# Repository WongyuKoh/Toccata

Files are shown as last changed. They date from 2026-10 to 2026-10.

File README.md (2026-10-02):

# Toccata

portable Piano + Rhythm Game

88키 풀사이즈 분할식 피아노와, 그 피아노를 컨트롤러로 쓰는 리듬 게임을 만드는 프로젝트.

건반은 **3D 프린터로 뽑는 짧은 시소 건반 + 강철 추 레버(v4, W1+)** 구조다 — 건반과 레버가 금속 봉 위에서 돌고, 레버 무게와 작은 토션 스프링으로 복귀한다. 늘 휘어 있는 플라스틱이 없다.

## 진행 순서

1. **하드웨어 설계 및 제작** ← 현재 단계
2. 피아노 소리 테스트 (MIDI 프로그램 연결 + 온디바이스 구동)
3. 리듬게임 연동
4. 리듬게임 제작

## 문서

- **[하드웨어 설계서 v4 (확정본, 2026-10-02)](docs/01-hardware-design.md)** — 지금 설계를 한곳에 모은 문서. 요구사항·건반 액션·회로·뒷바 L2·터치스크린·비용·출력·제작 순서·확인할 것·파일 지도
- [하드웨어 폴더 안내 (v4)](hardware/README.md) — 건반 액션 v4 · 회로 · CAD · 재료 목록. 통합 보고서: https://claude.ai/artifact/4GRdsojXgi8FT78uvbj5Df
- [요구사항 R1~R32 · D1~D24](hardware/mechanical/sound-requirements.md) — 모든 설계의 기준
- [CAD 출력·조립 안내](hardware/mechanical/cad/README.md) — 출력 STL, 도면 D01~D06, 렌더, 조립 순서
- [리듬게임 기획서](docs/02-rhythm-game-design.md) — 2단계
- [보관: 1단계 하드웨어 설계 v2.0 (모노리식)](docs/archive/v2.0-monolithic.md) — v4로 대체됨
- [보관: 설계 검토서 (v2.0 시각화 보고서)](docs/report/toccata-design-review.html)
- [보관: v2.0·v3 CAD·STL·렌더](hardware/mechanical/before/cad/) · [도해 SVG](docs/figures/)
- [보관: v1.5 다부품·금속 스프링 설계](docs/archive/v1.5-multipart.md)
- [보관: v0.3 상용급 설계](docs/archive/v0.3-overengineered.md) — 참고용

## 디렉토리

```
docs/         설계 문서 (01 하드웨어 설계서 v4, 02 리듬게임 기획), archive/ (이전 설계서), report/ (보고서)
hardware/     기구·PCB·BOM
  mechanical/   sound-requirements.md (요구사항), key-action-v4/ (건반 액션), touchscreen/ (터치스크린 3판), before/ (이전 설계)
    cad/          출력 STL (stl/print/), 도면 (drawings/ D01~D06), 렌더 (renders/), 전체 조립 3MF·GLB, 생성기 (src/build_all.py)
  pcb/          회로도, 기판 배치, 넷리스트
  bom/          구매 목록 엑셀 v4, 최종 재료 페이지 생성기, 판매처 조사, 절감 선택기
firmware/     RP2040-Zero 펌웨어 (키 스캔, 벨로시티, USB-MIDI) — 아직 비어 있음
sw/           라즈베리파이 소프트웨어 (FluidSynth, 터치 메뉴) 및 이후 리듬게임 — 아직 비어 있음
```

## 핵심 사양 (v4 확정본 · 2026-10-02)

| | |
|---|---|
| 건반 | 88키 (A0–C8), 흰건반 피치 23.5 mm, **3D 프린팅** (PETG) |
| 구조 | 옥타브(도~시) 모듈 7개 + 왼쪽 끝 부속(A0·A#0·B0) + 오른쪽 끝 부속(C8). 모듈 164.5 × 212 mm, 1.37 kg |
| 건반 기구 | Ø4 봉 위의 짧은 시소 건반 + 강철 블록 무게 레버 + 미스미 비틀림 스프링(C-UA90R5-3-0.5). 누르는 힘 51.9 / 51.0 g, 연타 16.3 / 18.8 Hz |
| 센싱 | 선형 홀센서 **DRV5055A2** + 자석 Ø5×2, 위치를 연속으로 재서 벨로시티 계산 |
| 모듈 MCU | **RP2040-Zero** ×8 (모듈 7 + 페달), 모듈마다 16채널 먹스(CD74HC4067 ×7), 각각 USB-MIDI 장치 → 10포트 유전원 허브 |
| 메인 CPU · 소리 | **Raspberry Pi 5 2GB** + FluidSynth, USB 오디오 동글 → TPA3110 앰프 → 4인치 스피커 2개 (헤드폰을 꽂으면 꺼짐) |
| 본체 | 건반 바로 뒤에 붙는 한 몸 뒷바 L2. 전체 **1254 × 342.5 mm**, 가운데 윗면 z72.85(건반 틀과 같은 높이), 스피커 앞판 40°, 스피커 윗면 z144.65 |
| 화면 | 7인치 가로 터치스크린 Waveshare 7-DSI-TOUCH-C, 25°로 세우고 운반할 때 접음 |
| 전원 | USB-C PD 20 V (65 W 충전기 또는 보조배터리, 약 3.2~4.0시간) |
| 비용 | 실제 구매 **731,485원**(가진 부품·예비 제외, 배송비 포함). 전체 구매 목록(가진 부품·공구·예비 포함) 1,134,177원, 그중 기본 구성 754,492원 (한도 100만 원) |
| 출력량 | 악기 출력 290개(파일 74종). 건반 액션 필라멘트 약 6.55 kg · 436시간 + 뒷바 약 1.1 kg |

> 옥타브 모듈 1개가 곧 완결된 12키 USB-MIDI 키보드입니다. 첫 모듈에서 2단계(음원 테스트)를 시작합니다.
> 이전 상용급 설계(v0.3, 600~1,100만원)는 [docs/archive](docs/archive/)에 보관.

## 라이선스

MIT

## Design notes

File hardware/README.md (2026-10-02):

# hardware

Toccata 하드웨어 설계 자료입니다. 현재 기준은 **v4**(2026-09-29)입니다.
- 건반 액션: W1+ r4.5(미스미 기성품 스프링, 남은 문제 해결)
- 전자부: 회로도 개정 C(W1 r4.5 기준, 10/1 △16 터치스크린 전원)

확정 설계를 한곳에 모은 문서는 [하드웨어 설계서 v4](../docs/01-hardware-design.md)입니다.

통합 아티팩트는 건반 액션 보고서, 도면, 재료 선택, 회로도를 한 페이지에 모은 것입니다: https://claude.ai/artifact/4GRdsojXgi8FT78uvbj5Df (발행 원본: [`docs/report/toccata-v4/`](../docs/report/toccata-v4/))

| 폴더 | 내용 |
|---|---|
| [`mechanical/sound-requirements.md`](mechanical/sound-requirements.md) | 요구사항 R1~R32, D1~D24. 모든 설계의 기준 (R31 터치스크린, R32 L2 한 몸 뒷바 · 스피커 앞판 40°) |
| [`mechanical/key-action-v4/`](mechanical/key-action-v4/) | **건반 액션 v4 (W1+).** 설계 문서, 좌표·물리 모델, 도면 15장, 출력 공구와 단계 0 시편 STL(`printables/`), 구조안 5개 비교, 검증 기록, 보고서 |
| [`mechanical/touchscreen/`](mechanical/touchscreen/) | **R31 터치스크린 수정 3판 (10/1 사용자 승인).** Waveshare 7-DSI-TOUCH-C(7인치 가로 DSI)를 L2 가운데 화면 뚜껑에 25° 기울여 세우고, 접으면 z78~95로 화면 뚜껑 위(뚜껑 윗면 z72.85, 뚜껑 평면 안)에 눕힘. `rev3/`에 CAD 넘김 사양(CAD_SPEC_rev3.md), 치수 도면 t01~t06, 3D 미리보기, 검수 페이지. 조합 비교 13가지는 `compare/`. 2판(공식 TD2, L1) 기록은 `rev2_td2/`. CAD는 통합본 v15 |
| [`mechanical/cad/`](mechanical/cad/) | **CAD (L2 한 몸 뒷바 + 건반 액션 r4.5 + 터치스크린 3판).** 출력 STL 84파일(`stl/print/`: 악기 부품 74파일·290개 + PORON 5T용 패드 바 6파일 + 출력 공구 4파일), 도면 D01~D06(`drawings/`), 렌더(`renders/`), 전체 조립 3MF·GLB, 사양(`spec/body_L2.json`), 생성기 `src/build_all.py`. 출력·조립 안내는 `README.md` |
| [`mechanical/before/`](mechanical/before/) | 이전 설계 보관: v2.0 일체형, v3 CAD·STL·렌더, 88건반 STEP |
| [`pcb/`](pcb/) | 전자부 회로도 9장, 기판 배치, 넷리스트, 부품표. 회로 세션이 관리합니다 |
| [`bom/`](bom/) | 구매 목록 엑셀(v4), 핵심 부품 목록 생성기, 판매처 조사(USB-C 케이블 포함), 절감 선택기 |

## 한눈에 보기 (v4)

- **건반:** 강철 봉 위의 짧은 시소 건반과, 꼬리가 들어 올리는 강철 추 레버가 있습니다. 무게와 작은 비틀림 스프링(미스미 C-UA90R5-3-0.5)으로 돌아오고, 늘 휘어 있는 플라스틱이 없습니다. 강철 블록은 캐리어에 MS 폴리머로 붙입니다.
- **힘:** 누르는 힘 약 51~52 g, 올라오는 힘 약 41~43 g, 연타 16~19 Hz입니다.
- **크기:** 옥타브 모듈은 164.5 × 212 mm, 1.37 kg이고 7개입니다. 끝 부속 2개를 더해 건반부는 1254 × 212 mm(깊이)이고, 바로 뒤에 붙는 한 몸 뒷바(L2: 스피커 2개 · 가운데 유닛 · 터치스크린, R32)까지 1254 × 342.5 mm입니다. 가운데 윗면은 건반과 같은 z72.85, 스피커 윗면은 z144.65(앞판 40°)입니다.
- **센싱:** 건반마다 선형 홀센서(DRV5055A2)와 자석(Ø5×2)이 있습니다. 모듈마다 RP2040-Zero와 16채널 먹스가 있고, USB-MIDI로 Raspberry Pi 5(FluidSynth)에 연결됩니다.
- **화면:** 7인치 가로 터치스크린(Waveshare 7-DSI-TOUCH-C, DSI)에서 메뉴와 리듬게임을 합니다. 외부 TV는 HDMI로 선택 연결합니다.
- **비용:** 실제로 살 금액은 **731,485원**입니다(부품 683,385원 + 배송비 48,100원, 가진 부품과 예비 제외; 최종 재료 페이지 https://claude.ai/artifact/9CJ3HwhbhoodCAui94g28n 10/2 기준). 구매 목록 엑셀 `bom/toccata-purchase-list-v4.xlsx`는 가진 부품·공구·소모품·예비까지 모두 넣은 **전체 목록**이고 1,134,177원입니다(추천 절감 1,091,558원). 그중 기본 구성은 754,492원으로 한도 100만 원 안입니다(터치스크린·L2 뒷바 포함).

다음 단계는 단계 0 시험입니다. 시편 34개와 절차서가 `mechanical/key-action-v4/printables/stage0/`에 있습니다(DESIGN.md 17장).
- **먼저 시험 1 (패드 반발).** 패드 재료값이 가장 큰 위험입니다(DESIGN.md 18장).
- 그다음 시험 3a (윗판 굽힘 띠, 6건반 화음 자리 여유 6.4 %).
- 그리고 r4.4~r4.5에서 바뀐 곳: 접착 강도(시험 20), 첫 모듈 정하중(시험 21), 스프링 토크(시험 8).

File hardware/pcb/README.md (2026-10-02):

# Toccata v4 W1+ 전자부 회로도 (hardware/pcb)

**W1(v4 W1+, 시소 건반 + 무게 레버) 설계의 전자부 회로도**입니다. W1 설계 문서는 센서 바·센서 기판·제어 기판·리본·USB를 이전 설계에서 그대로 가져온다고만 적었고, 회로는 글과 블록 배선도로만 있었습니다. 이것을 W1 좌표 모델(r4.3~r4.5)에 맞춘 **실제 회로도**로 만들었습니다. 부품 번호, 핀 번호, 넷 이름, 값, 연결이 모두 들어 있어 KiCad 같은 CAD에서 그대로 다시 그릴 수 있습니다.
기준은 W1 r4.5(2026-09-29) 좌표 모델 `hardware/mechanical/key-action-v4/model/geometry.json`(circuit_r43·circuit_r44 블록)·`metrics.json`과 설계 문서 `…/DESIGN.md`이고, 글 사양에 아래 **변경 △1~△16**을 더했습니다. 2026-09-28 W1 세션의 r4.2~r4.3 최종 자료(끝 부속 센서 바, USB 선반 홈, 프레임 레일·리브, W1 검증 요청)와 v4 구매 목록을 다시 대조해 △13~△15와 구매 목록 수정 목록을 더했습니다. 2026-10-01에는 R31 터치스크린(사용자 선택 B1 = Waveshare 7-DSI-TOUCH-C)의 전원·DSI 연결과 전원 예산을 △16으로 더했습니다(개정 C).

## W1에서 전자부로 들어오는 값 (r4.3~r4.5)

| 항목 | W1 값 | 반영한 곳 |
|---|---|---|
| 자석 | Ø5×2 N35, 건반 밑 y67(센서 소자 열 바로 위), S극 아래 | SCH-02 표, BRD-02 |
| 자석 x = 센서 x | C 7.431, C# 21.215, D 35.25, D# 49.285, E 63.07, F 77.359, F# 90.573, G 104.037, G# 117.5, A 130.964, A# 144.427, B 157.641. 끝 부속: A0 10.287, A#0 26.927, B0 40.141, C8 11.75(오른쪽 로컬) | SCH-02·04, BRD-02 |
| 끝 부속 센서 바 (r4.2) · 리드 길 (r4.4) | 왼쪽 x0.5~46.5(A#0 낮은 구간 x19.93~33.93), 오른쪽 로컬 x0.5~23.0 → EL 기판 x1.0~46.5, ER x1.0~23.0 (SB처럼 6행 15.24). 리드: 레일 밑 차선 EL x13.53~22.48 · ER x7.59~14.00(z5~10), 뒷벽 홈 z5~12 | SCH-04 주 6, BRD-02 (△13) |
| 자석–소자 간격 (쉼 / 강체 바닥 / 과다) | 백 10.82 / 5.60 / 5.24 mm, 흑 13.35 / 5.32 / 4.76 mm. 1 N 정착 바닥 백 5.52 · 흑 5.47(흑은 강체 바닥보다 0.15 위) | SCH-02 표 |
| 센서 출력 (DRV5055A2, 3.3 V) | 백 약 4 → 22 mT (ADC 약 2207 → 2862), 흑 약 2 → 25 mT (2138 → 2962). 최대 31 mT로 선형 범위 ±44 mT 안이라 A2 형을 유지. 재무장(자석 복귀 50 %) 백 8.21 mm · ADC ≈2373, 흑 9.34 mm · ≈2282; 1 N 바닥 백 ≈2890, 흑 ≈2907 | SCH-02 표 |
| 펌웨어 규칙 | 재무장 = 자석 복귀 50 %. 유령 거름(U6, W1 r4.5 DESIGN 0.1 = run_all.py gfilter): 같은 건반에서 앞끝 0.3 m/s 이상인 음의 note-on부터 250 ms 안에 재무장선을 넘으면 의심 상태, note-on부터 500 ms 안에 닿는 첫 다시 눌림의 내려오는 속도(손가락 점)가 min(0.45 m/s, 앞 음 × 25 %) 미만이면 버림, 500 ms가 지나면 보통 음(1 s 뒤 여린 연타는 산다). W1 계산: 재무장 28건 모두 1.5 s까지 스스로 다시 닿지 않음(흔들림 ≤ 222 ms). 단계 0 시험 11에서 다시 눌림 시각을 기록해 500 ms를 넘는 유령이 있으면 창 = 가장 늦은 것 + 100 ms. MCU는 자석 속도를 재므로 앞끝 = 자석 × 1.91(백) / 1.18(흑), 손가락 점 = 자석 × 1.74 / 1.05 → 자석 단위 비율 27.5 / 28.2 %(시험 11 불합격 시 30 % → 33.0 / 33.8 %) | SCH-03 주 9 |
| 제어 기판 외곽 | x47.25~117.25 × y145.5~195.5. 홈 x81.92~84.72 × y≤172(F\|F# 핀 발 y148.6~170.7과 킬 y144.5~148.6이 지나감, r4.5). 금지 구역 x81.22~85.42 × y≤173.2 — 제로 PCB(z11.9 위)만 y172.0~173.2에 걸치고 그 안에 핀·패드·배선 없음 | BRD-01 |
| 프레임 레일·리브 | 밸런스 레일 뒷면 y144.5, 선반 리브 앞면 y196.8(x49.4~50.6, x115.4~116.6). 기판 부품 ↔ 프레임 1.3 | BRD-01 고정 자리 (△14) |
| 기판 고정 (r4.4~r4.5) | 모듈 바닥 구멍 x46.25~118.25 × y144.5~196.5로 기판을 밑에서 넣음. 위에 매단 Ø6 보스 4개(받침 6 × 7.5 / 6 × 7.3, 밑면 z10.6; 둘레 1.3은 부품 없음 — 모서리 x≤54.3 · x≥110.2), M3×6 ×2 밑에서(L35 ISO 7380 Ø5.7 × 1.65, 보스 Ø2.5 막힌 구멍 z15.4까지 탭), 위치 핀 ×2. J301·J302는 넣기 전에 납땜 | BRD-01 주 8 (△14) |
| 높이 | 부품 ≤ z20(y145.8~194.5), 뒤 띠 ≤ z16.7. 제로 PCB z11.9~12.9, 윗면 부품·헤더 핀 끝 ≤ z16.3. 기판 밑은 바닥 구멍(r4.5), 아랫면 헤더 핀 끝 ≤ 2 mm. 선반 밑면 z18.05, USB 플러그 틈 1.3 | BRD-01 주 3 |
| USB 플러그 · 선반 홈 | 선반 홈 x76.45~91.55, 플러그 폭 12.5 → 양옆 1.30(FDM 뒤 약 1.0). Waveshare 치수도상 USB-C가 오른쪽 모서리에서 4.67(가운데보다 0.14 왼쪽)이라 제로를 x75.14에 둬 리셉터클 x79.53~88.47, 가운데 x84.00 = 홈 가운데. 리셉터클은 제로 가장자리 밖으로 약 1.3(1.0~1.5) | BRD-01 주 1·3 (△15) |
| USB 케이블 | C 쪽 몰드 ≤ 12.5 × 7.6 × 25 mm. **폭은 여유가 없습니다**: 12.5보다 넓으면 선반 홈과 한쪽 1.30이 그만큼 줄어듭니다. 지금 구매 목록 C04(Coms NA993)는 몰드 두께가 공개되지 않아(폭 약 11.3·길이 약 19.5는 사진 추정) W1 단계 0 시험 19(몰드 게이지 12.5 × 7.6 창, 길이 25)로 확인합니다. 안 맞으면 세 치수가 공개된 CVILUX DH-20M50052(11.97 × 6.42 × 20.93, DigiKey 2987-DH-20M50052-ND, 선택기 C04 대안, 8개 40,744원)로 | cables.csv W201~W207 |
| 리본·EXT 경로 | 리본 차선 x59~82(높이 5.0). 리본은 차선 안에서 SB J201과 같은 중심 x70.48(여유 1.32 / 1.36), J301 쪽 끝 6 mm만 가닥을 갈라 0.31 비껴 꽂음. J301도 아랫면 납땜, 리본은 기판 밑(z5~9)으로. EXT 선: 기판 밑 → USB 플러그 밑 → 뒷벽 개구. 회로 쪽 최소 차선: 리본 한 겹 → 높이 ≥ 2.5, 폭 ≥ 20.32 + 2 × 1.3 (W1 단계 0 시험 21 뒤 차선이 바뀌면 다시 정함) | SCH-02·03, BRD-01 주 6·7 |

- 모듈 핀 배치는 판매 페이지, 제조사 데이터시트, 위키에서 확인했습니다.
- 회로는 따로 전기 설계 검토를 거쳤습니다.
- 도면 개정: A = 2026-09-28 첫 판(△1~△12), **B = 2026-09-29** W1 r4.2~r4.5 대조(△13~△15, 기판 고정·바닥 구멍·끝 부속 리드 길), **C = 2026-10-01** R31 터치스크린 B1(△16: 화면 전원·DSI·전원 예산). 바뀐 SCH-01·SCH-06만 C이고 나머지 7장은 B 그대로입니다.
- 모든 도면은 한 소스(`src/`)에서 만들어집니다. 만들 때 **그린 선·라벨로 연결을 다시 계산**해 의도한 넷리스트와 대조합니다(ERC 대용). 현재 9장 모두 연결 오류 0, 글자끼리 겹침 0입니다(자동 검사는 글자와 전원 심볼만 봅니다).

## 파일

| 파일 | 내용 |
|---|---|
| `schematic/SCH-01_system.svg` | 시스템 연결도: 모든 파트와 보드, 선 목록(W 번호). 화면 A605와 W605~W608 포함(△16) |
| `schematic/SCH-02_sensor_board.svg` | 옥타브 센서 기판 SB ×7: DRV5055 ×12, 디커플링, 리본 2×8 |
| `schematic/SCH-03_control_board.svg` | 옥타브 제어 기판 MB ×7: RP2040-Zero, 4067 먹스, ID 점퍼, EXT와 보호 회로 |
| `schematic/SCH-04_end_parts.svg` | 끝 부속 EL(A0·A#0·B0)·ER(C8) 센서 기판과 JST-XH 연결 |
| `schematic/SCH-05_pedal.svg` | 페달 보드 PB와 페달 안 센서 PS |
| `schematic/SCH-06_power.svg` | 전원: PD 20 V → 퓨즈 → 스위치 → 5.1 V 강압 → Pi·허브. 화면 A605 전원(Pi 헤더 2·6번 → 점퍼 → 동봉선)·DSI 리본, 전원 예산(△16) |
| `schematic/SCH-07_audio.svg` | 오디오: 동글 → 헤드폰 잭 노멀 → HPF → TPA3110 → XT30 → 스피커 |
| `board/BRD-01_control_board_placement.svg` | 제어 기판 부품 자리와 구멍 좌표. W1 r4.3~r4.5 홈·금지 구역·높이 구역·바닥 구멍·매단 보스 반영 |
| `board/BRD-02_sensor_board_placement.svg` | 센서 기판 SB 리드 구멍, 버스 행, 리본 블록 + 끝 부속 EL·ER 기판 배치 |
| `netlist/netlist.csv` | 도면·보드·넷·부품·핀·핀 이름 (그린 도면에서 다시 계산한 값) |
| `netlist/bom.csv` | 부품·값·보드당/전체 수량·실장 조건·**KiCad 심볼/풋프린트**·구매 목록 코드 |
| `netlist/cables.csv` | 선 목록 W101~W706과 X701 (화면 W605~W608 포함) |
| `netlist/wiring_MB.csv` | 제어 기판의 점 대 점 배선 목록(구멍 좌표, 금지 구역 가로지름 경고 포함) |
| `netlist/rp2040_zero_pads.csv` | RP2040-Zero 패드 번호(dj505 / Waveshare P1), 구멍 좌표, 용도 |
| `netlist/mux_module_pins.csv` | 4067 모듈 심볼 핀 ↔ 모듈 헤더 핀 |
| `src/` | `sheets.py`(설계 데이터·도면), `parts.py`(모듈 핀·구매 코드), `sch.py`(도면 엔진·연결 검사), `export.py`(CSV), `build.py` |

다시 만들기: `python3 hardware/pcb/src/build.py` (PNG 미리보기가 필요하면 `--png <폴더>`, `resvg_py` 필요).

## 규칙

- **부품 번호.** 시트 번호 × 100입니다(KiCad의 "First free after sheet number × 100"). SB는 U201~, MB는 A301~, EL/ER은 40x/41x, PB는 50x, PS는 551, 전원은 60x, 오디오는 70x입니다.
- **보드 쪽 부품은 보드마다 번호가 같습니다.** 7개 모듈은 같은 기판을 7장 만들고 ID 점퍼만 다르게 닫습니다.
- **U, A, J, P, X의 뜻.**
  - U = 칩
  - A = 구매 모듈(RP2040-Zero, 먹스, PD 트리거, 강압, 앰프, 동글)
  - J = 기판 쪽 커넥터나 패드
  - P = 선 끝 플러그
  - X = 선 대 선 커넥터(JST-XH, XT30)
  - 두 커넥터가 맞물리는 곳에는 `>>` 표시를 그렸습니다. **KiCad에서는 연결이 아닙니다**. 그래서 맞물리는 양쪽 핀에 같은 넷 이름(라벨)을 붙여 두었습니다.
- **전원 넷.** `+3V3`, `GND`, `+20V`, `+5V1`은 전원 심볼로 그렸습니다. KiCad에서 로컬 라벨 "GND"는 전원 넷에 붙지 않으므로 반드시 전원 심볼을 씁니다.
  - `+20V`와 `+5V1`은 표준 라이브러리에 없습니다. 프로젝트 전원 라이브러리에 추가하세요(`+24V`를 복사해 이름을 바꾸면 됩니다).
  - EL·ER 쪽 3V3는 O1·O7 제어 기판의 3V3 레일이라 `+3V3_EL`, `+3V3_ER`로 나눴습니다(프로젝트 전원 심볼로 추가). 끝 부속 신호는 `EL_A0`, `EL_AS0`, `EL_B0`, `ER_C8`입니다.
- **오디오 신호 GND(`AGND`).** 잭 슬리브와 HPF 1 kΩ의 GND를 앰프 IN G 단자로만 모읍니다(△10). 전원 GND와는 앰프 보드 안과 USB를 통해 이어집니다.
- **모듈 패드 번호.**
  - RP2040-Zero는 `dj505/RP2040-Zero-KiCAD` 라이브러리 번호를 따릅니다: 1~9 왼쪽 위→아래, 10~18 오른쪽 위→아래, 19~23 아래 왼→오. Waveshare 회로도 P1 번호는 표에 같이 적었습니다.
  - 4067 모듈은 1~16 = C0~C15(J1)이고, 17~24 = J2 1~8(GND, VCC, EN, S0, S1, S2, S3, SIG)입니다.
- **3.5 mm 잭**은 KiCad `AudioJack3_SwitchTR`처럼 핀 번호가 글자(T, TN, R, RN, S)입니다. PJ-313은 판매자마다 1~5 번호가 달라서, 통전 검사로 글자를 찾아 씁니다.
- **XT30**은 KiCad 풋프린트대로 패드 1 = −, 2 = +입니다. 커넥터의 납작한 면이 +입니다.

## 이전 글 사양 대비 변경 (도면의 △ 표시)

| △ | 도면 | 변경 | 이유 | 부품 |
|---|---|---|---|---|
| 1 | SCH-02 | 버스 양 끝에 C213·C214 10 µF | 글 사양에는 있지만 구매 목록에 없었음 | **구매 목록 L67**: 1206 10 µF 16 V 50개 단위(아이씨뱅큐 P001248090, 7,150원) |
| 2 | SCH-03 | 먹스 VCC–GND에 C301 100 nF | 모듈 C1이 사진에만 있고 확인되지 않음 | 100 nF 여분 |
| 3 | SCH-04 | EL·ER 기판에 10 µF | 3V3가 150 + 350 mm 선 끝에서 들어옴 | △1과 같은 묶음 |
| 4 | SCH-05 | 링 급전 R503 = 20 Ω(100 Ω ×5 병렬) | TS 플러그나 꽂는 순간 3V3–GND가 이어져 PED 보드가 리셋됨(검토 R1) | 100 Ω 여분 |
| 5 | SCH-06 | 별 접지점 = 강압 IN− 단자 | 동글–Pi–강압–앰프 GND 루프 험(R7) | — |
| 6 | SCH-03·04 | EXT·XH 순서: 1 GND, 2~5 EXT1~4, 6 3V3 | 5S 밸런스선이 빨강 1 + 검정 5라 빨강 = 3V3가 되게 | — |
| 7 | SCH-05 | 페달 안 센서 OUT에 R551 1 kΩ 직렬 | 3 m 케이블 용량이 OUT에 바로 걸림(TI: OUT에 C 직결 금지) | 1 kΩ 여분 |
| 8 | SCH-03·04 | EXT: 센서 옆 1 kΩ 직렬(EL R401~R403, ER R411) + MB 100 kΩ 풀다운(R301~R304; O1은 1~3, O7은 1만) | 끝 부속을 빼면 입력이 떠서 유령 음이 남(R4, 필수). 1 kΩ은 약 0.6 m 선의 용량을 센서 OUT에서 떼어 냄(TI: OUT에 C 직결 금지) | 1 kΩ·100 kΩ 여분 |
| 9 | SCH-05 | 페달 잭 TN → GND | 플러그가 없을 때 팁이 GND라 0 V | — |
| 10 | SCH-07 | AGND 분리 표기 | 입력 쪽 GND를 앰프 IN G로만 | — |
| 11 | SCH-05 | R502 100 kΩ를 팁→GND로 고정, GP27 안 씀 | 이전 글 사양의 "GP27로 뗀 쪽 전압 구동"은 GPIO가 0/3.3 V만 낼 수 있어 불가(R3) | — |
| 12 | SCH-02·03 | 리본 16심 모두 사용(15 = GND, 16 = 3V3), 2×8 블록 | 선이 끊겼을 때 유령 음, 전원 여유(R27). 2×8은 나중에 IDC 헤더로 바꿔도 번호가 같음 | — |
| 13 | SCH-04·BRD-02 | EL·ER 1 kΩ(R401~R403, R411)을 1206 칩으로 아랫면에(OUT 구멍 ↔ 바로 뒤 행 y72.08). 기판을 W1 끝 부속 센서 바 안으로(EL 45.5 × 15.24, ER 22.0 × 15.24) | 센서 바가 기판 윗면을 모두 덮어 리드형 저항(Ø2.5)을 둘 곳이 없고, 기판 밑 틈은 2.0 mm. 이전 크기 47 / 23은 바(46.0 / 22.5)보다 김 | **구매 목록 L68**: 1206 1 kΩ 10개(아이씨뱅큐 P011433924, 440원) |
| 14 | BRD-01 | 기판 고정 자리를 (50.0,149.0)(114.5,149.0)(50.0,192.5)(114.5,192.5)로 — W1 r4.5에서 매단 보스, M3×6 밑에서 2 · 위치 핀 2 | 이전(v3 P114) 자리는 M3 머리 Ø5.5가 밸런스 레일 뒷면과 0.75, 선반 리브와 1.05(W1 1.3 규칙 위반). 새 자리(L35 ISO 7380 Ø5.7 × 1.65, 밑에서): 레일 1.65, 리브 1.54(축 1.45), 머리가 기판 모서리 x47.25 / 117.25 밖 0.10(바닥 구멍 안; DIN 912 Ø5.5면 기판 안) | — |
| 15 | BRD-01 | 제로를 x75.14로(+0.14), 제어 기판 격자 x = 76.52 + 2.54i. J301도 아랫면 납땜 | Waveshare 치수도: USB-C 리셉터클이 오른쪽 모서리에서 4.67 → 플러그 가운데를 W1 선반 홈 가운데 x84.00에(양옆 1.30 그대로). W1 검증이 요청한 J301 아랫면 납땜(리본이 레일 앞 1.0 안에서 접히지 않게) | — |
| 16 | SCH-01·06 | 화면 A605 = Waveshare 7-DSI-TOUCH-C(B1). 전원: Pi 40핀 헤더 핀 2(5 V)·6(GND) → P603 → W606 실리콘 점퍼 F/F 20 cm → X601⇄X602 → W607 점퍼 M/M 20 cm → X603⇄X604(화면 동봉선의 2.54 3핀 하우징: 1 빨강 5 V · 2 빈 칸 · 3 검정 GND) → W608 동봉선 → P604 MX1.25 2핀 ⇄ A605. 넷 `+5V_PI`(Pi 5 안 5 V 레일 = USB-C 입력, P601 MT666을 거쳐 `+5V1`에서 옴 — `+3V3_EL`처럼 프로젝트 전원 심볼)·`GND`, 꽂는 곳(`>>`)마다 양쪽에 같은 전원 심볼. DSI = W605 FFC 22핀 0.5 mm 300 mm B형(Pi 5 CAM/DISP 1 → A605, 22심 1 ↔ 1, A형은 보험). SCH-06 전원 예산: 화면 2.15 W(0.43 A), 강압 손실 1.4 W, 평균 약 16~20 W, 순간 최대 약 54.4 W(D19 52 W + 2.15 W ÷ 0.9), 60 W 여유 약 5.6 W, 45 W 전원이면 볼륨 상한 −2 dB(약 39.4 W; −1 dB면 약 46.0 W로 넘침, −1 dB만 낮출 때는 화면을 꺼 약 43.6 W) | R31(2026-10-01 사용자 B1 선택). D16: 화면은 Pi에서 나가는 방향으로만 전원을 받고, 화면·연장선에 다른 5 V를 넣지 않음. D19 전원 여유. D14: 화면·경첩·받침다리에 자석 없음 | 구매 목록 v4touch: No.135 화면, No.49·50 FFC B·A형, No.51~54 실리콘 점퍼 F/F·M/M 빨강·검정 (모두 반영됨) |

**번호 없는 변경**
- 테스트 포인트를 추가했습니다: MB 3개, PB 2개, CU 3개.
- **RP2040-Zero 장착 방식**을 캐스털레이션 직접 납땜에서 **안쪽 구멍에 핀 헤더(플라스틱 몰드는 뺌)**로 바꿨습니다. 밑면에 칩·수정·LDO가 있어 평평하게 붙지 않기 때문입니다.
  - 모듈은 밑면 부품 위(캡톤)에 얹혀 약 1.3 mm 높아집니다.
  - 제약은 부품 한계 z20이 아니라 **USB 위 뒤 선반 밑면**이었습니다. W1 r4.3이 선반에 플러그 위 홈(x76.45~91.55)을 내서 플러그(z10.7~18.3)와 1.3 mm를 되찾았습니다.
  - **구매 추가**: 핀헤더 1×40 4줄. 18핀 ×8장 = 144핀이고, 기존 SE7 5줄은 먹스(168핀)에 배정되어 있습니다. 합계 9줄.
  - KiCad 풋프린트는 1.0 mm 드릴 버전(bobu01 1mm, 또는 dj505를 복사해 드릴만 바꿈)을 씁니다.
- **BRD-01의 모든 부품 구멍을 제로 핀 격자에 맞췄습니다**(x = 76.52 + 2.54i, y = 173.59 + 2.54j; △15로 +0.14). 만능기판 한 장의 구멍에 모두 맞습니다. 4067 모듈은 x54.93~72.71에 세로로 둡니다.
- 센서 기판 고정 구멍(3.0, 61.9)·(3.0, 74.6)은 기판 앞·뒤 가장자리를 넘으므로 U자 홈으로 팝니다.

## KiCad로 옮기는 순서 (권장)

1. **프로젝트를 보드별로 나눕니다.** `octave-sensor`(SB), `octave-control`(MB, PB도 같은 기판으로 쓸 수 있음), `end-parts`, `pedal-sensor`로 나누고, CU 전원·오디오는 문서용 `cu-wiring`으로 둡니다. 한 PCB 파일에 7장을 넣지 않습니다.
2. **라이브러리.**
   - `bom.csv`의 "KiCad 심볼/풋프린트" 열을 따릅니다.
   - 직접 만들 것:
     - `Toccata:CD74HC4067_Breakout`
     - PJ-313 풋프린트(패드 이름 T/TN/R/RN/S)
     - 모듈 심볼: HUSB238, XL4016, XH-A232, 동글, `RaspberryPi5`(유닛 B = 40핀 헤더 2·6), `Waveshare_7-DSI-TOUCH-C`(1 = 5V, 2 = GND) (△16)
     - 전원 심볼 `+20V`, `+5V1`, `+3V3_EL`, `+3V3_ER`, `+5V_PI`(△16)
   - RP2040-Zero는 dj505 라이브러리를 쓰고, 3V3 핀을 `power_out`으로 바꿉니다.
   - DRV5055는 `Sensor_Magnetic:DRV5055A2xLPGxQ1`를 쓰고 Value를 `DRV5055A2QLPG`로 바꿉니다.
3. **주석 번호.** Annotate → "First free after sheet number × 100", X 위치순.
4. **ERC.** 선으로 들어오는 전원(SB의 `+3V3`, `+3V3_EL`·`+3V3_ER`, `+20V`, `+5V1`, `+5V_PI`, PS의 `PED_VCC`, 각 프로젝트의 `GND`)에 `PWR_FLAG`를 둡니다.
   - P601은 `USB_C_Plug_USB2.0`에서 A4·A1만 쓰므로 나머지 핀에 NC 표시를 합니다.
   - J401은 `Conn_01x05`, J411은 `Conn_01x03`입니다. P501은 PS 프로젝트에 둡니다.
   - △16 화면 선: P603·X601~X603·P604 = `Conn_01x02`, X604 = `Conn_01x03`(2 = 빈 칸, NC 표시). 모두 보드 밖(Exclude from board).
5. **보드 외곽과 부품 자리.** BRD-01·02 좌표를 씁니다. 제어 기판은 **x81.22~85.42 × y145.5~173.2(W1 r4.3)에 부품·패드·배선을 두지 않고**(제로 PCB만 y172.0~173.2에 걸침) 홈 x81.92~84.72 × y145.5~172.0을 따냅니다. EL·ER 기판은 BRD-02 아래 그림을 씁니다(R401~R403·R411 = `Resistor_SMD:R_1206_3216Metric`, 아랫면).

## 도착 후 확인할 것 (검토의 bring-up 목록 요약)

1. **PD 트리거.** 무부하로 전원마다 20 V가 나오는지 잽니다. HUSB238은 ISET이 열려 있으면 3.25 A를 요구해서, 20 V 3 A 보조배터리는 15·12 V나 5 V로 떨어질 수 있습니다.
2. **XL4016.** 무부하로 5.10~5.15 V에 맞추고 가변저항을 고정한 뒤 연결합니다. MT666 선과 허브 선의 극성도 확인합니다.
3. **PJ-313 ×3.** 플러그가 없을 때 T–TN, R–RN이 닫혀야 합니다. 노멀 접점이 없는 제품이면 헤드폰 차단(R15)을 할 수 없습니다.
4. **RP2040-Zero 복제품.** LDO 표시를 확인합니다(5핀 RT9013/ME6217이면 괜찮음). O1의 3V3 전류는 60~130 mA가 정상입니다.
5. **센서.** 자석 없이 OUT이 1.59~1.71 V(DRV5055 영점)이고, S극을 표시면에 가까이 하면 올라가야 합니다. 건반을 얹은 쉼에서는 백 약 1.78 V, 흑 약 1.72 V, 끝까지 누르면 백 약 2.31 V, 흑 약 2.39 V입니다(±10 %). EXT를 뺐을 때는 0.15 V 아래여야 합니다.
6. **페달.** 꽂은 상태에서 링–슬리브가 3.05 V 이상이고, 뺐을 때 팁이 약 0 V여야 합니다.
7. **앰프.** 36 dB 이득인지 확인하고 소프트웨어 음량 상한을 정합니다. 스피커 Re가 6~7 Ω인지(4 Ω 판매분 주의) 잽니다.
8. **허브 역급전.** Pi 선을 뺐을 때 Pi 5V 핀이 0 V여야 합니다.
9. **USB-C 위치·케이블.** 산 RP2040-Zero(복제품)의 리셉터클이 오른쪽 모서리에서 4.67 mm인지, 제로 가장자리 밖으로 몇 mm 나오는지 잽니다. 핀 헤더로 세운 제로에 실제 케이블을 10번 꽂고 빼 봅니다(몰드 ≤ 12.5 × 7.6 × 25, W1 시험 19).
10. **화면 전원(△16).** 동봉 전원선의 2.54 3핀 하우징이 1 빨강 5 V · 2 빈 칸 · 3 검정 GND인지 통전 검사로 확인한 뒤 점퍼를 꽂습니다. 화면 MX1.25 쪽 5 V를 부하 때 잽니다(점퍼 두 단 왕복 강하 계산 약 0.05 V). 최대 부하(FluidSynth + 화면 밝기 100 % + USB 장치)에서 `vcgencmd get_throttled` = 0x0(Pi USB-C 입력 약 2.0 A, D16). 화면 켬·끔, 밝기 0·100 %에서 센서 유휴 흔들림을 다시 잽니다(D14). config.txt에는 `dtoverlay=vc4-kms-dsi-waveshare-panel-v2,7_0_inch_c` 한 줄을 넣습니다(CAM/DISP 0이면 `,dsi0`).

## W1 기구 쪽에 요청한 것과 결과 (요청 2026-09-28, W1 r4.4~r4.5 반영 2026-09-29)

| # | 회로가 요청한 것 | W1 결과 |
|---|---|---|
| 1 | 제어 기판 부품 자리를 새 격자 좌표로: 제로 x75.14~93.14, 4067 x54.93~72.71 × y152.0~192.64, J301 x61.28~79.06 y148.19/150.73(아랫면 납땜, 리본은 기판 밑 z5~9), J302 x94.30~107.00 y193.91 | 반영. 리셉터클 x79.53~88.47 그대로 |
| 2 | USB 플러그 면 y약 196.8(리셉터클이 제로 밖으로 1.0~1.5), 몰드 y196.8~221.8 | 반영. 선반 홈 x76.45~91.55(틈 1.30), 선반 밑면 z18.05, 뒷벽 개구 z5~21(틈 2.70) |
| 3 | 제어 기판 고정 4곳 (50.0,149.0)(114.5,149.0)(114.5,192.5)(50.0,192.5) | **바뀜.** 한 덩어리 프레임에는 기판을 넣을 길이 없어(F\|F# 핀이 홈을 지나고 그 뒤로 매달림) 기판 밑 바닥을 뚫었습니다(x46.25~118.25 × y144.5~196.5, 리셉터클 뒤 x78.53~89.47은 y197.8까지). 모듈을 뒤집어 기판을 밑에서 곧게 넣습니다(넣는 길 최소 틈 0.60). 받침은 같은 네 자리에 **위에 매단 Ø6 보스**(밑면 z10.6 = 기판 윗면; 앞 2개는 밸런스 레일 뒷면, 뒤 2개는 리브·선반에 붙음). **M3×6 2개는 밑에서** 조이고(머리가 기판 밑), **위치 핀 2개**는 보스에서 기판 구멍으로 내려옵니다(반경 놀음 0.10). 나사는 구매 목록 L35 ISO 7380 버튼헤드(머리 Ø5.7 × 1.65): 레일 1.65, 리브 1.45로 1.3 규칙 통과, 머리가 기판 모서리 x47.25 / 117.25 밖으로 0.10 나오지만 바닥 구멍 안이라 문제없습니다(DIN 912 M3×6이면 Ø5.5로 기판 안) |
| 4 | 끝 부속 센서 기판 받침, 뒤 리브 틈(EL x15~38, ER x6~16), 리드 길 | 반영: 레일 밑 차선 EL x13.53~22.48 · ER x7.59~14.00(z5~10), 뒷벽 홈 z5~12. 리드는 패드 줄 뒤 y77.39 안에서 EL x14.83~21.18 · ER x8.89~12.70으로 모읍니다 |
| 5 | SB 뒤 받침 리브 틈 x60~82 → x59~82 | 반영(리본 양옆 1.32 / 1.36) |
| 6 | 금지 구역과 제로 PCB 겹침 정리 | 금지 구역 y173.2 그대로, P23에 제로 PCB가 y172.0~173.2에 걸친다고 기록 |
| 7 | C301 = 1206 칩, 레버가 떨어지는 곳 | 반영: D#·G# 매단 보스 위(16.75°), E·F 4067 위(13.25°), F#·G 기판 윗면(24.0° / 23.5°), O1·O7의 G는 R301 위(0.40 N) → R301을 기판에 붙여 눕히고 리드를 짧게 납땜 |
| + | (W1 쪽 변경) F\|F# 핀 발 | 바닥 대신 킬(y144.5~148.6, z3~19.3)로 밸런스 레일 뒷면에 붙음, 핀 앞끝 y152 → y148.6. 둘 다 기판 홈(앞이 열림) 안이라 회로 변화 없음 |

### 2차 요청 (2026-09-29, r4.5 재대조) — W1 r4.5 회로 2차로 반영됨 (통합 아티팩트 v9)

결과: 8 센서 바 오른쪽 턱을 되살림(ㄱ자 두 조각, 립 x161.5~163.0 z13.6~15.1, 기둥 x163.0~164.3; EL·ER은 턱 없이 왼쪽 M3 ×2 + 리브) → 회로는 SB를 x162.6까지 자름(기둥과 0.4). 9 유령 거름 = note-on부터 250 ms 안 재무장 → 의심, note-on부터 500 ms 안의 첫 다시 눌림만 판정(재무장 28건 모두 1.5 s까지 다시 닿지 않음). 10 레버 착지 글 맞춤. 11 EL 바닥 한 조각. 12 구매 목록 글 반영(합계 1,060,470원 그대로). 13 리본 차선 그대로(시험 21 뒤 알림).

| # | W1이 바꿀 것 | 이유 |
|---|---|---|
| 8 | 센서 바 오른쪽 턱(v3 P112, x161.5~164.5 × y59.0~63.4 · y70.6~77.5, 밑면 z13.6)을 모델에 넣거나, 턱 없이 바 오른쪽 끝을 무엇이 잡는지 P36에 적기 | r4.5 geometry에 턱이 없음. BRD-02는 턱을 점선으로 두고 확인 대기 |
| 9 | 유령 거름(U6) 글을 run_all.py gfilter와 같게(창 기준 = note-on부터 재무장까지 250 ms), 무장된 28건을 1 s 이상 돌려 유령이 다시 닿는 시각(ghost_reland)을 구해 '다시 눌림 시각 상한' 정하기 | DESIGN.md:36 글은 '250 ms 안에 다시 눌림'이라 모델과 기준이 다름. 펌웨어는 SCH-03 주 9 형태로 둠 |
| 10 | DESIGN §11 6단계 글: D#·G# 레버는 기판 윗면이 아니라 매단 보스 위(16.75°) | geometry·도면 12와 맞춤 |
| 11 | 끝 부속 EL 바닥에 모듈 기판 구멍 자르기가 새어 생긴 틈 x46.25~46.8 × y144.5~196.5 없애기 | end_fixed_prisms가 모듈 x로 잘라 끝 부속에도 적용 |
| 12 | 구매 목록 글: L35 용도를 매단 보스·밑에서 조임(r4.5)으로, SE4 용도에 MB C301 ×7(97개 사용), L20·L21 용도를 건반 88 + 페달 1 = 89(예비 11)로, 엑셀 제목 r4.4 → r4.5 | 수량·가격은 그대로 |
| 13 | 단계 0 시험 21 뒤 리본 차선(x59~82, z5~10)을 바꾸면 회로에 알리기 | 회로 쪽 최소: 리본 한 겹 → 높이 ≥ 2.5, 폭 ≥ 20.32 + 2 × 1.3 |

## 구매 목록(v4)에 넣거나 고칠 줄

`hardware/bom/toccata-purchase-list-v4.xlsx`와 절감 선택기는 W1 세션의 생성기(`hardware/bom/cost-selector/build_data.py`)로 만들어집니다. 아래 11줄은 **2026-09-29 판에 모두 반영됐습니다**(새 줄 L67·L68). 기록으로 남깁니다.

| 줄 | 바꿀 내용 |
|---|---|
| L67 (새 줄, 반영) | 1206 10 µF 16 V 50개(아이씨뱅큐 P001248090, 7,150원) ×1 — SB C213·C214 ×7 + EL C404 + ER C412 = 16개 (△1·△3) |
| L68 (새 줄, 반영) | Yageo RC1206JR-071KL 1206 1 kΩ 10개(아이씨뱅큐 P011433924, 44원 × 10 = 440원, VAT 포함) — R401~R403 + R411 (△13) |
| SE7 핀헤더 1×40 | 5 → 9줄 (먹스 168 + 제로 144 = 312핀) |
| SE7 핀헤더 소켓 1×40 | 빼기: EXT는 L66 JST-XH를 패드에 직접 납땜 |
| SEV2 RP2040-Zero 용도 | "캐스털레이션 직접 납땜" → "안쪽 구멍 핀 헤더 1×9 ×2(몰드 뺌), 캡톤 위 약 +1.3 mm" |
| L29 저항 용도 | 1 kΩ: R701·R702·R501·R551 / 100 kΩ: R301(O1·O7)·R302·R303·R502 / 100 Ω: R503(100 Ω ×5 = 20 Ω, 필수) |
| C05 리본 용도 | 16심 전부(OUT 12 + 3V3 ×2 + GND ×2) ×7 + EL·ER 리드 가닥 |
| L66 용도 | 200 mm 연장선을 모듈 쪽 150 · 끝 부속 쪽 50으로 자름 |
| C04 USB 케이블 | 몰드 ≤ 12.5 × 7.6 × 25, 폭 초과 금지 (반영; NA993 두께 미공개 → 대안 CVILUX DH-20M50052) |
| L56 1 µF 용도 | "약 80 Hz" → "약 93 Hz" |
| (선택) L29 10 kΩ | 회로에서 쓰지 않음(예비) |

**2026-10-01 (△16, R31 화면 B1)**: 화면 줄(v4touch No.49~54·75·76·135)은 구매 목록에 이미 들어가 있습니다. 회로에서 고칠 글 1줄:

| 줄 | 바꿀 내용 |
|---|---|
| L01 Raspberry Pi 5 용도 | "(R25: HAT 없음, GPIO 배선 없음)" → "HAT 없음. GPIO는 헤더 2·6번에서 화면 5 V만 나감(R31, △16)" |

## 근거

- 조사 노트 원문(모듈 핀·데이터시트·KiCad 라이브러리·전기 검토)은 작성 세션의 작업 폴더에 있었습니다. 핵심 결론은 이 문서와 도면 주에 옮겼습니다.
- TI DRV5055 SBAS640C, TI CD74HC4067 SCHS209D, RP2040 데이터시트(E11 정오표), Waveshare RP2040-Zero 위키와 회로도, SparkFun BOB-09056, Hynetek HUSB238, TI TPA3110D2, AMASS XT30 카탈로그, KiCad 9/10 라이브러리.

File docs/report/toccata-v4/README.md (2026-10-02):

# Toccata v4 통합 아티팩트 — 고치는 법

> **2026-10-02부터 최종본만 보여 줍니다**(사용자: "예전 구조 다 빼고 최종적으로 다루는 내용만"). `merge.py`의 `FINAL_ONLY = True`가 탭을 요약 · 01 건반 액션 구조 · 02 건반 도면(도면 11 뺌) · 03 검증·남은 위험(남은 문제·단계 0·남은 위험만) · 04 출력·조립(보관함 뺌) · 05 구매 목록(`src/build_buylist.py`) · 06 회로도 · 07 CAD · 08 뒷부분 도면으로 짭니다. 진행 기록(00), 부품·비용(04 옛), 5안 비교, 재료·절감 선택, S1·H1·K1·F1 대안 탭은 빠집니다(원본 `src/`는 그대로라 `FINAL_ONLY = False`로 되돌릴 수 있음).

두 아티팩트와 회로도를 **하나의 아티팩트**로 합쳤습니다.
- 건반 액션 진행 현황: https://claude.ai/artifact/1fA3D1HQRvNEanGCjDPhTZ
- 재료 절감 선택: https://claude.ai/artifact/Vv8pahUbEkKhwsZwGnmsGG
- 회로도: 새로 만든 탭

2026-09-28부터 Toccata v4에서 바뀌는 내용은 **모두 이 통합 아티팩트에 다시 발행**합니다. 원본 두 개는 더 고치지 않습니다.

- 통합 아티팩트 URL: **https://claude.ai/artifact/4GRdsojXgi8FT78uvbj5Df** (2026-09-28 v1 발행)
- 이 폴더가 발행 원본입니다: `index.html`과 옆의 `dwg/ alt/ img/ sch/`.

## 탭과 원본

| 탭 | page id | 원본 | 누가 고치나 |
|---|---|---|---|
| 요약 한눈에 보기 (맨 앞, 첫 화면) | `p-summary` | `src/summary.html` ← `python3 src/build_summary.py <최종 재료 db state/main JSON>` (최종 재료 페이지 데이터 hardware/bom/final-bom/site/index.html + 사용자 선택으로 실제 구매 금액 계산, 설계 숫자는 스크립트 안) | W1 세션 |
| 00~06 진행 현황 · W1+ 구조 · 도면 12 · 검증 · 부품·비용 · 출력·조립 · 5안 비교, S1·H1·K1·F1 | `p-overview` … `p-f1` | `src/progress.html` + `dwg/` `alt/` `img/` | v4 건반 액션 세션 (report 빌더) |
| 07 재료·절감 선택 | `p-cost` | `src/costsel.html` | 재료·절감 세션 (`gen_sel.py`) |
| 08 회로도 | `p-circuit` | `hardware/pcb/page/circuit.{html,css,js}` + `sch/` | 회로 세션 (`hardware/pcb/src/build.py` → `page.py`) |
| 10 뒷부분 도면 | `p-rear` | `hardware/mechanical/cad/drawings/D01~D06` (SVG·PNG) + `renders/R01~R03` → `merge.py`가 `rear/`로 복사. 도면마다 확대 단추(맞춤·2배 = PNG, 3배 = SVG; 회로도 탭의 `.zbar`) | CAD 세션 (`hardware/mechanical/cad/src/drawings.py`, `build_all.py`가 끝에 실행) |

## 고치고 발행하는 순서

1. **자기 탭의 원본만 바꿉니다.**
   - **진행 현황.** 빌더가 만든 **전체 페이지**(`<title>…</title>`로 시작하는 `index.html`)를 `src/progress.html`로 덮어씁니다. 그 페이지가 쓰는 도면과 사진은 같은 경로로 `dwg/`, `alt/`, `img/`에 복사합니다.
     - `merge.py`는 `<nav class="tabs" aria-label="페이지">`, `<main class="wrap">`, `<footer><div class="wrap">`, 첫 `<script>`를 찾아 씁니다.
     - 탭 순서는 원본의 nav를 따릅니다. `<span class="sep"></span>` 뒤는 대안 탭입니다.
   - **재료·절감.** `gen_sel.py`가 만든 전체 페이지를 `src/costsel.html`로 덮어씁니다.
     - 합계 막대(`.sumbar`), `<main>` 안의 내용, 스크립트를 그대로 가져옵니다.
     - 공통 CSS를 뺀 나머지 CSS에는 자동으로 `#p-cost` 범위를 붙입니다.
   - **회로도.** `python3 hardware/pcb/src/build.py` 다음 `python3 hardware/pcb/src/page.py`를 실행합니다. SVG는 `merge.py`가 `sch/`로 복사합니다.
2. `python3 docs/report/toccata-v4/merge.py --check`를 실행합니다. 섹션 15개(`p-overview`…`p-f1`, `p-cost`, `p-circuit`, `p-cad`, `p-rear`)가 나와야 합니다.
3. **발행합니다.** 다른 세션은 먼저 Artifact `action: "read"`, `url: https://claude.ai/artifact/4GRdsojXgi8FT78uvbj5Df`로 읽어야 발행할 수 있습니다. 읽은 뒤 이렇게 호출합니다:
   ```
   Artifact publish
     url:       https://claude.ai/artifact/4GRdsojXgi8FT78uvbj5Df
     file_path: docs/report/toccata-v4/index.html
     root:      docs/report/toccata-v4
     files:     [바뀐 파일만, 예: "dwg/d01_white_D_side.svg", "sch/SCH-03_control_board.svg"]
   ```
   - `files`에 없는 파일은 그대로 남습니다. 지운 파일은 `{"경로": null}`로 뺍니다.
   - 새 아티팩트를 만들지 않습니다(`url` 없이 발행하면 새 URL이 생깁니다).
   - `icon`은 넘기지 않습니다(처음 발행 때 정했음).
4. 발행 결과에 "newer version"(충돌)이 나오면, 그 버전을 `read`로 받아 `src/`에 반영하고 `merge.py`를 다시 돌린 뒤 발행합니다.

## 주의

- 페이지 머리말(`header.tb`)과 합친 원본 안내는 `merge.py`의 `header`에 있습니다. 날짜와 상태 칸을 바꾸려면 거기를 고칩니다.
- 새 탭이 필요하면 `merge.py`의 `nav`와 `main` 조립부에 `<a href="#id" data-to="id">`와 `<section class="page" id="p-id" hidden>`를 추가합니다. 라우터는 `.page` 섹션과 `nav.tabs a`만 봅니다.
- 이 폴더의 `dwg/ alt/ img/`는 2026-09-28에 발행본과 크기를 대조해 옮겼습니다(29개 모두 같음).

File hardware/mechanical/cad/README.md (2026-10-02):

# Toccata CAD — 출력용 STL과 전체 조립 (v4 W1+ r4.5 건반 액션 + L2 한 몸 뒷바)

이 폴더의 모든 파일은 `src/build_all.py`가 설계 모델에서 바로 만든 것입니다. 손으로 옮겨 적은 치수는 없습니다.
- **건반 액션:** `hardware/mechanical/key-action-v4/model/geometry.json`(도면 1~15가 그려지는 같은 모델)
- **본체·뒷바:** L2 한 몸 뒷바 `spec/body_L2.json`(사용자 요청 2026-10-01, W1 음향 확인 통과). 스피커 각도 등 모든 스피커 수치는 `src/body.py`의 `ANGLE = 40` 한 줄에서 사양 규칙으로 계산합니다. 그릴 격자·가스켓·보드 구멍은 v3.2 사양(`spec/body_speakers.json`, `body_centre_unit.json`)에서 옮김. 이전 뒷바: L1 `src/body_L1.py`·`electronics_L1.py`, v3.2 `body_v3_tall.py`(둘 다 쓰지 않음)
- **전자 부품 위치:** 회로 rev B(BRD-01·02), 가운데 칸은 사양 `centre_contents` 상자 그대로
- **추출한 사양:** `spec/*.json`. 항목마다 출처가 달려 있고, 추정값에는 `assumed`가 표시돼 있습니다.
- **터치스크린:** R31 3판(Waveshare 7-DSI-TOUCH-C, W1 `touchscreen/rev3/design/CAD_SPEC_rev3.md` 3a + `numbers.json`, 사용자 승인 2026-10-01). 화면 뚜껑에 경첩·다리 주머니·리본 구멍을 더하고 받침·받침다리·점검창 덮개·리본 클립을 `07_터치스크린`으로 뽑습니다. 화면은 25°로 서 있고 접은 상태는 따로 보는 그룹입니다(부록 A10, 아래 '터치스크린 3판').

좌표는 설계 문서와 같습니다. 원점은 A0 왼쪽 경계(x=0), 흰건반 앞끝(y=0), 책상(z=0)이고 단위는 mm입니다. 모듈 Ok는 x = 47 + 164.5·(k−1)에서 시작합니다.

## L2 한 몸 뒷바 한눈에

| 항목 | L1 (2026-09-30) | L2 (이 모델) |
|---|---|---|
| 전체 깊이 (y) | 447 (래치 포함 471) | **342.5** |
| 건반 뒤 면적 (1254 폭) | 294,690 mm² | **163,647 mm² (−44.5 %)** |
| 가운데 윗면 | z88 | **z72.85** (건반 윗면과 같은 높이) |
| 스피커 파트 | 213 × 195 × 129 (z5~134), 30° (수직에서), 2.95 L | 273 × 128.5 × 139.65 (z5~144.65) |
| 앞판 각도 | 수직에서 30° | **수평에서 40°** (수직에서 50°), 경사 길이 123.26 |
| 스피커 안 부피 | 2.95 L | 2.159 L (유닛 빼면 2.059 L = W1 규칙 −0.1 L; check_body.py는 유닛 모형을 속이 찬 덩어리로 빼서 1.89 L, 최저 1.8) |
| Qtc / Fc (Vas 3 L 가정) | 약 1.02 | 1.13, Fc 141~201 Hz (유닛 뺀 부피; 전체 부피면 1.11), 흡음솜 넣으면 약 1.08, Fc 135~192 Hz (W1 방식, 유닛 뺀 2.059 L × 1.175) |
| 스피커 겨냥 (가운데 귀 y-300 z460) | — | 축 수평 위 50°, 귀는 32.7° → y-z 면에서 17.3° 어긋남 (W1 한계 20°) |
| 모듈 USB 선 | 모듈 뒤 열린 통로 y212~252 (위에서 보임) | 뒷바 밑 닫힌 통로 y212~241 × z0~27 (거의 보이지 않음 — 배기 홈·건반 뒤 2 mm 틈으로만 조금) |
| 27° 소리 길 여유 (수직) | — | 사양 선(Ø94 가장자리 D(−47, 0)에서): 모듈 뒤 윗모서리 3.5, 플랜지 모서리 2.61, 가스켓 모서리 4.37, 앞판 아래 끝 7.75, 그릴 옆벽 발 3.1 (W1 ≥3.0); 실제 소리 가장자리 D(−45, 7)에서: 모듈 뒤 윗모서리 8.64 |
| D14 (자석 ↔ 홀 소자 y67 z12.9) | 226 (z8까지) | 자석 중심 228.4, 가장 가까운 쇠(플랜지 아래 모서리) 159.7 (≥100; 사양 방식 z8까지 229.6 / 161.5) |
| 합판 | 0.633 m² (600 × 1200 포함) | 0.343 m², 조각 16 (400 × 1200 한 장) |

- **평면:** x−16~1238 × y0~342.5 직사각형(R27). 뒷바(y214~342.5)는 모듈 뒷벽 y212 뒤 2.0 mm 공기 틈을 두고 섭니다(D15: 딱딱하게 닿지 않음). 위치는 끝 부속 볼의 방진 브래킷 BRK2 핀이 정합니다.
- **가운데 유닛** x260~962: 앞벽이 없어 뚜껑을 열면 모듈 USB-C 플러그를 위에서 바로 잡습니다(앞 공간 y214~241). 뚜껑 L(x260~501)·R(x721~962)은 오꾸메 + 자석 3쌍, 가운데 화면 뚜껑(x501.5~720.5, 이음마다 0.5 틈)은 출력 + M3×10 4개입니다. 모두 가운데 유닛 벽·레일·기둥에만 얹혀 모듈에 힘이 가지 않습니다.
- **스피커 파트:** 유닛 중심 (x160.5 / 1061.5, y260, z100.45), 축 (0, −0.6428, 0.766) = 수평 위 50°. 스피커 윗면은 z144.65, L1보다 10.65 높습니다 — 27° 소리 길 3.5(모듈 뒤 윗모서리 위), 그릴 판 아래 모서리 y213 뒤(R18), 앞판 각도 40°가 정한 값입니다(부록 A9). **43° 안(처음 L2 선택, 사용자가 2026-10-01 40°로 바꿈):** 윗면 z148.06, 뒤 y341.5, 플랜지 여유 3.11. `src/body.py`의 `ANGLE`만 바꾸면 모든 파일이 다시 만들어집니다.
- **소리 길:** Ø94 구멍 아래 가장자리에서 연주자 쪽 27° 선이 모듈 뒤 윗모서리 위 3.5로 지납니다(W1 ≥3.0). 사양의 선은 앞판 면의 Ø94 가장자리 D(−47, 0)에서 시작해 앞에 붙는 가스켓(3)·플랜지(4) 뒤에서 출발하므로 그 둘은 선을 걸치고, 아래 모서리가 선보다 2.61(플랜지) / 4.37(가스켓) 아래입니다. 플랜지 모서리 여유(2.61)는 W1 엄격 기준 3.0보다 작지만 40°를 고를 때 W1이 받아들였습니다(모듈 뒤 윗모서리 여유 3 이상 조건, 사양 angle_decision 2.61). 실제로 소리가 나오는 가장자리(유닛 프레임 입구 D(−45, 7))에서 그은 27° 선은 모듈 뒤 윗모서리 위 8.64로 지나고 그릴 아래 띠 말고는 단단한 것에 닿지 않습니다(check_body.py가 광선·3 mm 띠로 확인). 그릴 판 아래 모서리만 선이 판 밑으로 1.54(수직 방향 1.72) 지나가는데, 판이 구멍 뚫린 격자이고 아래 링 벽이 없어 W1이 승인한 예외입니다.
- **D14:** 자석 중심에서 홀 소자(y67, z12.9 = 센서 바 포켓 바닥 12.19 + 0.75)까지 228.4, 가장 가까운 쇠(플랜지 아래 모서리)까지 159.7 (≥100; 사양 표는 z8까지 재서 229.6 / 161.5). EL·ER 끝 부속을 포함한 홀 소자 88개 모두 같은 y67 줄이라 3D 거리도 같습니다(check_body.py).
- **선 가리기:** 밖에서 선이 보이는 곳은 계획된 구멍뿐입니다 — 뚜껑 L·화면 뚜껑·뚜껑 R의 배기 홈 아래(위와 앉은 눈높이에서 뒤 줄의 20 V선·스피커선 L, 뚜껑 R 홈 아래 스피커선 R)와 건반 뒤 2 mm 틈(y212~214, 모듈 플러그 윗면 z18.3). 가리려면 배기 홈 밑에 검은 망사나 스피커 천을 붙이고(홈을 줄여도 앉은 눈높이 선은 가려지지 않음), 2 mm 틈에 사양의 회색 펠트 띠 2 mm를 끼웁니다. 터치스크린 3판(25°, 위 끝 z189.23)이 앉은 눈높이에서 화면 뚜껑 배기 홈(y300~325)을 가립니다 (접으면 받침 아래).

## W1 음향 조건 (2026-10-01 통과, 조건부) — 모델에 넣은 방법

| 조건 | 모델 / 조립 |
|---|---|
| 폴 벤트: 자석 뒤 가운데 구멍 축 방향 10 mm 이상 비움 (뒤판·윗판·솜 모두) | 축 방향으로 가장 가까운 아랫판까지 55.6 mm 비어 있음(check_body.py가 광선과 Ø20 × 10 원기둥으로 확인). 솜은 이 자리에 넣지 않음(스피커 뒤판 메모) |
| 흡음솜: 폴리에스터를 상자 전체에 느슨하게 (가운데 포함), 유닛 뒤 10 mm와 폴 벤트 앞은 비움 | 조립 순서 2번(Ø94 구멍으로 넣음). 모델에는 솜이 없음 |
| 그릴 개구율 40 % 이상, 구멍 Ø3 이상 | 구멍 95개, 모두 Ø3 원이 들어가는 칸만 뚫음. 개구율 70.4 % (격자), Ø94 앞 72 % |
| 그릴 판 두께 2 mm 이하 (두꺼우면 구멍 앞 모따기) | 판 2 (w11~13) |
| 27° 선이 그릴 판 아래 모서리 밑으로 지나감 (판이 격자라는 전제의 예외; W1 승인 때 43°에서 0.94) | 40°에서 선이 판 아래 모서리 밑 1.54 (수직 1.72). 판 아래 2 mm는 막힌 띠(s−50~−48)라 27°에서 유닛 콘 맨 아래 약 1 mm가 가려짐 — 음향 영향은 작음. 격자 칸은 s−48부터 |
| 그릴은 나사 4개로 떨리지 않게 | 고정 구멍 4-Ø4.5, 직결피스 8호 19 mm × 4 → 앞판 파일럿 Ø3.4 × 9 |
| 각도: W1은 43°로 진행, 40°도 음향상 가능(모듈 모서리 여유 3 이상) → 사용자 40° 선택 (2026-10-01, W1 전달), 플랜지 모서리 여유 2.61도 W1이 받아들임 | ANGLE = 40: 윗면 z144.65, 뒤 y342.5, 모듈 뒤 윗모서리 여유 3.5, 플랜지 모서리 2.61, 가운데 귀와 17.3°. 43°(처음 선택) 값은 위 '43° 안' |
| Qtc: 유닛 뺀 부피 기준 (Vas 3 L 가정; 43°에서 W1 1.12 / 솜 1.07), Vas 4 L이면 약 1.24라 솜은 필수 | 40°: 유닛 뺀 2.059 L → Qtc 1.13, Fc 141~201 Hz; 솜 넣으면 약 1.08, Fc 135~192 Hz (W1 전달 값 약 1.13 / 1.09). Vas는 단계 0에서 측정 |
| 밀폐 유지 (나사 길이·막힌 구멍) | 고무발 8호 13 mm 이하 + 구멍에 MS 폴리머, 그릴 8호 19 mm 이하, 유닛 M4×12 이하 (L69 인서트는 면까지), 손잡이볼트 M4×20 (L72, 최대 M4×22) — 이보다 길면 밀폐면(1.5~3.5 mm)을 뚫음. 안쪽 옆판의 L73 인서트 구멍 Ø5.8 × 8: 판 11.5 중 밑에 **1.5 이상** 남아야 함 (지름 부분 밑 3.5, 드릴 끝 2 밑 1.5) — L73 나사산 인서트는 길이 6 (Norelem 07653-04, 최소 구멍 깊이 8 = 구멍 깊이) |

## 폴더

| 경로 | 내용 |
|---|---|
| `stl/print/` | **출력용.** 베드 위 방향으로 놓인 부품. 모양이 같은 부품은 파일 하나이고, 파일 이름 끝에 개수를 붙였습니다(`__7개`) |
| `stl/annotated/` | **보기용(출력 금지).** 부품 옆에 치수선과 숫자를 입체로 붙였습니다. 조립 방향으로 놓여 있습니다. `08_합판재단/`은 합판 조각(재단·구멍 자리) |
| `stl/assembly/` | 모든 부품을 조립 위치 그대로 둔 파일입니다. 그룹별 STL을 한꺼번에 열면 전체가 맞춰집니다 (단 `터치스크린_(접은_상태,_별도_보기).stl`은 접은 자세라 같이 열면 사용 상태 화면과 겹침; `댐퍼_페달_(바닥)`은 바닥 위치). `Toccata_전체조립.stl`은 한 파일에 전부 들어 있습니다 (접은 화면·페달 빼고) |
| `Toccata_전체조립.3mf` | 그룹·색 이름이 붙은 전체 조립(슬라이서·3D 뷰어용) |
| `Toccata_전체조립.glb` | 웹 뷰어용 |
| `manifest.json` | 부품마다 id, 이름, 종류, 그룹, 외곽 상자, 출력 파일 |
| `spec/` | 문서에서 뽑은 세부 사양(출처 포함). 뒷바는 `body_L2.json` |
| `viewer/` | 통합 아티팩트 09 CAD 탭 원본(cad.html·css·js, parts.json) |
| `src/` | 생성기. `python3 src/build_all.py` 한 번으로 STL·3MF·GLB·manifest·README·뷰어 데이터를 모두 다시 만듭니다(약 10~20초). 검사: `check_interf.py`(건반 액션), `check_body.py`, `check_electronics.py` |

## 출력 목록

### 01_건반

| 파일 | 개수 | 크기 (베드 위, mm) | 속 꽉 채움 질량 g | 재료 | 방법 |
|---|---|---|---|---|---|
| `백건_C__7개.stl` | 7 | 22.0 × 199.0 × 22.8 | 22.6 | PETG 흰색 | a |
| `흑건_C#·D#__14개.stl` | 14 | 10.4 × 144.8 × 34.8 | 17.9 | PETG 검정 | b |
| `백건_D__7개.stl` | 7 | 22.0 × 199.0 × 22.8 | 22.9 | PETG 흰색 | a |
| `백건_E__7개.stl` | 7 | 22.0 × 199.0 × 22.8 | 22.6 | PETG 흰색 | a |
| `백건_F__7개.stl` | 7 | 22.0 × 199.0 × 22.8 | 22.1 | PETG 흰색 | a |
| `흑건_F#__7개.stl` | 7 | 10.6 × 144.8 × 34.8 | 17.9 | PETG 검정 | b |
| `백건_G__7개.stl` | 7 | 22.0 × 199.0 × 22.8 | 22.5 | PETG 흰색 | a |
| `흑건_G#__7개.stl` | 7 | 11.4 × 144.8 × 34.8 | 17.9 | PETG 검정 | b |
| `백건_A__7개.stl` | 7 | 22.0 × 199.0 × 22.8 | 22.5 | PETG 흰색 | a |
| `흑건_A#·A#0__8개.stl` | 8 | 10.8 × 144.8 × 34.8 | 17.9 | PETG 검정 | b |
| `백건_B__7개.stl` | 7 | 22.0 × 199.0 × 22.8 | 22.1 | PETG 흰색 | a |
| `백건_A0__1개.stl` | 1 | 22.0 × 199.0 × 22.8 | 24.9 | PETG 흰색 | a |
| `백건_B0__1개.stl` | 1 | 22.0 × 199.0 × 22.8 | 22.1 | PETG 흰색 | a |
| `백건_C8__1개.stl` | 1 | 22.0 × 199.0 × 22.8 | 25.5 | PETG 흰색 | a |

- **a** 윗면(z43.5)을 매끈한 PEI에 대고 뒤집어 출력. 트리 서포트는 숨은 빔·꼬리(y146~199) 밑만. 노치 R2.55·핀 홈에 부싱 천 0.5T(i068)를 붙임. 자석 Ø5×2 N35(i098) 압입 + 순간접착제, 캡스턴 M3×6 버튼헤드(i014) + M3 너트(i011)를 +x 옆 홈으로 (DESIGN 15, D02)
- **b** 윗면(z55.5)을 매끈한 PEI에 대고 뒤집어 출력. 트리 서포트는 윗면 뒤끝 턱·숨은 빔·꼬리(y144.5~199) 밑만. 노치 R2.55·핀 홈에 부싱 천 0.5T(i068)를 붙임. 자석 Ø5×2 N35(i098) 압입 + 순간접착제, 캡스턴 M3×6 버튼헤드(i014) + M3 너트(i011)를 +x 옆 홈으로 (DESIGN 15, D02)

### 02_레버캐리어

| 파일 | 개수 | 크기 (베드 위, mm) | 속 꽉 채움 질량 g | 재료 | 방법 |
|---|---|---|---|---|---|
| `레버캐리어_C__7개.stl` | 7 | 23.8 × 59.4 × 12.5 | 3.6 | PETG | a |
| `레버캐리어_C#__7개.stl` | 7 | 23.8 × 59.4 × 12.7 | 3.6 | PETG | a |
| `레버캐리어_D__7개.stl` | 7 | 23.8 × 59.4 × 10.6 | 3.6 | PETG | a |
| `레버캐리어_D#__7개.stl` | 7 | 23.8 × 59.4 × 13.6 | 3.6 | PETG | a |
| `레버캐리어_E__7개.stl` | 7 | 23.8 × 59.4 × 12.4 | 3.6 | PETG | a |
| `레버캐리어_F__7개.stl` | 7 | 23.8 × 59.4 × 10.6 | 3.6 | PETG | a |
| `레버캐리어_F#__7개.stl` | 7 | 23.8 × 59.4 × 12.9 | 3.6 | PETG | a |
| `레버캐리어_G__7개.stl` | 7 | 23.8 × 59.4 × 12.1 | 3.6 | PETG | a |
| `레버캐리어_G#__7개.stl` | 7 | 23.8 × 59.4 × 10.6 | 3.6 | PETG | a |
| `레버캐리어_A__7개.stl` | 7 | 23.8 × 59.4 × 12.1 | 3.6 | PETG | a |
| `레버캐리어_A#__7개.stl` | 7 | 23.8 × 59.4 × 12.1 | 3.6 | PETG | a |
| `레버캐리어_B__7개.stl` | 7 | 23.8 × 59.4 × 10.6 | 3.6 | PETG | a |
| `레버캐리어_A0__1개.stl` | 1 | 23.8 × 59.4 × 15.8 | 3.7 | PETG | a |
| `레버캐리어_A#0__1개.stl` | 1 | 23.8 × 59.4 × 12.1 | 3.6 | PETG | a |
| `레버캐리어_B0__1개.stl` | 1 | 23.8 × 59.4 × 10.6 | 3.6 | PETG | a |
| `레버캐리어_C8__1개.stl` | 1 | 23.8 × 59.4 × 10.6 | 3.6 | PETG | a |

- **a** −x 옆면을 베드에 눕혀 출력(칼라는 모두 +x 쪽, A5), 음 이름 새김(Arial Black, 0.4)이 위. 강철 칸 가운데(y169.4~170.6)의 떼는 지지대는 파일에 들어 있음(먼 옆벽과 0.2 틈, 뿌리 0.4): 떼어 내고 사포질한 뒤 접착. 허브 구멍 Ø3.9로 출력 → Ø4.0 드릴(i126). 강철 블록은 강철 띠 9T×19(i119)를 40 −0.1/−0.3으로 잘라(칸 길이 40.0, 두께 8.9~9.1만) MS 폴리머로 접착 (DESIGN 15, D07)

### 03_프레임

| 파일 | 개수 | 크기 (베드 위, mm) | 속 꽉 채움 질량 g | 재료 | 방법 |
|---|---|---|---|---|---|
| `프레임_모듈__7개.stl` | 7 | 168.5 × 212.0 × 69.8 | 360.7 | PETG 회색 | a |
| `끝부속프레임_왼쪽__1개.stl` | 1 | 67.0 × 212.0 × 69.8 | 378.7 | PETG 회색 | b |
| `끝부속프레임_오른쪽__1개.stl` | 1 | 39.5 × 212.0 × 69.8 | 342.2 | PETG 회색 | b |

- **a** 바로 세워 출력. 윗판 밑(y146.5~209)은 바닥·선반에서 올라오는 트리 서포트. 키퍼 훅 밑(y11~15 · y77~81, z28.6)과 매단 위치 핀도 서포트. 핀 보스 구멍 Ø3.9 눈물방울 → Ø4.0 드릴. 밸런스 핀 구멍 Ø1.95(막힌 z11.3)는 Ø1.9~2.0 드릴로 다듬고 핀 압입. 서포트 약 88 g (DESIGN 15)
- **b** 바로 세워 출력. 윗판 밑(y146.5~209)은 바닥·선반에서 올라오는 트리 서포트. 키퍼 훅 밑(y11~15 · y77~81, z28.6)과 매단 위치 핀도 서포트. 핀 보스 구멍 Ø3.9 눈물방울 → Ø4.0 드릴. 밸런스 핀 구멍 Ø1.95(막힌 z11.3)는 Ø1.9~2.0 드릴로 다듬고 핀 압입. 서포트 약 88 g (DESIGN 15). 볼(cheek)은 속이 꽉 찬 덩어리: 벽 3줄 + 채움 15 % gyroid로 약 200 g 절약

### 04_센서바·패드바·가림판·마개

| 파일 | 개수 | 크기 (베드 위, mm) | 속 꽉 채움 질량 g | 재료 | 방법 |
|---|---|---|---|---|---|
| `센서바__7개.stl` | 7 | 162.4 × 18.5 × 5.0 | 14.6 | PETG 회색 | a |
| `가림판띠__7개.stl` | 7 | 164.1 × 27.4 × 3.7 | 6.1 | PETG 검정 | b |
| `레버봉끝마개__9개.stl` | 9 | 4.0 × 4.0 × 1.2 | 0.0 | PETG | c |
| `패드바_칸1__7개.stl` | 7 | 36.4 × 38.5 × 6.5 | 3.3 | PETG | d |
| `패드바_칸2__7개.stl` | 7 | 37.3 × 38.5 × 6.5 | 3.4 | PETG | d |
| `패드바_칸3__7개.stl` | 7 | 36.2 × 38.5 × 6.5 | 3.4 | PETG | d |
| `패드바_칸4__7개.stl` | 7 | 35.3 × 38.5 × 6.5 | 3.2 | PETG | d |
| `센서바_왼쪽__1개.stl` | 1 | 46.0 × 18.5 × 5.0 | 4.4 | PETG 회색 | a |
| `가림판띠_왼쪽__1개.stl` | 1 | 46.6 × 27.4 × 3.7 | 1.8 | PETG 검정 | b |
| `패드바_끝부속_왼쪽__1개.stl` | 1 | 42.8 × 38.5 × 6.5 | 3.8 | PETG | d |
| `센서바_오른쪽__1개.stl` | 1 | 22.5 × 18.5 × 5.0 | 2.5 | PETG 회색 | a |
| `가림판띠_오른쪽__1개.stl` | 1 | 23.1 × 27.4 × 3.7 | 1.0 | PETG 검정 | b |
| `패드바_끝부속_오른쪽__1개.stl` | 1 | 19.1 × 38.5 × 5.7 | 1.6 | PETG | d |

- **a** v3 방향(포켓이 위). 홀센서 DRV5055 LPG를 포켓에 눕혀 넣고 왼쪽 끝을 M3×10(i058) 2개로 받침 기둥에 자가 탭
- **b** 넓은 면을 베드에, 걸이 립은 위로 (DESIGN 15)
- **c** 끝면을 베드에 (원판 Ø4.0 × 1.2). 이음 쪽 핀 보스 구멍에 핀 면과 같게 눌러 끼움 (D18)
- **d** 윗면을 베드에(쐐기가 위). 뒤 계단(y167~185)은 베드에서 1.5 떠 있으니 그 밑과 잎 혀 밑에 서포트(윗 틈 0.2, 인터페이스 1층; 이 면은 윗판 자리 z67.35라 매끈하게). 잎 혀는 자유 상태(설치 때 0.3 눌림)로 출력, 둘레 틈 0.6. 칸 이름은 윗면에 0.4 새김 (P13, DESIGN 15). 쐐기는 설계 패드 PORON 6T + 펠트 1T 기준

### 05_본체출력물

| 파일 | 개수 | 크기 (베드 위, mm) | 속 꽉 채움 질량 g | 재료 | 방법 |
|---|---|---|---|---|---|
| `스피커앞판_경사배플_L__1개.stl` | 1 | 250.0 × 126.5 × 11.5 | 323.1 | PETG (검정 또는 회색) | a |
| `스피커앞판_경사배플_R__1개.stl` | 1 | 250.0 × 126.5 × 11.5 | 323.1 | PETG (검정 또는 회색) | a |
| `스피커그릴_경사__2개.stl` | 2 | 150.0 × 107.0 × 13.0 | 91.5 | PETG 회색 또는 검정 | b |
| `스피커통로틀__2개.stl` | 2 | 48.9 × 33.0 × 250.0 | 157.3 | PETG 회색 | c |
| `통로옆마개__2개.stl` | 2 | 26.0 × 27.0 × 3.0 | 2.0 | PETG 회색 | d |
| `핀소켓_둥근__1개.stl` | 1 | 11.0 × 12.0 × 10.0 | 1.3 | PETG 회색 | e |
| `핀소켓_긴구멍__1개.stl` | 1 | 15.0 × 12.0 × 10.0 | 1.6 | PETG 회색 | e |
| `방진브래킷2_L__1개.stl` | 1 | 22.0 × 24.0 × 16.0 | 2.5 | PETG 회색 | f |
| `방진브래킷2_R__1개.stl` | 1 | 22.0 × 24.0 × 16.0 | 2.5 | PETG 회색 | f |
| `CU화면뚜껑_터치3판__1개.stl` | 1 | 219.0 × 128.5 × 25.5 | 176.9 | PETG | g |
| `뚜껑이음레일기둥_1__1개.stl` | 1 | 20.0 × 117.0 × 44.9 | 22.6 | PETG 회색 | h |
| `뚜껑이음레일기둥_2__1개.stl` | 1 | 20.0 × 117.0 × 44.9 | 22.6 | PETG 회색 | h |
| `뒤판출력물_IO__1개.stl` | 1 | 140.5 × 44.9 × 38.5 | 36.2 | PETG 회색 | i |
| `허브선반__1개.stl` | 1 | 224.0 × 49.0 × 8.5 | 28.6 | PETG 회색 | j |
| `보조배터리받침__1개.stl` | 1 | 109.0 × 75.0 × 14.0 | 27.9 | PETG 회색 | k |
| `XT30집게_L__1개.stl` | 1 | 26.0 × 19.0 × 15.5 | 2.3 | PETG 회색 | l |
| `XT30집게_R__1개.stl` | 1 | 20.0 × 19.0 × 15.5 | 1.7 | PETG 회색 | l |
| `보드받침기둥_Pi_Ø6_6mm__4개.stl` | 4 | 6.0 × 6.0 × 6.0 | 0.2 | PETG 회색 | m |
| `보드받침기둥_나사_Ø7_5mm__6개.stl` | 6 | 7.0 × 7.0 × 5.0 | 0.2 | PETG 회색 | m |
| `보드받침기둥_PED_Ø6_5mm__2개.stl` | 2 | 6.0 × 6.0 × 5.0 | 0.2 | PETG 회색 | m |
| `보드받침기둥_PED_Ø6_5mm_핀__2개.stl` | 2 | 6.0 × 6.0 × 7.5 | 0.2 | PETG 회색 | m |
| `퓨즈홀더받침__1개.stl` | 1 | 50.0 × 14.0 × 9.0 | 3.5 | PETG 회색 | n |
| `케이블집게__8개.stl` | 8 | 20.0 × 10.0 × 8.0 | 1.4 | PETG 회색 | o |

- **a** 바깥면(유닛·그릴 면)을 베드에 눕혀 출력 (250 × 약 125 × 11.5, 브림 필수 - 256 판에 3 mm씩 여유). 윗마개의 윗면은 수평에서 40° 기운 짧은 내민 면(베드 쪽 3 mm), 서포트 없음. 인서트·파일럿은 베드 면에서 막힌 구멍. 벽 4줄 + 채움 30~40 %. 휘면 사양 risks대로 2조각(혀-홈 + MS 폴리머, 누설 시험). 옆판 사이에 끼워 둘레를 목공본드/MS 폴리머로 밀봉. 베드에 닿는 앞 아래 모서리 F(250 길이)는 40° 칼날 모서리라 첫 층이 거칠게 나옴 - 출력 뒤 줄로 다듬음; Ø94 구멍 아래쪽은 상자 안쪽 밑면(y229~236)으로 조금 뚫려 나오는데 밀폐와 상관없음(붙이는 면 y218.6~225은 그대로)
- **b** 그릴 판을 베드에 두고 옆벽·위 링 벽(11)을 위로 세워 출력. 잘린 윗면은 수평에서 40° 기운 내민 면(높이 13, 짧음) - 서포트 없이 됨, 아래쪽 면이 조금 거칠 수 있음. 직결피스 8호 19 mm ×4로 앞판 파일럿에 (W1: 떨리지 않게 4개 모두)
- **c** 끝면(x 방향 면, 단면 33 × 48.92)을 베드에 세워 출력, 높이 250 - 브림 5 mm, 느린 속도(얇은 벽 6이 250 높이). 서포트 없음(단면 그대로 올라감). 옆판 사이에 끼워 앞벽 윗면·턱 위에 앞판을 MS 폴리머로, 세움벽 밑은 아랫판 앞 모서리에 본드
- **d** 넓은 면을 베드에 눕혀 출력(두께 3). 서포트 없음
- **e** 붙이는 윗면(z27)을 베드에, 구멍이 위로 열림. 서포트 없음
- **f** 밑면(z8)을 베드에, 핀이 위로 서도록 출력(서포트 없음). 그로밋 자리·웹 구멍(y 방향)은 눈물방울(꼭짓점 위) - 자리 밑 바닥은 0.75 (베드 위 첫 3~4층, 그대로 둠), 자리 윗부분은 3 mm 내민 지붕. 벽 4줄 + 채움 40 % (핀은 꽉). 그로밋을 웹에 끼우고 M3×16 볼트 ×2를 볼의 너트에 조인 뒤(스피커를 올리기 전) 스피커 소켓을 핀에 내려 끼움
- **g** 갈비 면(z61.35)을 베드에, 윗면·경첩 볼·발이 위 (사양 A-9). 경첩 받침·구멍 벽·클립 덩어리·주머니 덩어리·나사 보스가 모두 베드까지 채워져 서포트 없음; 판은 갈비 위 브리지(갈비 간격 40 이하). 경첩 축 구멍(가까운 볼 Ø3.3, 먼 볼 Ø2.5)은 물방울(꼭짓점 위)로 뽑고 드릴 Ø3.3 / Ø2.5로 다듬음(먼 볼은 M3×20이 직접 탭). 클립 핀 구멍 Ø3.1 × 5는 베드 쪽에서 열림. 약 177 g
- **h** 레일 윗면(z61.35)을 베드에, 기둥이 위로 서도록 출력(서포트 없음). 인서트는 베드 쪽 면(= 윗면)에서 인두로 넣음
- **i** 바깥면(y342.5)을 베드에. 구멍·루버는 수직, 스위치 테두리 자리 2 mm는 베드 쪽 오목(작은 브리지). 잭 받침·탭·오른쪽 탭의 혀(탭보다 좁음)는 위로 섬 - 서포트 없음. 벽 3줄 + 채움 25 %
- **j** 선반 밑면(z41.5)을 베드에, 받침·앰프 받침이 위. 서포트 없음 (뒤판 나사 구멍은 눈물방울, 머리 길 홈은 윗면)
- **k** 바닥을 베드에. 끈 구멍은 브리지 22. 서포트 없음
- **l** 끝벽에 붙는 판을 베드에, 홈이 위로 서도록 출력(서포트 없음)
- **m** 밑면을 베드에 세워 출력, 채움 100 %. 서포트 없음
- **n** 밑면을 베드에. 서포트 없음
- **o** 붙이는 면(20 × 10)을 베드에, 홈이 위로. 걸림 턱 밑은 45° - 서포트 없음. 8개를 한 판에

05 폴더는 L2 뒷바 출력물 23종 43개입니다. 가장 큰 것은 `스피커앞판_경사배플_L__1개.stl`(250.0 × 126.5 × 11.5 mm)로 256 판 안에 들어갑니다. `CU화면뚜껑_터치3판`은 터치스크린 3판의 경첩 볼·다리 주머니·리본 구멍·받침 발이 붙은 뚜껑이라 갈비 면을 베드에 둡니다(07 폴더 부품과 짝).

### 07_터치스크린

| 파일 | 개수 | 크기 (베드 위, mm) | 속 꽉 채움 질량 g | 재료 | 방법 |
|---|---|---|---|---|---|
| `화면받침_크래들__1개.stl` | 1 | 170.7 × 21.7 × 119.8 | 86.0 | PETG | a |
| `받침다리__1개.stl` | 1 | 10.0 × 73.0 × 6.0 | 5.3 | PETG | b |
| `점검창덮개__1개.stl` | 1 | 32.5 × 39.0 × 5.9 | 5.8 | PETG | c |
| `리본클립__1개.stl` | 1 | 30.0 × 12.0 × 7.5 | 1.4 | PETG | d |
| `화면덮개_선택__1개.stl` | 1 | 173.0 × 108.0 × 3.0 | 71.2 | PETG | e |

- **a** 윗변(u103.5 면)을 베드에 세워 출력, 귀가 위 (높이 119.76, 사양 119.76). 귀 축·다리 걸이 구멍(x 방향)과 보스 구멍(w 방향)은 물방울(꼭짓점 위)로 뽑고 드릴로 다듬음(귀·가까운 볼 Ø3.3, 먼 볼 Ø2.5, 보스 Ø2.8; 보스 자리파기 Ø5.5는 물방울 위를 평평하게 자른 모양, 1.58 브리지). 다리 걸이 볼(밑면 45°, 뒷판에서 u38.87)·다리 클립·뒤 패드는 45° 면이라 서포트 없음; 가로 갈비·창 둘레 갈비·보스는 3 mm 이하 짧은 내민 면. 아래 벽(u−2.5~0)의 앞 턱 w−1~10.5(유리가 얹히는 면)는 출력 때 지붕이 되므로 그 밑(유리 주머니 안, 앞이 트여 떼기 쉬움)에만 트리 서포트. 약 86 g, 약 3.7시간(W1 추정)
- **b** 넓은 면(73 × 10)을 베드에 눕혀 출력(높이 6). 축 구멍 Ø3.3은 물방울(꼭짓점 위)로 뽑고 드릴 Ø3.3로 다듬음. 벽 4줄 이상(속 거의 꽉). 약 5 g, 약 20분
- **c** 끼움부 면(w10.5, 볼록 자리 속이 열린 면)을 베드에, 턱·볼록 자리가 위. 턱은 끼움부보다 1.7 내밀어 짧은 내민 면, 볼록 자리 천장은 13.7 브리지, 걸쇠 보 위 턱은 2 × 7 브리지 - 서포트 없음. 걸쇠 보는 벽 2줄(0.42) 이상으로 꽉 채움. 약 6 g
- **d** 넓은 면(30 × 12)을 베드에, 핀·전원선 홈이 위. 서포트 없음. 약 1 g
- **e** 선택 부품(접은 화면을 덮을 때만). 평판을 베드에. 약 70 g. 사용 상태 조립에는 없음(접은 상태 보기에만 있음)

07 폴더는 R31 터치스크린 3판 출력물입니다. 받침은 윗변을 베드에 세워(높이 119.76) 귀가 위로 오고, 아래 벽 앞 턱(유리가 얹히는 면) 밑에만 트리 서포트가 필요합니다. `화면덮개_선택`은 접은 화면을 덮을 때만 뽑습니다. 출력 전에 부록 A10의 '받은 부품으로 확인할 것'을 먼저 봅니다.

### 04b_패드바_PORON5T용 (04 대신 쓰는 변형)

| 파일 | 개수 | 크기 (베드 위, mm) | 속 꽉 채움 질량 g | 재료 | 방법 |
|---|---|---|---|---|---|
| `패드바_칸1_PORON5T용__7개.stl` | 7 | 36.4 × 38.5 × 7.5 | 3.6 | PETG | a |
| `패드바_칸2_PORON5T용__7개.stl` | 7 | 37.3 × 38.5 × 7.5 | 3.6 | PETG | a |
| `패드바_칸3_PORON5T용__7개.stl` | 7 | 36.2 × 38.5 × 7.5 | 3.6 | PETG | a |
| `패드바_칸4_PORON5T용__7개.stl` | 7 | 35.3 × 38.5 × 7.5 | 3.5 | PETG | a |
| `패드바_끝부속_왼쪽_PORON5T용__1개.stl` | 1 | 42.8 × 38.5 × 7.5 | 4.1 | PETG | a |
| `패드바_끝부속_오른쪽_PORON5T용__1개.stl` | 1 | 19.1 × 38.5 × 6.7 | 1.7 | PETG | a |

- **a** 구매 목록의 PORON 5T(i124)를 쓸 때의 패드 바: 쐐기를 패드 면 법선으로 1.0 두껍게(설계 6T와 같은 패드 면). 6T를 사면 04 폴더 파일을 씀. 출력 방법은 04 패드 바와 같음

### 06_출력공구 (악기당 1벌)

| 파일 | 개수 | 크기 (베드 위, mm) | 속 꽉 채움 질량 g | 재료 | 방법 |
|---|---|---|---|---|---|
| `공구_벤치지그받침_T1a__1개.stl` | 1 | 72.0 × 222.0 × 62.5 | 38.4 | PETG | a |
| `공구_높이블록_T1b__1개.stl` | 1 | 10.0 × 34.0 × 50.6 | 10.3 | PETG | a |
| `공구_캡스턴벤치게이지_T2__1개.stl` | 1 | 88.8 × 36.6 × 18.1 | 13.3 | PETG | a |
| `공구_밸런스핀높이게이지_T3__1개.stl` | 1 | 52.0 × 7.5 × 18.0 | 6.3 | PETG | a |

- **a** 건반 액션 설계의 출력 공구(DESIGN 10.1, key-action-v4/printables/tools/tools.md): 악기당 1벌, 서포트 없음; T2·T3는 채움 100 %·층 0.1

04b 변형과 06 공구를 뺀 악기 출력 부품은 모두 290개, 파일은 모두 84종입니다. 질량은 속을 100% 채운 PETG(1.27 g/cm³) 기준이라 실제(슬라이서 채움 %)보다 큽니다. 모두 합하면 7.30 kg입니다.

예비는 부품표(parts_list.json)를 따릅니다: 백건 파일마다 +1(10개), 흑건은 C#·D# +2, F# +1, G# +1, A#·A#0 +2(6개). 레버 캐리어와 패드 바는 예비 없이 필요할 때 위치별 파일로 뽑습니다.

**채움:** 표의 질량은 100 % 채움 기준입니다. 건반·레버·패드 바·가림판은 벽 3줄 + 채움 25~40 %면 충분합니다. 끝 부속 볼(cheek), 스피커 앞판, 스피커 통로 틀은 속이 꽉 찬 덩어리이므로 벽 3~4줄 + 채움 15~40 %로 뽑습니다(볼 하나에 약 200 g 절약). 보드 받침 기둥, 캡스턴 게이지(T2)·핀 게이지(T3)만 채움 100 %입니다.

**PORON 5T:** 업스톱 패드 설계값은 미세셀 우레탄 6T + 펠트 1T입니다(04 폴더의 패드 바 쐐기가 이 기준). 구매 목록(i124)은 PORON 5T이므로, 5T를 쓰면 `04b_패드바_PORON5T용` 파일(쐐기를 패드 면 법선으로 1.0 두껍게)을 뽑습니다. 6T를 사면 04 폴더 파일을 씁니다.

## 합판 재단 (오꾸메 11.5T, 출력하지 않음)

L2 합판 조각은 16개, 사각 재단 넓이 0.369 m²입니다 (L1 0.633 m²). 판매처 무료 재단은 사각 재단만 해 주므로 아래 크기로 받고, '직접 가공'만 톱·드릴로 합니다(톱날 3 mm는 판매처 재단에서 빠짐). 치수는 이 모델에서 잰 값이고, 사양 표와 다르면 괄호에 사양 값을 적었습니다.

**폭 4 mm 홈(뚜껑 L·R 배기 홈, 뒤판 환기 홈, 가운데 아랫판 흡기 홈, 모두 38개)은 직소 날(약 7 mm)이 들어가지 않습니다.** Ø4 구멍을 한 줄로 뚫어 잇고 줄로 다듬거나, 트리머에 4 mm 일자 비트를 씁니다. 홈 사이 나무는 4 mm입니다. **자석 자리 Ø8 × 3.2**(끝벽·뒤판 윗모서리 11.5 두께 가운데 → 벽 1.75)는 판을 붙이기 전에 자투리 판 두 장 사이에 물려 포스트너 비트로 뚫습니다.

| 조각 | 개수 | 사각 재단 (mm) | 직접 가공 |
|---|---|---|---|
| 스피커 옆판 (L 바깥/안, R 안/바깥) `PLY-POD-SIDE` | 4 | 128.5 × 139.65 | 사각으로 받은 뒤 직접 자름 (앞 모서리에서 뒤로 u, 아래 모서리에서 위로 v): ① 앞 아래 통로 홈 27 × 22 따냄 ② 앞 모서리는 v60.42까지 두고, 거기서 수평으로 4.25 들어간 점 (u4.25, v60.42)부터 윗변 u98.68까지 40° 사선 (사선 길이 123.26, 윗변에 남는 길이 29.82). 안쪽 옆판만: M4 나사산 인서트(L73) 구멍 Ø5.8 × 8 (가운데 쪽 면에서, 막힘 — 깊이 멈춤으로 8까지만: 판 11.5 중 지름 부분 밑 3.5, 드릴 끝 밑 1.5 이상 남아야 밀폐) L (u13, v40)·(u101, v38) / R (u13, v40)·(u101, v45), 스피커선 구멍 Ø6 관통 L (u29, v35) / R (u76, v35) |
| 스피커 뒤판 `PLY-POD-BACK` | 2 | 250 × 139.65 | 없음 (옆판 사이). 안쪽에 흡음솜을 두되 자석 뒤 폴 벤트 축 방향 10 mm는 비움 (W1) |
| 스피커 윗판 `PLY-POD-TOP` | 2 | 250 × 14.14 | 없음. 앞 모서리(y316.86)는 출력 앞판 윗마개에 맞댐 |
| 스피커 아랫판 `PLY-POD-BOTTOM` | 2 | 250 × 90 | 없음. 고무발 나사 자리 4 (8호 13 mm 이하): 바깥 끝에서 10.5·235.5, 앞 모서리에서 21·79 (발 Ø28이 옆판 밑까지 나옴; 사양 2.5는 나사가 끝면에 너무 가까워 옮김). 밀폐 상자 바닥이라 구멍에 MS 폴리머 한 방울 |
| 가운데 유닛 끝벽 L/R (ㄴ자) `PLY-CU-END` | 2 | 117 × 56.35 | ㄴ자: 앞 아래 통로 홈 27 × 22 따냄. 구멍 관통: XT30 선 Ø14 L (u29, v39) / R (u76, v44.5) (L은 XT30 집게 홈과 같은 축, R은 홈 축보다 1.5 아래 — 스피커 옆판 선 구멍보다 L 4 · R 9.5 위), 고무 슬리브 Ø8 ×2 L (u13, v40)·(u101, v38) / R (u13, v40)·(u101, v45); 윗모서리 자석 자리 Ø8 × 3.2 (u61, 두께 가운데 — 두 판을 붙이기 전에 포스트너 비트로) |
| 가운데 유닛 뒤판 `PLY-CU-BACK` | 1 | 702 × 56.35 | 뒤판 출력물 창: 왼쪽 끝에서 137.5~278 (폭 140.5), 아래 모서리에서 11.5 위부터 윗변까지 (위가 열림) — 톱으로 두 번 세로 자르고 가로로 따냄; 앰프 뒤 환기 홈 8개 4 × 15 (왼쪽 끝에서 485~545, 아래에서 37~52); 윗모서리 자석 자리 Ø8 × 3.2 4곳 (왼쪽 끝에서 30·120·473·675) |
| 가운데 유닛 아랫판 `PLY-CU-BOTTOM` | 1 | 679 × 90 | 앞 윗모서리 R3 (이음 기둥 자리 왼쪽 끝에서 228.5~240.5 · 438.5~450.5는 빼고); 흡기 홈 4 × 34: 강압 아래 6개 (왼쪽 끝에서 214.5~258.5, 앞 모서리에서 51~85), Pi 아래 8개 (274.5~350.5, 32~66); 고무발 나사 자리 6 (8호 13 mm): 왼쪽 끝에서 20.5·339.5·658.5, 앞 모서리에서 21·79 |
| 뚜껑 L `PLY-CU-LID-L` | 1 | 241 × 128.5 | 앞 윗모서리 1×45° 모따기 (건반과 사이의 틈이 그림자 선으로 보이게); 배기 홈 6개 30 × 4 (왼쪽 끝에서 199~229, 앞 모서리에서 70~114); 밑면 자석 자리 Ø8 × 3.2 3곳 (왼쪽 끝·앞 모서리에서 30/122.75 · 120/122.75 · 5.75/61) |
| 뚜껑 R `PLY-CU-LID-R` | 1 | 241 × 128.5 | 앞 윗모서리 1×45° 모따기 (건반과 사이의 틈이 그림자 선으로 보이게); 배기 홈 10개 4 × 40 (왼쪽 끝에서 23~99, 앞 모서리에서 74~114); 밑면 자석 자리 Ø8 × 3.2 3곳 (왼쪽 끝·앞 모서리에서 12/122.75 · 214/122.75 · 235.25/61) |

**400 × 1200 한 장 배치** (사양 plywood_cut_list, 톱날 3): 모델 크기로 다시 놓아도 들어감, 사용 1181.8 × 385 mm. 가게에 이 배치(왼쪽 위 기준 x, y)대로 잘라 달라고 합니다. 못 하면 600 × 1200을 그대로 삽니다(+22,520원).

| 조각 | x | y | 폭 × 높이 |
|---|---|---|---|
| `PLY-CU-BACK` | 0 | 0 | 702 × 56.4 |
| `PLY-CU-BOTTOM` | 0 | 59.4 | 679 × 90 |
| `PLY-POD-SIDE` | 705 | 0 | 128.5 × 139.7 |
| `PLY-POD-SIDE` | 836.5 | 0 | 128.5 × 139.7 |
| `PLY-POD-SIDE` | 968 | 0 | 128.5 × 139.7 |
| `PLY-CU-END` | 1099.5 | 0 | 56.4 × 117 |
| `PLY-POD-SIDE` | 0 | 152.4 | 128.5 × 139.7 |
| `PLY-POD-BACK` | 131.5 | 152.4 | 250 × 139.7 |
| `PLY-POD-BACK` | 384.5 | 152.4 | 250 × 139.7 |
| `PLY-CU-LID-L` | 637.5 | 152.4 | 241 × 128.5 |
| `PLY-CU-LID-R` | 881.5 | 152.4 | 241 × 128.5 |
| `PLY-CU-END` | 1125.5 | 152.4 | 56.4 × 117 |
| `PLY-POD-BOTTOM` | 0 | 295 | 250 × 90 |
| `PLY-POD-BOTTOM` | 253 | 295 | 250 × 90 |
| `PLY-POD-TOP` | 506 | 295 | 250 × 14.1 |
| `PLY-POD-TOP` | 506 | 312.1 | 250 × 14.1 |

| 부품 | 치수 (mm) | 위치 x / y / z |
|---|---|---|
| 스피커 파트 L 옆판(바깥쪽) | 139.65 × 128.5 × 11.5 | x-16.0~-4.5 / y214.0~342.5 / z5.0~144.7 |
| 스피커 파트 L 옆판(가운데 유닛 쪽) | 139.65 × 128.5 × 11.5 | x245.5~257.0 / y214.0~342.5 / z5.0~144.7 |
| 스피커 파트 L 뒤판 | 250 × 139.65 × 11.5 | x-4.5~245.5 / y331.0~342.5 / z5.0~144.7 |
| 스피커 파트 L 윗판 | 250 × 14.14 × 11.5 | x-4.5~245.5 / y316.9~331.0 / z133.2~144.7 |
| 스피커 파트 L 아랫판 | 250 × 90 × 11.5 | x-4.5~245.5 / y241.0~331.0 / z5.0~16.5 |
| 스피커 파트 R 옆판(바깥쪽) | 139.65 × 128.5 × 11.5 | x1226.5~1238.0 / y214.0~342.5 / z5.0~144.7 |
| 스피커 파트 R 옆판(가운데 유닛 쪽) | 139.65 × 128.5 × 11.5 | x965.0~976.5 / y214.0~342.5 / z5.0~144.7 |
| 스피커 파트 R 뒤판 | 250 × 139.65 × 11.5 | x976.5~1226.5 / y331.0~342.5 / z5.0~144.7 |
| 스피커 파트 R 윗판 | 250 × 14.14 × 11.5 | x976.5~1226.5 / y316.9~331.0 / z133.2~144.7 |
| 스피커 파트 R 아랫판 | 250 × 90 × 11.5 | x976.5~1226.5 / y241.0~331.0 / z5.0~16.5 |
| 가운데 유닛 아랫판 | 679 × 90 × 11.5 | x271.5~950.5 / y241.0~331.0 / z5.0~16.5 |
| 가운데 유닛 끝벽 L (ㄴ자) | 117 × 56.35 × 11.5 | x260.0~271.5 / y214.0~331.0 / z5.0~61.4 |
| 가운데 유닛 끝벽 R (ㄴ자) | 117 × 56.35 × 11.5 | x950.5~962.0 / y214.0~331.0 / z5.0~61.4 |
| 가운데 유닛 뒤판 | 702 × 56.35 × 11.5 | x260.0~962.0 / y331.0~342.5 / z5.0~61.4 |
| 가운데 유닛 뚜껑 L (오꾸메, 자석 3쌍) | 241 × 128.5 × 11.5 | x260.0~501.0 / y214.0~342.5 / z61.4~72.8 |
| 가운데 유닛 뚜껑 R (오꾸메, 자석 3쌍) | 241 × 128.5 × 11.5 | x721.0~962.0 / y214.0~342.5 / z61.4~72.8 |

고무발(화성고무 피스고무발 28×5, i039) 고정 나사는 직결피스 8호 **13 mm 이하**(L49의 13 mm 옵션)입니다. 발 5 + 합판 11.5 = 16.5라 25 mm는 상자 안으로 약 8 mm 뚫고 나옵니다. 13 mm면 발의 머리 자리가 2 mm일 때 끝이 합판 안면보다 1.5 안에 머뭅니다(받은 발의 머리 자리 깊이를 재 보고 확인). 스피커 아랫판은 밀폐 상자 바닥이라 나사 구멍마다 MS 폴리머를 한 방울 넣습니다. 스피커 바깥 발은 사양 x−2 / 1224 대신 x6 / 1216 (나사가 판 끝에서 10.5).

## 사양(body_L2.json)과 다르게 만든 곳 (작은 고침)

사양 수치가 실제 모양에서 맞지 않는 곳만 가장 작게 고쳤습니다. 부품 메모(manifest `note`)에도 같은 내용이 있습니다.

- **스피커 파트 L 옆판(가운데 유닛 쪽)** — 10/1 구매 목록 L73(Norelem 07653-04 나사산 인서트 M4, 겉 Ø6.5 × 길이 6)에 맞춤 - 인서트 구멍 y227 z45 · y315 z43 - Ø6.5 × 8 → Ø5.8 × 8 (이음면에서 막힘; 오꾸메 자투리에 Ø5.8로 먼저 시험 - 헐거우면 Ø5.5); 제조사 최소 구멍 깊이 8 충족; 밀폐 규칙: 옆판 11.5에서 지름 부분 바닥 밑 3.5, 드릴 끝(118° 원뿔 1.8 / 목공 뿔 비트 촉 약 2, 2.0로 잡음) 밑 1.5 ≥ 1.5 남음 - 깊이 멈춤(테이프 표시 8 mm)으로 뚫음; 스피커선 구멍 Ø6 y243 z40 (선을 넣고 본드로 밀봉, EVA 띠 사이)
- **스피커 파트 R 옆판(가운데 유닛 쪽)** — 10/1 구매 목록 L73(Norelem 07653-04 나사산 인서트 M4, 겉 Ø6.5 × 길이 6)에 맞춤 - 인서트 구멍 y227 z45 · y315 z50 - Ø6.5 × 8 → Ø5.8 × 8 (이음면에서 막힘; 오꾸메 자투리에 Ø5.8로 먼저 시험 - 헐거우면 Ø5.5); 제조사 최소 구멍 깊이 8 충족; 밀폐 규칙: 옆판 11.5에서 지름 부분 바닥 밑 3.5, 드릴 끝(118° 원뿔 1.8 / 목공 뿔 비트 촉 약 2, 2.0로 잡음) 밑 1.5 ≥ 1.5 남음 - 깊이 멈춤(테이프 표시 8 mm)으로 뚫음; 스피커선 구멍 Ø6 y290 z40 (선을 넣고 본드로 밀봉, EVA 띠 사이)
- **스피커 육각 그릴** — 위 링 벽 s53~57 (w0~11)은 L1 그릴에서 그대로 둠 → 출력 150 × 107 × 13 (사양 print_size 103.27는 판 s-50~+53.27만) - 링 윗변이 앞판 면에 닿아 그릴이 떨리지 않음, 105 프레임과 0.5, 윗면 z144.65 아래
- **스피커 통로 틀** — 사양 yz_polygon의 꼭짓점 순서가 241/247을 바꿔 적어 스스로 꼬이고(자기 교차) 지붕 끝 y241~247 z27~33 (6×6)이 비어 상자가 새게 됨 → 설명대로 '지붕 y214~247 + 세움벽 y241~247'로 만듦: (214.00,27.00) (241.00,27.00) (241.00,16.50) (247.00,16.50) (247.00,33.00) (220.00,33.00) (220.00,57.42) (225.00,57.42) (225.00,65.42) (214.00,65.42) (바깥 치수·안 부피 단면 8636 mm²는 그대로)
- **통로 옆 마개 L** — 따낸 자리 y214~237 × z7~15 → y214.0~223.3 × z1~19 (아래가 열림) - 사양대로면 마개의 z7 아래 띠가 브래킷 판 밑에 걸려 스피커를 핀에서 곧게 들어 올릴 수 없음; 브래킷 팔은 핀 쪽 x≥-1.2에만 있어 마개(x-16~-13)와 겹치는 것은 세움 다리(y212.5~218, z8~18)·그로밋 뒤 플랜지·볼트 머리(y≤222.25)뿐, 1 mm 여유; 옆에서 보이는 틈은 다리 앞뒤 작은 자리뿐
- **통로 옆 마개 R** — 따낸 자리 y214~237 × z7~15 → y214.0~223.3 × z1~19 (아래가 열림) - 사양대로면 마개의 z7 아래 띠가 브래킷 판 밑에 걸려 스피커를 핀에서 곧게 들어 올릴 수 없음; 브래킷 팔은 핀 쪽 x≥-1.2에만 있어 마개(x1235~1238)와 겹치는 것은 세움 다리(y212.5~218, z8~18)·그로밋 뒤 플랜지·볼트 머리(y≤222.25)뿐, 1 mm 여유; 옆에서 보이는 틈은 다리 앞뒤 작은 자리뿐
- **스피커 핀 소켓 블록 L** — 핀·소켓 x를 사양 x0.5 → x2.5로 2 mm 안쪽 (브래킷 참고)
- **스피커 핀 소켓 블록 R** — 핀·소켓 x를 사양 x1221.5 → x1219.5로 2 mm 안쪽 (브래킷 참고); R 블록 길이 11 → 15 - 사양 11 블록에 긴 구멍 11이면 양끝 벽이 0이 됨 (구멍 양옆 벽 2.50 / 1.50)
- **방진 브래킷 L** — 핀 x0.5 → x2.5 - 사양 자리면 핀 판(팔)이 안쪽 그로밋 M3 볼트의 머리(Ø5.7, x-7.73~-2.03)와 렌치 길을 막아 볼트를 넣고 조일 수 없음; 팔을 볼트 머리 길에서 0.8 띄우고 핀을 2 mm 안쪽으로(핀 사이 1217, R 긴 소켓 공차 그대로), 소켓도 같이 옮김
- **방진 브래킷 R** — 핀 x1221.5 → x1219.5 - 사양 자리면 핀 판(팔)이 안쪽 그로밋 M3 볼트의 머리(Ø5.7, x1224.03~1229.73)와 렌치 길을 막아 볼트를 넣고 조일 수 없음; 팔을 볼트 머리 길에서 0.8 띄우고 핀을 2 mm 안쪽으로(핀 사이 1217, R 긴 소켓 공차 그대로), 소켓도 같이 옮김
- **EVA 3T 띠** — 위 띠의 앞 위 모서리를 옆판 모양(40° 경사)으로 잘라 옆판 밖 공중에 뜨지 않게 함 (y216~224 z65~70)
- **피스고무발 28×5** — 바깥 발 x-2 → x6 - 사양 자리면 8호 나사 축이 스피커 아랫판 끝(x-4.5)에서 2.5라 나사(Ø4.2)와 끝면 사이 나무가 0.4만 남아 쪼개지거나 옆판 접착면으로 샘; 옮기면 10.5 (뒤 모서리 y331에서 69과 비슷), Ø28 발은 아직 바깥 옆판 밑까지 닿음
- **피스고무발 28×5** — 바깥 발 x-2 → x6 - 사양 자리면 8호 나사 축이 스피커 아랫판 끝(x-4.5)에서 2.5라 나사(Ø4.2)와 끝면 사이 나무가 0.4만 남아 쪼개지거나 옆판 접착면으로 샘; 옮기면 10.5 (뒤 모서리 y331에서 11과 비슷), Ø28 발은 아직 바깥 옆판 밑까지 닿음
- **피스고무발 28×5** — 바깥 발 x1224 → x1216 - 사양 자리면 8호 나사 축이 스피커 아랫판 끝(x1226.5)에서 2.5라 나사(Ø4.2)와 끝면 사이 나무가 0.4만 남아 쪼개지거나 옆판 접착면으로 샘; 옮기면 10.5 (뒤 모서리 y331에서 69과 비슷), Ø28 발은 아직 바깥 옆판 밑까지 닿음
- **피스고무발 28×5** — 바깥 발 x1224 → x1216 - 사양 자리면 8호 나사 축이 스피커 아랫판 끝(x1226.5)에서 2.5라 나사(Ø4.2)와 끝면 사이 나무가 0.4만 남아 쪼개지거나 옆판 접착면으로 샘; 옮기면 10.5 (뒤 모서리 y331에서 11과 비슷), Ø28 발은 아직 바깥 옆판 밑까지 닿음
- **가운데 유닛 끝벽 L** — XT30 구멍 Ø14 중심 y243 z40 → y243 z44.0 - 스피커 옆판 선 구멍(z40)과 곧게 건너는 사양 자리에서는 끝벽 집게 홈의 XT30U-F가 구멍으로 빠지지 않아(L: 모서리 반지름 8.3 > 7) 스피커를 뗄 수 없음 → 구멍을 집게 홈과 같은 축으로 올림 (F 모서리 반지름 5.72 < 7, 곧게 밀려 나감); 꼬리선은 틈에서 4.0 올라감
- **가운데 유닛 끝벽 R** — XT30 구멍 Ø14 중심 y290 z40 → y290 z49.5 - 스피커 옆판 선 구멍(z40)과 곧게 건너는 사양 자리에서는 끝벽 집게 홈의 XT30U-F가 구멍으로 빠지지 않아(R: 홈 축 z51가 구멍 z40 위로 11 - 홈이 구멍 밖) 스피커를 뗄 수 없음 → 구멍을 집게 홈 축보다 1.5 아래까지 올림 (옆판 구멍에서 오는 꼬리가 구멍 안에 남게) (F 모서리 반지름 5.72 < 7, 곧게 밀려 나감); 꼬리선은 틈에서 9.5 올라감
- **CU 화면 뚜껑** — ① x501~721 → x501.5~720.5 (이음마다 0.5 틈) - 사양대로면 오꾸메 뚜껑 L·R(재단 ±0.5)과 출력 뚜껑이 틈 0으로 맞닿아 조금만 커도 세 장이 나란히 들어가지 않음; ② 뒤끝 y342.5 (사양 자리 블록 y341.5는 43° 뒤판 - 40°에서 뒤판이 1.0 뒤로 감; 화면 쪽 값은 모두 사양 그대로, 접은 받침 뒤끝 y339.05와 뒤끝 사이 3.45); ③ 나사 자리는 CAD L2 보스 10 × 12 (사양 A-7의 Ø8 기둥을 덮음), 구멍 Ø3.4 + 위에서 Ø6.5 × 5.5 자리파기 (머리 자리 z67.35, 머리 밑 살 6.0); ④ 배기 홈 밑의 갈비 x571·x651은 그대로 둠 (홈 34 중 2 mm만 가림, 출력 때 갈비가 판을 받침); ⑤ 출력 방향이 자리만 잡은 판(윗면을 베드에)과 반대 - 경첩 볼·발이 윗면에 있어 사양 A-9대로 갈비 면(z61.35)을 베드에. 갈비 규칙(사양 A 머리말): 갈비 x531/571/611/651/691 · y254/290 (두께 2, z61.35~69.85)는 아래 덩어리와 만나는 곳에서 그 덩어리에 합침 - 경첩 받침 밑 채움 x538.6~559.0 · 663.0~683.4 y217.55~235.55, 구멍 벽 x633.35~659.35 y226.55~236.55, 클립 덩어리 x631.35~661.35 y236.55~248.55, 주머니 덩어리 x601~621 y287.43~303.70 (모두 z61.35까지 채움); x651 갈비는 구멍을 지나므로 구멍 둘레 벽 앞(y226.55)과 뒤(y236.55)에서 끊김. 클립 핀 자리(x634.35 y242.55 · x658.35 y242.55)와 접이 발 자리(윗면)는 갈비와 겹치지 않음. 경첩 받침 2개(뚜껑과 한 몸): 왼쪽 가까운 볼 x538.6~542.6 (Ø3.3 관통) · 귀 홈 x542.6~551.0 · 먼 볼 x551.0~559.0 (Ø2.5 관통 = M3×20 직접 탭 7.6), 오른쪽 먼 볼 x663.0~671.0 · 귀 홈 x671.0~679.4 · 가까운 볼 x679.4~683.4, 볼 옆모양 축 (y226.55, z81.35) R5.5 + 사다리꼴 z72.85에서 y217.55~235.55; 뒤꿈치 멈춤 블록 귀 홈 x · y217.55~224.55 · z72.85~76.35; 리본·전원선 구멍 x635.35~657.35 y228.55~234.55 관통, 위아래 모서리 R1, 둘레 벽 2; 다리 주머니 x604~618: 30° 경사 (y290.43, z72.85) → (y296.49, z69.35), 바닥 z69.35, 뒷벽 y300.7 (위 모서리 C0.5); 접이 받침 발 16 × 16 × 5.5 (z72.85~78.35) x535~551 · 671~687, y255.55~271.55 · 305.55~321.55, 뒤 발 뒤 턱 y322.05~324.05 z72.85~80.35 (발과 틈 0.5); 리본 클립 핀 구멍 Ø3.1 × 5 밑에서 ((634.35, 242.55) · (658.35, 242.55)); 배기 홈 x564~598 y300~304 · x624~658 y300~304 … y321~325; 자석 없음 (D14)
- **뚜껑 이음 레일 + 기둥 1** — 기둥 x496~506 → x501~511 - 화면 뚜껑 나사(x506 = 뚜껑이 레일에 얹힌 10 mm의 가운데)가 사양 기둥(이음선 x501 가운데)의 모서리에 걸려 '기둥 위 인서트'가 안 됨
- **뚜껑 이음 레일 + 기둥 2** — 기둥 x716~726 → x711~721 - 화면 뚜껑 나사(x716 = 뚜껑이 레일에 얹힌 10 mm의 가운데)가 사양 기둥(이음선 x721 가운데)의 모서리에 걸려 '기둥 위 인서트'가 안 됨
- **뒤판 출력물** — 판에 얹히는 HUSB238·J501 기판·J501·KCD1 자리와 판 주머니·잭 받침을 사양 상자보다 y+1.0 (뒤판이 40° 규칙으로 y341.5 → 342.5로 옮겨 감; 사양 그대로면 USB-C 입구 앞을 판 1.0 mm가 막음)
- **XT30 짝 집게 L** — 끝벽에 붙는 판의 구멍 Ø14와 끝벽 구멍을 y243 z44.0로 (사양은 스피커 옆판 선 구멍 z40과 곧게) - 홈의 XT30U-F(모서리 반지름 5.72 < 7)가 홈에서 끝벽 쪽으로 곧게 밀려 판 3 + 끝벽 11.5 터널로 들어가고 스피커 쪽으로 빠짐 (L은 사양 자리에서 모서리가 판·끝벽에 걸려 빠지지 않았음); 판 위끝을 z54까지 올려 구멍 위 3을 남김
- **XT30 짝 집게 R** — 끝벽에 붙는 판의 구멍 Ø14와 끝벽 구멍을 y290 z49.5로 (사양은 스피커 옆판 선 구멍 z40과 곧게) - 홈의 XT30U-F(모서리 반지름 6.54 < 7)가 홈에서 끝벽 쪽으로 곧게 밀려 판 3 + 끝벽 11.5 터널로 들어가고 스피커 쪽으로 빠짐 (L은 사양 자리에서 모서리가 판·끝벽에 걸려 빠지지 않았음); R 선 홈은 없앰(꼬리가 구멍으로 곧게 감)
- **퓨즈 홀더 받침** — 안지름 10.5 → 10.3, 타이 홈 2 없앰 - 사양대로면 받침 밑 바닥이 0.75이고 타이 홈(2.1)이 그 바닥을 칼날처럼 뚫음; Ø10.3이면 바닥 0.85, 홀더는 눌러 끼움 + MS 폴리머 한 점으로 충분
- **USB-C 케이블 W201 · USB-C 케이블 W202 · USB-C 케이블 W203 외 2** — 사양 선 '플러그 → R15 → y236.8·z13 줄 → 포트 x에서 올라감'은 나란히 달리는 선이 모두 한 자리에 겹침 → 묶음 y237.5 4층(z2.25·6.25·10.25·14.25, 0.5 틈), 굽힘은 통로 깊이 때문에 플러그 뒤 R8, 허브 쪽 R9.5 이하
- **USB-C 케이블 W205 · USB-C 케이블 W206** — 사양 선 'y236.8·z13 줄'이 아니라 묶음 위 앞쪽 줄 - 묶음에 넣으면 포트에서 위로 빠질 때 O5가 O2·O4 밑이어야 해서 5층이 필요한데 5층째(z18.25)는 J702·동글 3.5 mm 플러그 자리(z17~) 밑에 들어가지 않음; 짧은 선 O5·O6만 따로
- **페달 잭 기판 · 페달 잭 PJ-313 · KCD1-101A 로커 스위치 외 1** — 사양 centre_contents 상자보다 y+1.0 - 뒤판 출력물이 40° 규칙으로 바깥면 y341.5 → 342.5로 옮겨 가 판에 얹힌 부품도 같이 감 (body.py DY_BACK; 그대로 두면 USB-C 입구 앞을 판이 막음)
- **USB-C 케이블 W208** — 사양 Z-PED-PLUG z22~30은 리셉터클 축 z26 가정 - 사양 PEDZERO 상자 z23.1~28.8의 Zero는 축 z27.0이라 플러그 z23.2~30.8, 위로 0.8 나옴 (위는 비어 있음, PED 줄은 z33부터)
- **USB-C 케이블 W208** — 플러그 + 부트 25 mm 뒤의 굽힘이 y215.75까지 나옴 - 사양 Z-PED-PLUG·Z-PED-LANE 앞끝 y222보다 6.25 앞 (x443~472 z23~36, 그 자리 앞 공간은 비어 있고 뒷바 앞면 y214 안; USB 선을 그보다 좁게 굽힐 수 없음)
- **USB 허브 업스트림 선 C25** — 10/1 구매 목록 C25에 맞춤 - 사양 Z-UP-PLUG(위 포트, 곧은 A) · Z-UP-BEND(S자) · Z-HUB-UP(허브 -x 끝면 위로 꺾인 플러그) 대신 A 쪽이 위로 꺾이고 B가 곧은 C25로 - (1) A 머리는 Pi GPIO 쪽 USB-A 2단의 아래 포트(축 y309 z28.1)에: 위로 꺾인 머리가 포트 축에서 20.5 올라가 위 포트(z36.5)에 꽂으면 끝이 z57.0, 뚜껑 밑(z61.35)까지 4.35라 선을 꺾을 수 없음 → 아래 포트면 끝 z48.6, 위 포트는 머리에 가려 비움; (2) 선은 위로 나와 R7로 +x, z56.5(위 화면 전원선 TS-C-PWR z59.6 밑)에서 허브 선반 위로 가 x706.8에서 R8 U자로 돌아와 x656.5에서 R6로 내려가 (3) 허브 -x 끝면의 업스트림 B 포트(y319 z28.5)에 곧은 B 플러그(몸 20 + 부트 10, x656.5~686.5)로 들어감
- **NEXTU 710U3 10포트 유전원 USB 허브** — W1 10/1 제품 사진대로 업스트림 USB 3.0 B 포트와 5 V DC 잭이 같은 끝면 → 둘 다 -x 끝면(x686.5, Pi·강압 쪽)에 둠 (사양 cable_duct.hub: 업스트림 -x 끝면 ㄱ자 플러그 · DC +x 끝면 추정) - Pi 업스트림(C25)과 5.1 V 선이 가장 짧고, 허브는 그대로 바닥에 뒤판에 붙여 모듈 선은 -y 면으로
- **5.1 V 선 강압 → Pi 5** — W1 10/1 - 허브 DC를 +x 끝면(Z-HUB-DC)에서 업스트림 B 포트와 같은 -x 끝면으로 옮겨 선반 앞 줄(Z-PWR-LANE)을 쓰지 않음

그 밖에 사양 수치를 조금 바꾸거나 채운 곳 (부품 메모에는 '추정'으로 적힘):

- **방진 브래킷 BRK2** — 그로밋이 끼는 세움 다리는 z8~18 (사양은 판 z8~14만 적음): 6 mm 판에는 Ø6 그로밋(중심 z12, 자리 Ø6.5)이 들어가지 않음. 핀을 받치는 판(팔)은 z8~14 그대로
- **고무 슬리브** — 끝벽만 지나감 (길이 13, 가운데 쪽으로 1.5 나옴) — 사양처럼 3 mm 틈까지 건너면 스피커를 들 때 아래 EVA 띠가 걸림. EVA 띠 구멍 Ø10은 나사가 실제로 띠를 지나는 곳에만
- **가운데 아랫판** — 강압 아래 흡기 홈 x486~530 (사양 x482~534): 강압 받침 기둥 Ø7 자리를 피함. 이음 기둥 자리(x500~512, 710~722)는 앞 모서리 R3 없음
- **뒤판 출력물** — 루버 x480~534 (사양 ~536): 옆 테 2 mm를 남김
- **보드 받침** — 사양 STANDOFFS(90 × 60 받침 판) 대신 낱개 기둥 14개 (보드에 먼저 나사, 기둥 밑을 아랫판에 MS 폴리머) — 흡기 홈을 막지 않음. 앰프 2 mm 받침 4개는 허브 선반과 한 몸
- **XT30 집게** — 사양 24 × 14 × 10보다 큼 (L 26 × 19 × 15.5 / R 20 × 19 × 15.5, 베드 위) — 끝벽 Ø14 구멍 둘레에 붙일 면이 필요
- **CU 화면 뚜껑** — 터치스크린 3판(A장)을 더함: 리본·전원선 구멍 22 × 6 (x635.35~657.35 y228.55~234.55, 사양 dsi 권장 자리 x580~602 대신 - 화면 커넥터가 +x 쪽), 배기 홈 8 × (34 × 4) y300~325 (centre.vents.exhaust의 4 × 34 y292~326 대신 W1 3판 값), 갈비는 덩어리에 합침 (부록 A10)
- **스피커 앞판·그릴** — 유닛 나사 인서트는 구매 목록 L69 (ShenzenAV M4x4x6: 바깥 Ø6 × 길이 4)를 구멍 Ø5.6 × 6.5에 인두로 면까지 (지름 0.4 물림, 모델에 있음). M4×12(L70)는 플랜지 4 + 가스켓 3을 지나 5 들어가 인서트를 지나 1 더, 끝은 구멍 바닥 1.5 위. 그릴 판 아래 끝과 잘린 윗끝에 막힌 띠 2 mm, 가장자리 칸은 Ø3 원이 들어가는 것만 뚫음 (W1 조건)
- **케이블 집게 (사양 CABLE-CLIPS 8)** — 사양에 자리가 없어 정함: 스피커 통로 지붕 밑 3개씩 (z19~27 y226~236, 묶음 위라 모델에서는 비어 있음) + 끝벽 L 안면 2개 (스피커선 C-SPK-L을 잡음, 선을 x275.1로 옮김). 출력 파일 하나 `케이블집게__8개`
- **허브 선반 받침 나사** — 8호 13 mm 대신 Ø3 × 12~13 둥근머리 목재 나사 (머리 Ø6 이하) — 사양 받침 10 × 8에는 8호(Ø4.2, 머리 Ø8)가 들어가지 않음. 머리 자리 눈물방울 꼭지를 받침 윗면 0.8 아래에서 자름. 나사 축 z46의 머리(아래 끝 z43)가 선반 윗면 z43.5보다 낮아, 받침 앞 선반 윗면에 머리·드라이버 길 홈 7 × 0.8 (선반 앞끝 y282 → 받침 y322, 바닥 1.2 남음)
- **보드 받침 기둥 (5 mm)** — 나사 구멍 깊이 4.5 → 4.0 (바닥 1.0), 나사 길이 M3×5 (Pi M2.5×6) — 6 mm 이상은 바닥을 뚫고 붙인 기둥을 밀어 올림
- **뒤판 출력물 바닥 탭** — 왼쪽 나사 (407, 325) → (407, 322) (가운데 아랫판 뒤 모서리 y331에서 9), 탭을 y316까지 앞으로. 오른쪽 나사 (463, 325) → (466, 311.5): J501 받침(같은 출력물, z30~36.4)이 오른쪽 탭 전체를 덮어 머리 위로 9.5만 비어 드라이버가 닿지 않았음 → 탭에서 앞으로 낸 혀 x459.5~472.5 y304~316에 나사를 둠 (드라이버 Ø6 길이 받침·J501 기판 앞 1.0, 퓨즈 받침과 6.5; 받침에 구멍을 뚫으면 받침 앞끝이 2 mm만 남고 붙인 J501 기판 밑이 되어 뺄 수 없음). J501 받침 밑 삼각 받침 2개 → 바깥 판에서 곧게 오른 받침벽 2개 (x452~454/472~474, 탭에 이음; 출력 때 공중에 뜨지 않음)
- **합판 환기 홈** — 뚜껑 L 홈 6개 y284~328, 뒤판 앰프 뒤 홈 8개 x745~805 — 간격 6.5 → 8 (홈 사이 나무 2.5 → 4)
- **전자부 단자 자리 (가정)** — 강압 입력 −x 끝(y306)·출력 앞면(x529.5); 앰프 전원 y313·스피커 L y318(−x 끝), 스피커 R y293(+x 끝); 허브는 W1 10/1 제품 사진대로 업스트림 USB 3.0 B 포트(y319)와 DC 잭(y293, ㄱ자 플러그)이 같은 −x 끝면 (사양: 업스트림 −x · DC +x). 끝면 안 자리는 받은 허브로 확인
- **스피커 꼬리선** — 스피커 밖 54 mm (꼬리 150 중): 여유 약 35 mm를 끝벽 Ø14 터널 안에 1.5바퀴 느슨하게 감아 둠 — 스피커를 10 mm 들고 15 mm 바깥으로 밀어도 XT30U-F가 집게에 남고, 그다음 F를 터널로 빼냄 (check_body.py가 확인). 두 가닥을 Ø2 한 줄로 표시
- **홀 센서 높이 (D14)** — D14 거리를 사양의 z8이 아니라 홀 소자 높이 z12.9 (포켓 바닥 12.19 + 0.75)까지 잼 → 사양 229.6 / 161.5보다 1~2 mm 짧음 (≥100은 그대로)
- **XT30U-M 수 꼬리** — 사양 C-XT30 상자보다 0.1 나옴 (집게 홈 + 밖에 보이는 8.1)

## 문서에 치수가 없어 정한 값 (추정)

- **스피커 앞판(배플, 40° 경사) L** — M4 열압입 인서트 구멍 Ø5.6 × 6.5 (그대로) - 구매 목록 L69 (ShenzenAV M4x4x6: 바깥 Ø6 × 길이 4)를 인두로 면까지 (지름 0.4 물림, 보통 범위), 유닛은 M4×12(L70)로 플랜지 4 + 가스켓 3을 지나 앞판에 5 들어감 → 인서트 4를 다 물고 1 더 나감, 끝은 구멍 바닥 1.5 위 (구멍 안); 8.1 긴 인서트는 아래 구멍이 밑면 z65.42에 너무 가까움; 아래 인서트 구멍 바닥과 상자 안 사이 2.78 - 인서트를 더 밀어 넣거나 M4×12보다 긴 나사를 쓰면 밀폐가 뚫림), 그릴 파일럿 Ø3.4 × 9 (x ±64, 경사 ±40 = 그릴 옆벽 가운데, 8호 19 mm 이하 - 아래 파일럿 끝과 상자 안 사이 2.15); 선 구멍은 L2에서 앞판이 아닌 안쪽 옆판에 있음
- **M4 열압입 인서트 L69** — 바깥 Ø6 × 길이 4를 앞판의 구멍 Ø5.6 × 6.5에 인두로 면까지 넣음 (지름 0.4 물림 - 모델은 겹침으로 보여 줌, 더 밀어 넣지 않음), 나사산 안지름 Ø3.3로 모델; M4×12(L70, 모델에 없음)는 유닛 플랜지 4 + EVA 가스켓 3을 지나 5 들어가 인서트 4를 지나 1 더 나감 - 끝은 구멍 바닥 1.5 위라 구멍 안 (가스켓 3이 약 2로 눌리면 약 6 들어가 바닥까지 약 0.5 - M4×12 이하만 씀; M4×14면 7 들어가 구멍 깊이 6.5를 넘어 밀폐면 2.78을 뚫음)
- **스피커 육각 그릴** — 판 아래 끝과 잘린 윗끝에 막힌 띠 2 mm (격자 s-48.00~51.27) - 아래 띠는 27° 선이 판을 지나는 가장 낮은 곳이라 유닛 콘 맨 아래 약 1 mm가 27°에서 가려짐 (W1이 승인한 판 예외 - 43°에서 0.94, 40°에서 선이 판 아래 모서리 밑 1.54 - 는 판이 격자라는 전제, 음향 영향은 작음), 가장자리 칸은 Ø3 원이 들어가는 것만 뚫음 → 구멍 95개, 개구율 70.4 % (격자 106 × 99.3) · Ø94 앞 72.0 % (W1 ≥40 %); 그릴 고정 4-Ø4.5 (x ±64, 경사 ±40), 8호 19 mm → 앞판 파일럿 물림 6 (25 mm는 파일럿 끝 2.15 아래 밀폐면을 뚫음 - 19 mm 이하); 링 안쪽 106 = 유닛 프레임 105 + 0.5씩
- **유닛 EVA 가스켓 3T L** — 안쪽 Ø94·바깥 105×105, 나사 자리 4-Ø4.8 PCD115 - EVA 3T 자투리를 칼로 재단, 앞판 바깥면 위(법선 0~3)
- **통로 옆 마개 L** — 마개 z1~27 (책상 위 1), 옆판 홈의 뒷면(y241)·윗면(z27)에 MS 폴리머로 붙임
- **스피커 핀 소켓 블록 L** — 블록 x-3.0~8.0 × 12 × 10을 통로 지붕 밑면 z27에 MS 폴리머로 붙임 (옆판 안면 안), 구멍 윗끝 z26 = 핀 끝 z24 + 2 (같은 부품 2개, 자리만 다름 — 첫 번째 값)
- **방진 브래킷 L** — 세움 다리 x-15.5~6.5 y212.5~218 z8~18 (L1 그로밋 자리: 웹 1.6에 허리 구멍 Ø4.2, 플랜지 자리 Ø6.5 - x-11.80 -x, x-11.80↔x-4.88 이어짐), 팔 x-1.2~6.5 y218~236.5 z8~14 + 45° 받침, 핀 Ø6 z14~24; 다리 밑 z8은 헤드폰 선(z3~7.5) 위 0.5, EL 리드 노치 x13.5와 7.0 떨어짐
- **실리콘 방진 그로밋 M3** — 플랜지 Ø6 × 3.5 + 허리 Ø4 × 1.6 + 플랜지 Ø6 × 3.5 = 길이 8.6, 구멍 Ø3.2; 앞 플랜지가 볼 뒷면 y212에 닿음 (L1 그대로)
- **M3×16 둥근머리 볼트 ISO 7380** — 머리 Ø5.7 × 1.65 (ISO 7380), 육각 렌치 2 mm는 뒤(+y)에서 - 스피커를 올리기 전에 조임
- **M3 육각 너트** — 볼 너트 홈 천장 z15.2 (볼트 축 z12 + 꼭짓점 3.175) - L1 그대로
- **방진 브래킷 R** — 세움 다리 x1215.5~1237.5 y212.5~218 z8~18 (L1 그로밋 자리: 웹 1.6에 허리 구멍 Ø4.2, 플랜지 자리 Ø6.5 - x1233.80 +x, x1233.80↔x1226.88 이어짐), 팔 x1215.5~1223.2 y218~236.5 z8~14 + 45° 받침, 핀 Ø6 z14~24; 다리 밑 z8은 헤드폰 선(z3~7.5) 위 0.5, ER 리드 노치 x1212.5와 3.0 떨어짐
- **EVA 3T 띠** — 스피커 안쪽 옆판 바깥면에 붙임
- **M4×20 손잡이볼트 L72** — 머리 자리 Ø10 × 6.5 (L72 머리 Ø8 × 6이 그 안, 사양 자리 Z-TS 10 × 10 × 10 안), 몸통 M4 × 20 (슬리브 끝 → 이음면 16, L73 인서트(길이 6)에 4.0 물림; M4×22면 6.0 물림, 끝이 구멍 바닥 2.0 위; 길이 24면 끝이 구멍 바닥(지름 부분 8 깊이)에 닿고 그보다 길면 밑 3.5 mm 밀폐 판을 누름 → 최대 M4×22), 머리는 고무 슬리브 끝에만 닿음 (D15: 나무·출력물에 쇠가 닿지 않음)
- **고무 슬리브 OD8 ID4.2** — 고무 호스 OD8 ID4.2를 13.0 길이로 잘라 끝벽 Ø8 구멍에 끼움 (바깥면과 같은 높이) - 가운데 쪽으로 1.5 나와 나사 머리를 받음; 틈 3은 건너지 않음 (나사를 빼면 EVA 띠가 슬리브에 걸리지 않고 스피커가 곧게 들림), 나사 몸통 Ø4는 EVA 띠 Ø10 구멍을 지남
- **피스고무발 28×5** — 머리 자리 Ø9 깊이 2로 표시, 8호 13 mm 이하로 아랫판(11.5)에 고정 - 끝이 z15.0, 판 윗면보다 1.5 아래. 스피커 아랫판은 밀폐 상자 바닥이므로 나사 구멍에 MS 폴리머를 한 방울 넣고 조임 (16 mm 이상이면 상자 안으로 뚫림)
- **피스고무발 28×5** — 머리 자리 Ø9 깊이 2로 표시, 8호 13 mm 이하로 아랫판(11.5)에 고정 - 끝이 z15.0, 판 윗면보다 1.5 아래.
- **가운데 유닛 아랫판** — 흡기 홈 4×34 강압 아래 x486~530 (사양 x482~534에서 보드 기둥 Ø7 자리를 피해 양끝 4 mm씩 안쪽) y292~326 6개, Pi 아래 x546~622 y273~307 8개 (합 1904 mm²); 앞 윗모서리 R3은 뚜껑 이음 기둥 자리(x500~512, 710~722)만 빼고 (케이블이 넘어가는 곳)
- **가운데 유닛 끝벽 L** — 자석 자리 Ø8 × 3.2 윗모서리 (x265.75 y275) (같은 부품 2개, 자리만 다름 — 첫 번째 값)
- **가운데 유닛 뒤판** — 환기 홈 8개 4×15 x745~805.0 z42~57 (간격 8, 홈 사이 나무 4; 앰프 x742~796 뒤, 윗모서리까지 4.35 남김), 자석 자리 Ø8 × 3.2 윗모서리 x290/380/733/935 (L은 창 왼쪽)
- **가운데 유닛 뚜껑 L** — 배기 홈 6 × (4×30) x459~489 y284~328, 간격 8 (홈 사이 나무 4 - 2.5면 오꾸메가 부러짐; 강압 쪽; 레일 x491~511 위는 피함), 자석 자리 Ø8 × 3.2 밑면 (x290.00 y336.75 · x380.00 y336.75 · x265.75 y275.00)
- **네오디뮴 자석 Ø8×3 N35** — 합판 윗모서리 Ø8 × 3.2 자리 바닥에 순간접착제, 윗면이 합판 윗면보다 0.2 아래
- **네오디뮴 자석 Ø8×3 N35** — 뚜껑 밑면 Ø8 × 3.2 자리에 순간접착제 (0.2 들어감) → 짝 자석과 틈 0.4, 극은 서로 당기게
- **가운데 유닛 뚜껑 R** — 배기 홈 10 × (4×40) x744~820 y288~328 (앰프·허브 위), 자석 자리 Ø8 × 3.2 밑면 (x733.00 y336.75 · x935.00 y336.75 · x956.25 y275.00)
- **뚜껑 이음 레일 + 기둥 1** — M3 열압입 인서트 L71 (바깥 Ø4.5 × 4, 구멍 Ø4 × 4.5) 레일 윗면 y246·y322; 레일 뒤 끝면은 PR-BACKPLATE 안면(y331)에 MS 폴리머, 기둥 밑은 아랫판에 MS 폴리머 (기둥 자리는 아랫판 R3 모서리 없음); 레일은 뒤판까지 y214~331 (사양 상자 y214~330는 43° 뒤판 기준, 뒤판이 1.0 뒤로 감)
- **뚜껑 이음 레일 + 기둥 2** — M3 열압입 인서트 L71 (바깥 Ø4.5 × 4, 구멍 Ø4 × 4.5) 레일 윗면 y246·y322; 레일 뒤 끝면은 뒤판 안면(y331)에 MS 폴리머, 기둥 밑은 아랫판에 MS 폴리머 (기둥 자리는 아랫판 R3 모서리 없음); 레일은 뒤판까지 y214~331 (사양 상자 y214~330는 43° 뒤판 기준, 뒤판이 1.0 뒤로 감)
- **M3 열압입 인서트 L71** — 바깥 Ø4.5 × 높이 4를 레일 구멍 Ø4.0 × 4.5에 인두로 면까지 (지름 0.5 물림 - 모델은 겹침으로 보여 줌; 레일을 붙이기 전에 넣음), 나사산 안지름 Ø2.6로 모델 (나사 Ø3과 겹침 = 나사산 물림); 6개 사서 4개 쓰고 2개 예비
- **M3×10 둥근머리 렌치볼트** — 머리 Ø5.7 × 1.65 (ISO 7380), 자리파기 바닥 z67.35, 몸통 z57.35~67.35 → 인서트에 4.0 물림
- **M2.5×6 둥근머리 나사** — 머리 Ø4.5 × 1.8; 몸통 w5~11 → 화면 구멍(w8부터)에 3 물림; 구멍 깊이는 받은 화면에서 잼 (사양 G-2: 물림 = min(깊이 − 0.5, 4), 얕으면 와셔); xr-77 u6.5 (같은 부품 4개, 자리만 다름 — 첫 번째 값)
- **뒤판 출력물** — 바깥 판 2 (y340.5~342.5) + 테 (위 4 · 아래 1.5 · 옆 2) - 뚜껑 L·화면 뚜껑이 윗면에 얹혀 누름; KCD1은 2 mm 판에 끼우고 테두리(15.4×21.4)는 바깥면과 같은 높이; USB-C 입구 13 × 7.5 (바깥 판), HUSB238 주머니 x415.8~426.2 z35.6~40.4 (입구가 바깥면에서 2 안); J501 기판 받침 x449~476.5 y316.5~340.5 윗면 z36.4 (기판 밑) + 세운 받침벽 2 (x452~454/472~474, 2 두께, y320~340.5 z20.5~30: 바깥 판에서 곧게 올라 받침과 뒤 탭을 이음 - 출력 때 내민 면 없음); 루버 x480~534 (사양 536 → 옆 테 2를 남김) z18~46 3×6; 바닥 탭 2개 (x400~414, 452~474, y316~340.5, z16.5~20.5)에 접시 8호 13 mm를 아랫판으로: 왼쪽 (407, 322) (아랫판 뒤 모서리 y331에서 9), 오른쪽은 J501 받침이 탭 전체를 덮어 드라이버가 닿지 않으므로 탭에서 앞으로 낸 혀 x459.5~472.5 y304~316의 (466, 311.5) - 드라이버 Ø6 길이 받침·J501 기판 앞 1.0 (check_body.py가 나사마다 Ø6 × 80 드라이버 길을 확인) - 창 옆은 틈 없이 끼움
- **허브 위 선반 + 뒤판 받침 2 + 앰프 받침 4** — 선반 뒤 2 mm(y329~331)를 뒤판까지 이어 한 몸, 앰프 받침 Ø7 × 2 (구멍 Ø2.7 관통, 앰프 구멍 3.5 안쪽 가정 = v3 amp_bosses, 받은 앰프로 재서 옮김) - 사양 STANDOFFS의 '앰프 2 mm 받침'을 선반에 붙임; 받침마다 뒤판으로 Ø3 × 12~13 둥근머리 목재 나사 (머리 Ø6 이하; x693/907 z46, 구멍 Ø3.4, 머리 자리 Ø6.5 × 4 눈물방울 - 꼭지를 윗면 0.8 아래 z49.2에서 자름 → 합판 물림 약 9); 머리(아래 끝 z43.0)가 선반 윗면 z43.5보다 낮아 받침 앞 선반 윗면에 머리·드라이버 길 홈 7 × 0.8 (y282~322, 바닥 1.2 남음) - 나사를 조일 때 머리가 선반을 긁지 않음. 8호(Ø4.2, 머리 Ø8)는 10 × 8 받침에 들어가지 않음; 허브 윗면 z40.5와 1 mm (처지면 허브가 받침)
- **보조배터리 받침** — 배터리 둘레 0.5 틈 (배터리 x286~391 y254~325), +x 벽과 뒤 벽 끝(x390.5~)은 ㄱ자 USB-C 플러그·선 자리(Z-BANK-PLUG z26~43)에서 0.5 띄워 y276부터 z25.5로 낮춤, 끈 구멍 22 × 3 (앞·뒤 벽 바닥, 20 mm 벨크로가 배터리 밑·위를 감음 - BOM에 없음), 바닥 접시 8호 13 mm 4곳 (289, 272) · (388, 272) · (289, 307) · (388, 307) (모서리 y257/322가 아님: 가운데 아랫판의 고무발 나사 (292, 262)·(292, 320)와 축 사이 10 이상)
- **XT30 짝 집게 L** — XT30U-F 홈 10.6 × 5.6 × 12.4 (x274.6~287.0, 10.2 × 5.2 × 12.4 + 0.2씩), 입구 +x(가운데 쪽)으로 앰프 선 XT30U-M이 꽂힘, 홈 위 걸림 턱 1 × 1.2 (위에서 눌러 끼움); 홈에는 축 방향 멈춤이 없음 - 홈 뒤가 터널로 열려 있어야 스피커를 뗄 때 F가 터널로 빠짐, 그래서 홈 안의 F에 M을 대고 밀면 F가 터널로 밀려 들어감 → 짝 꽂기: F를 홈 입구로 가운데 쪽에 당겨 꺼내 (꼬리 여유 약 35 mm) 손으로 M을 끝까지 꽂고, 짝을 다시 가져와 F 앞면을 홈 입구에 맞춰 위에서 걸림 턱 밑으로 눌러 끼움; 뽑기는 거꾸로 (짝을 입구로 꺼낸 뒤 손으로 뽑음); 옆벽 밑에 45° 받침 2개를 판의 구멍 아래 부분까지 (출력 때 옆벽·바닥이 구멍 위에 뜨지 않게); 끝벽에 붙는 판 x271.5~274.5 y233.5~252.5 z28.0~54.0 (구멍 둘레 2.5~3), MS 폴리머로 붙임; 스피커 꼬리의 여유 약 35 mm는 터널 안에 느슨하게 1.5바퀴 감김 (C-SPKPIG, 스피커 밖 꼬리 약 54 mm)
- **XT30 짝 집게 R** — XT30U-F 홈 10.6 × 5.6 × 12.4 (x935.0~947.4, 10.2 × 5.2 × 12.4 + 0.2씩), 입구 −x(가운데 쪽)으로 앰프 선 XT30U-M이 꽂힘, 홈 위 걸림 턱 1 × 1.2 (위에서 눌러 끼움); 홈에는 축 방향 멈춤이 없음 - 홈 뒤가 터널로 열려 있어야 스피커를 뗄 때 F가 터널로 빠짐, 그래서 홈 안의 F에 M을 대고 밀면 F가 터널로 밀려 들어감 → 짝 꽂기: F를 홈 입구로 가운데 쪽에 당겨 꺼내 (꼬리 여유 약 35 mm) 손으로 M을 끝까지 꽂고, 짝을 다시 가져와 F 앞면을 홈 입구에 맞춰 위에서 걸림 턱 밑으로 눌러 끼움; 뽑기는 거꾸로 (짝을 입구로 꺼낸 뒤 손으로 뽑음); 옆벽 밑에 45° 받침 2개를 판의 구멍 아래 부분까지 (출력 때 옆벽·바닥이 구멍 위에 뜨지 않게); 끝벽에 붙는 판 x947.5~950.5 y280.5~299.5 z39.5~59.5 (구멍 둘레 2.5~3), MS 폴리머로 붙임; 스피커 꼬리의 여유 약 35 mm는 터널 안에 느슨하게 1.5바퀴 감김 (C-SPKPIG, 스피커 밖 꼬리 약 54 mm)
- **보드 받침 기둥** — 기둥 Ø6 × 6 (x545.5 y265.5), M2.5×6 자가 탭 (구멍 Ø2.2 × 5, 기판 1.6 → 물림 4.4, 바닥 1.0) - 보드에 먼저 나사로 달고 기둥 밑을 아랫판에 MS 폴리머로 붙임(스스로 자리 잡음); 사양의 '받침 판'(90×60) 대신 낱개 기둥 - 아랫판 흡기 홈을 막지 않음 (같은 부품 4개, 자리만 다름 — 첫 번째 값)
- **보드 받침 기둥** — 기둥 Ø7 × 5 (x480.7 y291.9), M3×5 자가 탭 (구멍 Ø2.7 × 4, 기판 1.6 → 물림 3.4, 바닥 1.0 - 6 mm 이상은 바닥을 뚫고 기둥을 밀어 올림) - 보드에 먼저 나사로 달고 기둥 밑을 아랫판에 MS 폴리머로 붙임(스스로 자리 잡음); 사양의 '받침 판'(90×60) 대신 낱개 기둥 - 아랫판 흡기 홈을 막지 않음 (같은 부품 4개, 자리만 다름 — 첫 번째 값)
- **보드 받침 기둥** — 기둥 Ø6 × 5 (x405.0 y251.0), M3×5 자가 탭 (구멍 Ø2.5 × 4, 바닥 1.0) / 위치 핀 Ø2.8 × 2.5 - 보드에 먼저 나사로 달고 기둥 밑을 아랫판에 MS 폴리머로 붙임(스스로 자리 잡음); 사양의 '받침 판'(90×60) 대신 낱개 기둥 - 아랫판 흡기 홈을 막지 않음 (같은 부품 4개, 자리만 다름 — 첫 번째 값)
- **보드 받침 기둥** — 기둥 Ø7 × 5 (x508.0 y258.0), M3×5 자가 탭 (구멍 Ø2.7 × 4, 바닥 1.0) - 보드에 먼저 나사로 달고 기둥 밑을 아랫판에 MS 폴리머로 붙임(스스로 자리 잡음); 사양의 '받침 판'(90×60) 대신 낱개 기둥 - 아랫판 흡기 홈을 막지 않음 (같은 부품 2개, 자리만 다름 — 첫 번째 값)
- **퓨즈 홀더 받침** — 받침 x403~453 y299.00~313.00 z16.5~25.5, 축 (y306, z22.5) - 위가 8.4만 열려 Ø10 홀더를 눌러 끼움, 아랫판에 MS 폴리머
- **케이블 집게** — 사양에 자리가 없어 통로 지붕 밑면 z27에 붙여 z19~27, y226~236 (x30~50)에 둠 - 묶음 윗면 z16.25보다 2.75 위라 모델에서는 비어 있음; 처지는 EL·ER 리드나 헤드폰 선을 끼우는 자리 - 집게는 스피커에 붙어 있으므로 스피커를 약 10 mm 든 뒤 (더 들거나 옆으로 밀기 전에) 지붕 집게에 끼운 선을 모두 빼냄, 남기면 선이 스피커와 같이 들림; 홈 4.5 (Ø3.5 선 1가닥 - 2가닥은 홈 7이 필요), 입구 3.0 걸림 턱, MS 폴리머로 붙임 (같은 부품 6개, 자리만 다름 — 첫 번째 값)
- **케이블 집게** — 끝벽 L 안면 x271.5에 붙여 y262~282 z48~58 - 끝벽을 따라 앞으로 오는 스피커선 C-SPK-L (x275.1 z53)을 홈 바닥에 잡음 (나비나사 머리 y310~320·XT30 집게 판 y≤252.5을 피함); 홈 4.5, 입구 3.0 걸림 턱, MS 폴리머로 붙임 (같은 부품 2개, 자리만 다름 — 첫 번째 값)
- **센서 기판 SB** — U홈이 왼쪽 끝으로 열림 (spec assumed: U-slot opening direction (to the left edge) inferred from "U홈" with the centre 2.0 from the edge)
- **RP2040-Zero** — 윗면 부품 덩어리 x75.64~92.64 y172.5~189.5 z≤16.3과 밑면 칩 덩어리 z10.6~11.9 (spec assumed 분할); 핀 헤더 1×9 ×2는 작은 부품이라 뺌
- **CD74HC4067 16채널 먹스 모듈** — 헤더 몰드 2.5 높이 (spec assumed: header mold 2.5 (standard 11.5 mm 1-mold header: tail 3.0 / mold 2.5 / top 6.0), PCB 1.6, chip placement centred; the 2 x D3.3 mounting holes are unused and their positions are not documented)
- **EXT 연장선 W403** — 묶음 단면 약 8×2와 띠 안의 x 위치 (spec assumed; spec 상자 y195.4~가 MB 끝 y195.5와 0.1 겹쳐 MB 자리를 뺌); 뒷벽 구멍(y212)부터 XH 짝까지는 지름 3 선으로 L2 통로(y212~241, 스피커 밑) 바닥(z0~3)에 눕힘 - 경로는 보기용
- **USB-C 케이블 W201** — 케이블 OD 3.5; 플러그 뒤 y221.8에서 R8로 꺾여 묶음 앞(y229.5)을 x로 달리며 z14.5 → z10.25로 옮긴 뒤 묶음 y237.5의 3층 z10.25로 들어가 허브 포트 x784.5에서 위로 서고 R9.5로 +y (묶음 맨 위라 다른 선을 넘지 않음); 길이 = 플러그 25 + 경로 680.1 + 허브 플러그 35 = 740.1 mm (사양 769, 표준 1.0 m, 여유 260 ≥ 40) - 선은 통로·앞 공간 안에서만 (배기 홈·건반 뒤 2 mm 틈으로 조금 보임), 경로는 보기용 (묶을 때는 끈·벨크로 - 지붕 밑 케이블 집게에는 끼우지 않음)
- **USB-C 케이블 W202** — 케이블 OD 3.5; 플러그 뒤 y221.8에서 R8로 꺾여 묶음 앞(y229.5)을 x로 달리며 z14.5 → z6.25로 옮긴 뒤 묶음 y237.5의 2층 z6.25로 들어가 허브 포트 x806.5에서 위로 서고 R9.5로 +y (묶음 맨 위라 다른 선을 넘지 않음); 길이 = 플러그 25 + 경로 542.1 + 허브 플러그 35 = 602.1 mm (사양 627, 표준 1.0 m, 여유 398 ≥ 40) - 선은 통로·앞 공간 안에서만 (배기 홈·건반 뒤 2 mm 틈으로 조금 보임), 경로는 보기용 (묶을 때는 끈·벨크로 - 지붕 밑 케이블 집게에는 끼우지 않음)
- **USB-C 케이블 W203** — 케이블 OD 3.5; 플러그 뒤 y221.8에서 R8로 꺾여 묶음 앞(y229.5)을 x로 달리며 z14.5 → z14.25로 옮긴 뒤 묶음 y237.5의 4층 z14.25로 들어가 허브 포트 x762.5에서 위로 서고 R9.5로 +y (묶음 맨 위라 다른 선을 넘지 않음); 길이 = 플러그 25 + 경로 326.4 + 허브 플러그 35 = 386.4 mm (사양 418, 표준 0.5 m, 여유 114 ≥ 40) - 선은 통로·앞 공간 안에서만 (배기 홈·건반 뒤 2 mm 틈으로 조금 보임), 경로는 보기용 (묶을 때는 끈·벨크로 - 지붕 밑 케이블 집게에는 끼우지 않음)
- **USB-C 케이블 W204** — 케이블 OD 3.5; 플러그 뒤 y221.8에서 R8로 꺾여 묶음 앞(y229.5)을 x로 달리며 z14.5 → z2.25로 옮긴 뒤 묶음 y237.5의 1층 z2.25로 들어가 허브 포트 x828.5에서 위로 서고 R9.5로 +y (묶음 맨 위라 다른 선을 넘지 않음); 길이 = 플러그 25 + 경로 240.7 + 허브 플러그 35 = 300.7 mm (사양 320, 표준 0.5 m, 여유 199 ≥ 40) - 선은 통로·앞 공간 안에서만 (배기 홈·건반 뒤 2 mm 틈으로 조금 보임), 경로는 보기용 (묶을 때는 끈·벨크로 - 지붕 밑 케이블 집게에는 끼우지 않음)
- **USB-C 케이블 W205** — 케이블 OD 3.5; 짧은 선이라 묶음 위 앞쪽 줄 y226 z24를 달려(묶음 윗면 z16 위 8) 포트 x850.5에서 묶음을 넘어 +y; 길이 = 플러그 25 + 경로 86.8 + 허브 플러그 35 = 146.8 mm (사양 177, 표준 0.3 m, 여유 153 ≥ 40) - 선은 통로·앞 공간 안에서만 (배기 홈·건반 뒤 2 mm 틈으로 조금 보임), 경로는 보기용 (묶을 때는 끈·벨크로 - 지붕 밑 케이블 집게에는 끼우지 않음)
- **USB-C 케이블 W206** — 케이블 OD 3.5; 짧은 선이라 묶음 위 앞쪽 줄 y226 z24를 달려(묶음 윗면 z16 위 8) 포트 x872.5에서 묶음을 넘어 +y; 길이 = 플러그 25 + 경로 106.3 + 허브 플러그 35 = 166.3 mm (사양 197, 표준 0.3 m, 여유 134 ≥ 40) - 선은 통로·앞 공간 안에서만 (배기 홈·건반 뒤 2 mm 틈으로 조금 보임), 경로는 보기용 (묶을 때는 끈·벨크로 - 지붕 밑 케이블 집게에는 끼우지 않음)
- **EXT 연장선 W413** — 묶음 단면 약 8×2와 띠 안의 x 위치 (spec assumed; spec 상자 y195.4~가 MB 끝 y195.5와 0.1 겹쳐 MB 자리를 뺌); 뒷벽 구멍(y212)부터 XH 짝까지는 지름 3 선으로 L2 통로(y212~241, 스피커 밑) 바닥(z0~3)에 눕힘 - 경로는 보기용
- **USB-C 케이블 W207** — 케이블 OD 3.5; 플러그 뒤 y221.8에서 R8로 꺾여 묶음 앞(y229.5)을 x로 달리며 z14.5 → z6.25로 옮긴 뒤 묶음 y237.5의 2층 z6.25로 들어가 허브 포트 x894.5에서 위로 서고 R9.5로 +y (묶음 맨 위라 다른 선을 넘지 않음); 길이 = 플러그 25 + 경로 254.6 + 허브 플러그 35 = 314.6 mm (사양 339, 표준 0.5 m, 여유 185 ≥ 40) - 선은 통로·앞 공간 안에서만 (배기 홈·건반 뒤 2 mm 틈으로 조금 보임), 경로는 보기용 (묶을 때는 끈·벨크로 - 지붕 밑 케이블 집게에는 끼우지 않음)
- **끝 부속 센서 기판 EL** — U홈 Ø3.4가 왼쪽 끝으로 열림 (spec assumed)
- **끝 부속 센서 기판 ER** — U홈 Ø3.4가 왼쪽 끝으로 열림 (spec assumed)
- **EL 리드 W401** — 뒷벽 노치(y212)에서 통로 바닥으로 내려 XH 짝 끝면까지 지름 2 선으로 표시 (실제는 폭 6.35 리본 띠) - 경로는 보기용
- **ER 리드 W411** — 뒷벽 노치(y212)에서 통로 바닥으로 내려 XH 짝 끝면까지 지름 2 선으로 표시 (실제는 폭 3.81 리본 띠) - 경로는 보기용
- **JST-XH 6P 짝 X401/X402** — 느슨한 커넥터 - 위치·높이·길이 (spec assumed: loose connector: position not fixed by any document - placed on the passage floor between the EL notch (x~18) and the O1)
- **JST-XH 6P 짝 X411/X412** — 느슨한 커넥터 - 위치·높이·길이 (spec assumed: loose connector, placed between the ER notch (world x1206..1212) and the O7 rear opening (world x = 1034 + 74..94 = 1108)
- **라즈베리파이 5 2GB** — GPIO 헤더 2×20 (가장자리 3.5, 비포트 쪽 끝에서 32.5 중심, 윗면 z32.6)과 SoC 방열판 15×15×8 위치; 구멍 Ø2.7 4개 58×49 (보드 모서리에서 3.5 - body.py 받침 기둥 CU-POST-PI 자리); micro-HDMI 2개 (-y 가장자리, 중심 x568.0 · 581.5, 폭 7.0, y262.0~269.5, 윗면 z27.3 - Pi 5 도면 26 · 39.5 mm, W1 3판 추정 상자 x562~585 안; 화면 리본이 안 쓰는 HDMI 위에 얹힘); USB-C 전원은 작아서 뺌
- **라즈베리파이 5 RJ45 이더넷 잭** — Pi 5 포트 가장자리 순서(전원·HDMI 가장자리 쪽부터 RJ45, USB-A 2단, USB-A 2단)와 중심(전원 가장자리에서 RJ45 10.25 · USB-A 29 · 47, Pi 3B+ 도면 값 - Pi 5 도면으로 확인), 크기 RJ45 16×21.25×13.5, USB-A 2단 14.5×17.5×16.4, 보드 끝에서 2.5 튀어나옴(x629.5); 이 포트 중심 y272.25
- **라즈베리파이 5 USB-A 2단** — Pi 5 포트 가장자리 순서(전원·HDMI 가장자리 쪽부터 RJ45, USB-A 2단, USB-A 2단)와 중심(전원 가장자리에서 RJ45 10.25 · USB-A 29 · 47, Pi 3B+ 도면 값 - Pi 5 도면으로 확인), 크기 RJ45 16×21.25×13.5, USB-A 2단 14.5×17.5×16.4, 보드 끝에서 2.5 튀어나옴(x629.5); 이 포트 중심 y291.00 (같은 부품 2개, 자리만 다름 — 첫 번째 값)
- **라즈베리파이 5 CAM/DISP 1 커넥터** — 둘 중 -x 쪽 커넥터를 CAM/DISP 1로 표시(보드 글씨로 확인), 높이 4.0; 화면 DSI 리본(TS-C-DSI)이 입구 x589(−x 쪽)로 2.7 꽂힘, 리본은 Z-DSI x582~600 y262~280 z28.1~61.35 안의 기둥 x583으로 내려옴
- **IH190 USB-C(F)→USB-A(M) ㄱ자 젠더** — RJ45 옆 USB-A 2단(중심 y291)의 아래 포트에 꽂음 (A 플러그 면 x629.5 = 포트 면); C 소켓이 -y를 향함
- **Apple USB-C → 3.5 mm 어댑터** — 머리 8.5 × 6 × 24 (6.5는 젠더 C 소켓 안)가 젠더에서 -y로, 약 7 cm 선이 바닥(z16.5)으로 내려가 젠더·머리 밑을 +y로 지나 x650에서 -y로 돌아 3.5 mm 소켓 머리(Ø10.5 × 25, 축 x650 z21.75, 앞 끝 y262.1 - 바닥에 닿음)의 +y 끝에 들어감; W701은 소켓 -y 끝에 꽂힘 (모델에 없음, Z-DONGLE-PLUG 비움)
- **XH-A232** — 부품은 모서리 7×7(나사 자리)을 뺀 한 덩어리 z47.1~59.5; 구멍 Ø3.2는 body.py 선반의 앰프 받침 자리 (745.5,286.5 · 792.5,286.5 · 745.5,325.5 · 792.5,325.5) - 받은 보드로 확인; 전원 단자·스피커 L 단자는 -x 끝(y313 / y318), 스피커 R 단자는 +x 끝(y293)으로 가정
- **XL4016 강압 모듈 XH-M401** — 방열판 2·코일·캐패시터를 모서리 6.5×6.5를 뺀 한 덩어리(z23.1~50.5)로 표시, 구멍 Ø3.2 모서리에서 3.2 (body.py CU-POST-BUCK 자리); 입력 단자 -x 끝(x477.5 y306), 출력 단자 앞면(-y, x529.5) 가정
- **PED 페달 보드** — 나사 구멍 Ø3.2 (x405 y251 · x467 y293), 위치 핀 구멍 Ø3.0 (x467 y251 · x405 y293) - body.py CU-POST-PED 자리
- **RP2040-Zero** — MB의 Zero 배치(핀 헤더 1.3 틈)를 180° 돌려 PED 보드 위에 (USB-C 리셉터클 -y, 중심 x449.14 z27.0)
- **앰프 입력 잭 기판** — 구멍 Ø3.2 두 곳 (body.py CU-POST-J702 자리); RC 부품은 작아서 뺌
- **앰프 입력 잭 PJ-313** — 몸체 y257.5~269, 코 Ø5가 기판 앞끝 y255까지, 축 z25.6 - W702 플러그는 모델에 없음 (Z-J702-PLUG 비움)
- **BU914 인라인 퓨즈 홀더 + 5 A T 퓨즈** — 지름 10 (body.py 받침 Ø10.3에 눌러 끼움) - 받은 홀더로 확인; 양끝 선은 C-PWR-IN / C-PWR-FUSE
- **페달 잭 기판** — PR-BACKPLATE 잭 선반(윗면 z36.4)에 MS 폴리머 (구멍 없이)
- **페달 잭 PJ-313** — 기판 위(z38), 축 z40.5 = 판 구멍 중심, 코 끝이 바깥면 y342.5과 같은 면 - 받은 부품으로 확인
- **KCD1-101A 로커 스위치** — 테두리 15×21×2 (y340.5~342.5, 오목 자리 안), 몸통 13.2×19.2×13 (y327.5~340.5, 판 구멍에 스냅), 4.8×0.8 단자 2개 8 길이 (y319.5~327.5, z34.5 / 42.5) - 받은 스위치로 확인
- **HUSB238 PD 트리거 + USB-C 전원 입력** — 기판 1.2 + USB-C 리셉터클 8.94×7.3×3.2 (+y 끝, 입구 y340.5); 출력 선은 -y 끝(y324.1)에서 C-PWR-IN
- **USB-C 케이블 W208** — PED Zero USB-C(축 x449.14)의 곧은 플러그 y222.0~247.0가 -y로, y217.5에서 +x로 꺾여 올라 앞 공간 줄 y227 z37를 달려 x731에서 묶음 위로 내려와 허브 포트 2(x740.5)로; 길이 374.3 mm (사양 399, 표준 0.5 m, 여유 126) - 경로는 보기용
- **USB 허브 업스트림 선 C25** — A 머리 13 × 15 × 9 (포트 면 x629.5부터) + 뿌리 Ø8 × 8 + 주름 Ø6.5 × 8 (사진 비례, A 쉘 12 × 4.5 기준), B 몸 20 × 16 × 13, 선 OD 4; 길이: A 41.0 (쉘 12 포함) + 선 169.0 + B 40.0 (쉘 10 포함) = 250 (제품 250) - 남는 선은 선반 위 납작한 U자(z56.5, x709까지, 화면 뚜껑 이음 레일 x711 앞)로, 케이블 타이 없이 눕힘. '상향'은 혀가 위인 보통 가로 포트에서 위 - Pi 5 USB-A 2단은 두 포트가 같은 방향이라 위로 감 (받으면 먼저 Pi에 꽂아 위로 가는지 확인 - 아래로 꺾이는 선은 어느 포트에서도 머리가 바닥 z16.5에 닿아 못 씀)
- **NEXTU 710U3 10포트 유전원 USB 허브** — 아래 포트 10개를 앞면(y282, -y 쪽) x696.5+22i, z28.5에, B 포트 y319 z28.5 (뒤쪽), DC 잭 y293 z28.5 (앞쪽) - 끝면 안 자리는 받은 허브로 확인; 포트 0·1(화면 뚜껑 아래)은 비움
- **모루이 MT-65 보조배터리** — 받침 바닥(z18.5) 위, 둘레 0.5 틈; 선택품(O07) - ㄱ자 USB-C 선(Z-BANK-PLUG → 케이블 통과 → 뒤판 USB-C 입력)은 모델에 없음
- **전원선 HUSB238 → 퓨즈 홀더** — 두 가닥을 Ø3 한 줄로; PD 기판 -y 끝에서 앞으로 나와 y318을 따라 내려가 x401에서 퓨즈 홀더 왼쪽 끝으로 (받침 구멍 끝이 열림, Z-BANK-PLUG z26 아래); 약 41 mm - 경로는 보기용
- **전원선 퓨즈 홀더 → KCD1 입력 단자** — 퓨즈 홀더 오른쪽 끝에서 x456.5로 나와 받침 위로 올라 KCD1 아래 단자(z34.5) 끝에 납땜 (J501 선반 y315.5 앞); 약 35 mm
- **20 V 선 KCD1 → 강압 입력 + 앰프 전원** — KCD1 위 단자(z42.5)에서 두 갈래 - (1) 강압 -x 끝면 입력 단자(x477.5 y306 z36.5), (2) 위로 올라 뒤 줄 y324 z53 (뒤판을 따라, 강압 윗면 z50.5 위 1, 뚜껑 이음 레일 밑 0.85)을 x733까지 가서 앰프 -x 끝면 전원 단자(y313 z52); 약 370 mm
- **5.1 V 선 강압 → Pi 5** — 강압 앞면 출력 단자(x529.5 z36)에서 두 갈래 - (1) J702 기판 위(z36)를 지나 Pi -y 가장자리의 C24 측면 꺾임 USB-C 머리 14×12×7 (x546~560 y250~262 z22.2~29.2, 사양 지킴 자리 Z-PI-PWR 14×13×9 안) + 꼬리 Ø4.5 (x542.5~546) - 선이 -x(강압 쪽)로 나오게 꽂음 (USB-C는 뒤집으면 +x), 강압 단자까지 경로 약 45 mm - 20 cm 선의 A 쪽을 자를 때 30~40 mm 여유만 남김; (2) y285 z48.5 (Pi USB-A 위 6.5, Z-DSI y280 뒤 3.5)를 x680.5까지 가서 허브 -x 끝면의 ㄱ자 DC 플러그 머리 12×12×10 (x674.5~686.5 y287~299 z23.5~33.5, 잭 y293 z28.5, 선이 위로 나옴)로 내려옴; 곧은 DC 플러그는 잭 면에서 몰드 끝까지 32 mm 이하이고 선을 바로 위로 R5로 꺾을 때만 들어감 (그보다 길면 Pi 쪽 젠더 IH190 x647.5에 닿음, check_electronics.py); 전체 약 225 mm
- **XT30U-F 암** — 몸체를 10.2×5.2×12.4 상자로; 집게 홈(x274.6~287.0 y237.7~248.3 z41.2~46.8) 가운데, 입구를 홈 입구 x287.0(가운데 쪽)에 맞춤; 꼬리 선은 C-SPKPIG-L
- **XT30U-M 수** — 암 속으로 들어간 5.6은 빼고 밖에 보이는 8.1만 표시; 앰프 선은 C-SPK-L
- **XT30U-F 암** — 몸체를 10.2×5.2×12.4 상자로; 집게 홈(x935.0~947.4 y284.7~295.3 z48.2~53.8) 가운데, 입구를 홈 입구 x935.0(가운데 쪽)에 맞춤; 꼬리 선은 C-SPKPIG-R
- **XT30U-M 수** — 암 속으로 들어간 5.6은 빼고 밖에 보이는 8.1만 표시; 앰프 선은 C-SPK-R
- **스피커선 L** — Ø3 한 줄로; 앰프 -x 끝면 L 단자(y318 z52)에서 뒤 줄 y328 z53 (20 V 선 y324 뒤)을 x275까지, 끝벽 L 안면을 따라 (케이블 집게 2개 y262~282·286~306의 홈 바닥, x275.1) y256까지 앞으로 와 (XT30 집게 판 y≤252.5 뒤) 보조배터리 앞(배터리 y254~)을 비스듬히 x301까지 z53으로 건넌 뒤 내려와 XT30U-M L 뒤끝(+x)으로 들어감 - 배터리를 곧게 들어 빼도 닿지 않음; 약 580 mm
- **스피커선 R** — Ø3 한 줄로; 앰프 +x 끝면 R 단자(y293 z49.5)에서 선반 위 y293 z49.5를 x915까지, XT30U-M R 뒤끝(-x)으로; 약 129 mm
- **스피커 꼬리선 L** — 2가닥을 Ø2 한 줄로 (보기용); 암 뒤끝에서 집게 판 구멍 → 끝벽 구멍 Ø14 (y243 z44.0, 집게 홈과 같은 축) 안에 느슨하게 1.5바퀴 (지름 약 9) 감긴 여유 → 틈 → 스피커 옆판 구멍 Ø6 (y243 z40, 본드로 밀봉) → 상자 안에서 유닛 바스켓 +x쪽 단자(유닛 축에서 x 48, 바깥면 뒤 16)까지 약 132 mm (꼬리 150; 스피커 밖 54 mm - 스피커를 약 10 mm 들고 15 mm 바깥으로 밀어도 F가 집게에 남음; 남는 선은 상자 안 흡음솜 속에)
- **스피커 꼬리선 R** — 2가닥을 Ø2 한 줄로 (보기용); 암 뒤끝에서 집게 판 구멍 → 끝벽 구멍 Ø14 (y290 z49.5, 집게 홈 축 z51.0보다 1.5 아래) 안에 느슨하게 1.5바퀴 (지름 약 9) 감긴 여유 → 틈 → 스피커 옆판 구멍 Ø6 (y290 z40, 본드로 밀봉) → 상자 안에서 유닛 바스켓 -x쪽 단자(유닛 축에서 x 48, 바깥면 뒤 16)까지 약 129 mm (꼬리 150; 스피커 밖 54 mm - 스피커를 약 10 mm 들고 15 mm 바깥으로 밀어도 F가 집게에 남음; 남는 선은 상자 안 흡음솜 속에)
- **삼미 CW-100B25 4인치 풀레인지 8 Ω L** — 플랜지를 경사 바깥면에서 가스켓 3 앞(법선 방향 3~7)에, 바스켓 테두리를 가스켓 구멍 안으로 이어 한 덩어리로; 자석이 바깥면 뒤 37~54 (자석 중심 y289.25 z65.59), 가장 낮은 곳 z31.77 (아랫판 윗면 z16.5 위 15.27); 자석 뒤 폴 벤트는 모델에 없음 (축 방향 10 mm 이상 비움 - W1); 콘 오목면(Ø90→Ø34, 깊이 24)과 더스트캡은 보기용
- **헤드폰 잭 PJ-313** — 포켓 위치·축 높이 z20 (frame spec assumed); 다리(밑 3.2)와 케이블 ①·②(W701/W702)는 뺌
- **Waveshare 7-DSI-TOUCH-C 7인치 DSI 정전식 터치 화면** — 커넥터 방향 - 화면 앞에서 볼 때 커넥터 창이 오른쪽, 입구 +x (사양 G-1: 사진 3장으로 판단, 받으면 확인; 반대면 창·홈·구멍·클립을 x611 기준으로 뒤집음); 창 깊이 2.0, ZIF 높이 2.0, MX1.25 높이 2.0, 모서리 구멍 깊이 4.0 (안지름 Ø2.2로 모델 - 나사산 물림), 아래 끝 돌기 w2~6; 유리 아래 끝 u0이 받침 아래 벽에 얹힘, 뒷면 w8이 보스 4개에 닿음
- **DSI FFC 22핀 0.5 mm 300 mm B형** — 폭 11.7 × 두께 0.3; 받침 안 ZIF 입구 w7, 접힌 겹 사이 0.27(한 몸), 화면 창에서 w8.15로 올라 화면 뒷면에 붙음; 고리는 길이 23.04 3차 베지어; 뚜껑 밑 접기는 날카로운 접기로 그림(말아 접기 여유 9.42는 길이에 더함); 펼친 길이 모델 244.8 (+ 뚜껑 밑 말아 접기 9.4 = 254.2) / W1 계산 256.32 / 케이블 300; 화면 ZIF에 3.5, Pi 쪽 CAM/DISP 1에 2.7 꽂음
- **화면 전원선 빨강 5 V** — 선 Ø1.1, 두 가닥 간격 1.3 (화면 안·클립 홈 안에서 나란히), 화면 쪽 끝은 MX1.25 안 2 mm, Pi 쪽 F 점퍼 하우징 2.5 × 2.5 × 14가 핀 2에 (헤더 받침 위 z26.6~40.6 - 헤더 상자는 핀 끝까지 한 덩어리라 겹침); 길이 모델 321.7 (하우징 윗면 아래 1까지) + 하우징·핀 9 + 꽂는 여유 15 ≈ 346 / W1 계산 344.95 / 있는 길이 500~550 (점퍼 20 cm × 2 + Waveshare 3핀 선 약 100~150)
- **화면 전원선 검정 GND** — 선 Ø1.1, 두 가닥 간격 1.3 (화면 안·클립 홈 안에서 나란히), 화면 쪽 끝은 MX1.25 안 2 mm, Pi 쪽 F 점퍼 하우징 2.5 × 2.5 × 14가 핀 6에 (헤더 받침 위 z26.6~40.6 - 헤더 상자는 핀 끝까지 한 덩어리라 겹침); 길이 모델 321.8 (하우징 윗면 아래 1까지) + 하우징·핀 9 + 꽂는 여유 15 ≈ 346 / W1 계산 344.95 / 있는 길이 500~550 (점퍼 20 cm × 2 + Waveshare 3핀 선 약 100~150)

## 모델에 넣지 않은 것

사용자 요청대로 만능기판은 사각형만 두고, 그 위에는 부피 있는 부품만 넣었습니다. 아래 항목은 크기가 작거나 위치가 조립 때 정해지는 것이라 모델에 없습니다. 구매는 BOM(`hardware/bom/final-bom`)을 따릅니다.

| 무엇 | 개수 | 비고 |
|---|---|---|
| 홀센서 DRV5055A2QLPG, 저항·커패시터, 핀 헤더, 납땜 패드 | 88 + α | 회로 부품 (요청대로 생략). 센서 자리는 센서 바 포켓으로 표시 |
| 스텐 직결피스 8호 13 mm 둥근머리 (L49) | 14 | 고무발 14 (L2). 고무발은 25 mm가 아니라 13 mm 이하 — 16 mm 이상은 스피커 밀폐 바닥을 뚫음 |
| Ø3 × 12~13 둥근머리 목재 나사 (머리 Ø6 이하) | 2 | 허브 선반 받침 2개를 뒤판에 (받침 10 × 8에 8호가 들어가지 않음). 구멍 Ø3.4·머리 자리는 모델에 있음. 구매 목록에 없음 |
| 스텐 직결피스 8호 13 mm 접시머리 | 6 | 뒤판 출력물 바닥 탭 2 + 보조배터리 받침 4. 구멍(접시 자리)은 모델에 있음. 구매 목록에 없음 |
| 스텐 직결피스 8호 19 mm (L49) | 8 | 그릴 4 × 2 (W1: 떨리지 않게 4개 모두). 25 mm는 앞판 아래 파일럿 끝 2.15 밑 밀폐면을 뚫음 — 19 mm 이하 |
| M4×12 유두 렌치볼트 (L70) | 8 | 스피커 유닛을 출력 앞판의 L69 인서트(모델에 있음)에. 플랜지 4 + 가스켓 3을 지나 5 들어가 인서트 4를 지나 1 더, 끝은 구멍 Ø5.6 × 6.5 바닥 1.5 위. 인서트는 면까지만 넣고 나사는 M4×12 이하 — 아래 구멍 밑 밀폐면이 2.78 |
| 보드 나사: M2.5×6 자가 탭 (Pi 5), M3×5 자가 탭 (강압 4·J702 2·PED 2), M3×6 자가 탭 (앰프 4) | 4 / 8 / 4 | 받침 기둥 구멍은 Pi Ø2.2 × 5, 나머지 × 4 (바닥 1.0) — 더 긴 나사는 바닥을 뚫고 붙인 기둥을 밀어 올림. 앰프는 받침 + 선반 관통 |
| AUX 3.5 mm 선 2가닥 W701/W702 (볼 헤드폰 잭 ↔ 동글·J702), 보조배터리 ㄱ자 C-C 선(선택), 페달 선 | — | 경로는 조립 때 정해짐. 플러그 자리(Z-J702-PLUG·Z-DONGLE-PLUG·Z-BANK-PLUG)가 비어 있는 것은 check_electronics.py가 확인. 모듈 USB 선, 전원선(PD 입력·퓨즈·20 V·5.1 V), 스피커선, 스피커 꼬리선, XT30, 리본, EXT 선, JST-XH는 모델에 있음 |
| 흡음솜(폴리에스터), 부싱 천 0.5T (노치·핀 홈·탭 옆), 종이 펀칭, PET 심, MS 폴리머·목공본드 | — | 두께가 출력 치수에 이미 들어 있음(노치 R2.55 → 천 뒤 R2.05). 흡음솜 조건은 아래 'W1 음향 조건' |

## 구매 목록에 없는 것 (따로 사거나 확인)

10/1 구매 목록 v4(`hardware/bom/toccata-purchase-list-v4.xlsx`)에 L69~L79·C22·C24·C25가 들어갔습니다. '구매 목록 v4 …' 줄은 CAD를 그 상품에 맞춘 것이고 (L73은 Norelem 07653-04 나사산 인서트로 바뀜), 나머지 줄은 v4에서 다시 확인할 것입니다.

- M3×16 버튼헤드 ISO 7380 볼트 4개 + M4 와셔 (방진 브래킷 BRK2): M3×10은 볼 속 너트에 닿지 않음 (L1 그대로)
- 직결피스 8호 13 mm 접시머리 6개 (뒤판 출력물 바닥 탭 2, 보조배터리 받침 4): L49는 둥근머리
- 구매 목록 v4 L72·L73·L74 (스피커 ↔ 가운데 결합): 손잡이볼트 M4×20 (L72, 머리 Ø8 × 6) 4 — 슬리브 끝에서 이음면까지 16라 인서트에 4 물림 (M4×22면 6 = 인서트 길이, 끝이 구멍 바닥 2 위; M4×24 이상은 끝이 구멍 바닥에 닿고 더 길면 밑 밀폐 판을 누름 → **최대 M4×22**) + 실리콘 튜브 슬리브 (L74, 13 mm로 4개) + 나사산 인서트 **L73 = Norelem 07653-04** (셀프 태핑, 스틸, 컷팅 보어형, M4, 겉 Ø6.5, 피치 0.8, 길이 6, 최소 구멍 깊이 8) 4. 구멍은 **Ø5.8 × 8** (막힘, 깊이 멈춤: 드릴에 테이프 8 mm) — 오꾸메 자투리에 Ø5.8로 먼저 시험, 헐거우면 Ø5.5 (나무는 눌림). 안쪽 옆판(오꾸메 11.5) 밑에 지름 부분 3.5, 드릴 끝 밑 1.5 이상 남아 상자가 밀폐됨. 인서트는 면까지만 (밑 2 mm는 나사 끝 자리)
- Ø3 × 12~13 둥근머리 목재 나사 2개 (머리 Ø6 이하): 허브 선반 받침 → 뒤판
- 구매 목록 v4에 있음 — L69 M4 열압입 인서트 (ShenzenAV M4x4x6, 바깥 Ø6 × 4) 8 + 예비 2와 L70 M4×12 8 + 예비 2: 스피커 유닛을 출력 앞판에 (L1의 직결피스 8호 16 mm 대신). 모델 인서트도 Ø6 × 4 (구멍 Ø5.6 × 6.5 그대로, 지름 0.4 물림)
- 구매 목록 v4에 있음 — L71 M3 열압입 인서트 (ShenzenAV M3x4x4.5, 바깥 Ø4.5 × 높이 4) 6개 = 화면 뚜껑 이음 레일 4 + 예비 2. 모델 인서트 Ø4.5 × 4 (구멍 Ø4 × 4.5 그대로, 지름 0.5 물림; 길이 4 = 자리파기 계산 값 그대로). M3×10 4개는 기존 줄
- 터치스크린 3판 부품은 구매 목록 v4에 있음 (135 화면 Waveshare 7-DSI-TOUCH-C, 49 GUOCONN 22P 0.5 mm 300 mm B형 + 50 A형 보험, 51~54 실리콘 점퍼 F/F·M/M 빨강·검정 20 cm, 75 M3×20 × 4, 76 M2.5×6 × 4) — 모델과 개수가 같음. 글만 고칠 것: 49줄 '경로 약 271 mm(여유 29)' → 모델 254 / W1 계산 256 (여유 약 44); 62줄 M3×10 설명의 'R31 CU 뚜껑 앞 모서리 2곳'은 L2에서 화면 뚜껑 4개(레일 인서트)
- 캡톤테이프(26줄)를 화면 받침 안 리본 누름 패드 자리(xr26.75~39.45 u8~16)에도 씀 (사양 C-7)
- PETG: 07_터치스크린 출력물 약 98 g (속 꽉 채움 기준, 선택 화면 덮개 71 g 별도) + 화면 뚜껑(05) — 94줄 추가 1 kg 스풀 안에 들어감
- 열수축튜브: Waveshare MX1.25→2.54 3핀 선이 120.54 mm보다 짧으면 3핀 이음이 경첩 고리 안에 오므로 감쌈 (사양 G-4, 22 × 6 구멍 통과)
- USB-A→C 케이블 (NA993 계열) 길이별: 1 m × 2 (O1, O2), 0.5 m × 4 (O3, O4, O7, PED), 0.3 m × 2 (O5, O6) — L1의 1 m × 8 대신. 모델 길이는 ±30 mm 추정이라 사기 전에 끈으로 재 봄 (길이 = 플러그 25 + 경로 + 허브 플러그 35 ≤ 표준 − 40, 케이블마다 메모에 있음)
- ㄱ자 USB-C to C 케이블 0.3 m (보조배터리 → 뒤판 케이블 통과 Ø12 → PD 입력): 사양 bom_changes +2,060원
- 구매 목록 v4 C25 (Coms NA977, USB-A **위로 꺾임** → USB-B 곧음, 커넥터 포함 250 mm): 모델이 제품 방향대로 — A 머리는 Pi 5 GPIO 쪽 USB-A 2단의 **아래 포트**(위로 꺾인 머리가 포트 축에서 20.5 올라감: 위 포트면 끝이 z57라 뚜껑 밑 z61.35까지 4.35뿐, 선을 꺾을 수 없음; 아래 포트면 끝 z48.6, 위 포트는 머리에 가려 못 씀 — 남는 USB-A는 RJ45 옆 2단의 위 포트). 선은 위로 나와 z56.5(화면 전원선 밑 1.1)로 허브 선반 위에 납작한 U자(x709까지)를 그리고 내려와 허브 −x 끝면의 업스트림 B 포트(y319 z28.5)에 곧은 B 플러그(30 mm)로. 길이 A 41 + 선 169 + B 40 = 250. '위로'는 Pi 포트에서 확인 (아래로 꺾이는 선은 머리가 바닥에 닿아 못 씀)
- 구매 목록 v4 C24 (Coms BT663, USB-C **옆으로 꺾임** 20 cm, A 쪽을 잘라 빨강·검정을 강압 출력에): 꺾인 머리(사진 비례 추정 14 × 12 × 7)가 사양 지킴 자리 Z-PI-PWR 14 × 13 × 9 (x546~560 y249~262 z22~31) 안에 들어감 — 선이 −x(강압 쪽)로 나오게 꽂음 (USB-C는 뒤집으면 +x). 받으면 머리가 x 방향 14보다 길지 않은지 잼 (선이 −x로 나가므로 머리가 길면 −x 쪽으로 늘어남 - x540~546도 비어 있어 18 mm 머리까지 들어감). 허브 DC는 업스트림 B와 같은 −x 끝면(잭 y293 z28.5)에 **ㄱ자 DC 플러그** (머리 12 × 12 × 10, 선이 위로)로 모델. 딸린 어댑터 선의 **곧은 플러그**도 잭 면에서 몰드·부트 끝까지 **32 mm 이하**이고 선을 바로 위로(R5) 꺾을 수 있으면 들어감 (더 길면 IH190 젠더에 닿음 — check_electronics.py). 길면 같은 규격 ㄱ자 DC 플러그 선을 사는데, 그때 허브 잭의 **배럴 바깥/안 지름(5.5 × 2.1 / 5.5 × 2.5 / 3.5 × 1.35)과 배럴 길이**를 재서 맞춤
- 흡음솜 (폴리에스터): 스피커 상자마다 약 35 g을 상자 전체에 느슨하게 (W1). 기존 줄 양으로 되는지 확인
- 보조배터리 고정 끈 (벨크로 20 mm): 받침에 끈 구멍만 있음
- 센서 바 나사는 버튼헤드(머리 1.65)로: 캡볼트면 눌린 C·A0·C8 건반 밑과 0.48

## L2에서 더 이상 사지 않는 것

- 토글 래치 매미고리 L64 × 2 (−4,800원): 도브테일 블록과 함께 없어짐
- 오꾸메 합판 600 × 1200 (가운데 유닛용, −22,520원): 모든 판이 400 × 1200 한 장에 들어감. 가게가 아래 배치대로 자르지 못하면 600 × 1200을 그대로 삼
- 직결피스 8호 16 mm (스피커 유닛 4 × 2): M4 인서트 + M4×12로 바뀜. 8호 13 mm 둥근머리는 L1 46개 → L2 14개
- L1 출력물: CU 트레이, CU 뚜껑 v2, 모서리 받침 12, 예비 건반 칸막이, 작은 부품 상자(+뚜껑), 도브테일 블록 4, XT30 받침 2, L1 브래킷 2, I/O 판 → PETG 양은 대략 같음 (사양: L2 뒷바 출력물 약 1.1 kg, 모자라면 1 kg 스풀 +16,150원)
- R31 공식 Touch Display 2와 그 받침(2판): 사용자가 Waveshare 7-DSI-TOUCH-C로 바꿈 (2026-10-01). 3판 부품은 아래 '터치스크린 3판' 구매 줄
- R31 2판의 FIT0997 22→15핀 리본: 3판은 22핀 ↔ 22핀 GUOCONN FFC (구매 목록 v4 49·50줄)
- 사양 bom_net_krw: −21,060원 (위 추가분 포함)

## 조립 순서 (L2, CAD로 확인한 것)

건반 액션:

- 건반 모듈은 서로 도브테일(뿌리 6 → 끝 9, 깊이 4, 암은 밑이 열림)로 위에서 내려 끼웁니다. 뒤 꼬리는 높이 14라 빼려면 약 14 mm 들어야 합니다. 모듈은 도브테일 때문에 위로만 빠지므로 앞으로 밀지 않습니다.
- 제어 기판은 모듈을 뒤집어 바닥 구멍으로 밑에서 넣고 M3×6 2개로 매단 보스에 조입니다(바닥 EVA는 이 구멍 자리를 오려 냄).
- 강철 블록은 칸 길이 40.0에 딱 맞으므로 40 −0.1/−0.3으로 자르고 두께 8.9~9.1만 씁니다. 캐리어 칸 속 떼는 지지대는 먼저 떼어 냅니다.
- 스프링은 레버 봉을 넣기 전에 짧은 다리 끝부터 허브 가둠 홈으로 밀어 넣습니다(DESIGN 1f). 긴 다리는 뒷벽 보스의 홈(2.4 × 3.2)으로 밑에서 들어갑니다.

뒷바 L2:

1. **고무발** — 스피커 아랫판마다 4개, 가운데 아랫판 6개 (화성고무 28×5, 8호 **13 mm 이하**; 모두 통로 뒤 y≥248, 스피커 바깥 발은 사양 x−2/1224에서 x6/1216으로 옮김). 스피커 아랫판은 밀폐 상자 바닥이므로 나사 구멍마다 MS 폴리머 한 방울 (16 mm 이상은 상자 안으로 뚫림).
2. **스피커 상자 (책상 밖에서)** — 옆판 2 + 아랫판 + 뒤판 + 윗판을 목공본드로 잇고, 출력 통로 틀을 옆판 사이 앞에 넣어 세움벽 밑을 아랫판 앞 모서리(y241)에 붙임. 출력 앞판(40°)을 앞벽·턱 위에 MS 폴리머로 붙이고 둘레를 밀봉한 뒤 새는 곳이 없는지 확인. 안쪽 옆판에 L73 나사산 인서트 2개 (Norelem 07653-04 M4, 겉 6.5 × 길이 6, 구멍 Ø5.8 × 8 막힘 — 밑 오꾸메 1.5 이상, 옆판 면까지만; 상자를 붙이기 전에 판에서 뚫음), 앞판 유닛 자리에 L69 인서트 4개 (인두, 면까지), 통로 지붕 밑(z27)에 핀 소켓 블록 (L x2.5 · R x1219.5, y230)과 케이블 집게 3개, 바깥 옆판 홈에 통로 옆 마개. 스피커 꼬리선(XT30U-F 150)을 안쪽 옆판 Ø6 구멍으로 약 54 mm 빼고 본드로 밀봉. Ø94 구멍으로 흡음솜을 상자 전체에 느슨하게 넣고(유닛 뒤 10 mm·폴 벤트 축 10 mm는 비움), 유닛(가스켓 3T + M4×12 × 4 → 앞판 인서트; 더 긴 나사 금지), 그릴(8호 19 mm × 4; 25 mm 금지).
3. **가운데 유닛** — 아랫판 + 끝벽 2 + 뒤판을 목공본드로 (끝벽 Ø8 구멍에 고무 슬리브). 뒤판 창에 뒤판 출력물을 끼우고 바닥 탭 2개를 접시 8호 13 mm로: 왼쪽 (407, 322), 오른쪽은 J501 받침 앞으로 나온 혀의 (466, 311.5) — J501 받침 바로 밑(탭 뒤쪽)에는 드라이버가 닿지 않으므로 혀의 구멍을 씀. J501 기판은 그 뒤 받침 위에 MS 폴리머. 이음 레일·기둥 2개(M3 인서트를 먼저 인두로)를 뒤판 안면·아랫판에 MS 폴리머로. 보드는 받침 기둥에 먼저 나사(M3×5, Pi M2.5×6)로 단 뒤 기둥 밑을 아랫판에 MS 폴리머 (스스로 자리 잡음). 퓨즈 받침, 보조배터리 받침(접시 8호 13 × 4), 허브를 뒤판에 붙여 바닥에 놓고 허브 선반(받침 2를 뒤판에 Ø3 × 12 둥근머리 목재 나사 — 드라이버는 선반 윗면의 머리 길 홈을 따라 앞에서), 앰프를 선반 받침에(M3×6). 이 나사들은 모두 곧은 드라이버(Ø6 × 80)로 닿음 (check_body.py). XT30 집게 2개를 끝벽 안쪽 Ø14 구멍에 맞춰 MS 폴리머 (판 구멍과 끝벽 구멍이 같은 축), 끝벽 L 안면에 케이블 집게 2개(y262~282·286~306, z48~58). 뚜껑 자석 12개(극이 서로 당기게). 전원선·5.1 V선·스피커선 배선 (스피커선 L은 끝벽 집게에 끼우고 y256에서 끝벽을 떠나 보조배터리 앞을 건넘).
4. **책상에서: 건반 쪽** — 모듈과 끝 부속을 도브테일로 잇고, 볼 뒤 M3 자리에 방진 브래킷 BRK2 (그로밋 2 + M3×16 × 2, 스피커를 올리기 전에 조임). 모듈 USB-C 선을 꽂아 통로 자리(y212~241) 책상 위에 눕힘. 스피커 밑에 올 O1·O7 선과 EL·ER 리드·JST-XH는 이때 통로 안쪽으로 가지런히.
5. **가운데 유닛 놓기** — 모듈 뒤 2 mm 틈(y212~214)을 두고 놓음. 앞벽이 없어 앞 공간(y214~241)이 선 위로 옴.
6. **스피커 놓기** — EVA 3T 띠 2줄을 스피커 안쪽 옆판에 미리 붙임. 스피커를 브래킷 핀보다 약 10 mm 위, 제자리보다 약 15 mm 바깥에 들고, 꼬리의 XT30U-F를 입구(가운데 쪽)부터 끝벽 Ø14 구멍(L z44 · R z49.5)에 넣고 뒤끝을 드라이버 손잡이로 밀어 끝벽(11.5)과 집게 판(3)을 지나게 한 뒤, 가운데 안에서 잡아 집게 홈에 곧게 당겨 넣고 눌러 끼움(L은 홈과 구멍이 같은 축, R은 구멍이 1.5 낮음 - 둘 다 곧게 지나감). 스피커를 안쪽으로 밀어 EVA가 끝벽에 닿게 하면서 남는 꼬리(여유 약 35 mm)를 끝벽 구멍 안에 느슨하게 감아 넣고, 핀에 곧게 내려 끼움 (L 둥근 / R x 방향 긴 소켓, 핀 끝과 소켓 바닥 사이 2 mm). 가운데 안에서 M4 나비나사 2개씩 (머리는 고무 슬리브에만 닿음). 앰프 선 XT30U-M 꽂기 — 집게 홈에는 축 방향 멈춤이 없어(홈 뒤가 터널로 열려 있어야 스피커를 뗄 수 있음) 홈 안의 F에 M을 대고 밀면 F가 터널로 밀려 들어감: F를 홈 입구로 가운데 쪽에 당겨 꺼내고(꼬리 여유 약 35 mm), 손으로 M을 끝까지 꽂은 뒤, 짝을 다시 가져와 F 앞면을 홈 입구에 맞춰 위에서 걸림 턱 밑으로 눌러 끼움 (M은 입구 밖으로 나옴).
7. **선 정리** — 뚜껑을 모두 뗀 채 앞 공간에서 모듈 USB 선을 묶음(y237.5, 4층)으로 모아 허브 포트에 꽂음 (포트 2 PED, 3 O3, 4 O1, 5 O2, 6 O4, 7 O5, 8 O6, 9 O7; 짧은 O5·O6은 묶음 위 앞쪽 줄). 헤드폰 선 W701/W702는 왼쪽 볼 홈에서 통로 바닥을 따라 동글·J702로.
8. **터치스크린: 화면 → 받침 (책상 밖에서)** — 화면 ZIF(22핀, 입구 +x)에 FFC B형을 3.5 꽂고 잠금 → 입구에서 +x로 4 mm 뒤 45°로 말아 접음(R3, 날카롭게 꺾지 않음) → 리본 길 xr27.25~38.95(x638.25~649.95)를 따라 아래로, 누름 패드 자리(u8~16)에 캡톤 → MX1.25 전원선은 그 옆 xr40.45~43.45로 → 둘을 아래 트인 홈으로 빼고 화면을 받침에 넣음(굵은 테두리 9.65가 아래, 커넥터 창이 오른쪽, 유리 아래 끝이 아래 벽에 얹힘) → 뒤에서 M2.5×6 4개(구멍 깊이를 먼저 잼, 사양 G-2) → 점검창 덮개를 걸쇠가 걸리게 눌러 끼움 → 받침다리를 다리 걸이 볼 사이에 넣고 M3×20을 −x에서(육각 L렌치 2.0) 먼 볼에 탭 → 머리가 볼에 닿을 때까지 돌린 뒤 약 1/4바퀴 풀어 다리가 제 무게로 돌게 함 (PETG 탭 나사산 마찰로 풀리지 않음; 조이면 볼이 다리를 물어 아래 '받침다리 펴기'가 안 됨).
9. **터치스크린: 받침 → 화면 뚜껑** — 리본과 전원선을 뚜껑의 22 × 6 구멍(x635.35~657.35)으로 위에서 아래로 넣고(3핀 이음도 통과), 뚜껑 밑에서 리본을 밑면에 붙여 +y로 → 클립 덩어리 밑에 리본을 대고 전원선 2가닥을 클립 윗면 홈(x652.6~656.1)에 넣은 채 클립 핀 2개를 Ø3.1 구멍에 눌러 끼움 → 리본을 y270.5에서 45° 접어 −x로 x583까지 → 받침 귀 2개를 귀 홈에 넣고 M3×20을 바깥 가까운 볼에서(왼쪽 −x, 오른쪽 +x) 넣어 먼 볼 Ø2.5에 탭(물림 7.6) → 머리가 볼에 닿을 때까지 돌린 뒤 약 1/4바퀴 풀어 귀가 제 무게로 돌게 함 (PETG 탭 나사산 마찰로 풀리지 않음; 귀와 볼 사이 틈은 0.2씩뿐이라 조이면 화면이 25°로 돌아가지 않음).
10. **뚜껑** — 뚜껑 L·R (자석 3쌍씩). 화면 뚜껑은 얹기 전에 리본을 기둥 x583으로 내려 안 쓰는 micro-HDMI 위로 Pi 5 CAM/DISP 1(x589, 입구 −x)에 2.7 꽂고 잠그며, 점퍼를 GPIO 2번(빨강 5 V)·6번(검정 GND)에 꽂음 → 이음 레일 위에 얹고 M3×10 × 4 (자리파기 5.5, 머리 자리 z67.35; 양쪽 이음에 0.5씩 틈). 고무발(5)과 모듈 EVA(3)의 눌림 차이로 뚜껑이 건반 윗면과 ±0.5 어긋나면 얇은 받침으로 맞춤.
11. **받침다리 펴기·접기** — 화면을 22°(뒤꿈치가 멈춤 블록에 닿음)까지 앞으로 기울여 댄 채 다리를 내림: 다리가 수평 아래 약 40°에서 발이 경사에 먼저 닿고, 손을 놓으면 화면이 25°로 돌아가며 발이 경사를 타고 뒷벽까지 미끄러짐. 25°에서 그대로 내리면 발이 뒷벽 위 모서리를 약 0.66 긁음 (check_body.py가 22°·25° 두 경우를 돌려 봄). 접을 때도 22°에서 다리를 올려 받침 뒤 클립에 끼운 뒤 화면을 뒤로 눕힘.

## 분해·점검 (어느 것을 들어야 하나)

| 하려는 일 | 여는 것 | 방법 |
|---|---|---|
| 패드 바 | 없음 | 뒷바가 y214부터라 패드 바(y146.5~185) 위가 비어 있음 |
| O2·O3 모듈 | 뚜껑 L (자석) | 앞 공간에서 USB-C 부트를 위로 뽑고 모듈을 곧게 들어 올림 |
| O5 모듈 | 뚜껑 R (자석) | 같음 |
| O4 모듈 | 화면 뚜껑 (M3×10 4개, 화면째) | 사양 B (O4 정비): 화면을 뒤로 접고(다리는 클립에) → M3×10 4개(앞 y246, 뒤 y322)를 풂 → 뚜껑을 화면째 천천히 듦(리본을 꽂은 채 약 96 mm) → Pi 5 CAM/DISP 1 잠금 막대를 올려 리본을 뺌(화면 쪽 ZIF는 받침 안이라 건드리지 않음) → GPIO 2·6 점퍼를 뺌 → 뚜껑을 옆에 두고 앞 공간에서 플러그를 뽑음. 되돌릴 때 리본 B형 방향 확인 후 잠금, 점퍼 2번 빨강·6번 검정, 나사 4개 |
| O1·O7 모듈, EL·ER 끝 부속 | 그쪽 스피커 | 허브에서 선을 뽑고 스피커를 들어낸 뒤 (아래 줄), 모듈을 곧게 들어 올림 |
| O6 모듈 | 스피커 R (또는 뒷바 전체) | 플러그가 가운데 끝벽 R / 스피커 이음 밑 |
| 스피커 하나 | 뚜껑 L 또는 R | XT30 짝을 홈 입구로 가운데 쪽에 당겨 꺼내 손으로 XT30U-M을 뽑고 F는 다시 홈에 눌러 끼움 (홈에는 축 방향 멈춤이 없음 - 짝은 홈 밖에서 꽂고 뽑음) → 나비나사 2개 풀기 → 스피커를 약 10 mm 들어 핀에서 빼고, 통로 지붕 밑 케이블 집게에 끼운 선(EL·ER 리드·헤드폰 선)이 있으면 이때 모두 빼냄 (집게는 스피커에 붙어 있어 선이 같이 들림) → 약 15 mm 바깥으로 밂 (끝벽 구멍 안에 감긴 꼬리가 풀려 나오고 XT30U-F는 집게에 남음) → 가운데 안에서 XT30U-F를 집게 홈에서 끝벽 쪽으로 곧게 밀어 터널에 넣고(드라이버 손잡이로), 벌어진 틈에서 꼬리를 당겨 끝벽 구멍 밖으로 빼냄 → 스피커를 들어냄 (가로 다월 없음; check_body.py가 이 순서를 확인) |
| 뒷바 전체 | 뚜껑 L · 화면 뚜껑 (M3×10 4개, 화면째 - 위 O4 줄처럼 리본·점퍼를 Pi에서 뺌) · 뚜껑 R | 허브의 USB-A 7개(O1~O7; PED는 가운데 안이라 그대로)와 3.5 mm 플러그 2개(J702 x514~526, 동글 x644~656 — 둘 다 화면 뚜껑 아래)를 뽑고, 뽑은 플러그는 앞 공간(y<241)으로 옮겨 놓음 → 선은 모두 건반 쪽에 남아 통로에 놓임 → 뒷바를 곧게 들어 올림 (앞 공간은 아래가 열려 있어 선 위로 빠짐; W701/W702를 볼 쪽 끝에서 뽑아도 됨) |

## 예비 건반 칸 (R29) — 본체에서 뺌 (사용자 승인 2026-10-02)

뚜껑이 건반과 같은 높이라 안 높이가 44.85 (z16.5~61.35)뿐인데 예비 빗살 2층은 58.8 필요. 안폭 679도 전자부로 꽉 참. 칸을 두면 높이나 깊이가 커져 '큰 빈 공간 없게'에 어긋남. 대안:

- (a) 따로 출력하는 예비 부품 상자 약 210 × 180 × 65 (256 판에 반씩 2번), 모듈 가방과 같이 들고 다님
- (b) 가운데 뒤에 붙였다 떼는 보관 칸 (y342.5~약 510, 같은 나비나사 결합) — 붙였을 때만 깊이 +170

사용자가 보관 칸을 빼기로 했습니다(10/2). 대안 (a)·(b)는 이 모델에 없고, 필요해지면 만듭니다.

## 터치스크린 3판 (R31, Waveshare 7-DSI-TOUCH-C) — 부록 A10

사양: `hardware/mechanical/touchscreen/rev3/design/CAD_SPEC_rev3.md` (W1, 3a, 사용자 승인 2026-10-01) + `numbers.json` (자리 블록 = L2 값), 도면 `rev3/drawings/t01~t06`, 화면 치수 `touchscreen/screen_dims/ws_7-DSI-TOUCH-C-details-size.jpg`. 좌표 변환은 `src/touchscreen_rev3.py` 하나(받침 좌표 xr = x − 611, u = 유리 아래 끝에서 위로, w = 유리 앞면에서 뒤로; 경첩 축 (y226.55, z81.35) = 받침 (u-9, w13); 사용 25°, 뒤꿈치 22°, 접음 90°). 조립 파일에는 사용 상태(25°, 다리 폄)만 들어가고, 접은 상태(90°, 다리는 받침 뒤 클립)는 그룹 `터치스크린 (접은 상태, 별도 보기)`로 `stl/assembly/`에만 있습니다(한 파일 조립·3MF·GLB·뷰어에서 뺌).

| 부품 | id | 종류·파일 | 자리 (사용 상태, world) |
|---|---|---|---|
| CU 화면 뚜껑 (터치스크린 3판 경첩·다리 주머니·리본 구멍, 출력) | `CU-SCREENLID` | `CU화면뚜껑_터치3판__1개.stl` | x501.5~720.5 y214~342.5 z61.35~86.85 |
| 화면 받침(크래들) — Waveshare 7-DSI-TOUCH-C용 | `TS-CRADLE` | `화면받침_크래들__1개.stl` | x525.65~696.35 y216.61~276.81 z76.72~189.23 |
| 받침다리 | `TS-LEG` | `받침다리__1개.stl` | x606~616 y243.2~300.7 z69.36~118.21 |
| 점검창 덮개 (리본 접힘 자리 볼록) | `TS-WINCOVER` | `점검창덮개__1개.stl` | x625~657.5 y242.12~261.96 z117.21~153.4 |
| 리본 클립 (뚜껑 밑, 전원선 홈) | `TS-RCLIP` | `리본클립__1개.stl` | x631.35~661.35 y236.55~248.55 z58.05~65.55 |
| 화면 덮개 (선택, 접은 화면 위) | `TS-SCREENCOVER` | `화면덮개_선택__1개.stl` | x524.5~697.5 y232.05~340.05 z95.35~98.35 |
| M3×20 둥근머리 렌치볼트 (화면 경첩 축 왼쪽) | `TS-M3X20-HINGE-L` | 구매 | x536.95~558.6 y223.7~229.4 z78.5~84.2 |
| M3×20 둥근머리 렌치볼트 (화면 경첩 축 오른쪽) | `TS-M3X20-HINGE-R` | 구매 | x663.4~685.05 y223.7~229.4 z78.5~84.2 |
| M3×20 둥근머리 렌치볼트 (받침다리 축) | `TS-M3X20-LEG` | 구매 | x600.05~621.7 y243.36~249.05 z112.37~118.06 |
| M2.5×6 둥근머리 나사 (화면 모서리 구멍 1) | `TS-M25-1` (외 3) | 구매 | x531.76~536.25 y225.32~233.87 z93.44~99.91 |
| Waveshare 7-DSI-TOUCH-C 7인치 DSI 정전식 터치 화면 | `TS-E-SCREEN` | 전자 | x527.95~694.05 y218.57~268.51 z91.62~186.54 |
| DSI FFC 22핀 0.5 mm 300 mm B형 (GUOCONN, 화면 → Pi 5 CAM/DISP 1) | `TS-C-DSI` | 전자 | x582.85~652.2 y221.63~276.35 z25.85~137.1 |
| 화면 전원선 빨강 5 V (MX1.25 → 3핀 선 → 점퍼 → Pi GPIO 2번) | `TS-C-PWR-RED` | 전자 | x549.12~654.23 y222.4~317.02 z26.6~147.2 |
| 화면 전원선 검정 GND (MX1.25 → 3핀 선 → 점퍼 → Pi GPIO 6번) | `TS-C-PWR-BLK` | 전자 | x554.2~655.53 y222.4~317.02 z26.6~148.38 |

**주요 값 (numbers.json ↔ 모델)** — 측정은 `check_body.py` (4) · `check_electronics.py` (4)가 입체에서 다시 잽니다.

| 항목 | 사양 (numbers.json) | 모델 |
|---|---|---|
| 25° 받침 가장 앞 / 가장 높은 곳 / 가장 뒤 | y216.61 / z189.23 / y276.81 | y216.61 / z189.23 / y276.81 |
| 22° (뒤꿈치 멈춤) 가장 앞 — 금지선 y≤215·z≥72.85 | y216 | y216 (22~90° 휩쓸기 최소도 같음) |
| 25° 유리 아래 끝 / 위 끝 | (218.57, 95) / (261.26, 186.54) | y218.57 / z186.54 (화면 외곽) |
| 접은 받침 y / z | y233.05~339.05 · z78.35~95.35 | 같음 (뚜껑 뒤 y342.5까지 3.45, 스피커 윗면 z144.65까지 49.3) |
| 접은 뒤끝 여유 / 스피커 여유 | 2.45 / 52.71 (43° L2 값) | 3.45 / 49.3 (40°) |
| 귀 ↔ 멈춤 블록·홈 바닥 | 22°: 0 (닿음), 25~90°: ≥ 0.37 | check_body.py C-12 (0.5° 간격) |
| 받침다리 축 / 발끝 / 각도 | (246.2, 115.22) / (297.7, 72.35) / 39.78° | (246.2, 115.22) / 같음 / 39.78° (축~발끝 67) |
| 뚜껑 나사 M3×10 | 자리파기 Ø6.5 × 5.5, 머리 자리 z67.35, 끝 z57.35, 인서트 물림 4 | 같음 (끝과 인서트 구멍 바닥 z56.85 사이 0.5) |
| DSI FFC 길이 (300 mm B형) | 256.32 (여유 43.68) | 254.2 (여유 45.8; 접기 말림 여유 포함) |
| 전원선 (MX1.25 → GPIO 2·6) | 344.95 (있는 길이 500~550) | 약 346 (하우징·핀·꽂는 여유 포함) |
| 뚜껑 위 금지선 (모듈 위) | y≤215·z≥72.85에 아무것도 없음 | check_body.py C-16 · G, check_electronics.py (선 가장 앞 y≈221.6) |

**W1에 넘길 사양과 다른 점 (가장 작은 고침)**

| 사양 항목 | CAD가 만든 것 | 이유 |
|---|---|---|
| 자리 블록 뚜껑 x501~721 | x501.5~720.5 (CAD L2 뚜껑, 이음마다 0.5 틈) | 오꾸메 뚜껑 L·R과 틈 0이면 세 장이 나란히 들어가지 않음 (L2 설계). 화면 쪽 좌표는 모두 그대로; 받침과 뚜껑 끝 사이 24.15 (사양 24.65) |
| 자리 블록 뚜껑 뒤 y341.5, 스피커 윗면 z148.06, 스피커 y258.5, 소리 규칙 앞판 43° | 뚜껑 뒤 y342.5, 스피커 윗면 z144.65, 유닛 중심 y260 z100.45 (앞판 40°, 사용자 결정 2026-10-01) | W1 3판은 43° 값으로 계산. 화면 부품은 바뀌지 않고 여유만 바뀜: 접은 뒤끝 여유 2.45 → 3.45, 접은 윗면과 스피커 윗면 52.71 → 49.3, 화면을 지나는 소리 길(평면) 최소 248.58 → 247.93 (≥ 200), 다리 주머니 뒷벽 뒤 살 40.8 → 41.8, 27° 규칙 Ø94 아래 가장자리 (224.13, 70.2) → (224, 70.24), 모듈 뒤 윗모서리 위 3.53 → 3.5 (W1 ≥ 3.0) |
| A-7 앞 기둥 x496~506 · x716~726 (나사 x506·716이 기둥 안쪽 모서리 위; 'CAD가 기둥을 안쪽으로 2 옮기면 가운데') | x501~511 · x711~721 (CAD L2: 나사 밑이 기둥 가운데) | 기둥 폭 10이라 나사를 가운데에 두려면 5 옮겨야 함 (사양의 '안쪽으로 2'는 계산 실수). 인서트 L71 Ø4.5가 기둥 안에 다 들어감 |
| A-7 나사 자리 Ø8 기둥 | CAD L2 보스 10 × 12 (Ø8을 덮음), Ø3.4 + 위에서 Ø6.5 × 5.5 | L2 뚜껑 설계 그대로. 자리파기·머리 자리 z67.35·나사 끝 z57.35는 사양대로 |
| A 갈비 규칙 (배기 홈은 말 없음) | 갈비 x571·x651이 배기 홈 밑을 그대로 지남 | 판을 받치는 갈비를 끊지 않음 (홈 34 중 2 mm 가림, 출력은 갈비 면이 베드라 문제 없음) |
| A-9 출력 방향 (갈비 면을 베드에) | 그대로 - 자리만 잡은 판은 윗면을 베드에 두었으나 3판은 경첩 볼·발이 윗면에 있어 뒤집음 | (사양대로, 바뀐 점만 기록) |
| C-3 보스 자리파기 Ø5.5 (w11부터) | 물방울(꼭짓점 −u = 출력 때 위) 꼭짓점을 축에서 3.1로 평평하게 자름 (평평한 천장 폭 1.58) | 보스가 R4라 물방울 꼭짓점(3.89)까지 파면 살이 0.11만 남아 슬라이서가 지움 → 자르면 0.9 |
| C-10 아래 뒤 모서리 C2 ('경첩 볼과 0.59 이상') | C2.2 (모델 최소 틈은 check_body.py C-10, 90°에서) | C2면 3D로 90°에서 0.541 (W1 3D 모델도 0.541; 0.59는 2D 값) → C2.2로 키워 사양의 0.59 이상을 지킴. 귀 붙는 면(w8~13)은 그대로 |
| C-11 · C-17 뒤 패드 16 × 16, '45° 모따기로 서포트 없이' | 패드 +u 면(출력 때 아래를 향함)을 45° × 3 모따기 → 접혔을 때 받침 발에 얹히는 면 16 × 13 | 모따기를 밖으로 붙이면 접은 받침이 뒤 발의 턱(y322.05)에 걸림; 안으로 깎으면 턱과 1.5 이상 |
| C-15 다리 클립 몸 u87~93 (45° 모따기) | 몸 +u 쪽에 45° 받침을 붙임 (w20.72 → u100.72에서 뒷판) | 같은 이유 (출력 때 7.7 mm 내민 면). 접은 다리·뚜껑과 닿지 않음 (턱 끝 z73.63 그대로) |
| E-1 점검창 덮개 걸쇠 2개 (모양은 CAD 재량) | 끼움부 아래·위 끝의 xr 방향 탄성 보 (뿌리 xr18, 자유 끝 xr24, 두께 1 × 높이 2, 턱 밑 틈 0.5) + 끝 쪽 돌기 0.4 (w10.55~11.4, 45° 들어가는·빼는 경사), 뒷판 창 벽에 짝 홈 0.5 × 앞쪽 1 | 덮개만으로는 걸 곳이 없어 받침에 홈을 냄 (리본·ZIF·전원선 길과 떨어진 자리). 처음 만든 뒷판 쪽(w 방향) 혀는 길이 2.1에 끼움 0.2라 변형률 약 6.8% (PETG 항복 3~4%, 층을 가로질러 휨) → 출력 층 안에서 휘는 xr 방향 보로 바꿔 약 1.6% |
| E-1 끼움부 두께 = 뒷판 2.5 | w10.5~13 (사양대로) | W1 3D 모델은 w10.7부터 (2.3) - CAD는 사양 글을 따름 |
| C-12 귀 윤곽 profile_uw | 그대로, 붙는 면만 아래 벽 안으로 0.05 | 면이 겹치지 않게 한 몸으로 (모양 같음) |
| C-17 출력 (서포트 말 없음) | 아래 벽 앞 턱(w−1~10.5, 유리가 얹히는 면) 밑에 트리 서포트 | 윗변을 베드에 세우면 그 턱이 11.5 mm 내민 지붕이 됨 (유리 주머니 안, 앞이 트여 떼기 쉬움) |
| F 리본 (뚜껑 밑 45° 접기) | 날카로운 접기로 그림, 말아 접기 여유 9.42는 길이에만 더함; 접힌 겹은 0.27씩 겹쳐 한 몸 | 모델 표현 (실제 리본 모양과 같음) |
| F 전원선 (MX1.25 → 점퍼 → GPIO 2·6) | 두 부품 TS-C-PWR-RED / -BLK (Ø1.1, 간격 1.3), 끝마다 F 점퍼 하우징 | 가닥끼리 겹치는 불리언을 피함; 하우징은 CAD Pi의 헤더 상자(핀 끝까지 한 덩어리)와 겹침 = 의도 |
| F Pi 5 (micro-HDMI·방열판 추정 자리) | CAD Pi에 micro-HDMI 2개(x564.5~571.5 · 578~585, y262~269.5, 윗면 z27.3)를 더함; 방열판은 CAD Pi 모델 그대로(x563.5~578.5 y279.5~294.5) | 리본이 HDMI 1 위에 얹힘(틈 0). W1 추정 방열판 상자(x572~583 y276~293)면 리본이 닿지만(사양 G-8) CAD Pi 자세에서는 5.37 떨어짐 - 실제 Pi로 확인 |
| C-3 화면 모서리 구멍 (깊이 모름) | 화면 모델에 Ø2.2 × 4 (나사산 안지름) | M2.5×6 물림 3을 나사산 겹침으로 보이게 (추정) |

참고 (CAD와 다름이 아니라 W1 3D 모델 쪽): 다리 걸이 볼(C-13) 밑면은 사양·t03 B-B대로 45°, 뒷판 w13에서 u38.87까지 만듦. W1 `model3d/b1model.py`의 clevis_profile은 끝이 u35.37이라 밑면이 수평에서 20.6° (출력 때 서포트 필요) — 그쪽 모델만 고치면 됨.

**07_터치스크린 출력:**

- `화면받침_크래들__1개.stl` — 170.7 × 21.7 × 119.8 mm, 속 꽉 채움 86 g. 윗변(u103.5 면)을 베드에 세워 출력, 귀가 위 (높이 119.76, 사양 119.76). 귀 축·다리 걸이 구멍(x 방향)과 보스 구멍(w 방향)은 물방울(꼭짓점 위)로 뽑고 드릴로 다듬음(귀·가까운 볼 Ø3.3, 먼 볼 Ø2.5, 보스 Ø2.8; 보스 자리파기 Ø5.5는 물방울 위를 평평하게 자른 모양, 1.58 브리지). 다리 걸이 볼(밑면 45°, 뒷판에서 u38.87)·다리 클립·뒤 패드는 45° 면이라 서포트 없음; 가로 갈비·창 둘레 갈비·보스는 3 mm 이하 짧은 내민 면. 아래 벽(u−2.5~0)의 앞 턱 w−1~10.5(유리가 얹히는 면)는 출력 때 지붕이 되므로 그 밑(유리 주머니 안, 앞이 트여 떼기 쉬움)에만 트리 서포트. 약 86 g, 약 3.7시간(W1 추정)
- `받침다리__1개.stl` — 10 × 73 × 6 mm, 속 꽉 채움 5 g. 넓은 면(73 × 10)을 베드에 눕혀 출력(높이 6). 축 구멍 Ø3.3은 물방울(꼭짓점 위)로 뽑고 드릴 Ø3.3로 다듬음. 벽 4줄 이상(속 거의 꽉). 약 5 g, 약 20분
- `점검창덮개__1개.stl` — 32.5 × 39 × 5.9 mm, 속 꽉 채움 6 g. 끼움부 면(w10.5, 볼록 자리 속이 열린 면)을 베드에, 턱·볼록 자리가 위. 턱은 끼움부보다 1.7 내밀어 짧은 내민 면, 볼록 자리 천장은 13.7 브리지, 걸쇠 보 위 턱은 2 × 7 브리지 - 서포트 없음. 걸쇠 보는 벽 2줄(0.42) 이상으로 꽉 채움. 약 6 g
- `리본클립__1개.stl` — 30 × 12 × 7.5 mm, 속 꽉 채움 1 g. 넓은 면(30 × 12)을 베드에, 핀·전원선 홈이 위. 서포트 없음. 약 1 g
- `화면덮개_선택__1개.stl` — 173 × 108 × 3 mm, 속 꽉 채움 71 g. 선택 부품(접은 화면을 덮을 때만). 평판을 베드에. 약 70 g. 사용 상태 조립에는 없음(접은 상태 보기에만 있음)
- (05) `CU화면뚜껑_터치3판__1개.stl` — 219 × 128.5 × 25.5 mm. 갈비 면(z61.35)을 베드에, 윗면·경첩 볼·발이 위 (사양 A-9). 경첩 받침·구멍 벽·클립 덩어리·주머니 덩어리·나사 보스가 모두 베드까지 채워져 서포트 없음; 판은 갈비 위 브리지(갈비 간격 40 이하). 경첩 축 구멍(가까운 볼 Ø3.3, 먼 볼 Ø2.5)은 물방울(꼭짓점 위)로 뽑고 드릴 Ø3.3 / Ø2.5로 다듬음(먼 볼은 M3×20이 직접 탭). 클립 핀 구멍 Ø3.1 × 5는 베드 쪽에서 열림. 약 177 g

**조립 순서:** 아래 '조립 순서 (L2)'의 터치스크린 단계(화면 → 받침 → 화면 뚜껑 → 뚜껑 놓기 → 받침다리). O4 정비는 '분해·점검' 표.

**받은 부품으로 확인할 것 (사양 G, 출력 전에):**

- **커넥터 방향 (G-1):** 화면 앞에서 커넥터 창이 오른쪽, 입구 +x로 모델함. 반대면 창·홈·구멍·클립을 x611 기준으로 뒤집고 리본은 A형(약 200 mm).
- **M2.5 구멍 깊이 (G-2):** 물림 = min(깊이 − 0.5, 4), 최소 2. 3.5보다 얕으면 와셔. 모서리가 박힌 스터드면 보스를 Ø6.2로 w13.7까지 팜(사양 G-2).
- **뒤 볼록판 높이 (G-3):** 2.1로 모델(뒷판과 0.4). 더 높으면 뒷판 안쪽 면 = 8.0 + 높이 + 0.4로 다시 계산.
- **Waveshare 3핀 선 길이 (G-4):** 120.54 mm 이상이면 이음이 뚜껑 밑, 짧으면 경첩 고리 안 → 열수축튜브.
- **리본 길이 (G-5):** 받침·뚜껑 출력 전에 폭 12 mm 종이띠로 길을 잼. 모델 254 / W1 256 / 케이블 300.
- **뒤꿈치 틈 0.37 (G-6):** 출력 공차와 비슷 - 다리 발이 주머니에 잘 안 들어가면 뒤꿈치를 0.3 깎음.
- **화면 아래 끝 돌기 (G-7):** 위치(xr54.99~59.24 추정)와 높이(약 0.85)를 잼. 홈 xr48~66 밖이면 홈을 옮김.
- **실제 Pi 5 (G-8):** micro-HDMI 윗면 높이(z27.3 추정)와 리본이 그 위로 입구에 들어가는지, CAM/DISP 1 깊이(꽂는 길이 2.7), 방열판이 리본 기둥 x582.85~583.15를 비키는지(CAD Pi 모델 방열판은 5.37 떨어짐, W1 추정 상자는 닿음).
- **레일 인서트 길이 (G-9):** 4로 모델 = 구매 목록 L71 (M3x4x4.5, 높이 4) — 자리파기 그대로. 다른 인서트로 바꾸면 자리파기 = 11.5 − (10 − 인서트 물림)으로 다시.
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

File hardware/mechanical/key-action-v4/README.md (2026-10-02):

# 건반 액션 v4 — W1+ (짧은 시소 건반 + 무게 레버)

v3의 리프 건반을 대신하는 새 건반 구조입니다. 이 폴더는 2026-09-27~29의 설계 기록입니다.
- **4차(r4.3):** 1차 완성본
- **r4.4:** 남은 문제 해결, 회로 세션 요청 반영
- **r4.5:** 비틀림 스프링을 미스미 기성품으로 교체

관련 자료
- 통합 아티팩트(보고서·도면·재료 선택·회로도): https://claude.ai/artifact/4GRdsojXgi8FT78uvbj5Df
- 발행 원본: [`docs/report/toccata-v4/`](../../../docs/report/toccata-v4/)
- 전자부: [`hardware/pcb/`](../../pcb/)
- 재료·비용: [`hardware/bom/`](../../bom/)

## 왜 바꿨나

v3는 PETG 리프 하나가 회전축과 복귀 스프링을 함께 맡았습니다. 쉬는 동안에도 약 6 MPa로 휘어 있어서, 오래 두면 처지고 건반 무게가 줄어드는 것이 1순위 위험이었습니다.

v4는 그랜드 피아노나 디지털 피아노처럼 **무게로 돌아오는** 구조입니다. 건반과 레버가 모두 금속 봉 위에서 돌고, 쉬는 자세는 펠트 위에 무게가 얹혀 정해집니다. 늘 휘어 있는 플라스틱이 없습니다.
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

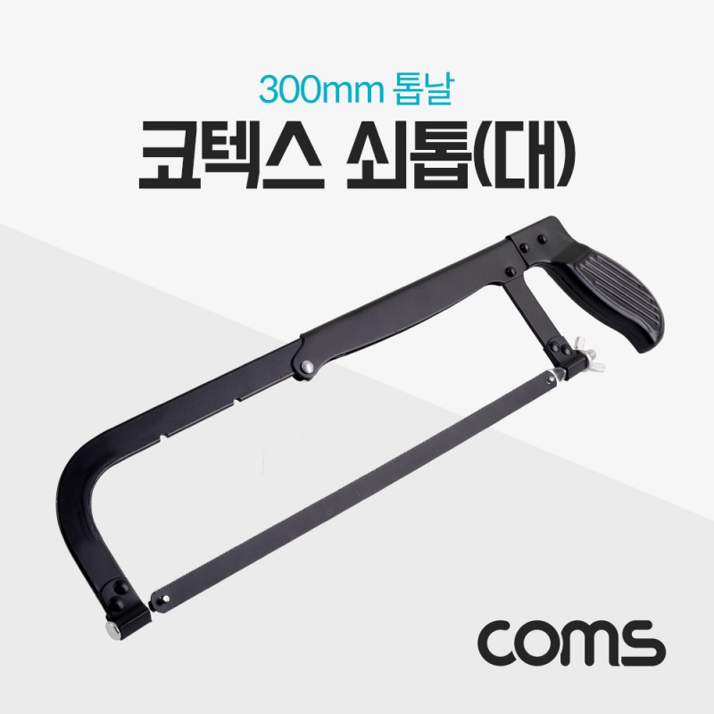
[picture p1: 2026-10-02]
hardware/mechanical/key-action-v4/report/r3-progress/img/hacksaw_frame.jpg

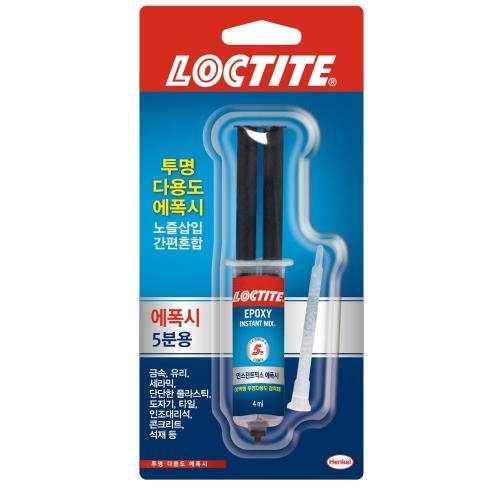
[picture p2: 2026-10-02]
hardware/mechanical/key-action-v4/report/r3-progress/img/epoxy_loctite.jpg

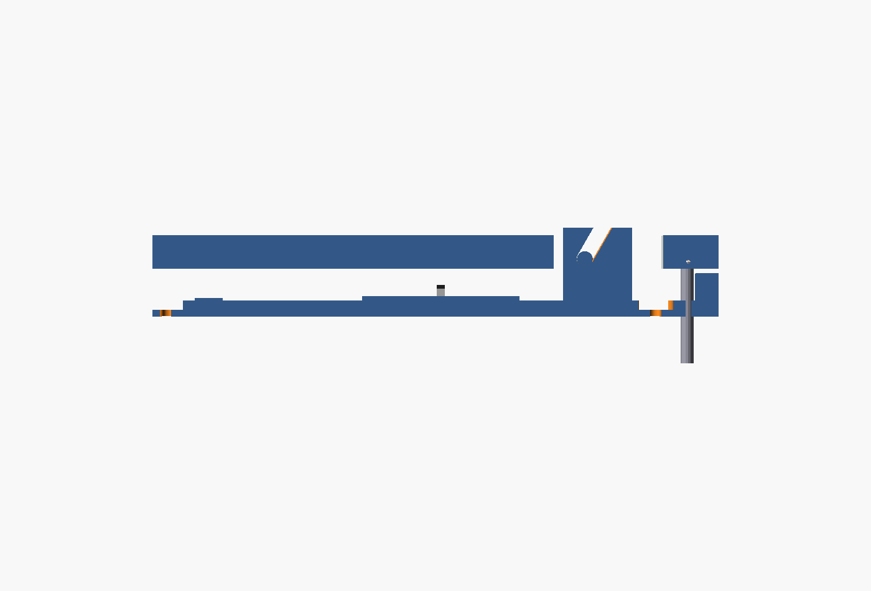
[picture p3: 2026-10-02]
hardware/mechanical/before/cad/renders/v1.5-multipart/section.png

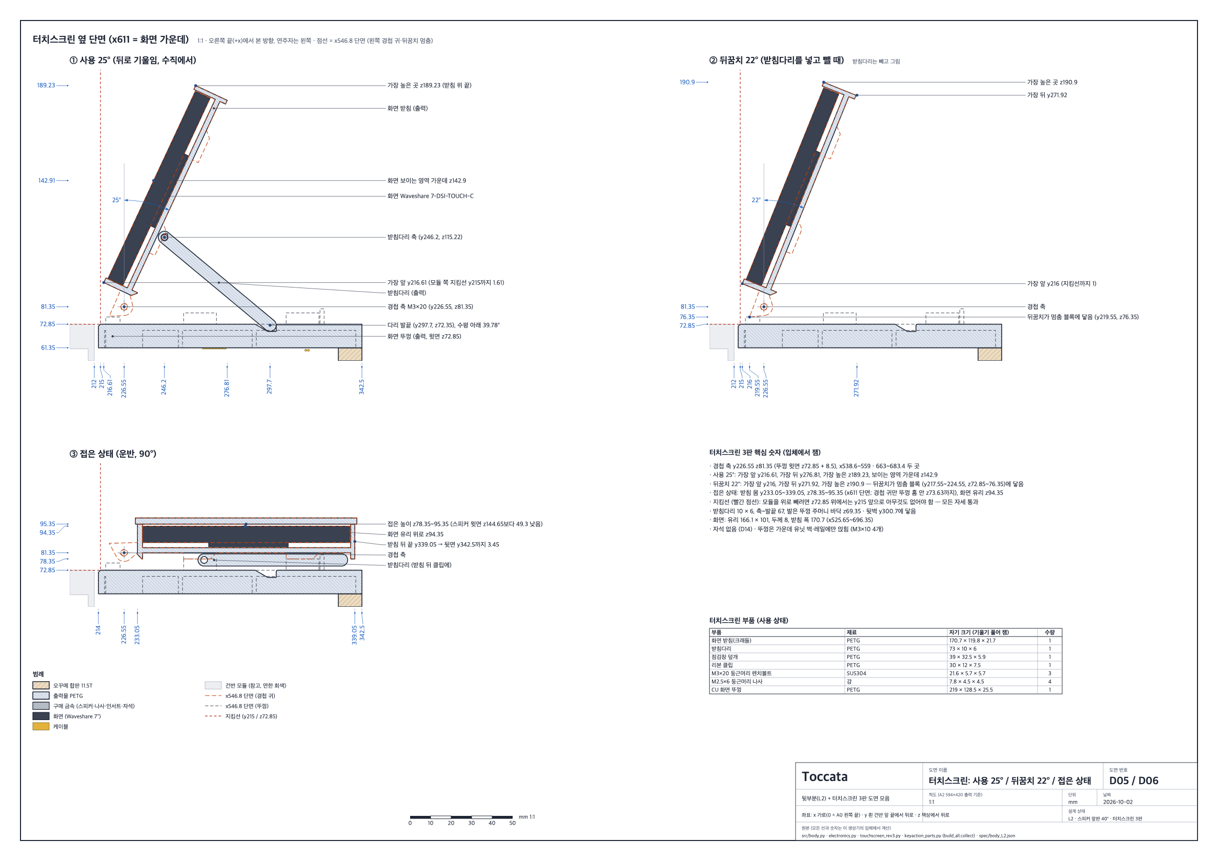
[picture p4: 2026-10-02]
docs/report/toccata-v4/rear/D05_touchscreen.png

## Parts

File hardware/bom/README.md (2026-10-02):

# 재료 목록과 비용 (v4)

구매 목록은 v3.2 목록과 사용자가 고른 절감 22개를 기준으로 합니다. 여기에 다음을 반영했습니다(2026-09-29).
- v4 건반 액션 r4.5 설계의 부품
- 회로 세션의 줄 변경(칩 콘덴서·저항 새 줄, 핀헤더 9줄 등)
- 미스미 스프링, 강철 블록 접착제, 경선용 니퍼

## 합계 (2026-10-02, VAT·배송비 포함)

> 이 표는 **전체 구매 목록**(가진 부품·공구·예비 포함)입니다. 실제로 살 금액은 사용자가 가진 부품과 예비를 뺀 [최종 재료 페이지](https://claude.ai/artifact/9CJ3HwhbhoodCAui94g28n) 기준이고, 9/30 653,781원 → 터치스크린·L2 반영 약 73만 원입니다.

| 구분 | 현재 목록 | v4 부품 추천 절감 적용 |
|---|---|---|
| 기본 구성 (한도 100만 원) | 754,492원 | 742,512원 |
| 소모품 | 229,536원 | 224,786원 |
| 공구 | 150,149원 | 124,260원 |
| **합계** | **1,134,177원** | **1,091,558원** |

- 선택기 화면에서는 기본과 공구 금액이 엑셀과 몇천 원 다르게 보일 수 있습니다. 기본 부품과 공구를 함께 파는 판매처의 배송비를 어느 쪽에 넣느냐의 차이이고, 합계는 같습니다.
- r4.3 목록(1,004,815원)에서 늘어난 몫은 다음과 같습니다.
  - 회로 줄 변경 +7,722원
  - 스프링 +8,000원
  - 강철 블록 접착제(세메다인 슈퍼X 20 mL × 2) +19,000원
  - 경선 니퍼 +21,989원
  - 중복 캡스턴 너트 제거 −1,056원
  - R30·CAD L1(뒷바 낮춤): 고무발 나사 25 mm ×14 → 13 mm −280원(받침 4 mm가 없어져 25 mm는 스피커 상자 안으로 뚫고 나옴)
  - 9/30 판매처 변경(사용자): 그로밋 → 알씨뱅크 4,500원(+1,460), 205본드 → 나비엠알오 3,949원(−1,391, 11번가 배송비 빠짐), OHP 필름 → 나비엠알오 2,739원(−3,241; 두께 표기 없음, 받으면 0.1 mm 확인)
  - **R31 터치스크린 +86,674원 (9/30 추가, 10/1 사용자 선택 B1):** Waveshare 7-DSI-TOUCH-C 7인치 가로 DSI 79,900(G마켓 해외직구) · 22핀 0.5 mm 300 mm FFC B형 5개 1,955 + A형(보험) 5개 1,975(엘레파츠) · 실리콘 점퍼 20 cm 4가닥 1,804(엘레파츠) · M3×20 ×4 400 · M2.5×6 ×4 400(추정) · L34 M3×10 +4 240. 9/30의 공식 TD2 7인치 묶음(103,600원)을 대체. 비교 13조합: `hardware/mechanical/touchscreen/compare/`
  - **L2 한 몸 뒷바 + 터치 3판 (10/1) −10,730원:** 600×1200 합판(L63)·토글 래치(L64)와 철물박사 배송비 빠짐, 직결피스 16 mm(스피커 유닛 몫) 빠짐 → 스피커 앞판 M4 열압입 인서트 + M4×12 각 8(+예비), 화면 뚜껑 레일 M3 열압입 인서트 4(+예비), 스피커↔가운데 M4 손잡이볼트·목재 퀵서트·실리콘 튜브 슬리브, ㄱ자 C-C 0.5 m(보조배터리, 개별배송 3,000), Pi 전원 측면꺾임 선(BT663), 허브 업스트림 꺾임 선(NA977), 받침 기둥 M3×5·브래킷 M3×16 등 CAD README "구매 목록에 없는 것" 반영. 나비엠알오는 공급가 5만 원 이상이라 배송비 무료가 됨. M3×10 54 → 28, 직결피스 13 mm 54 → 20. CAD v16 답(10/1)으로 ①~⑤ 정리: 목재 퀵서트 전장 10 → Norelem 07653-04(M4 · 길이 6, 1,749원 ×5, +5,885원, 10/26 출하), 허브 업스트림 선은 Pi GPIO 쪽 아래 USB-A, 허브 DC 플러그는 32 mm 이내면 곧은 것 그대로, 스피커 유닛 볼트는 M4×12 이하. 근거: `hardware/mechanical/cad/spec/body_L2.json`, `cad/README.md` 10/2: 보조배터리 선 C22를 주파집 ㄱ자(4,270 + 개별 배송비 3,000, 엘레파츠 무료배송 합계 밖) → Coms NC888 꺾임 C–C 1 m(2,600, 일반 배송)로 바꿈 −4,670원(CAD: 배터리 USB-C 중심이 바닥에서 약 15.5 mm 이상이면 들어감).
- 강철 블록 접착제는 **MS 폴리머 탄성 접착제**(세메다인 슈퍼X 흰색 20 mL × 2, 11번가)입니다. 데이터시트 전단 강도는 PET 2.8 MPa, 연강 4.8 MPa로, 설계값 1.5 MPa보다 큽니다.
  - 투명 제품은 PET에서 0.9 MPa라 쓰지 않습니다.
  - 5분 에폭시는 온도 변화에 떨어져서, 선택기에 '설계와 맞지 않음'으로 남겨 두었습니다.
- 3차 설계 그대로였다면 기본 구성이 942,134원으로 한도에 거의 닿았습니다. 4차에서 레일, 손나사, 접시 스프링, 탭 띠, 경화 샤프트 등이 빠져 줄었습니다.

## 파일

| 경로 | 내용 |
|---|---|
| `toccata-purchase-list-v4.xlsx` | 판매처별 구매 목록. 파란 글씨(가격·수량·O/X)만 고치면 소계·합계가 다시 계산됩니다. "v4 상태", "가격 확인" 열이 있습니다. 같은 파일이 `docs/report/`에도 있습니다 |
| `v4-parts-list.json` | 4차 모델의 부품 목록(출력·구매, 모듈당·88건반 수량, 규격, 질량) |
| `price-research/v4-r3-parts-prices.json` | 3차 설계 v4 부품 21종의 판매처 조사. 현재안과 대안마다 링크, 가격, 배송비, 사진 파일 이름, 검증 여부, 장단점이 있습니다. 링크 98개 중 87개를 다시 열어 확인했습니다 |
| `price-research/v4-r4-parts-prices.json` | 4차에서 새로 생기거나 바뀐 8종 조사, 그대로 쓰는 5종과 빠진 11종 목록 |
| `cost-selector/costsel.html` | 부품마다 현재 목록 / 더 싼 대안 / 사용 안함을 고르는 선택기 페이지. 통합 아티팩트의 07 탭과 같습니다 |
| `cost-selector/*.py` | 생성기. `build_data.py`(기존 부품 카드), `build_v4r4.py`(v4 부품 카드와 묶음 선택), `gen_sel.py`(페이지), `build_xlsx_v4.py`(엑셀) |
| `final-bom/` | 최종 재료 아티팩트(https://claude.ai/artifact/9CJ3HwhbhoodCAui94g28n) 생성기와 데이터. `base.json`은 구매 목록 v4(2026-09-29) 줄이고, `results.json`은 품목별 위치·규격·사진·배송 조사 결과(에이전트 조사 + 검증)입니다. 수정 규칙(구간 단가·최소 주문·추가 품목)은 `overrides.json`에 있습니다. `python3 build.py results.json`을 실행하면 `site/`가 만들어집니다. 도면 이미지는 `raster/`에 있고, 다시 만들려면 `raster.py`와 원본 SVG(`views/`, 이 폴더에는 없음)가 필요합니다. 사용자가 고친 수량과 끄기 상태는 아티팩트 db의 `state/main` 문서에 저장됩니다 |
| `parts-list/` | `docs/report/toccata-parts-list.xlsx`(핵심 부품 목록 v6) 생성기. 이 폴더에서 `python3 build_xlsx.py toccata-parts-list.xlsx` 뒤 xlsx 스킬의 `recalc.py`. `rows.json`은 `collect.py`가 구매 목록(`docs/report/` 쪽)과 선택기 데이터에서 뽑은 값입니다. 2026-09-29에 r4.5 구매 목록으로 다시 뽑았습니다(스프링 22.3 / 8.0, MS 폴리머 접착제 추가, 핀헤더 소켓 삭제, 1206 1 kΩ 추가). 합계 832,909원(9/30: 그로밋 → 알씨뱅크 M3 댐퍼, 오공 205·OHP 필름 → 나비엠알오, R30 L1 고무발 피스 25 mm → 13 mm) |

## 선택 코드로 목록 고치기

통합 아티팩트(https://claude.ai/artifact/4GRdsojXgi8FT78uvbj5Df)의 **07 재료·절감 선택** 탭에서 고른 뒤 "선택 코드 복사"를 누릅니다. 나온 코드(`카드=옵션; …`)를 Claude에게 주면 이 엑셀을 다시 만듭니다.

## 주의

- 생성 스크립트는 작업 세션의 임시 폴더에 있던 데이터를 읽습니다: 이전 절감안 데이터, 부품 사진, v3 보고서 카드. 그래서 그대로 다시 실행하려면 경로를 맞춰야 합니다.
- 가격이 "미확인"인 줄은 주문 전에 다시 확인합니다. 레이저 재단 견적, 점검 중이던 한국미스미, 로봇 확인에 막힌 알리익스프레스, 동네 철공소가 여기에 해당합니다.
- 토션 보조 스프링은 2026-09-28부터 한국미스미 경제형 기성품 C-UA90R5-3-0.5를 씁니다(100개 이상 개당 282원 + VAT, 100개 31,000원). 두 다리를 **22.3 / 8.0 mm**로 잘라 씁니다(r4.5 고침: 짧은 다리를 가둠 홈에 넣음). 구매 목록, 선택기, 부품 목록(`docs/report/toccata-parts-list.xlsx`)에 모두 반영했습니다. 직접 감기는 대안으로 남겼습니다.
- USB-C 케이블(C04)은 지금 NA993을 씁니다. 몰드 두께가 공개되지 않아 단계 0에서 꽂아 확인합니다. 세 치수가 공개돼 확인된 선은 CVILUX DH-20M50052(디지키)이고, 선택기에 대안으로 있습니다. 조사 결과는 `price-research/usb-c-cable.json`에 있습니다.

## 판매처 묶기 조사 (2026-09-30)

사용자 확정 목록(아티팩트 db `state/main`, 68개 품목, 654,061원)으로 판매처별 배송비를 줄일 수 있는지 조사했다. `final-bom/consol/`에 조사 결과(`A/B/C_out.json`)와 최적화 계산(`opt.py`, scipy MILP: 품목마다 판매처 하나를 고르고 무료배송 기준을 넣어 물건값 + 배송비 최소)이 있다.
- 옮긴 것: 오공 205 → 나비엠알오(−1,391원), OHP 필름 → 나비엠알오(−3,241원). 합계 658,693 → 654,061원.
- 배송비를 몰랐던 골드그로브·핑블샵·동진나무공장·한국미스미는 모두 무료배송으로 확인했다.
- 나머지는 옮기면 더 비싸거나 같은 사양이 없다(미스미 샤프트·핀·볼트, 나비엠알오 대포장, 철물박사 100,000원 기준, 엘레파츠 Pi 5 2GB 없음 등).

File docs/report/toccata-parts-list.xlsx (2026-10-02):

Toccata 부품 목록 — 프로젝트 제작에 필요한 부품 (배송비 · 공구 · 2단계 게임 · 소프트웨어 · 페달 제외)
기준: 2026-09-29 현재 설계 — 건반 액션 v4 W1(r4.5: 시소 건반 + 무게 레버) + v3.2 센서·전자·오디오·본체. 가격은 판매처 페이지 확인값(2026-09-24~28, VAT 포함, 원). 3D 프린터는 포함하지 않는다.
사용법: 파란 글씨(수량·단가)만 고치면 예상 가격·소계·합계가 다시 계산된다. 예상 가격 = 수량 × 단가. 구매 링크는 한 번 누르면 열린다. 굵은 글씨 = 핵심 부품(1번 묶음 맨 위 Raspberry Pi 5, 2번 묶음 맨 위 RP2040-Zero · 홀센서 · MUX).
No | 부품명 | 수량 | 용도 | 단가(원) | 예상 가격(원) | 구매 링크 | 판매처 · 상품명 (참고)
1. 제어 · 전원 (핵심)
1 | Raspberry Pi 5 (2GB) | 1 | 피아노 음원(FluidSynth)과 리듬게임을 돌리는 중앙 컴퓨터 | 119900 | 119900 | https://www.icbanq.com/P016286897 | 아이씨뱅큐 · Raspberry Pi 5 2GB (라즈베리파이 5 2GB Raspberry pi 5)
2 | USB 허브 10포트 (전원형) | 1 | 모듈 7 + 페달을 Pi 5 한 포트로 모음 | 30700 | 30700 | https://prod.danawa.com/info/?pcode=29865749 | 다나와 최저가 (쿠팡 로켓배송) · 이지넷유비쿼터스 NEXTU 유우젠 710U3 (10포트/USB 3.0, 유전원)
3 | PD 트리거 모듈 (HUSB238) | 1 | USB-C 전원 입력 → 20 V | 4950 | 4950 | https://www.icbanq.com/P017179277 | 아이씨뱅큐 (제노) · 100W QC PD 트리거 디코이 고정출력 모듈 5V-20V (HAM6113, HUSB238)
4 | 강압 모듈 XL4016 | 1 | 20 V → 5.1 V (Pi 5 · 허브 전원) | 5170 | 5170 | https://www.icbanq.com/P017179502 | 아이씨뱅큐 (제노) · 200W XL4016 DC-DC 강압 컨버터 모듈 IN 4-40V OUT 1.25-36V 5A (HAM6415, XH-M401)
5 | microSD 32GB (SanDisk Ultra) | 1 | 운영체제 · 음원 · 게임 저장 | 15490 | 15490 | https://prod.danawa.com/info/?pcode=20358155 | 다나와 최저가 판매처 · SanDisk micro SD Ultra 2022 32GB (SDSQUA4-032G-GN6MA)
6 | Pi 5 방열판 (4개 세트) | 1 | Pi 5 칩 방열 | 1400 | 1400 | https://www.mechasolution.com/goods/goods_view.php?goodsNo=605179 | 메카솔루션 · 라즈베리파이5 방열판 / 5B 전용 / 알루미늄 (4개 세트)
7 | 로커 스위치 | 1 | 피아노 전원 스위치 | 385 | 385 | https://www.eleparts.co.kr/goods/view?no=32569 | 엘레파츠 · [ZX Electronics] KCD1-101A BLACK I/O 로커 스위치 (2P ON-OFF, 6A 250VAC / 10A 125VAC)
8 | 퓨즈 홀더 (5×20 mm) | 1 | 20 V 선 보호 | 1110 | 1110 | https://www.eleparts.co.kr/goods/view?no=3237821 | 엘레파츠 · [Coms] BU914 원형 휴즈 홀더 (5×20 mm, 인라인)
9 | 퓨즈 5 A 지연형 (5개) | 5 | 퓨즈 1 + 예비 4 | 110 | 550 | https://www.eleparts.co.kr/goods/view?no=12766820 | 엘레파츠 · [LITTELFUSE] 0218005.MXP 5 A 지연형 퓨즈 5×20 mm
10 | 65 W PD 충전기 | 1 | 벽 전원 (보조배터리 대신 쓸 때) | 19800 | 19800 | https://prod.danawa.com/info/?pcode=59074565 | 다나와 최저가 판매처 · 파워마스터 PD PPS 65W 3포트 GaN 접지형 충전기 PG65PDG2C1A (케이블미포함)
 |  |  | 제어 · 전원 (핵심) 소계 |  | 199455
2. 센서 · MCU · 기판
11 | RP2040-Zero 마이크로컨트롤러 | 8 | 모듈 7 + 페달 1: 센서 읽기 · 세기 계산 · USB-MIDI | 3300 | 26400 | https://parts-parts.co.kr/product/detail.html?product_no=2383 | 파츠파츠 (동신전자) · (PP-A799-2) 라즈베리 파이 피코 PICO RP2040-ZERO
12 | 홀센서 TI DRV5055A2 | 100 | 건반마다 1개, 건반 위치 측정 (88 + 페달 1 + 예비) | 891 | 89100 | https://www.icbanq.com/P018076669 | 아이씨뱅큐 (LCSC 해외 재고) · TI DRV5055A2QLPG (TO-92-3 Linear Hall Effect Sensor, LCSC 경유)
13 | 네오디뮴 자석 Ø5×2 N35 | 100 | 건반 밑면에 1개씩, 센서가 읽는 자석 | 80 | 8000 | https://dgmagnet.com/product/%EC%B4%88%EA%B0%95%EB%A0%A5-%EB%84%A4%EC%98%A4%EB%94%94%EC%9B%80-%EC%9B%90%ED%98%95%EC%9E%90%EC%84%9D-5mm/13/ (https://dgmagnet.com/product/초강력-네오디움-원형자석-5mm/13/) | 대건상사 · 초강력 네오디움 원형자석 5mm (Ø5×2.0T, N35)
14 | 16채널 MUX 모듈 (CD74HC4067) | 7 | 센서 12 + 끝 부속 4를 ADC 1개로 차례로 읽음 | 500 | 3500 | https://parts-parts.co.kr/product/detail.html?product_no=303 | 파츠파츠 (동신전자) · (PP-A324) 16채널 아날로그/디지털 멀티플렉서 모듈
15 | 만능기판 5×7 cm | 8 | 모듈 제어 기판 7 + 페달 보드 1 (W1: 앞쪽 핀 홈 자리 비움) | 520 | 4160 | https://www.mechasolution.com/goods/goods_view.php?goodsNo=329798 | 메카솔루션 · PCB기판/양면기판/에폭시/프로토보드 (5x7cm)
16 | 만능기판 12×18 cm | 2 | 센서 기판 띠로 잘라 씀 (모듈 7 + 끝 부속 2) | 2200 | 4400 | https://www.mechasolution.com/goods/goods_view.php?goodsNo=540645 | 메카솔루션 · PCB기판/양면기판/에폭시/프로토보드 (12x18cm)
17 | 칩 콘덴서 100 nF (1206) | 100 | 센서마다 전원 잡음 제거 + MUX (97개 사용) | 44 | 4400 | https://www.icbanq.com/P014968846 | 아이씨뱅큐 (LCSC 해외 재고) · Samsung CL31B104KCFNNNE (1206 100nF 100V X7R)
18 | 칩 콘덴서 10 µF (1206, 50개) | 1 | 센서 기판 양 끝 · 끝 부속 전원 안정 (16개 사용, 회로도 △1·△3) | 7150 | 7150 | https://www.icbanq.com/P001248090 | 아이씨뱅큐 (오렌지반도체) · C3216-10UF(K 16V) — 1206 10 µF 16 V 칩 세라믹 콘덴서 (50개 단위)
19 | 핀헤더 1×40 | 9 | MUX 모듈 7개 · RP2040-Zero 8개 핀 헤더 (312핀 → 9줄) | 165 | 1485 | https://www.icbanq.com/P005666127 | 아이씨뱅큐 · 핀헤더 1×40 - 2.54MM(S/T) _ 11.5MM(1단몰드)
20 | 저항 1 kΩ (10개) | 10 | 앰프 입력 저음 차단 R701·R702 · 페달 R501·R551 (4개 사용) | 25 | 250 | https://www.eleparts.co.kr/goods/view?no=10911 | 엘레파츠 · [ABCO] CFR 1/4W 5% 탄소피막 저항 1kΩ (10개 단위)
21 | 저항 100 kΩ (10개) | 10 | 제어 기판 EXT 풀다운 R301~R303 · 페달 R502 (5개 사용) | 25 | 250 | https://www.eleparts.co.kr/goods/view?no=10993 | 엘레파츠 · [ABCO] CFR 1/4W 5% 탄소피막 저항 100kΩ (10개 단위)
22 | 저항 10 kΩ (10개) | 10 | 예비 | 25 | 250 | https://www.eleparts.co.kr/goods/view?no=10951 | 엘레파츠 · [ABCO] CFR 1/4W 5% 탄소피막 저항 10kΩ (10개 단위)
23 | 저항 100 Ω (10개) | 10 | 페달 링 급전 20 Ω (5개 병렬) | 25 | 250 | https://www.eleparts.co.kr/goods/view?no=10873 | 엘레파츠 · [ABCO] CFR 1/4W 5% 탄소피막 저항 100Ω (10개 단위)
24 | 칩 저항 1 kΩ (1206, 10개) | 10 | 끝 부속 EL · ER 입력 직렬 저항 R401~R403 · R411 (기판 밑면, 4개 사용, 회로도 △13) | 44 | 440 | https://www.icbanq.com/P011433924 | 아이씨뱅큐 (element14 해외 재고) · Yageo RC1206JR-071KL — 1206 1 kΩ 5 % 1/4 W 칩 저항
 |  |  | 센서 · MCU · 기판 소계 |  | 150035
3. 건반 액션 (W1: 시소 건반 + 무게 레버)
25 | 강철 평철 9T×19 (1 m 맞춤 재단) | 4 | 무게 레버 강철 블록 90개 (40 mm씩 잘라 씀, 개당 53.7 g) | 8610 | 34440 | https://www.allsteelshop.com/product/squareplate/9t | 올스틸샵 · 사각철판 9T (SS275) 19×1000 맞춤 재단
26 | 스테인리스 봉 Ø4 (1 m) — 건반 봉 | 2 | 건반 시소의 축 (모듈 7 + 끝 부속 2 + 예비 1 토막) | 1500 | 3000 | https://www.11st.co.kr/products/1304631510 | onezaze · [onezaze] 스텐환봉 절단판매 1M (4mm)
27 | 스테인리스 봉 Ø4 (1 m) — 레버 봉 | 2 | 무게 레버가 매달리는 축 (건반 봉과 같은 봉) | 1500 | 3000 | https://www.11st.co.kr/products/1304631510 | onezaze · [onezaze] 스텐환봉 절단판매 1M (4mm)
28 | 캡스턴 나사 M3×6 버튼헤드 (SUS) | 100 | 건반 꼬리에서 레버를 들어 올리는 나사, 높이 조정 (88 + 예비) | 11 | 1100 | https://www.icbanq.com/P015973844 | 아이씨뱅큐 · AOFENG ISO7380 M3-0.5X6 304 (Hex socket pan head cap screw)
29 | M3 육각 너트 (강철) | 100 | 캡스턴 나사 너트 96 + 스피커 브래킷 4 | 11 | 1100 | https://www.icbanq.com/P015976209 | 아이씨뱅큐 (LCSC 해외 재고) · XHHD 육각너트 M3 강철 (LCSC C133377)
30 | 밸런스 핀 Ø2×12 (SUS, 100개) | 1 | 건반 뒤쪽 좌우 위치를 잡는 핀 (88 + 예비) | 16600 | 16600 | https://www.nasakorea.com/goods/goods_view.php?goodsNo=6009 | 나사코리아 nasakorea.com · 다올핀 M2*6~20 STS304 GB119.1(ISO2338) — 옵션 2*12/100개/스텐STS304
31 | 비틀림 스프링 미스미 C-UA90R5-3-0.5 (기성품) | 100 | 레버마다 1개 (88 + 예비 12) — 두 다리를 22.3 / 8.0 mm로 잘라 끼움 (r4.5) | 310 | 31000 | https://kr.misumi-ec.com/vona2/detail/110310556289/?HissuCode=C-UA90R5-3-0.5 | 한국미스미 · 한국미스미 경제형 토션스프링 C-UA90R5-3-0.5 (SUS304-WPB, 내경 5 · 선경 0.5 · 3권 · 암 각 90° 오른쪽 감기, 암 50/50)
32 | 양모 펠트 2 mm (20×30 cm) | 1 | 캡스턴 띠 · 앞 멈춤 · 키퍼 펠트 | 13800 | 13800 | https://studiobunt.com/product/detail.html?product_no=4117 | 스튜디오분트 · 100% 메리노양모 70수 펠트지 2mm 20×30cm (35 블랙)
33 | 양모 펠트 1 mm (20×30 cm) | 1 | 업스톱 패드 윗면 · 쉼 펠트 (0.5T와 겹쳐 1.5T) | 6900 | 6900 | https://studiobunt.com/product/detail.html?product_no=1157 | 스튜디오분트 · 100% 메리노양모 70수 펠트지 1mm 20×30cm (80 블랙)
34 | 포론(PORON) 폼 5T 점착 (100×100) | 1 | 업스톱 패드 — 설계 6T 대신 5T: 패드 바 쐐기를 1.0 mm 두껍게 출력, 단계 0 시험 먼저 | 3399 | 3399 | https://www.navimro.com/g/1028764/ | 나비엠알오 · [와키(WAKI)] PORON 스폰지 접착 부착 PON-02 (100×100×5, 검정, 아크릴 점착)
35 | 충격흡수재 하네나이트 1T (170×245) | 1 | 앞 펠트 밑 완충층 (NBR 고무, 단계 0 시험으로 확인) | 16489 | 16489 | https://www.navimro.com/g/1029233/ | 나비엠알오 · [와키(WAKI)] 충격흡수재 하네나이트 HNT002 (170×245×1, 검정)
36 | 접착 펠트 0.5T (30×45 cm) | 1 | 건반 노치 · 핀 홈 · 가이드 탭 부싱 천, 쉼 펠트 한 겹 | 1500 | 1500 | https://www.11st.co.kr/products/8517880969 | 상우아트 · [대원] 얇은 칼라펠트지 H 두께0.5mm 접착 30x45cm (H-20 검정)
 |  |  | 건반 액션 (W1: 시소 건반 + 무게 레버) 소계 |  | 132328
4. 오디오 (스피커 · 앰프)
37 | 앰프 보드 XH-A232 (TPA3110) | 1 | 스피커 구동, 채널당 약 21 W | 2750 | 2750 | https://www.icbanq.com/P017179248 | 아이씨뱅큐 (제노) · XH-A232 (HW-404) TPA3110 2채널 앰프 보드 (제노 HAM6104)
38 | 스피커 유닛 삼미 CW-100B25 (4인치 8 Ω) | 2 | 좌우 내장 스피커 | 9600 | 19200 | https://www.11st.co.kr/products/1565354988 | 세운상가새한음향 · 삼미스피커(SAAT) CW-100B25 4인치 풀레인지 8Ω 25W (KS 인증)
39 | Apple USB-C 헤드폰 어댑터 | 1 | USB DAC (디지털 → 아날로그 소리) | 14900 | 14900 | https://www.apple.com/kr/shop/product/mw2q3kh/a | Apple · Apple USB-C–3.5mm 헤드폰 잭 어댑터 (MW2Q3KH/A)
40 | USB-C → USB-A 젠더 | 1 | 어댑터를 Pi 5 USB 포트에 연결 | 1700 | 1700 | https://www.eleparts.co.kr/goods/view?no=11043038 | 엘레파츠 · [Coms] IH190 USB-C(F) → USB-A(M) 변환 젠더 좌향 꺾임
41 | 3.5 mm 스테레오 잭 PJ-313 | 3 | 헤드폰 잭(꽂으면 스피커 차단) · 앰프 입력 · 페달 잭 | 198 | 594 | https://www.eleparts.co.kr/goods/view?no=67811 | 엘레파츠 · [BSUN] PJ-313 3.5Ф 스테레오잭 (이어폰잭)
42 | 적층 세라믹 콘덴서 1 µF | 5 | 앰프 입력 저음 차단 필터 | 133 | 665 | https://www.icbanq.com/P014159115 | 아이씨뱅큐 (동신전자) · Monolithic Capacitor 1uF X7R 50V (리드형 적층 세라믹)
43 | XT30 커넥터 수 (선 포함) | 2 | 스피커 연결 — 앰프 쪽 | 1760 | 3520 | https://www.eleparts.co.kr/goods/view?no=12779720 | 엘레파츠 · [AMASS] XT30U-M 수 커넥터 18AWG 10cm 실리콘 와이어
44 | XT30 커넥터 암 (선 포함) | 2 | 스피커 연결 — 스피커 쪽 | 1760 | 3520 | https://www.eleparts.co.kr/goods/view?no=12779721 | 엘레파츠 · [AMASS] XT30U-F 암 커넥터 18AWG 10cm 실리콘 와이어
45 | 오꾸메 합판 400×1200 (무료 재단) | 1 | 스피커 상자 2개 | 17680 | 17680 | https://namugongjang.com/product/detail.html?product_no=1378 | 동진나무공장 · 무료배송 오꾸메 합판 400×1200×11.5mm 무료재단
46 | 흡음솜 300 g | 1 | 스피커 상자 흡음재 | 2700 | 2700 | https://www.11st.co.kr/products/2325598213 | 두유레디 · 두유레디 구름솜 300g (100% 국내산 할로우화이버)
 |  |  | 오디오 (스피커 · 앰프) 소계 |  | 67229
5. 본체 구조 · 결합
47 | 오꾸메 합판 600×1200 (무료 재단) | 1 | 가운데 유닛 상자 (건반 보관함 · 제어부 · 배터리 칸) | 22520 | 22520 | https://namugongjang.com/product/detail.html?product_no=1378 | 동진나무공장 · 무료배송 오꾸메 합판 600×1200×11.5mm 무료재단
48 | 토글 래치 (SUS) | 2 | 가운데 유닛 ↔ 스피커 파트 잠금 | 2400 | 4800 | https://www.metaldiy.com/item/itemView.do?itemId=8806379117286 | 철물박사 · 매미고리 1-20 (SUS304 스테인리스 토글 래치, 25×54mm)
49 | 네오디뮴 자석 Ø8×3 | 14 | 가운데 유닛 뚜껑 고정 | 160 | 2240 | https://dgmagnet.com/product/detail.html?product_no=17 | 대건상사 · 초강력 네오디움 원형자석 8mm — 3.0T (Ø8×3mm, N35)
50 | JST-XH 6핀 연장선 | 2 | 끝 부속 ↔ 모듈 센서 선 커넥터 | 3000 | 6000 | https://www.rcbank.co.kr/shop/goods/goods_view.php?goodsno=29812 | 알씨뱅크 · 리튬폴리머 배터리 밸런스잭 연장선 5셀용 (JST-XH 6핀 수↔암, BU-LP 5S, 200mm)
51 | 고무발 28×5 | 20 | 뒷바 받침 (5 mm 띄움, 진동 분리) | 583 | 11660 | https://www.eleparts.co.kr/goods/view?no=16628292 | 엘레파츠 · [화성고무] 피스고무발 / 28x5 (RUB-E2)
52 | M3 방진 댐퍼·그로밋 (20개) | 1 | 끝 부속 ↔ 스피커 브래킷 방진 | 4500 | 4500 | https://www.rcbank.co.kr/shop/goods/goods_view.php?goodsno=67110 | 알씨뱅크 · 알씨뱅크 M3 진동 방지 댐퍼 (20개)
53 | EVA 폼 3T (330×490) | 3 | 모듈 · 끝 부속 바닥 시트, 스피커 가스켓 | 2100 | 6300 | https://www.11st.co.kr/products/7591566666 | 상우아트 · 에바폼 EVA 컬러 고밀도 칼라스펀지 3T (E-210 검정, 330×490)
54 | 렌치볼트 M3×10 (SUS) | 50 | 센서 바 · 제어부 부품 · 토글 래치 고정 | 60 | 3000 | https://www.11st.co.kr/products/4236198413 | 굿나잇몰 · 스텐 유두 렌치볼트 M3 × 10mm
55 | 렌치볼트 M3×6 (SUS) | 20 | 제어 기판 고정 | 40 | 800 | https://www.11st.co.kr/products/4236198413 | 굿나잇몰 · 스텐 유두 렌치볼트 M3 × 6mm
56 | 렌치볼트 M2.5×6 (SUS) | 6 | Pi 5 고정 | 200 | 1200 | https://www.11st.co.kr/products/4236198413 | 굿나잇몰 · 스텐 유두 렌치볼트 M2.5 × 6mm
57 | 와셔 M4 (SUS) | 20 | 고무발 피스 받침 | 10 | 200 | https://www.11st.co.kr/products/4236198413 | 굿나잇몰 · 스텐 와셔 M4x9x0.5T
58 | 직결피스 13 mm | 54 | 뒷바 출력 부품 · 고무발 고정 | 40 | 2160 | https://www.11st.co.kr/products/4353471537 | 굿나잇몰 · 스텐 둥근머리 직결피스 8호(Ø4.2) 13mm
59 | 직결피스 16 mm | 8 | 스피커 유닛 고정 | 50 | 400 | https://www.11st.co.kr/products/4353471537 | 굿나잇몰 · 스텐 둥근머리 직결피스 8호(Ø4.2) 16mm
60 | 직결피스 19 mm | 8 | 스피커 그릴 고정 | 50 | 400 | https://www.11st.co.kr/products/4353471537 | 굿나잇몰 · 스텐 둥근머리 직결피스 8호(Ø4.2) 19mm
 |  |  | 본체 구조 · 결합 소계 |  | 66180
6. 소모품
61 | PETG 필라멘트 흰색 1 kg (스풀) | 1 | 백건 출력 | 16150 | 16150 | https://kr.store.bambulab.com/products/petg-basic | Bambu Lab · Bambu Lab PETG Basic 화이트(30106) 스풀 포함 1kg
62 | PETG 필라멘트 흰색 1 kg (리필) | 1 | 백건 출력 | 12750 | 12750 | https://kr.store.bambulab.com/products/petg-basic | Bambu Lab · Bambu Lab PETG Basic 화이트(30106) 리필 1kg
63 | PETG 필라멘트 검정 1 kg (스풀) | 5 | 프레임 · 레버 캐리어 · 흑건 등 | 16150 | 80750 | https://kr.store.bambulab.com/products/petg-basic | Bambu Lab · Bambu Lab PETG Basic 블랙(30105) 스풀 포함 1kg
64 | PETG 필라멘트 1 kg 추가 (흰색 또는 검정) | 1 | 뒷바 출력 부품 · 여분 | 16150 | 16150 | https://kr.store.bambulab.com/products/petg-basic | Bambu Lab · Bambu Lab PETG Basic 스풀 포함 1kg 추가 (흰색 또는 검정)
65 | USB-A → USB-C 케이블 1 m | 8 | 모듈 7 + 페달 → USB 허브 | 1620 | 12960 | https://www.eleparts.co.kr/goods/view?no=4313490 | 엘레파츠 · [NA993] Coms USB 3.1 Type C 케이블 1M USB 2.0 A to C타입 White
66 | 리본 케이블 16P (1 m) | 2 | 센서 기판 → 제어 기판 | 1529 | 3058 | https://www.eleparts.co.kr/goods/view?no=425 | 엘레파츠 · [EUNSUNG] Flat Data Cable 2651-16P (1m단위)
67 | 리본 케이블 16P (1 m) 추가 | 1 | 기판 배선용 가닥 | 1529 | 1529 | https://www.eleparts.co.kr/goods/view?no=425 | 엘레파츠 · [EUNSUNG] Flat Data Cable 2651-16P (1m단위)
68 | 스피커 케이블 16AWG 7 m | 1 | 앰프 → 스피커, 20 V 전원선 | 14300 | 14300 | https://www.eleparts.co.kr/goods/view?no=18388615 | 엘레파츠 · [케이블스토어] 프리즘 국산 스피커케이블 50C 16AWG, 7M [블랙/PRS-50B07]
69 | 3.5 mm 스테레오 케이블 1.5 m | 2 | 어댑터 → 헤드폰 잭 → 앰프 | 1710 | 3420 | https://www.eleparts.co.kr/goods/view?no=2925673 | 엘레파츠 · [AV0176] Coms 스테레오 케이블 1.5M AUX 3극 Stereo 3.5 M/M
70 | USB-C PD 케이블 0.6 m | 1 | 보조배터리 → 피아노 | 1440 | 1440 | https://www.eleparts.co.kr/goods/view?no=17806172 | 엘레파츠 · [MachLink] USB-C to C PD 60W 초고속충전 케이블, ML-CPD606 [블랙/0.6m]
71 | USB-C PD 케이블 2 m | 1 | 충전기 → 피아노 | 2670 | 2670 | https://www.eleparts.co.kr/goods/view?no=17806170 | 엘레파츠 · [MachLink] USB-C to C PD 60W 초고속충전 케이블, ML-CPD62 [블랙/2m]
72 | USB-C 전원 케이블 (제작용) | 1 | 강압 모듈 → Pi 5 전원 | 1190 | 1190 | https://www.eleparts.co.kr/goods/view?no=17358965 | 엘레파츠 · [MAXTEK] 맥스텍 USB C타입 제작용 케이블 2선 Type-C Male(숫) DIY PD 전원 [MT666]
73 | 열수축 튜브 세트 | 1 | 선 이음 절연 | 6600 | 6600 | https://www.eleparts.co.kr/goods/view?no=8170311 | 엘레파츠 · [엘레파츠] 열수축튜브 530세트 - 프라스틱케이스
74 | 캡톤 테이프 | 1 | 기판 절연 | 4059 | 4059 | https://www.eleparts.co.kr/goods/view?no=557 | 엘레파츠 · [KzPton] 캡톤테이프 10mm폭x33m
75 | 케이블 타이 (100개) | 1 | 케이블 정리 | 438 | 438 | https://www.eleparts.co.kr/goods/view?no=9100003 | 엘레파츠 · 티테크놀로지 케이블타이, 100개 [소/100mm] [블랙] [T-C2510B]
76 | 실납 0.8 mm 50 g | 1 | 손 납땜 (약 1,500곳) | 3850 | 3850 | https://www.eleparts.co.kr/goods/view?no=12755646 | 엘레파츠 · [YUN FANG] 유연납 0.8mm 50g
77 | 순간접착제 5 g | 1 | 자석 고정 | 1100 | 1100 | https://www.icbanq.com/P015309984 | 아이씨뱅큐 (크레텍) · 순간접착제 (814-2010) — V-tech 강력 순간접착제 5g (VT-041)
78 | MS 폴리머 탄성 접착제 세메다인 슈퍼X 흰색 20 mL | 2 | 강철 블록을 레버 캐리어에 붙임 (필요 약 14 mL, 흰색·검정만 — 투명은 PET 접착이 약함) | 8000 | 16000 | https://www.11st.co.kr/products/7459325704 | 주영종합상사 · 세메다인 슈퍼X 8008 탄성접착제 백색 20 mL (AX-022)
79 | 종이 양면테이프 | 1 | EVA 시트 · 펠트 부착 | 1080 | 1080 | https://www.eleparts.co.kr/goods/view?no=17897439 | 엘레파츠 · [NAVI] 종이 양면테이프, 백색/48mm/6m
80 | 목공 본드 800 g | 1 | 합판 상자 접착 | 3949 | 3949 | https://www.navimro.com/g/395062/ | 나비엠알오 · 오공 201 205 본드 800g 목공용본드 (옵션: 오공 205본드 800g)
81 | 텅스텐 퍼티 (22 g) | 1 | 건반별 무게 미세 조정 (필요할 때만) | 8750 | 8750 | https://www.11st.co.kr/products/9579455646 | 골드그로브 · 텅스텐 퍼티 소프트 싱커 무게추 (낚시용, 22 g)
82 | OHP 필름 (A4 20매) | 1 | 0.1 mm 심 — 업스톱 시점 조정 | 2739 | 2739 | https://www.navimro.com/g/37021/ | 나비엠알오 · OHP 필름 (A4) 흑백 레이저용 1PK(20매) (copierland)
83 | 흑연 가루 30 ml | 1 | 캡스턴 펠트 마찰 줄이기 | 2750 | 2750 | https://www.11st.co.kr/products/1333385437 | 비젼몰 · 크레타칼라 흑연파우더(소/30ml)
 |  |  | 소모품 소계 |  | 217682
 | 합계
 |  |  | 피아노 부품 (1~5) |  | 615227
 |  |  | 소모품 (6) |  | 217682
 |  |  | 전체 합계 (부품 + 소모품) |  | 832909
 | · 이 목록에 넣지 않은 것(사용자 요청): 페달 11,360원, 소프트웨어 (무료) 0원, 2단계 리듬게임 17,050원, 공구 139,438원, 배송비 약 54,100원(판매처별 1회). 페달 보드 전자 부품(RP2040-Zero 1개 · 5×7 기판 1장 · 홀센서 1개 · 페달 잭 · 저항)은 공용 부품이라 위 목록 수량에 그대로 들어 있다.
 | · 목록에서 뺀 중복 · 불필요 항목: [DHG] 3mm 대폭 양모펠트지 150×10cm — W1 r4.1 설계에 3T 펠트를 쓰는 곳이 없음 (앞 멈춤·키퍼는 2T).
 | · 비틀림 스프링은 직접 감지 않고 한국미스미 경제형 기성품 C-UA90R5-3-0.5(SUS304-WPB, 내경 5 · 선경 0.5 · 3권 · 암 각 90°)를 산다(2026-09-28 확인: 100개 이상 개당 282원 + VAT). 두 다리를 경선용 니퍼로 긴 다리 22.3 / 짧은 다리 8.0 mm로 자른다(r4.5: 짧은 다리를 허브의 가둠 홈에 넣어 코일이 봉에 닿지 않게 함). 단계 0 시험 8(쉼 4.19 / 바닥 6.03 N·mm ±15%)과 시험 13(가둠 홈 넣기)으로 확인한다. 한국미스미는 회원 가입 후 신용카드로 주문한다(개인 가능).
 | · 강철 블록 접착제는 에폭시가 아니라 MS 폴리머 탄성 접착제(세메다인 슈퍼X 흰색)다. 에폭시는 온도 변화에 떨어져 설계(r4.4)와 맞지 않는다. 공기 중 습기로 굳어 닫힌 0.1 mm 틈 가운데는 며칠 걸릴 수 있어 단계 0 시험 20으로 확인한다.
 | · PORON 폼은 판매처에 5T만 있어 설계 6T 대신 쓴다. 패드 바 6종의 쐐기를 1.0 mm 두껍게 출력해야 하고, 등급(25% 압축 0.36 MPa) 표기가 없어 단계 0 시험 1·2(반발 e ≤ 0.07, 강성)를 먼저 한다.
 | · 단계 0 측정 도구(다이얼 게이지, 용수철 저울, 0.1 g 저울)와 커터칼 · 사포는 목록에 없다 — 빌리거나 가진 것을 쓴다. 봉 지름(3.97~4.00 mm)은 받은 뒤 확인한다.
 | · 원본: docs/report/toccata-purchase-list-v4.xlsx (2026-09-29: v3.2 절감 선택 + v4 r4.5 + 회로 줄 변경 + 미스미 스프링 · MS 폴리머 접착제 · 경선 니퍼). 핀헤더 소켓은 회로 검토에서 빠졌다(끝 부속 EXT는 JST-XH를 패드에 직접 납땜). 건반 액션은 단계 0 시험 결과에 따라 바뀔 수 있다.

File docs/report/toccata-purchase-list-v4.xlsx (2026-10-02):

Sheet: 구매목록
Toccata v4 재료 목록 — 구매 목록(v3.2 절감 선택) + v4 건반 액션(r4.5) + 뒷바 L2·터치스크린 3판(10/1)
기준: docs/report/toccata-purchase-list.xlsx(v3.2, 고르신 절감 22개) + v4 W1+ 4차 설계 부품(2026-09-27~28 판매처 조사·링크 재검증) + 회로 검토(2026-09-28, hardware/pcb) + r4.4 스프링·니퍼(2026-09-28) + 블록 접착제 MS 폴리머(2026-09-29) + 한 몸 뒷바 L2·터치스크린 3판(2026-10-01, cad/spec/body_L2.json·cad/README.md·touchscreen/rev3). 가격은 VAT·할인 반영(원). 구분: 기본 = 피아노에 들어가는 부품, 소모품 = 제작 중 쓰는 재료, 공구 = 제작용 공구
사용법: 파란 글씨(단위당 가격·수량·구매 O/X)만 고친다. X로 바꾸면 소계·최종 금액에서 빠진다(줄이 회색). 가격 확인이 "미확인"인 줄은 견적·추정가다.
No | 부품명 | 단위당 가격(원) | 수량 | 용도 | 예상 가격(원) | 구매 링크 | 구분 | 구매(O/X) | 판매자 | 부품 코드 | 비고 | v4 상태 | 가격 확인
■ 아이씨뱅큐
1 | Raspberry Pi 5 2GB (라즈베리파이 5 2GB Raspberry pi 5) | 119900원 | 1 | FluidSynth 소프트웨어 신스를 돌리고 USB-MIDI 8개(O1~O7, PED) 입력을 한 곳에서 병합하는 중앙 컴퓨터. 소리는 USB 동글(L51)로 내보낸다(R25: HAT 없음, GPIO는 2번(5 V)·6번(GND)만 터치스크린 전원으로 씀 — R31, 회로 개정 C △16) | 119900원 | https://www.icbanq.com/P016286897 | 기본 | O | 아이씨뱅큐 | L01 |  | 유지 | 확인
2 | 100W QC PD 트리거 디코이 고정출력 모듈 5V-20V (HAM6113, HUSB238) | 4950원 | 1 | 피아노의 전원 입력(USB-C). 벽 충전기(L62)나 보조배터리와 PD로 협상해 20 V를 받아 퓨즈(L60) → 스위치(L59) → 20 V 버스로 보낸다. 10/1 L2: 뒤판 출력물(PR-BACKPLATE)의 HUSB238 주머니(x415.8~426.2 z35.6~40.4)에 끼워 USB-C 입구(13 × 7.5, 바깥면에서 2 안)가 밖을 향한다(R28) | 4950원 | https://www.icbanq.com/P017179277 | 기본 | O | 아이씨뱅큐 (제노) | L57 |  | 10/1 L2: 용도 수정 (I/O 판·CU 트레이 → 뒤판 출력물·J702) | 확인
3 | 200W XL4016 DC-DC 강압 컨버터 모듈 IN 4-40V OUT 1.25-36V 5A (HAM6415, XH-M401) | 5170원 | 1 | 20 V 버스 → 5.1 V. Pi 5(USB-C 전원선 C24)와 USB 허브(L17, DC 잭)에 전원을 준다. Pi에는 이 5 V만 들어간다(D16). 5 mm 출력 받침 기둥에 M3×5(L76) 4개로 고정(10/1 L2, 6 mm 이상은 기둥 바닥을 뚫음) | 5170원 | https://www.icbanq.com/P017179502 | 기본 | O | 아이씨뱅큐 (제노) | L58 |  | 10/1 L2: 용도 수정 | 확인
4 | TI DRV5055A2QLPG (TO-92-3 Linear Hall Effect Sensor, LCSC 경유) | 891원 | 100 | 건반 88 + 페달 1 = 89개 사용, 예비 11. 표시면을 위로 눕혀 센서 바 포켓에 넣고 건반 밑 자석(Ø5×2)의 거리를 연속으로 잰다 | 89100원 | https://www.icbanq.com/P018076669 | 기본 | O | 아이씨뱅큐 (LCSC 해외 재고) | L20 |  | 유지 | 확인
5 | 핀헤더 1×40 - 2.54MM(S/T) _ 11.5MM(1단몰드) | 165원 | 9 | 4067 먹스 7개 × (16+8)핀 = 168핀 + RP2040-Zero 8개 × 1×9 ×2 = 144핀 → 312핀, 1×40 9줄(360핀) | 1485원 | https://www.icbanq.com/P005666127 | 기본 | O | 아이씨뱅큐 | SE7 | 모듈에 수 헤더가 들어 있으면 줄여도 된다 | v4 수량 변경 (5 → 9, 회로 검토) | 확인
6 | Samsung CL31B104KCFNNNE (1206 100nF 100V X7R) | 44원 | 100 | 센서마다 1개(3V3–GND 디커플링, 센서 기판 아랫면) + PED 보드 + 제어 기판 C301 ×7 = 97개 사용, 예비 3 | 4400원 | https://www.icbanq.com/P014968846 | 기본 | O | 아이씨뱅큐 (LCSC 해외 재고) | SE4 | 삼성 CL31B104KCFNNNE(100 V). 판매처 사진이 안 열려 품번으로 확인 | 유지 | 확인
7 | C3216-10UF(K 16V) — 1206 10 µF 16 V 칩 세라믹 콘덴서 (50개 단위) | 7150원 | 1 | 센서 기판 C213·C214 ×7 + 끝 부속 EL C404 + ER C412 = 16개(회로 △1·△3). 34개 남음 | 7150원 | https://www.icbanq.com/P001248090 | 기본 | O | 아이씨뱅큐 (오렌지반도체) | L67 | 9/28 확인: 6,500원 + VAT = 7,150원, 국내 재고, 1~2일. 제조사·유전체 표기 없음. 주문 제작 상품이라 취소·반품 불가 | v4 신규 (회로 검토) | 확인
8 | Yageo RC1206JR-071KL — 1206 1 kΩ 5 % 1/4 W 칩 저항 | 44원 | 10 | 끝 부속 EL R401~R403 + ER R411 = 4개(회로 △13, 기판 아랫면). 10개 단위 판매 | 440원 | https://www.icbanq.com/P011433924 | 기본 | O | 아이씨뱅큐 (element14 해외 재고) | L68 | 9/28 확인: 40원 + VAT = 44원, 10개 단위, 해외 재고 4,690개, 4~6일. 해외 재고는 취소·반품 불가 | v4 신규 (회로 검토) | 확인
9 | XH-A232 (HW-404) TPA3110 2채널 앰프 보드 (제노 HAM6104) | 2750원 | 1 | 좌우 스피커(L07)를 울리는 D급 앰프. 20 V 버스(PD 트리거 L57 → 퓨즈 → 스위치)에서 8 Ω 채널당 약 21 W. 입력은 J702 기판의 앰프 입력 잭(L15 ③)에서 받는다. 10/1 L2: 허브 위 선반 받침에 M3×6(L35) 4개(받침 + 선반 관통) | 2750원 | https://www.icbanq.com/P017179248 | 기본 | O | 아이씨뱅큐 (제노) | L53 |  | 10/1 L2: 용도 수정 (I/O 판·CU 트레이 → 뒤판 출력물·J702) | 확인
10 | Monolithic Capacitor 1uF X7R 50V (리드형 적층 세라믹) | 133원 | 5 | 앰프 입력의 저음 차단(고역 통과) 필터. 채널마다 1 µF 2개를 병렬(2 µF)로 직렬에 넣고 1 kΩ 풀다운(L29)과 묶어 약 93 Hz 아래를 6 dB/옥타브로 줄인다(D18) | 665원 | https://www.icbanq.com/P014159115 | 기본 | O | 아이씨뱅큐 (동신전자) | L56 |  | 회로 검토: 용도 수정 | 확인
11 | XHHD 육각너트 M3 강철 (LCSC C133377) | 11원 | 100 | v4: 건반 캡스턴 나사(M3 버튼헤드) 너트 88 + 예비 8, 스피커 브래킷 4 | 1100원 | https://www.icbanq.com/P015976209 | 기본 | O | 아이씨뱅큐 (LCSC 해외 재고) | L31 |  | v4 수량 변경 (75 → 100) | 확인
12 | 순간접착제 (814-2010) — V-tech 강력 순간접착제 5g (VT-041) | 1100원 | 1 | 센서 자석 Ø5×2·뚜껑 자석을 포켓에 압입한 뒤 한 방울, 건반 봉 끝을 봉 받침에 고정(v4) | 1100원 | https://www.icbanq.com/P015309984 | 소모품 | O | 아이씨뱅큐 (크레텍) | ME8 | 록타이트 401 20 g 대신(ME8). 성분·점도 표기는 페이지에 없다 | 유지 | 확인
13 | [BC256] Coms 스테레오 케이블 3M AUX 3극 Stereo 3.5 M/M 고급포장 | 2860원 | 1 | 댐퍼 페달 신호선. 한쪽 플러그를 잘라 페달 안 홀센서에 납땜(팁 = 출력, 링 = 3V3, 슬리브 = GND)하고, 다른 쪽은 CU의 PJ-313 잭(L15의 두 번째)에 꽂는다 | 2860원 | https://www.icbanq.com/P004711396 | 기본 | O | 아이씨뱅큐 | L50 |  | 유지 | 확인
14 | AOFENG ISO7380 M3-0.5X6 304 (Hex socket pan head cap screw) | 11원 | 100 | 캡스턴 나사 M3×6 버튼헤드 (너트는 L31 M3 육각너트 카드) — ISO 7380 M3×6 SUS304 버튼헤드, 최소 주문 100개 | 1100원 | https://www.icbanq.com/P015973844 | 기본 | O | 아이씨뱅큐 | v4capstan | 9/27 상품 페이지: 10원(VAT 별도) / 11원(VAT 포함), 최소 100개, 100~3,000개 구간 10원, 해외 재고 배송 1주 이내. 상품 사진이 준비 중 이미지라 같은 규격(나사코리아 둥근렌치 M3 SUS304) 사진을 붙였다. 배송비는 v3 아이씨뱅큐 주문과 합배송이라 0원. | v4 신규 · 너트는 L31에서 한 번만 셈 (9/28 고침) | 확인
15 | 배송비 — 아이씨뱅큐 | 0원 | 1 | 배송비 | 0원 |  | 기본 | O
 | 아이씨뱅큐 소계 |  |  |  | 242170원
■ 엘레파츠
16 | [ZX Electronics] KCD1-101A BLACK I/O 로커 스위치 (2P ON-OFF, 6A 250VAC / 10A 125VAC) | 385원 | 1 | 피아노 전원 스위치. PD 트리거·퓨즈 뒤 20 V 쪽에 넣어 앰프와 강압 모듈을 함께 켜고 끈다. 10/1 L2: 뒤판 출력물의 2 mm 판 구멍(13.2 × 19.2)에 스냅인으로 끼우고 테두리는 2 mm 오목 자리에 들어가 바깥면과 같은 높이(R28) | 385원 | https://www.eleparts.co.kr/goods/view?no=32569 | 기본 | O | 엘레파츠 | L59 |  | 10/1 L2: 용도 수정 (I/O 판·CU 트레이 → 뒤판 출력물·J702) | 확인
17 | [Coms] BU914 원형 휴즈 홀더 (5×20 mm, 인라인) | 1110원 | 1 | 20 V 버스 보호 퓨즈 홀더. PD 트리거 출력 + 선에 끼워 배선 단락 때 선이 타지 않게 한다 | 1110원 | https://www.eleparts.co.kr/goods/view?no=3237821 | 기본 | O | 엘레파츠 | L60 |  | 유지 | 확인
18 | [LITTELFUSE] 0218005.MXP 5 A 지연형 퓨즈 5×20 mm | 110원 | 5 | 홀더에 넣는 5 A 지연형 퓨즈 1개 + 예비 4개(R28) | 550원 | https://www.eleparts.co.kr/goods/view?no=12766820 | 기본 | O | 엘레파츠 | L60 | 최소 5개 | 유지 | 확인
19 | [Coms] [NC888] Coms C타입 MM 꺾임 케이블 1m C to C | 2600원 | 1 | 보조배터리 → 피아노 USB-C 입력(L57). 10/1 L2: 보조배터리 +x 끝 USB-C에 꺾인 머리를 위(+z)로 꽂고(USB-C는 뒤집어 꽂을 수 있음), 선은 z55~60으로 +y를 따라 뒤판 케이블 통과(x405 z38)로 내려가 밖에서 PD 입력에 꽂는다. 남는 약 0.65 m는 배터리 위(z51~60.8)에 납작하게 감는다(CAD 10/2 확인). 조건: 보조배터리 USB-C 포트 중심이 바닥에서 약 15.5 mm 이상(아니면 CAD가 배터리 받침 +x 끝벽을 그 자리만 따냄) | 2600원 | https://www.eleparts.co.kr/goods/view?no=18842596 | 소모품 | O | 엘레파츠 | C22 | 10/2 교체: 주파집 ㄱ자 0.5 m(4,270원)는 업체 직배송이라 개별 배송비 3,000원이 따로 붙고 엘레파츠 무료배송 합계에도 들어가지 않아 Coms NC888(2,363.64원 VAT 별도 → 2,600원, 일반 배송, 평균 발송 3.5일, 1인 1개, C–C 양끝 90° 꺾임)로 바꿈 −4,670원. C–C 선은 규격상 3 A라 20 V × 3 A = 60 W. 페이지에 W 정격·꺾임 면 표기가 없어 받으면 꺾임 방향과 20 V가 나오는지 확인 | 10/1 L2 교체: 곧은 0.6 m → ㄱ자 0.5 m · 개별 배송비 3,000원(따로 줄) | 확인
20 | [MachLink] USB-C to C PD 60W 초고속충전 케이블, ML-CPD62 [블랙/2m] | 2670원 | 1 | 벽 충전기(L62) → 피아노 USB-C 입력(L57). 제작 중에는 인두(T01) 전원선으로도 쓴다(R28) | 2670원 | https://www.eleparts.co.kr/goods/view?no=17806170 | 소모품 | O | 엘레파츠 | C23 |  | 유지 | 확인
21 | [Coms] [BT663] Coms USB 3.1 Type C 케이블 20cm USB 2.0 A to C타입 측면꺾임 (A 쪽을 잘라 씀) | 2550원 | 1 | 5.1 V 강압 모듈(L58) 출력 → Pi 5 USB-C 전원 입력. 10/1 L2: CAD는 Pi −y 가장자리에 측면 꺾임 USB-C 머리 14×13×9 (Z-PI-PWR, x546~560 y249~262 z22~31)를 그리고 선을 −x로 뺐다 — 곧은 플러그는 뚜껑 아래(z61.35)에 들어가지 않는다(CAD README). C 쪽이 옆으로 꺾인 20 cm 선의 A 쪽을 잘라 빨강(+)·검정(−)을 강압 출력 단자에 물리고 흰·초록 데이터선은 잘라 절연한다. USB-C는 앞뒤가 같아 뒤집어 꽂으면 선이 +x로 나온다 | 2550원 | https://www.eleparts.co.kr/goods/view?no=8105815 | 소모품 | O | 엘레파츠 | C24 | 10/1 L2 교체(이전 MAXTEK MT666 DIY 2선, 1,190원 — 상품 사진상 곧은 플러그). 10/1 페이지: 2,318.18원(VAT 별도) → 2,550원, 평균 발송 3.5일(10/08), 1인 1개, 해외재고(개별 배송비 없음). 전원선 굵기는 공개되지 않음 — 20 cm라 3 A에서 약 0.1~0.25 V 떨어진다(추정). Pi 저전압 경고가 뜨면 강압 출력(L58)을 조금 올린다. CAD v16: 머리는 사진 추정 14×12×7로 자리 14×13×9 안, 선은 −x(강압 쪽)로 꽂음 — −x 쪽이 비어 머리가 18까지 길어도 들어간다 | 10/1 L2 교체: 곧은 MT666 → 측면 꺾임 C 20 cm (A 쪽을 잘라 씀) · CAD 확인 필요 | 확인
22 | [코티니] 컴잇 벨크로 링벨트 케이블 선정리 [2X30cm] 블랙 | 863원 | 1 | 10/1 L2: 보조배터리(선택, 105×71×32)를 출력 받침에 묶는 20 mm 벨크로 — 받침 앞·뒤 벽 바닥의 끈 구멍 22 × 3을 지나 배터리 밑·위를 감는다. 보조배터리를 쓰지 않으면 빼도 된다 | 863원 | https://www.eleparts.co.kr/goods/view?no=12816289 | 기본 | O | 엘레파츠 | L79 | 10/1 페이지: 784.55원(VAT 별도) → 863원, 평균 발송 2.5일 | 10/1 L2 신규 | 확인
23 | [Coms] [NA977] Coms USB Type A to Type B 변환 케이블 25cm USB 2.0 A 상향꺾임 | 1530원 | 1 | 10/1 L2: 허브 업스트림 짧은 선(W209 대신) — Pi 5 위 USB-A ↔ 허브 업스트림. 딸린 0.6 m 곧은 선은 두 플러그 사이 21 mm · 뚜껑 아래 z50 안에 들어가지 않는다. 허브 업스트림은 USB 3.0 B 포트(제품 사진) — USB 2.0 B 플러그도 꽂히고 USB-MIDI 8개에는 USB 2.0으로 충분. CAD v16 확정: Pi 5 GPIO 쪽 USB-A 2단의 아래 포트에 꽂는다(위 포트면 머리 윗면 z57로 뚜껑과 4.35뿐). A가 위로 올라가 R7로 꺾여 허브 선반 위 z56.5에서 U자로 돌고 x650.5에서 내려가 곧은 B로(길이 41 + 169 + 40 = 250). 남는 Pi USB-A는 RJ45 쪽 위 포트 하나. 받으면 꽂아서 A가 위로 꺾이는지 확인(아래로 꺾이는 선은 바닥에 닿아 못 씀) | 1530원 | https://www.eleparts.co.kr/goods/view?no=4314354 | 소모품 | O | 엘레파츠 | C25 | 10/1 페이지: 1,390.91원(VAT 별도) → 1,530원, 평균 발송 3.5일. 엘레파츠에 "곧은 A + 꺾인 B" 짧은 선이 없어 고름(USB 3.0 A/B 양쪽 측면 꺾임 30 cm IH235는 6,120원) | 10/1 L2 신규 · CAD 확인 필요 | 확인
24 | [NA993] Coms USB 3.1 Type C 케이블 1M USB 2.0 A to C타입 White | 1620원 | 8 | 모듈 7개 + PED 보드 → 허브 USB 8가닥. 허브에 꽂힌 채 뒷바 아래 케이블 통로에 두고, 설치 때 모듈 쪽만 꽂는다(R27). 모듈 쪽 C 플러그 몰드 ≤ 12.5 × 7.6 × 25(폭 초과 금지) | 12960원 | https://www.eleparts.co.kr/goods/view?no=4313490 | 소모품 | O | 엘레파츠 | C04 | NA993은 몰드 두께가 공개되지 않았다. 폭 약 11.3·길이 약 19.5는 사진으로 잰 추정값이다. 단계 0 시험 19(프레임 뒤 조각에 10번 꽂고 빼기)로 확인한다. 10/1 L2: 1 m ×8을 그대로 쓴다(남는 선 약 2.3 m를 앞 공간·통로에 감음). CAD가 권한 짧은 세트(1 m ×2 O1·O2, 0.5 m ×4 O3·O4·O7·PED, 0.3 m ×2 O5·O6, 같은 계열 개당 약 1,300~1,900원 — 사양 추정, 미확인)는 선택이며 사기 전에 끈으로 길이를 잰다 | 회로 검토: 용도 수정 · 10/1 L2 메모 | 확인
25 | [EUNSUNG] Flat Data Cable 2651-16P (1m단위) | 1529원 | 2 | 센서 기판 → 제어 기판 리본 16심 전부(OUT 12 + 3V3 ×2 + GND ×2, 약 180 mm) ×7 + EL·ER 리드 가닥 | 3058원 | https://www.eleparts.co.kr/goods/view?no=425 | 소모품 | O | 엘레파츠 | C05 |  | 회로 검토: 용도 수정 | 확인
26 | [EUNSUNG] Flat Data Cable 2651-16P (1m단위) | 1529원 | 1 | 점퍼 단선 대신 리본 가닥으로: 센서 기판 3V3·GND 버스, 제어 기판 링크(SIG·S0~S3·EN), ID 브리지, 기판 배선(듀폰 점퍼 X1 대체) | 1529원 | https://www.eleparts.co.kr/goods/view?no=425 | 소모품 | O | 엘레파츠 | SE12 | C05와 같은 품목을 1 m 더 산다. 주문 때 C05와 합쳐 3 m로 담아도 된다 | 유지 | 확인
27 | [엘레파츠] 열수축튜브 530세트 - 프라스틱케이스 | 6600원 | 1 | EXT 리드(L66 JST-XH)를 패드에 납땜한 곳, 선 이음, 페달 잭 뒤쪽 절연 + 터치스크린 3판: Waveshare MX1.25→3핀 전원선 이음이 경첩 고리 안에 오면 감쌈(사양 G-4) | 6600원 | https://www.eleparts.co.kr/goods/view?no=8170311 | 소모품 | O | 엘레파츠 | C10 |  | 회로 검토: 용도 수정 · 10/1 L2 메모 | 확인
28 | [KzPton] 캡톤테이프 10mm폭x33m | 4059원 | 1 | RP2040-Zero 아래 절연(캡톤 1장), 기판 아랫면 절연 + 10/1 L2·터치스크린 3판: 화면 받침 안 리본 누름 패드 자리(xr26.75~39.45, 사양 C-7) | 4059원 | https://www.eleparts.co.kr/goods/view?no=557 | 소모품 | O | 엘레파츠 | C11 |  | 10/1 L2: 용도 수정 | 확인
29 | 티테크놀로지 케이블타이, 100개 [소/100mm] [블랙] [T-C2510B] | 438원 | 1 | USB 케이블을 뒷벽 고리에 묶어 당김 방지, EXT 리드(L66) 당김 방지 · 케이블 통로 안 USB 8가닥 묶음(R27) | 438원 | https://www.eleparts.co.kr/goods/view?no=9100003 | 소모품 | O | 엘레파츠 | C12 |  | 회로 검토: 용도 수정 | 확인
30 | [YUN FANG] 유연납 0.8mm 50g | 3850원 | 1 | 모듈당 약 200점, 전체 약 1,500점 손 납땜. 코어 플럭스만 쓴다(플럭스 펜 생략, CT22) | 3850원 | https://www.eleparts.co.kr/goods/view?no=12755646 | 소모품 | O | 엘레파츠 | CT5 | 모자라면 같은 상품을 더 산다(이 주문에 함께 넣으면 배송비 없음) | 유지 | 확인
31 | [ShenzenAV] 황동 인서트너트 M4x4x6 (내경 M4 · 높이 4 · 외경 6, 열압입) | 88원 | 10 | 10/1 L2: 스피커 출력 앞판(40°)의 유닛 나사 자리 PCD115에 4개씩 × 2 = 8 + 예비 2. CAD 구멍 Ø5.6 × 6.5(M4×6, 바깥 Ø5.6으로 그림)에 바깥 6을 열압입(물림 0.4, 보통 범위). CAD v16은 Ø6 × 4로 그림. M4×12(L70)가 플랜지 4 + 가스켓 3을 지나 5 들어가 인서트보다 1 더, 바닥까지 1.5(가스켓이 약 2로 눌리면 약 0.5). M4×12 이하만 — M4×14면 밀폐면을 뚫는다. 인서트는 면까지만 | 880원 | https://www.eleparts.co.kr/goods/view?no=11045753 | 기본 | O | 엘레파츠 | L69 | 10/1 페이지: 개당 80원(VAT 별도) → 88원, M.O.Q 1, 24시간 이내 발송. CAD 크기(M4×6, 바깥 Ø5.6)와 길이·바깥지름이 조금 다르다 — 구멍은 그대로 둔다 | 10/1 L2 신규 | 확인
32 | [ABCO] CFR 1/4W 5% 탄소피막 저항 1kΩ (10개 단위) | 25원 | 10 | 1 kΩ ×4: R701·R702(앰프 입력), R501·R551(페달). 6개 남음 | 250원 | https://www.eleparts.co.kr/goods/view?no=10911 | 기본 | O | 엘레파츠 | L29 | 10개 단위 판매(M.O.Q 10) | 회로 검토: 용도 수정 | 확인
33 | [ABCO] CFR 1/4W 5% 탄소피막 저항 10kΩ (10개 단위) | 25원 | 10 | 회로에서 쓰지 않음(예비). 빼도 된다 | 250원 | https://www.eleparts.co.kr/goods/view?no=10951 | 기본 | O | 엘레파츠 | L29 | 10개 단위 판매(M.O.Q 10) | 회로 검토: 용도 수정 | 확인
34 | [ABCO] CFR 1/4W 5% 탄소피막 저항 100kΩ (10개 단위) | 25원 | 10 | 100 kΩ ×5: R301(O1·O7)·R302·R303(제어 기판), R502(페달). 5개 남음 | 250원 | https://www.eleparts.co.kr/goods/view?no=10993 | 기본 | O | 엘레파츠 | L29 | 10개 단위 판매(M.O.Q 10) | 회로 검토: 용도 수정 | 확인
35 | [ABCO] CFR 1/4W 5% 탄소피막 저항 100Ω (10개 단위) | 25원 | 10 | 100 Ω ×5 병렬 = 20 Ω: R503(페달, 필수). 5개 남음 | 250원 | https://www.eleparts.co.kr/goods/view?no=10873 | 기본 | O | 엘레파츠 | L29 | 10개 단위 판매(M.O.Q 10) | 회로 검토: 용도 수정 | 확인
36 | [BSUN] PJ-313 3.5Ф 스테레오잭 (이어폰잭) | 198원 | 3 | ① 왼쪽 볼 앞면 헤드폰 잭: 동글(L51) 출력이 팁·링으로 들어오고 팁·링 노멀 접점이 앰프 쪽으로 나간다. 헤드폰을 꽂으면 노멀 접점이 떨어져 스피커가 기계적으로 끊긴다(R15) ② 뒤판 출력물의 댐퍼 페달 잭 J501(Ø6 구멍; J501 기판은 출력물 받침 위에 MS 폴리머, R24) ③ 앰프 입력 잭 J702(J702 기판을 5 mm 받침 기둥에 M3×5(L76) 2개, 화면 뚜껑 아래 — 10/1 L2): 선 ②의 플러그를 받아 저음 차단 RC를 거쳐 앰프(L53) 입력으로 보낸다(R26, 파트 분리) | 594원 | https://www.eleparts.co.kr/goods/view?no=67811 | 기본 | O | 엘레파츠 | L15 |  | 10/1 L2: 용도 수정 (I/O 판·CU 트레이 → 뒤판 출력물·J702) | 확인
37 | [Coms] IH190 USB-C(F) → USB-A(M) 변환 젠더 좌향 꺾임 | 1700원 | 1 | Apple 동글(USB-C 수)을 Pi 5 USB-A 포트에 꽂는 젠더 | 1700원 | https://www.eleparts.co.kr/goods/view?no=11043038 | 기본 | O | 엘레파츠 | L52 |  | 유지 | 확인
38 | [AMASS] XT30U-M 수 커넥터 18AWG 10cm 실리콘 와이어 | 1760원 | 2 | 앰프 쪽 스피커선 커넥터(좌우 2개). 통로 양 끝으로 나온 선에 납땜 | 3520원 | https://www.eleparts.co.kr/goods/view?no=12779720 | 기본 | O | 엘레파츠 | L61 |  | 유지 | 확인
39 | [AMASS] XT30U-F 암 커넥터 18AWG 10cm 실리콘 와이어 | 1760원 | 2 | 스피커 쪽 커넥터(좌우 2개). 스피커 파트 앞판 아래로 나온 선에 납땜 | 3520원 | https://www.eleparts.co.kr/goods/view?no=12779721 | 기본 | O | 엘레파츠 | L61 |  | 유지 | 확인
40 | [케이블스토어] 프리즘 국산 스피커케이블 50C 16AWG, 7M [블랙/PRS-50B07] | 14300원 | 1 | 앰프(L53) → 통로 → XT30 수(L61) 2쌍(좌우 각 약 0.6 m) + 스피커 파트 안 유닛 → XT30 암(각 약 0.3 m) + 20 V 전원선(PD 트리거 → 퓨즈 → 스위치 → 앰프·강압 모듈, 약 1 m) | 14300원 | https://www.eleparts.co.kr/goods/view?no=18388615 | 소모품 | O | 엘레파츠 | C13 |  | 유지 | 확인
41 | [AV0176] Coms 스테레오 케이블 1.5M AUX 3극 Stereo 3.5 M/M | 1710원 | 2 | ① 동글(L51) → 왼쪽 볼 헤드폰 잭(L15 ①) ② 헤드폰 잭 노멀 접점 → J702 앰프 입력 잭(L15 ③, 10/1 L2 가운데 유닛). 두 선 모두 가운데 유닛 쪽 플러그를 남기고 끝 부속 쪽을 잘라 잭에 납땜한다(선이 끝 부속에 붙어 다니고 뒷바를 들 때 동글·J702에서 뽑는다, R26) | 3420원 | https://www.eleparts.co.kr/goods/view?no=2925673 | 소모품 | O | 엘레파츠 | C14 |  | 10/1 L2: 용도 수정 (I/O 판·CU 트레이 → 뒤판 출력물·J702) | 확인
42 | [화성고무] 피스고무발 / 28x5 (RUB-E2) | 583원 | 20 | 스피커 파트 2개(각 4개)와 가운데 유닛(6개)의 고무발 14개 + 예비 6. 10/1 L2: 뒷바를 5 mm 띄우고 발은 모두 통로 뒤(y≥248)에 둔다; 모듈 USB 선은 뒷바 밑 닫힌 통로(y212~241 × z0~27)로 지나간다. 본체와 스피커 진동을 떼어 놓는다(D15) | 11660원 | https://www.eleparts.co.kr/goods/view?no=16628292 | 기본 | O | 엘레파츠 | L14 |  | 10/1 L2: 용도 수정 | 확인
43 | [ShenzenAV] 황동 인서트너트 M3x4x4.5 (내경 M3 · 높이 4 · 외경 4.5, 열압입) | 88원 | 6 | 10/1 L2·터치스크린 3판: 화면 뚜껑 이음 레일 2개(SEAM-INS-1~4)의 윗면 y246·y322에 4개 + 예비 2. CAD 구멍 Ø4.0 × 4.5(바깥 Ø4로 그림)에 바깥 4.5를 열압입(물림 0.5, 보통 범위), 길이 4 = CAD 값(v16: Ø4.5 × 4로 그림) → M3×10(L34) 물림 4. 레일을 붙이기 전에 인두로 넣는다 | 528원 | https://www.eleparts.co.kr/goods/view?no=11045752 | 기본 | O | 엘레파츠 | L71 | 10/1 페이지: 개당 80원(VAT 별도) → 88원, M.O.Q 1, 24시간 이내 발송. 인서트 길이가 4가 아니면 자리파기 = 11.5 − (10 − 물림)으로 다시(사양 A-7) | 10/1 L2 신규 | 확인
44 | [NAVI] 종이 양면테이프, 백색/48mm/6m | 1080원 | 1 | EVA 바닥 시트와 비접착 3T 펠트를 프레임에 붙인다 | 1080원 | https://www.eleparts.co.kr/goods/view?no=17897439 | 소모품 | O | 엘레파츠 | ME9 | 2롤 → 1롤(ME9) | 유지 | 확인
45 | [Coms] [NT117] Coms 디지털 테스트기 (DT-832, 9개 항목) | 7600원 | 1 | 페달 T–R–S 저항 측정, 잭 핀 확인, 통전 검사, 허브 역급전(Pi 5V 핀 0V) 확인 | 7600원 | https://www.eleparts.co.kr/goods/view?no=6779159 | 공구 | O | 엘레파츠 | CT11 |  | 유지 | 확인
46 | [Prokit] [CP-301G] PROKIT 정밀 스트리퍼 | 4500원 | 1 | 리본·단선·점퍼선 등 가는 선(AWG 20~30) 피복 벗기기 | 4500원 | https://www.eleparts.co.kr/goods/view?no=3787704 | 공구 | O | 엘레파츠 | CT21 |  | 유지 | 확인
47 | [JAKEMY] JM-CT2-2 5인치 니퍼 | 3960원 | 1 | 센서 리드·헤더 핀 자르기, 출력물 다듬기. 16AWG 스피커선 피복도 니퍼 날로 칼집을 내 벗긴다(CT16) | 3960원 | https://www.eleparts.co.kr/goods/view?no=7663472 | 공구 | O | 엘레파츠 | CT13 |  | 유지 | 확인
48 | [블루텍] 버니어캘리퍼(경제형) NA530-200 (200×0.05) | 13400원 | 1 | 리프 두께·훅 높이·164.5 수축 시편·세트스크루 돌출(1.5±0.05)·펠트 두께 측정 | 13400원 | https://www.eleparts.co.kr/goods/view?no=16549359 | 공구 | O | 엘레파츠 | CT12 |  | 유지 | 확인
49 | [CK6930] 코텍스 쇠톱(대) 300mm K-9301 | 6500원 | 1 | 강철 자르기 공구 (쇠톱·바이메탈 날·평줄·고정 공구) — 프레임 쇠톱, 300 mm 날 | 6500원 | https://www.eleparts.co.kr/goods/view?no=9100747 | 공구 | O | 엘레파츠 | v4cuttools | 9/27 엘레파츠 상품 페이지에서 VAT 포함가를 확인했다. 배송 3,000원(공급가 6만 원 이상 무료) — v3 구매 목록의 엘레파츠 주문과 합배송이라 0원으로 둔다. 6,500원. | v4 신규 | 확인
50 | [LENOX] 쇠톱날(USA) 12인치 T2355 | 2200원 | 2 | 강철 자르기 공구 (쇠톱·바이메탈 날·평줄·고정 공구) — 12인치 쇠톱날(TPI 표기 없음) | 4400원 | https://www.eleparts.co.kr/goods/view?no=4101973 | 공구 | O | 엘레파츠 | v4cuttools | 9/27 엘레파츠 상품 페이지에서 VAT 포함가를 확인했다. 배송 3,000원(공급가 6만 원 이상 무료) — v3 구매 목록의 엘레파츠 주문과 합배송이라 0원으로 둔다. 2,200원. | v4 신규 | 확인
51 | [BD079] Coms 연마봉 평줄 야스리 | 6800원 | 1 | 강철 자르기 공구 (쇠톱·바이메탈 날·평줄·고정 공구) — 철공용 평줄(합금) | 6800원 | https://www.eleparts.co.kr/goods/view?no=12185326 | 공구 | O | 엘레파츠 | v4cuttools | 9/27 엘레파츠 상품 페이지에서 VAT 포함가를 확인했다. 배송 3,000원(공급가 6만 원 이상 무료) — v3 구매 목록의 엘레파츠 주문과 합배송이라 0원으로 둔다. 6,800원. | v4 신규 | 확인
52 | [PD-374] Prokit 공작물 고정 바이스 / 탁상 바이스 | 20000원 | 1 | 강철 자르기 공구 (쇠톱·바이메탈 날·평줄·고정 공구) — 책상 모서리에 조이는 소형 바이스 | 20000원 | https://www.eleparts.co.kr/goods/view?no=2923219 | 공구 | O | 엘레파츠 | v4cuttools | 9/27 엘레파츠 상품 페이지에서 VAT 포함가를 확인했다. 배송 3,000원(공급가 6만 원 이상 무료) — v3 구매 목록의 엘레파츠 주문과 합배송이라 0원으로 둔다. 20,000원. | v4 신규 | 확인
53 | GUOCONN 0.5*22P*300*B FFC 22핀 0.5 mm 300 mm 반대면(B형) — 5개 묶음 | 391원 | 5 | 터치스크린 7인치 (R31) — | 1955원 | https://www.eleparts.co.kr/goods/view?no=18622271 | 기본 | O | 엘레파츠 | v4touch | Pi 5 CAM/DISP 1 ↔ 화면 22핀. 10/1 3판·L2: 경로 약 256 mm(CAD 모델 254, 사양 256.32 → 여유 약 44~46). 해외재고, 평균 발송 10/21. 최소 주문 5개(나머지 예비) | R31 신규: 터치스크린 (9/30 추가, 10/1 Waveshare 7-DSI-TOUCH-C 선택) · 10/1 3판·L2: 리본 길·나사 값 고침 | 확인
54 | GUOCONN 0.5*22P*300*A FFC 22핀 0.5 mm 300 mm 같은 면(A형) — 5개 묶음 (보험) | 395원 | 5 | 터치스크린 7인치 (R31) — | 1975원 | https://www.eleparts.co.kr/goods/view?no=18581287 | 기본 | O | 엘레파츠 | v4touch | 보험: 받침 안에서 45° 두 번 접혀 필요한 접점 면이 반대일 수 있다. 틀리면 재주문에 2주가 걸려 함께 산다. 빼면 1,975원 준다 | R31 신규: 터치스크린 (9/30 추가, 10/1 Waveshare 7-DSI-TOUCH-C 선택) · 10/1 3판·L2: 리본 길·나사 값 고침 | 확인
55 | [엘레파츠] 실리콘 점퍼 케이블 26AWG-RED (20cm, F/F) | 451원 | 1 | 터치스크린 7인치 (R31) — | 451원 | https://www.eleparts.co.kr/goods/view?no=9461190 | 소모품 | O | 엘레파츠 | v4touch | 화면 5 V 연장 1단(Pi GPIO 2번) | R31 신규: 터치스크린 (9/30 추가, 10/1 Waveshare 7-DSI-TOUCH-C 선택) · 10/1 3판·L2: 리본 길·나사 값 고침 | 확인
56 | [엘레파츠] 실리콘 점퍼 케이블 26AWG-BLACK (20cm, F/F) | 451원 | 1 | 터치스크린 7인치 (R31) — | 451원 | https://www.eleparts.co.kr/goods/view?no=9461199 | 소모품 | O | 엘레파츠 | v4touch | 화면 GND 연장 1단(Pi GPIO 6번) | R31 신규: 터치스크린 (9/30 추가, 10/1 Waveshare 7-DSI-TOUCH-C 선택) · 10/1 3판·L2: 리본 길·나사 값 고침 | 확인
57 | [엘레파츠] 실리콘 점퍼 케이블 26AWG-RED (20cm, M/M) | 451원 | 1 | 터치스크린 7인치 (R31) — | 451원 | https://www.eleparts.co.kr/goods/view?no=9756990 | 소모품 | O | 엘레파츠 | v4touch | 5 V 연장 2단(화면 동봉 전원선의 2.54 하우징에 꽂음) | R31 신규: 터치스크린 (9/30 추가, 10/1 Waveshare 7-DSI-TOUCH-C 선택) · 10/1 3판·L2: 리본 길·나사 값 고침 | 확인
58 | [엘레파츠] 실리콘 점퍼 케이블 26AWG-BLACK (20cm, M/M) | 451원 | 1 | 터치스크린 7인치 (R31) — | 451원 | https://www.eleparts.co.kr/goods/view?no=9756998 | 소모품 | O | 엘레파츠 | v4touch | GND 연장 2단 | R31 신규: 터치스크린 (9/30 추가, 10/1 Waveshare 7-DSI-TOUCH-C 선택) · 10/1 3판·L2: 리본 길·나사 값 고침 | 확인
59 | 배송비 — 엘레파츠 | 0원 | 1 | 배송비 | 0원 |  | 소모품 | O
 | 엘레파츠 소계 |  |  |  | 159848원
■ 11번가
60 | 스텐 유두 렌치볼트 M2.5 × 6mm | 200원 | 6 | Pi 5를 출력 받침 기둥 4개(Ø6 × 6, 구멍 Ø2.2 × 5 — 10/1 L2)에 바로 조이는 나사(4개 + 예비 2). R26으로 황동 스탠드오프(L37)가 빠졌다(비용 절감안 CP7) | 1200원 | https://www.11st.co.kr/products/4236198413 | 기본 | O | 굿나잇몰 | L47 |  | 10/1 L2: 용도 수정 | 확인
61 | 삼미스피커(SAAT) CW-100B25 4인치 풀레인지 8Ω 25W (KS 인증) | 9600원 | 2 | 좌우 스피커 유닛 2개(R25: 서브 없음). 스피커 파트(오꾸메 밀폐 상자, 안 부피 2.16 L · 유닛 뺀 2.06 L — 10/1 L2)의 수평에서 40° 기운 출력 앞판에 앞에서 단다(EVA 가스켓 3T + M4×12(L70) 4개 → 앞판 M4 열압입 인서트(L69) PCD115). 축이 가운데 귀와 17.3° 어긋남(W1 한계 20°). 앰프(L53)가 채널당 약 21 W(20 V)를 준다 | 19200원 | https://www.11st.co.kr/products/1565354988 | 기본 | O | 세운상가새한음향 | L07 |  | 10/1 L2: 용도 수정 | 확인
62 | 스텐 유두 렌치볼트 M4 × 12mm | 80원 | 10 | 10/1 L2: 스피커 유닛 CW-100B25를 앞판 인서트(L69)에 고정(유닛 플랜지 4 + EVA 가스켓 3을 지나 인서트에 물림), 4 × 2 = 8 + 예비 2. M4×12보다 긴 나사 금지(아래 구멍 밑 밀폐면 2.78 mm). 육각 렌치 2.5 mm(T11) | 800원 | https://www.11st.co.kr/products/4236198413 | 기본 | O | 굿나잇몰 | L70 | 10/1 옵션 값: 유두 M4 12mm 80원. 같은 상품의 옵션, 굿나잇몰 묶음배송 | 10/1 L2 신규 | 확인
63 | 두유레디 구름솜 300g (100% 국내산 할로우화이버) | 2700원 | 1 | 밀폐 스피커 상자 2개의 흡음재. 10/1 L2(W1 조건): 상자마다 약 35 g을 상자 전체에 느슨하게, 바깥 끝 100 mm에 모으고 유닛 뒤 10 mm·폴 벤트 축 10 mm는 비운다. 300 g이라 충분 | 2700원 | https://www.11st.co.kr/products/2325598213 | 기본 | O | 두유레디 | L12 |  | 10/1 L2: 용도 수정 | 확인
64 | 스텐 둥근머리 직결피스 8호(Ø4.2) 13mm | 40원 | 20 | 10/1 L2: 고무발 14개 고정 + 예비 6 (둥근머리 13 mm는 고무발에만 쓴다). 16 mm 이상은 스피커 밀폐 바닥을 뚫으므로 13 mm 이하(발 머리 자리 Ø9×2 가정 → 발 3 + 합판 10 물림). L1의 도브테일·CU 트레이·XT30 받침은 없어졌고, 뒤판 출력물·보조배터리 받침은 접시머리(L77), 허브 선반 받침은 M3×12 태핑(L78), 이음 레일·XT30 집게는 MS 폴리머로 붙인다 | 800원 | https://www.11st.co.kr/products/4353471537 | 기본 | O | 굿나잇몰 | L49 | 같은 상품의 옵션. 굿나잇몰 묶음배송(주문 화면에서 묶음 여부 확인). 10/1 L2 수량 54 → 20 | 10/1 L2 수량 변경 (54 → 20) | 확인
65 | 스텐 둥근머리 직결피스 8호(Ø4.2) 19mm | 50원 | 8 | PETG 그릴 8곳 고정(그릴마다 4개, 떨리지 않게 모두). 10/1 L2: 19 mm 이하 — 25 mm는 앞판 아래 파일럿 끝 2.15 mm 밑 밀폐면을 뚫는다 | 400원 | https://www.11st.co.kr/products/4353471537 | 기본 | O | 굿나잇몰 | L49 | 같은 상품의 옵션. 굿나잇몰 묶음배송(주문 화면에서 묶음 여부 확인) | 10/1 L2: 용도 수정 (19 mm 이하) | 확인
66 | 스텐 접시머리 직결피스 8호(Ø4.2) 13mm | 40원 | 8 | 10/1 L2: 뒤판 출력물(PR-BACKPLATE) 바닥 탭 2 + 보조배터리 받침 4 = 6 + 예비 2. 구멍의 접시 자리는 모델에 있다(L49는 둥근머리) | 320원 | https://www.11st.co.kr/products/4350230243 | 기본 | O | 굿나잇몰 | L77 | 10/1 옵션 값: 4.2mm×13mm 40원(같은 판매자의 접시머리 직결피스 상품). 굿나잇몰 묶음배송(주문 화면에서 묶음 여부 확인) | 10/1 L2 신규 | 확인
67 | 스텐 트러스 태핑 피스 1종 M3 × 12mm | 50원 | 4 | 10/1 L2: 허브 위 앰프 선반의 받침 2개를 가운데 뒤판(오꾸메)에 고정(받침 10 × 8에 8호가 들어가지 않음), 2 + 예비 2. CAD는 "Ø3 × 12~13 둥근머리 목재 나사, 머리 Ø6 이하" — 트러스 머리 약 Ø6이라 받으면 머리 자리를 확인 | 200원 | https://www.11st.co.kr/products/4236198586 | 기본 | O | 굿나잇몰 | L78 | 10/1 옵션 값: M3 12mm 50원(판매가 40 + 10). 굿나잇몰 묶음배송 | 10/1 L2 신규 | 확인
68 | 스텐 유두 렌치볼트 M3 × 10mm | 60원 | 28 | 센서 바·센서 기판을 왼쪽 받침 기둥에 고정(모듈 7 + 끝 부속 2 = 9곳 × 2 = 18, PETG 구멍에 직접 탭) + 10/1 L2·터치스크린 3판: 화면 뚜껑(CU-SCREENLID)을 이음 레일의 M3 열압입 인서트(L71) 4곳에 고정(앞 y246 2 · 뒤 y322 2, 자리파기 Ø6.5 × 5.5, 인서트 물림 4) + 예비 6 = 28. L2에서 CU 트레이 부품 나사 14개는 M3×5(L76)·M3×6(L35)로 바뀌고 토글 래치(L64) 8개는 없어졌다 | 1680원 | https://www.11st.co.kr/products/4236198413 | 기본 | O | 굿나잇몰 | L34 | 10/1 L2 수량 54 → 28 (R31 2판의 "CU 뚜껑 앞 모서리 2곳 + 예비 2"는 3판에서 레일 인서트 4곳으로 바뀜) | 10/1 L2 수량 변경 (54 → 28) | 확인
69 | 스텐 유두 렌치볼트 M3 × 16mm | 90원 | 6 | 10/1 L2: 방진 브래킷 BRK2-L/R을 끝 부속 볼 뒷면 M3 자리(볼 속 너트 L31)에 그로밋(L42) + M4 와셔(L36)로 고정, 2 × 2 = 4 + 예비 2. M3×10은 볼 속 너트에 닿지 않는다(L1부터 빠져 있던 줄). 육각 렌치 2 mm(T04), 스피커를 올리기 전에 조임 | 540원 | https://www.11st.co.kr/products/4236198413 | 기본 | O | 굿나잇몰 | L75 | 10/1 옵션 값: 유두 M3 16mm 90원. 같은 상품의 옵션, 굿나잇몰 묶음배송 | 10/1 L2 신규 | 확인
70 | 스텐 유두 렌치볼트 M3 × 5mm | 40원 | 10 | 10/1 L2: 가운데 유닛 보드를 5 mm 출력 받침 기둥(구멍 Ø2.5~2.7 × 4, 바닥 1.0)에 직접 탭 — 강압 모듈 4 · J702 잭 기판 2 · PED 보드 2 = 8 + 예비 2. 6 mm 이상은 기둥 바닥을 뚫고 붙인 기둥을 밀어 올린다(L1의 CU 트레이 M3×10 대신) | 400원 | https://www.11st.co.kr/products/4236198413 | 기본 | O | 굿나잇몰 | L76 | 10/1 옵션 값: 유두 M3 5mm 40원. 같은 상품의 옵션, 굿나잇몰 묶음배송 | 10/1 L2 신규 | 확인
71 | 스텐 유두 렌치볼트 M3 × 6mm | 40원 | 24 | 제어 기판을 프레임의 매단 보스 4개에 고정 — 모듈마다 대각 2곳을 밑에서 나사로 조임(7 × 2 = 14 + 예비 6), 나머지 2곳은 보스의 위치 핀. r4.5: 바닥 구멍으로 기판을 밑에서 넣음. 스텐 유두(ISO 7380, 머리 Ø5.7 × 1.65) + 10/1 L2: 앰프 보드(XH-A232)를 선반 받침에 4개(받침 + 선반 관통, PETG 직접 탭) → 24 | 960원 | https://www.11st.co.kr/products/4236198413 | 기본 | O | 굿나잇몰 | L35 |  | 10/1 L2 수량 변경 (20 → 24, 앰프 4) | 확인
72 | 스텐 와셔 M4x9x0.5T | 10원 | 20 | 고무발 고정 피스 머리 밑 와셔 14 + 10/1 L2: BRK2 방진 브래킷의 M3×16(L75) 머리 밑 4 + 예비 2 (v4: 클램프 나사용 32개는 빠짐) | 200원 | https://www.11st.co.kr/products/4236198413 | 기본 | O | 굿나잇몰 | L36 |  | v4 수량 변경 (60 → 20) · 10/1 L2: 용도 수정 | 확인
73 | 에바폼 EVA 컬러 고밀도 칼라스펀지 3T (E-210 검정, 330×490) | 2100원 | 3 | 모듈 7개·끝 부속 2개 바닥 전체에 붙이는 3T 시트(164×211 한 장씩). 남는 조각은 스피커 유닛 가스켓과 가운데 유닛 ↔ 스피커 파트 맞닿는 면의 띠(R26) | 6300원 | https://www.11st.co.kr/products/7591566666 | 기본 | O | 상우아트 | MEV1 | 상우아트 묶음배송 | 유지 | 확인
74 | [대원] 얇은 칼라펠트지 H 두께0.5mm 접착 30x45cm (H-20 검정) | 1500원 | 1 | 가이드 탭 양옆 부싱(0.5T, 모듈당 24조각)과, 2겹으로 겹친 뒤 스톱 펠트(1T, y138~144) | 1500원 | https://www.11st.co.kr/products/8517880969 | 기본 | O | 상우아트 | MEV1 | EVA와 같은 판매자라 묶음배송 | 유지 | 확인
75 | 텅스텐 퍼티 소프트 싱커 무게추 (낚시용, 22 g) | 8750원 | 1 | 무거운 건반만 낮추는 건반별 무게 미세 조정(필요할 때만, 백 ≤6 g·흑 ≤2.5 g) | 8750원 | https://www.11st.co.kr/products/9579455646 | 소모품 | O | 골드그로브 | ME14 |  | 유지 | 확인
76 | 육각 렌치 2.5mm (볼트 상품 옵션) | 600원 | 1 | M3 렌치볼트 조이기 | 600원 | https://www.11st.co.kr/products/4236198413 | 공구 | O | 굿나잇몰 | T11 |  | 유지 | 확인
77 | 육각 렌치 2 mm (볼트 상품 옵션) | 600원 | 1 | v4 캡스턴 M3 버튼헤드 조정용 | 600원 | https://www.11st.co.kr/products/4236198413 | 공구 | O | 굿나잇몰 | T04 | v4에서 추가 (세트스크루용 1.5 mm 대신) | v4 신규 | 확인
78 | [onezaze] 스텐환봉 절단판매 1M (4mm) | 1500원 | 2 | 건반 봉 SUS304 Ø4 × 161.4 — SUS 환봉 Ø4 × 1000 mm | 3000원 | https://www.11st.co.kr/products/1304631510 | 기본 | O | onezaze | v4keyrod | 9/27 상품 페이지에서 1,500원, 배송비 3,500원, 재고 충분(99,997,144)을 확인했다. 봉 1 = 161.4 ×6 + 20.4, 봉 2 = 161.4 ×2 + 43.9(나머지 약 630 mm 남음). | v4 신규 | 확인
79 | [onezaze] 스텐환봉 절단판매 1M (4mm) | 1500원 | 2 | 레버 봉 SUS304 Ø4 × 161.4 (h9) — 건반 봉과 같은 봉 — SUS 환봉 Ø4 × 1000 mm | 3000원 | https://www.11st.co.kr/products/1304631510 | 기본 | O | onezaze | v4levershaft | 9/27 11번가 상품 페이지에서 1,500원(옵션 없음), 배송비 3,500원(한진택배, 9/29 도착 예정)을 확인했다. 건반 봉 카드(keyrod)의 현재 안과 같은 상품·가게라 한 주문으로 묶으면 배송비 3,500원이 한 번만 든다. 페이지에 공차(h9) 표기는 없다 — 받은 뒤 마이크로미터로 3.97~4.00 확인. | v4 신규 | 확인
80 | [대원] 얇은 칼라펠트지 H 0.5mm 접착 30×45cm (v3 L40 재사용) | 0원 | 1 | 부싱 천 0.5T (스냅 노치·밸런스 핀 홈·가이드 탭) — 0.5T 폴리에스터 공예 펠트, 접착, 30×45 cm | 0원 | https://www.11st.co.kr/products/8517880969 | 기본 | O | 상우아트 | v4cloth | 9/27 11번가 페이지에서 1,500원/장, 재고 있음, 배송비 3,000원(7만 원 이상 무료)을 확인했다. 이미 v3 목록 L40(2장)에 들어 있으므로 여기서는 0원으로 잡았다. v3에서 L40의 한 용도였던 뒤 스톱 2겹 띠가 W1+에서 없어져, 약 250 cm²(1T·1.5T를 L40으로 겹치는 펠트 대안을 고르면 +약 250 cm²)만 쓴다. 2장 대신 1장만 사도 된다(v3 L40 줄에서 1,500원 절감). | v4 신규 | 확인
81 | 크레타칼라 흑연파우더(소/30ml) | 2750원 | 1 | 흑연 가루 (캡스턴이 닿는 펠트 면) — 미술용 흑연 가루 30 ml | 2750원 | https://www.11st.co.kr/products/1333385437 | 소모품 | O | 비젼몰 | v4graphite | 9/27 페이지: 2,750원, 재고 있음, 배송비 3,000원(8만 원 이상 무료), 9/29 도착 예정. 11번가 다른 판매자의 30 ml는 3,960원 이상이었다. | v4 신규 | 확인
82 | 세메다인 슈퍼X 8008 탄성접착제 백색 20 mL (AX-022) | 8000원 | 2 | MS 폴리머 탄성 접착제 — 강철 블록을 레버 캐리어에 붙임 — 1액형 습기 경화 MS 폴리머(변성 실리콘) 탄성 접착제, 20 mL 튜브, 백색 | 16000원 | https://www.11st.co.kr/products/7459325704 | 소모품 | O | 주영종합상사 | v4msbond | 9/29 페이지: 8,000원(VAT 포함), 배송비 3,000원(주문 1번), 판매 중, 9/30 도착 예정. 재고 수량은 나오지 않는다. | r4.4 고침 2b: 강철 블록 접착 — 에폭시 → MS 폴리머 (9/29) | 확인
83 | 스텐 유두 렌치볼트 M3 × 20 mm (굿나잇몰, 기존 볼트 주문에 옵션 추가) | 70원 | 4 | 터치스크린 7인치 (R31) — | 280원 | https://www.11st.co.kr/products/4236198413 | 기본 | O | 굿나잇몰 | v4touch | 경첩 축 2 + 받침다리 축 1 + 예비 1, PETG 구멍에 직접 탭(ISO 7380, 렌치 2 mm). 10/1 옵션 값 확인: 유두 M3 20mm 70원(이전 추정 100원) | R31 신규: 터치스크린 (9/30 추가, 10/1 Waveshare 7-DSI-TOUCH-C 선택) · 10/1 3판·L2: 리본 길·나사 값 고침 | 확인
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

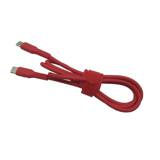
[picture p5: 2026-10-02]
hardware/bom/final-bom/site/img/c60b796c29c7.jpg

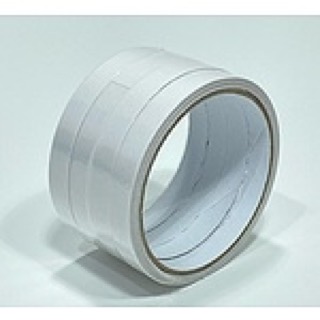
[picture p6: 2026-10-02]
hardware/bom/final-bom/site/img/a4c479a57142.jpg

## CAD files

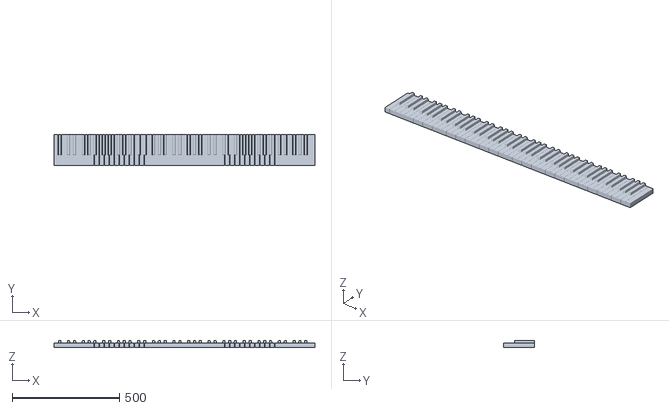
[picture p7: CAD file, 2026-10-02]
hardware/mechanical/before/cad/piano_88keys_full_1to1.stl
1218.3 x 145.0 x 30.5

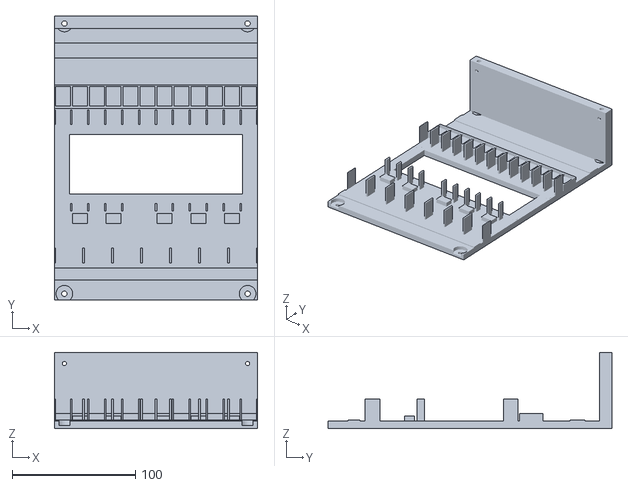
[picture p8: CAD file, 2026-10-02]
hardware/mechanical/before/cad/stl/bed12.stl
164.5 x 230.0 x 61.7

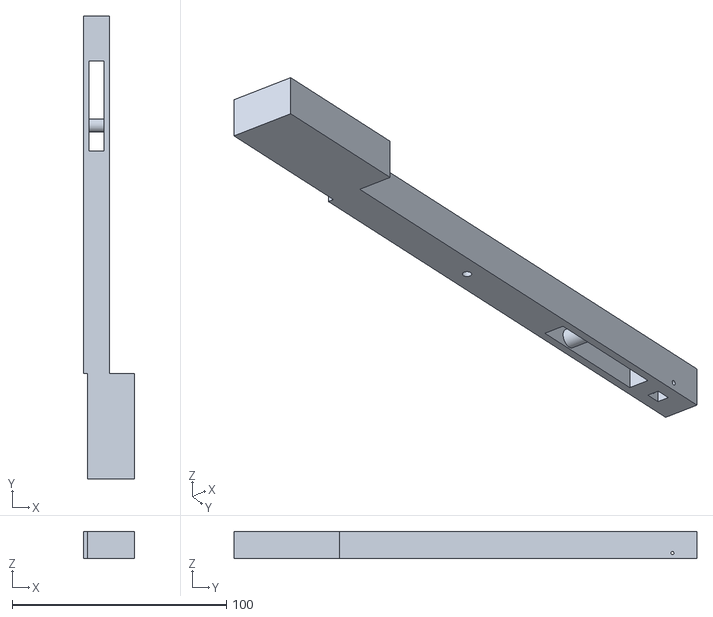
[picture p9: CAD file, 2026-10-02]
hardware/mechanical/before/cad/stl/v1.5-multipart/white_F.stl
23.9 x 216.0 x 12.7

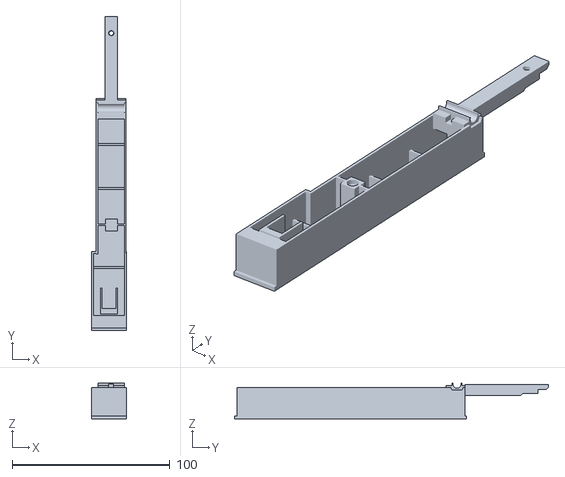
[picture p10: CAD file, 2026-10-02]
hardware/mechanical/cad/stl/print/01_건반/백건_A0__1개.stl
22.0 x 199.0 x 22.8

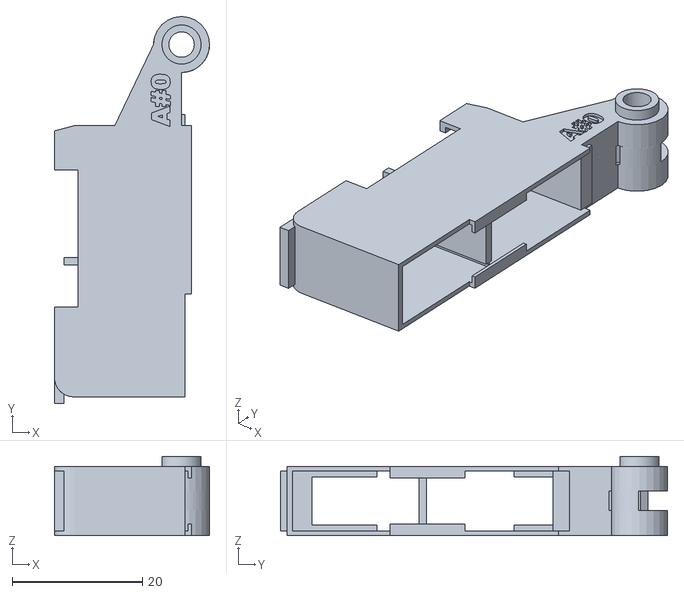
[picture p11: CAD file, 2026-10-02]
hardware/mechanical/cad/stl/print/02_레버캐리어/레버캐리어_A#0__1개.stl
23.8 x 59.4 x 12.1

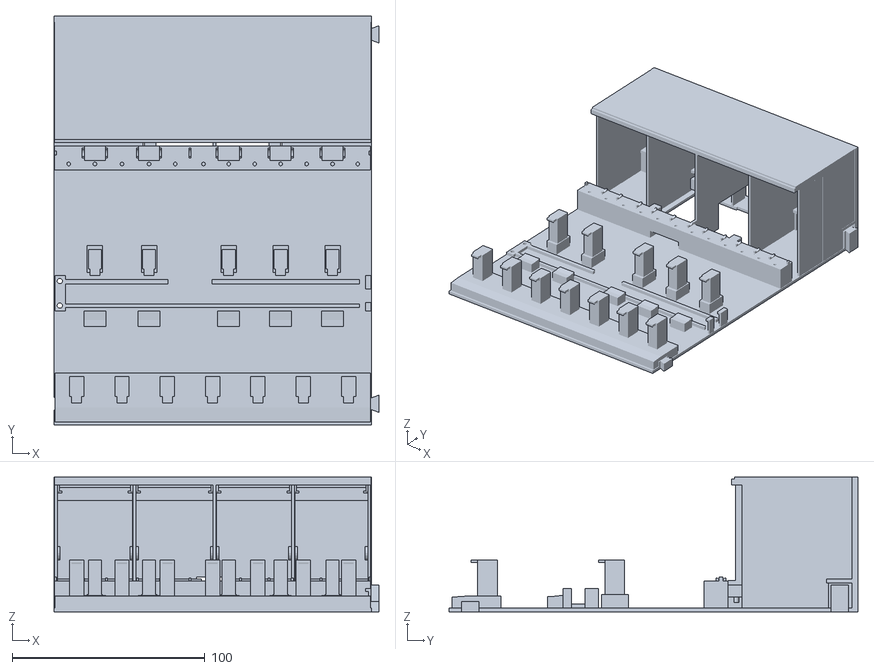
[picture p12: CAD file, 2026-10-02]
hardware/mechanical/cad/stl/print/03_프레임/프레임_모듈__7개.stl
168.5 x 212.0 x 69.8

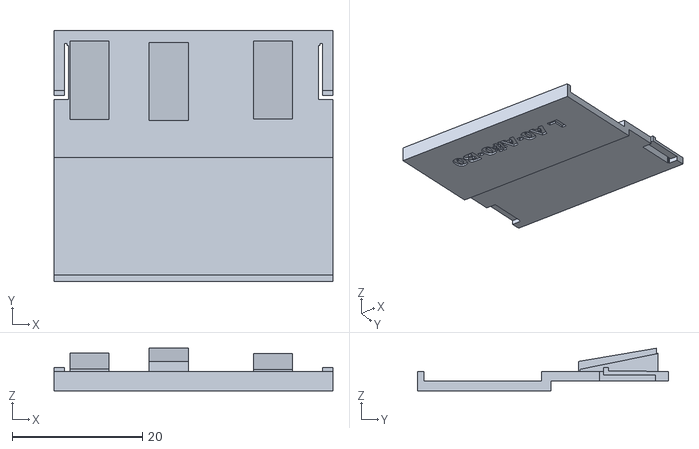
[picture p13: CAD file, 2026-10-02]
hardware/mechanical/cad/stl/print/04_센서바·패드바·가림판·마개/패드바_끝부속_왼쪽__1개.stl
42.8 x 38.5 x 6.54

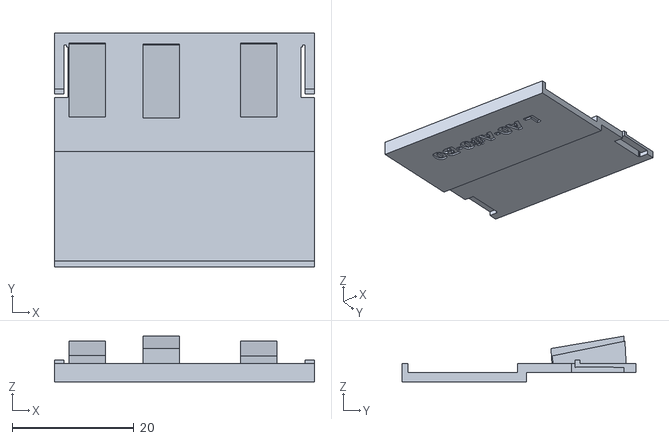
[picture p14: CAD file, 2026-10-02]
hardware/mechanical/cad/stl/print/04b_패드바_PORON5T용/패드바_끝부속_왼쪽_PORON5T용__1개.stl
42.8 x 38.5 x 7.53

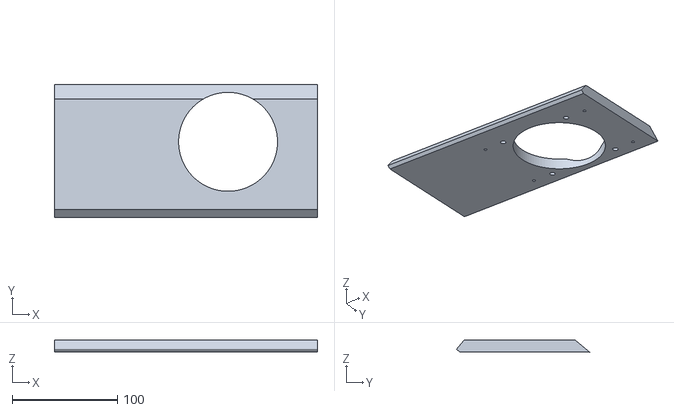
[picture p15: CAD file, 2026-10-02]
hardware/mechanical/cad/stl/print/05_본체출력물/스피커앞판_경사배플_L__1개.stl
250.0 x 126.5 x 11.5

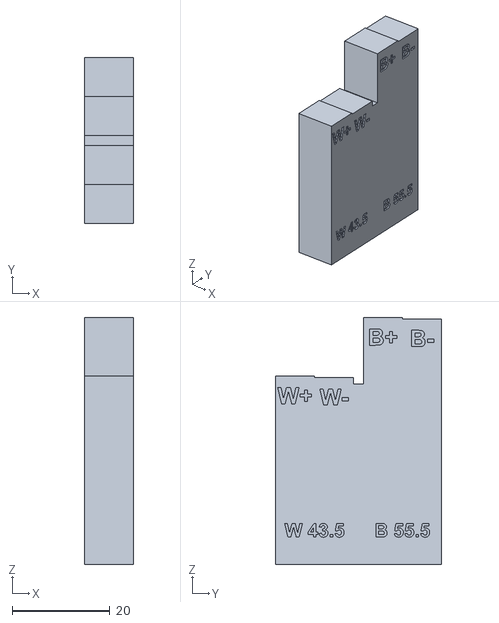
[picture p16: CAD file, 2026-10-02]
hardware/mechanical/cad/stl/print/06_출력공구/공구_높이블록_T1b__1개.stl
10.0 x 34.0 x 50.6

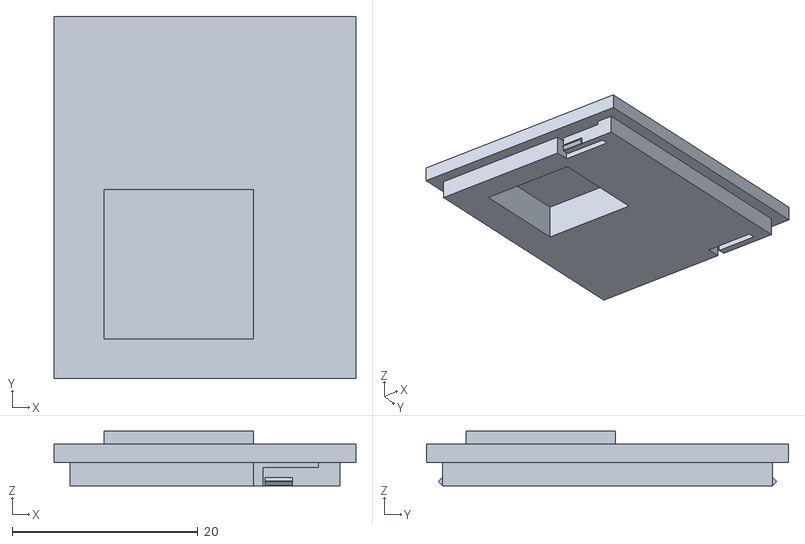
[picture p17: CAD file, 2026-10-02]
hardware/mechanical/cad/stl/print/07_터치스크린/점검창덮개__1개.stl
32.5 x 39.0 x 5.90

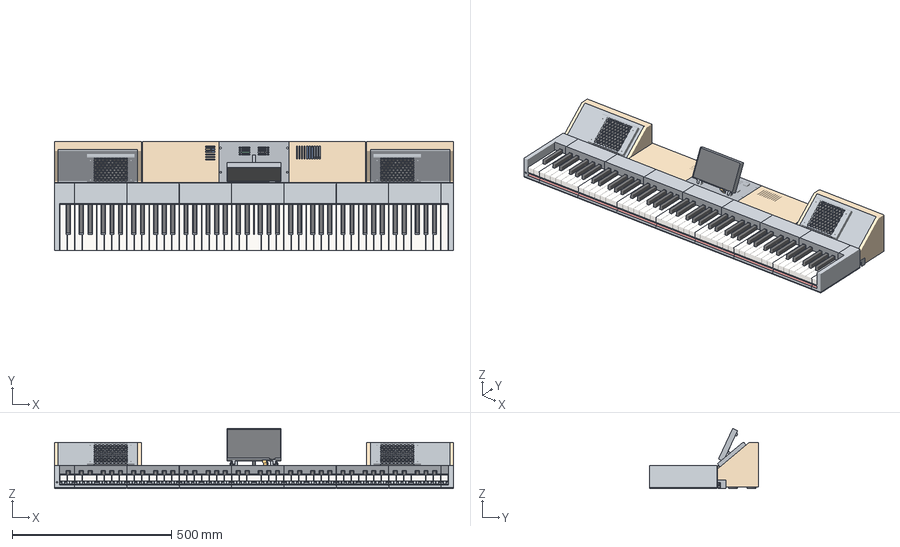
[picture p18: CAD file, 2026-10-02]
hardware/mechanical/cad/Toccata_전체조립.3mf
1254.0 x 342.5 x 189.2 mm
O1 백건 · 출력
O1 구매품 · 구매 x 4
O1 구매품 · 소모품 x 3
O1 레버 · 출력
O1 흑건 · 출력
O1 프레임 · 출력 x 5
O2 백건 · 출력
O2 구매품 · 구매 x 4
O2 구매품 · 소모품 x 3
O2 레버 · 출력
O2 흑건 · 출력
O2 프레임 · 출력 x 5
O3 백건 · 출력
O3 구매품 · 구매 x 4
O3 구매품 · 소모품 x 3
O3 레버 · 출력
O3 흑건 · 출력
O3 프레임 · 출력 x 5
O4 백건 · 출력
O4 구매품 · 구매 x 4
O4 구매품 · 소모품 x 3
O4 레버 · 출력
O4 흑건 · 출력
O4 프레임 · 출력 x 5
O5 백건 · 출력
O5 구매품 · 구매 x 4
O5 구매품 · 소모품 x 3
O5 레버 · 출력
O5 흑건 · 출력
O5 프레임 · 출력 x 5
O6 백건 · 출력
O6 구매품 · 구매 x 4
O6 구매품 · 소모품 x 3
O6 레버 · 출력
O6 흑건 · 출력
O6 프레임 · 출력 x 5
O7 백건 · 출력
O7 구매품 · 구매 x 4
O7 구매품 · 소모품 x 3
O7 레버 · 출력
O7 흑건 · 출력
O7 프레임 · 출력 x 5
끝 부속 왼쪽 백건 · 출력
끝 부속 왼쪽 구매품 · 구매 x 4
끝 부속 왼쪽 구매품 · 소모품 x 3
끝 부속 왼쪽 레버 · 출력
끝 부속 왼쪽 흑건 · 출력
끝 부속 왼쪽 프레임 · 출력 x 5
끝 부속 오른쪽 백건 · 출력
끝 부속 오른쪽 구매품 · 구매 x 4
끝 부속 오른쪽 구매품 · 소모품 x 3
끝 부속 오른쪽 레버 · 출력
끝 부속 오른쪽 프레임 · 출력 x 5
스피커 파트 L · 합판
스피커 파트 R · 합판
스피커 파트 L · 출력
스피커 파트 R · 출력
스피커 파트 L · 구매
스피커 파트 R · 구매
스피커 파트 L · 소모품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

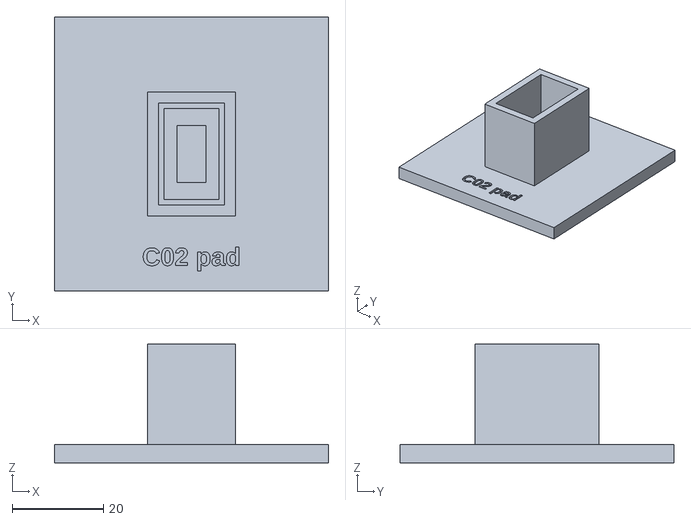
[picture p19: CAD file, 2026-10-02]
hardware/mechanical/key-action-v4/printables/stage0/stl/C02a.stl
60.0 x 60.0 x 26.0

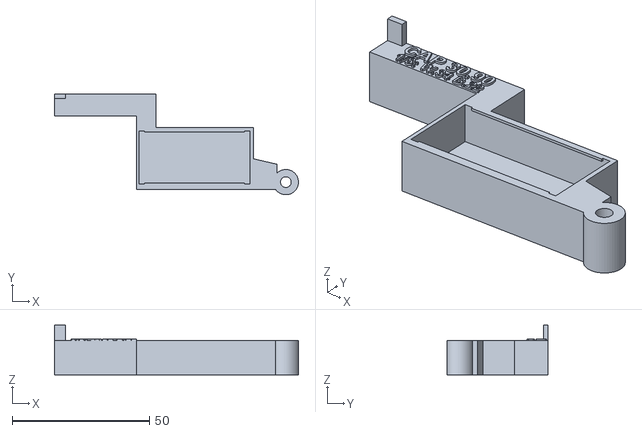
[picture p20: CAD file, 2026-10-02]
hardware/mechanical/key-action-v4/printables/tools/stl/tool_capstan_gauge.stl
88.9 x 36.6 x 18.1

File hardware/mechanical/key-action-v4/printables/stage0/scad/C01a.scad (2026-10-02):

// Toccata stage-0 C01a - 패드 반발 진자대 (받침·눈금판·패드 자리) (generated by make_stage0.py; print orientation, z = build direction)
$fn = 64;
difference(){
union(){
translate([0,0,0.0000]) linear_extrude(height=4.0000) polygon([[-60.0000,-75.0000],[60.0000,-75.0000],[60.0000,0.0000],[38.0000,0.0000],[37.9479,1.9888],[37.7918,3.9721],[37.5322,5.9445],[37.1696,7.9006],[36.7052,9.8351],[36.1401,11.7426],[35.4761,13.6180],[34.7147,15.4560],[33.8582,17.2516],[32.9090,19.0000],[31.8695,20.6963],[30.7426,22.3358],[29.5315,23.9142],[28.2395,25.4270],[26.8701,26.8701],[25.4270,28.2395],[23.9142,29.5315],[22.3358,30.7426],[20.6963,31.8695],[19.0000,32.9090],[17.2516,33.8582],[15.4560,34.7147],[13.6180,35.4761],[11.7426,36.1401],[9.8351,36.7052],[7.9006,37.1696],[5.9445,37.5322],[3.9721,37.7918],[1.9888,37.9479],[0.0000,38.0000],[-1.9888,37.9479],[-3.9721,37.7918],[-5.9445,37.5322],[-7.9006,37.1696],[-9.8351,36.7052],[-11.7426,36.1401],[-13.6180,35.4761],[-15.4560,34.7147],[-17.2516,33.8582],[-19.0000,32.9090],[-20.6963,31.8695],[-22.3358,30.7426],[-23.9142,29.5315],[-25.4270,28.2395],[-26.8701,26.8701],[-28.2395,25.4270],[-29.5315,23.9142],[-30.7426,22.3358],[-31.8695,20.6963],[-32.9090,19.0000],[-33.8582,17.2516],[-34.7147,15.4560],[-35.4761,13.6180],[-36.1401,11.7426],[-36.7052,9.8351],[-37.1696,7.9006],[-37.5322,5.9445],[-37.7918,3.9721],[-37.9479,1.9888],[-38.0000,0.0000],[-60.0000,0.0000]]);
translate([0,0,0.0000]) linear_extrude(height=64.0000) polygon([[-78.0000,-75.0000],[78.0000,-75.0000],[78.0000,-70.0000],[-78.0000,-70.0000]]);
hull(){translate([-58.0000,-70.0000,3.9900]) cube([4.0000,0.0100,45.0100]);translate([-58.0000,-70.0000,3.9900]) cube([4.0000,40.0000,0.0100]);}
hull(){translate([18.0000,-70.0000,3.9900]) cube([4.0000,0.0100,45.0100]);translate([18.0000,-70.0000,3.9900]) cube([4.0000,40.0000,0.0100]);}
hull(){translate([50.0000,-70.0000,3.9900]) cube([4.0000,0.0100,45.0100]);translate([50.0000,-70.0000,3.9900]) cube([4.0000,40.0000,0.0100]);}
translate([0.0000,0.0000,3.9900]) cylinder(h=6.0100, d=12.0000, $fn=64);
translate([0,0,3.9900]) linear_extrude(height=6.0100) polygon([[11.7219,27.6151],[10.9707,27.9221],[10.2114,28.2086],[9.4446,28.4745],[8.6710,28.7196],[7.8909,28.9436],[7.1051,29.1465],[6.3142,29.3280],[5.5185,29.4881],[4.7189,29.6265],[3.9158,29.7433],[3.1098,29.8384],[2.3016,29.9116],[1.4916,29.9629],[0.6806,29.9923],[-0.1309,29.9997],[-0.9423,29.9852],[-1.7531,29.9487],[-2.5625,29.8904],[-3.3701,29.8101],[-4.1752,29.7080],[-4.9772,29.5842],[-5.7757,29.4388],[-6.5698,29.2718],[-7.3592,29.0834],[-8.1432,28.8737],[-8.9212,28.6428],[-9.6928,28.3910],[-10.4572,28.1185],[-11.2139,27.8253],[-11.9625,27.5118],[-12.7023,27.1782],[-13.4328,26.8246],[-14.1534,26.4515],[-14.8638,26.0589],[-15.5632,25.6474],[-16.2512,25.2170],[-16.9274,24.7682],[-17.5912,24.3012],[-18.2421,23.8165],[-18.8796,23.3144],[-19.5033,22.7952],[-20.1128,22.2593],[-20.7075,21.7071],[-21.2871,21.1390],[-21.8511,20.5555],[-22.3991,19.9569],[-22.9308,19.3437],[-23.4456,18.7164],[-23.9433,18.0754],[-24.4235,17.4211],[-24.8858,16.7541],[-25.3298,16.0748],[-25.7554,15.3838],[-26.1621,14.6815],[-26.5496,13.9684],[-26.9178,13.2452],[-27.2662,12.5122],[-27.5946,11.7701],[-27.9029,11.0194],[-28.1908,10.2606],[-28.4580,9.4943],[-28.7044,8.7211],[-28.9298,7.9414],[-29.1340,7.1560],[-29.3169,6.3653],[-29.4784,5.5700],[-29.6183,4.7706],[-29.7365,3.9677],[-29.8329,3.1619],[-29.9075,2.3538],[-29.9602,1.5439],[-29.9910,0.7330],[-29.9999,-0.0785],[-29.9868,-0.8900],[-29.9518,-1.7008],[-29.8948,-2.5103],[-29.8159,-3.3180],[-29.7153,-4.1233],[-29.5929,-4.9256],[-29.4488,-5.7243],[-29.2832,-6.5187],[-29.0962,-7.3085],[-28.8878,-8.0928],[-28.6584,-8.8712],[-28.4079,-9.6432],[-28.1367,-10.4081],[-27.8448,-11.1653],[-27.5326,-11.9144],[-27.2003,-12.6548],[-26.8480,-13.3859],[-26.4761,-14.1073],[-26.0848,-14.8183],[-25.6745,-15.5184],[-25.2453,-16.2072],[-24.7977,-16.8841],[-24.3319,-17.5487],[-23.8483,-18.2005],[-23.3473,-18.8389],[-22.8292,-19.4635],[-22.2943,-20.0739],[-21.7432,-20.6696],[-21.1761,-21.2502],[-20.5936,-21.8152],[-19.9960,-22.3643],[-19.3837,-22.8970],[-18.7573,-23.4129],[-18.1171,-23.9117],[-17.4637,-24.3930],[-16.7975,-24.8565],[-16.1190,-25.3017],[-15.4287,-25.7285],[-14.7271,-26.1364],[-14.0148,-26.5252],[-13.2921,-26.8946],[-12.5598,-27.2443],[-11.8183,-27.5741],[-11.0681,-27.8836],[-10.3098,-28.1728],[-9.5440,-28.4414],[-8.7712,-28.6891],[-5.5551,-18.1698],[-6.0445,-18.0129],[-6.5295,-17.8428],[-7.0098,-17.6596],[-7.4849,-17.4636],[-7.9545,-17.2547],[-8.4184,-17.0332],[-8.8760,-16.7993],[-9.3272,-16.5531],[-9.7715,-16.2947],[-10.2087,-16.0244],[-10.6384,-15.7424],[-11.0603,-15.4489],[-11.4742,-15.1441],[-11.8796,-14.8282],[-12.2764,-14.5014],[-12.6641,-14.1640],[-13.0426,-13.8163],[-13.4116,-13.4585],[-13.7707,-13.0908],[-14.1198,-12.7135],[-14.4585,-12.3269],[-14.7866,-11.9313],[-15.1039,-11.5270],[-15.4102,-11.1142],[-15.7052,-10.6933],[-15.9887,-10.2646],[-16.2605,-9.8283],[-16.5204,-9.3849],[-16.7682,-8.9346],[-17.0038,-8.4778],[-17.2268,-8.0147],[-17.4373,-7.5458],[-17.6351,-7.0714],[-17.8199,-6.5918],[-17.9917,-6.1073],[-18.1503,-5.6185],[-18.2956,-5.1254],[-18.4276,-4.6287],[-18.5460,-4.1285],[-18.6509,-3.6254],[-18.7422,-3.1196],[-18.8197,-2.6114],[-18.8834,-2.1014],[-18.9334,-1.5899],[-18.9694,-1.0772],[-18.9916,-0.5637],[-18.9999,-0.0497],[-18.9943,0.4642],[-18.9748,0.9778],[-18.9414,1.4907],[-18.8942,2.0025],[-18.8331,2.5129],[-18.7582,3.0214],[-18.6696,3.5277],[-18.5674,4.0314],[-18.4516,4.5321],[-18.3222,5.0296],[-18.1795,5.5233],[-18.0234,6.0131],[-17.8542,6.4984],[-17.6719,6.9789],[-17.4766,7.4544],[-17.2686,7.9244],[-17.0479,8.3886],[-16.8148,8.8467],[-16.5693,9.2983],[-16.3117,9.7431],[-16.0422,10.1807],[-15.7610,10.6109],[-15.4682,11.0334],[-15.1641,11.4477],[-14.8489,11.8537],[-14.5228,12.2510],[-14.1861,12.6394],[-13.8390,13.0185],[-13.4818,13.3880],[-13.1148,13.7478],[-12.7381,14.0975],[-12.3521,14.4369],[-11.9571,14.7658],[-11.5533,15.0838],[-11.1411,15.3908],[-10.7207,15.6865],[-10.2925,15.9708],[-9.8567,16.2433],[-9.4137,16.5040],[-8.9638,16.7526],[-8.5074,16.9889],[-8.0448,17.2128],[-7.5762,17.4241],[-7.1021,17.6227],[-6.6229,17.8084],[-6.1387,17.9810],[-5.6501,18.1405],[-5.1574,18.2866],[-4.6608,18.4195],[-4.1609,18.5388],[-3.6579,18.6446],[-3.1523,18.7367],[-2.6443,18.8151],[-2.1344,18.8797],[-1.6229,18.9306],[-1.1103,18.9675],[-0.5968,18.9906],[-0.0829,18.9998],[0.4311,18.9951],[0.9447,18.9765],[1.4577,18.9440],[1.9696,18.8976],[2.4800,18.8375],[2.9886,18.7635],[3.4951,18.6758],[3.9990,18.5744],[4.4999,18.4594],[4.9976,18.3310],[5.4916,18.1891],[5.9816,18.0339],[6.4672,17.8655],[6.9481,17.6840],[7.4239,17.4896]]);
hull(){
translate([0,0,0.0000]) linear_extrude(height=25.0000) polygon([[-14.0992,-49.3733],[-20.3751,-24.1421],[-39.2985,-28.8490],[-33.0226,-54.0802]]);
translate([0,0,0.0000]) linear_extrude(height=25.0000) polygon([[-43.2985,-70.0000],[-29.2985,-70.0000],[-29.2985,-66.0000],[-43.2985,-66.0000]]);
}
}
translate([0.0000,0.0000,-1.0000]) cylinder(h=12.5000, d=3.9000, $fn=64);
translate([0,0,9.5000]) linear_extrude(height=16.5000) polygon([[-14.1078,-46.4386],[-19.0078,-26.7389],[-23.1031,-27.7575],[-18.2031,-47.4573]]);
translate([0,0,9.4000]) linear_extrude(height=0.8000) polygon([[6.1394,17.4527],[8.1916,23.0909],[8.5674,22.9541],[6.5153,17.3159]]);
translate([9.5082,26.1235,9.6000]) rotate([0,0,-20.00]) linear_extrude(height=0.6000) text("-20", size=2.200, font="Liberation Sans:style=Bold", halign="center", valign="center");
translate([0,0,9.4000]) linear_extrude(height=0.8000) polygon([[5.5266,17.6563],[6.7627,21.4606],[7.1431,21.3370],[5.9070,17.5327]]);
translate([0,0,9.4000]) linear_extrude(height=0.8000) polygon([[4.9070,17.8385],[6.0096,21.6835],[6.3941,21.5733],[5.2915,17.7282]]);
translate([0,0,9.4000]) linear_extrude(height=0.8000) polygon([[4.2815,17.9989],[5.2492,21.8800],[5.6373,21.7833],[4.6696,17.9021]]);
translate([0,0,9.4000]) linear_extrude(height=0.8000) polygon([[3.6507,18.1373],[4.4824,22.0499],[4.8736,21.9667],[4.0420,18.0541]]);
translate([0,0,9.4000]) linear_extrude(height=0.8000) polygon([[3.0155,18.2537],[4.0574,24.1625],[4.4513,24.0931],[3.4095,18.1842]]);
translate([0,0,9.4000]) linear_extrude(height=0.8000) polygon([[2.3766,18.3478],[2.9333,22.3089],[3.3294,22.2532],[2.7728,18.2921]]);
translate([0,0,9.4000]) linear_extrude(height=0.8000) polygon([[1.7349,18.4196],[2.1530,22.3976],[2.5508,22.3558],[2.1327,18.3777]]);
translate([0,0,9.4000]) linear_extrude(height=0.8000) polygon([[1.0910,18.4689],[1.3700,22.4591],[1.7690,22.4312],[1.4900,18.4410]]);
translate([0,0,9.4000]) linear_extrude(height=0.8000) polygon([[0.4458,18.4957],[0.5854,22.4933],[0.9851,22.4793],[0.8455,18.4818]]);
translate([0,0,9.4000]) linear_extrude(height=0.8000) polygon([[-0.2000,18.5000],[-0.2000,24.5000],[0.2000,24.5000],[0.2000,18.5000]]);
translate([0.0000,27.8000,9.6000]) rotate([0,0,0.00]) linear_extrude(height=0.6000) text("0", size=2.200, font="Liberation Sans:style=Bold", halign="center", valign="center");
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

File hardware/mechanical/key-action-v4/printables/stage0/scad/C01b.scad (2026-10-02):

// Toccata stage-0 C01b - 시험 레버 (강철 9×19×40 자리, 허브 Ø3.9, 지침) (generated by make_stage0.py; print orientation, z = build direction)
$fn = 64;
difference(){
union(){
translate([0,0,0.0000]) linear_extrude(height=9.0000) polygon([[148.0000,31.0000],[192.0000,31.0000],[192.0000,54.0000],[187.0000,54.0000],[187.0000,52.0000],[153.0000,52.0000],[153.0000,54.0000],[148.0000,54.0000]]);
translate([0,0,0.0000]) linear_extrude(height=9.0000) polygon([[191.5000,29.5000],[203.2500,29.5000],[203.2500,37.5000],[191.5000,37.5000]]);
translate([0,0,0.0000]) linear_extrude(height=9.0000) polygon([[208.7500,33.5000],[208.7235,34.0391],[208.6443,34.5730],[208.5132,35.0966],[208.3313,35.6048],[208.1006,36.0927],[207.8231,36.5556],[207.5016,36.9892],[207.1391,37.3891],[206.7392,37.7516],[206.3056,38.0731],[205.8427,38.3506],[205.3548,38.5813],[204.8466,38.7632],[204.3230,38.8943],[203.7891,38.9735],[203.2500,39.0000],[202.7109,38.9735],[202.1770,38.8943],[201.6534,38.7632],[201.1452,38.5813],[200.6573,38.3506],[200.1944,38.0731],[199.7608,37.7516],[199.3609,37.3891],[198.9984,36.9892],[198.6769,36.5556],[198.3994,36.0927],[198.1687,35.6048],[197.9868,35.0966],[197.8557,34.5730],[197.7765,34.0391],[197.7500,33.5000],[197.7765,32.9609],[197.8557,32.4270],[197.9868,31.9034],[198.1687,31.3952],[198.3994,30.9073],[198.6769,30.4444],[198.9984,30.0108],[199.3609,29.6109],[199.7608,29.2484],[200.1944,28.9269],[200.6573,28.6494],[201.1452,28.4187],[201.6534,28.2368],[202.1770,28.1057],[202.7109,28.0265],[203.2500,28.0000],[203.7891,28.0265],[204.3230,28.1057],[204.8466,28.2368],[205.3548,28.4187],[205.8427,28.6494],[206.3056,28.9269],[206.7392,29.2484],[207.1391,29.6109],[207.5016,30.0108],[207.8231,30.4444],[208.1006,30.9073],[208.3313,31.3952],[208.5132,31.9034],[208.6443,32.4270],[208.7235,32.9609]]);
translate([0,0,0.0000]) linear_extrude(height=9.0000) polygon([[209.0368,31.1351],[230.1062,25.5385],[230.5170,27.0849],[209.4476,32.6815]]);
}
translate([0,0,-1.0000]) linear_extrude(height=11.0000) polygon([[149.9500,32.9500],[190.0500,32.9500],[190.0500,52.0500],[149.9500,52.0500]]);
translate([203.2500,33.5000,-1.0000]) cylinder(h=11.0000, d=3.9000, $fn=64);
}

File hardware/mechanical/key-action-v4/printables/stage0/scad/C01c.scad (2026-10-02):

// Toccata stage-0 C01c - 패드 받침판 (2개: 후보 재료마다 1개) (generated by make_stage0.py; print orientation, z = build direction)
$fn = 64;
difference(){
union(){
translate([0.0000,0.0000,0.0000]) cube([20.0000,11.0000,4.0000]);
translate([26.0000,0.0000,0.0000]) cube([20.0000,11.0000,4.0000]);
}
translate([4.0000,2.5000,3.7000]) cube([12.0000,6.0000,1.3000]);
translate([30.0000,2.5000,3.7000]) cube([12.0000,6.0000,1.3000]);
}

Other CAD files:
hardware/mechanical/before/cad/5eefb61b2626a.dwg
hardware/mechanical/before/cad/piano_88keys_solid.step
hardware/mechanical/before/cad/stl/coupons.stl
hardware/mechanical/before/cad/stl/v1.5-multipart/white_B.stl
hardware/mechanical/key-action-v4/printables/stage0/scad/C01d.scad
hardware/mechanical/before/cad/piano_88keys_multisolid_ascii.stl
hardware/mechanical/before/cad/stl/key_black.stl
hardware/mechanical/before/cad/stl/key_white.stl
hardware/mechanical/before/cad/stl/rail.stl
hardware/mechanical/before/cad/stl/v1.5-multipart/bed12.stl
hardware/mechanical/before/cad/stl/v1.5-multipart/bed13.stl
hardware/mechanical/before/cad/stl/v1.5-multipart/bed3.stl
hardware/mechanical/before/cad/stl/v1.5-multipart/black.stl
hardware/mechanical/before/cad/stl/v1.5-multipart/coupons.stl
hardware/mechanical/before/cad/stl/v1.5-multipart/fallboard.stl
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

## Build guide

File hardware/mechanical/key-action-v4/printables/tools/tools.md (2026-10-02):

# Toccata W1+ r4.4 — 출력 공구 3종 (벤치 지그 · 캡스턴 벤치 게이지 · 밸런스 핀 높이 게이지)

`tools/make_tools.py`가 단일 모델(`final/model_v4.py` + `geometry.json`)에서 만든다. 모든 치수는 `tools_geometry.json`의 `dims`(T01~T29)와 같다. 좌표: X = x − 그 건반의 밸런스 핀 x, y·z는 모델(z는 책상에서).

## 먼저 알아둘 것 (중요한 순서)

1. **벤치에서 건반 꼬리를 무엇이 누르느냐가 건반 높이를 바꾼다.** 건반은 앞이 무거워(무게중심 y89.8, 봉 y141.0) 지그에 올리면 꼬리가 뜬다. 쉼 펠트는 무른 접촉(모델 K 30 N/mm^1.5)이라 손가락으로 누르면 0.3 N에서 앞이 -0.21 mm, 5 N에서 0.33 mm 달라진다(실제 쉼 반력 1.05 N 기준) — 펀칭 1장(0.25 mm)만큼 틀린다. 그래서 **캡스턴 게이지를 ‘가짜 레버’로 만들었다**: 지그의 L 봉 토막에 걸려 실제 레버와 같은 모멘트(22.82 N·mm, 실제 22.35)로 캡스턴을 누른다 → 쉼 펠트가 실제 하중을 받는다. 남는 차이는 앞 높이 0.004 / 0.001 mm(백 / 흑).
2. **기준은 책상이 아니라 프레임 자리다.** 지그 밑면 = 프레임 밑면(z3.0). 봉 토막 구멍 중심 = K(141.0, 21.5)(프레임 봉 받침 바닥 z19.5에 봉이 얹힌 자리), 쉼 선반 윗면 = z20.054, 레버 봉 = L(203.25, 33.5). 지그를 프레임과 같은 층 높이로 뽑으면 선반·봉 높이가 프레임과 같은 층에서 반올림된다. 핀 게이지는 레일 윗면(z19.0)과 레일 앞면(y132.3)에 댄다.
3. **캡스턴은 확대해서 읽는다.** r4.3 글의 ‘빔 윗면 위 2.5 단’은 빔 윗면이 서포트 쪽(거친 면)이고 1/8회전(0.0625 mm)을 FDM 계단으로 가를 수 없다. 가짜 레버의 바늘은 캡스턴보다 5.52배(백) / 3.59배(흑) 움직여 1/8회전 = 바늘 0.34 / 0.22 mm — 손톱으로 읽기 턱과 같은 높이인지 느낀다.
4. **출력물 4개, 추가 구매 없음.** 봉 토막 3개(31.6 · 20.6 · 교정봉 31.6, 건반 봉과 같은 4 m 봉에서 약 90 mm), 예비 밸런스 핀 1개(100개 묶음의 남는 것), 강철 블록 1개(설치 전 레버용 90개 중 하나를 빌림). 합계 약 68 g · 8시간 2분 (부품표의 ‘출력 공구 15 g’을 바꿔야 함).

## 공구 한눈에

| 공구 | 하는 일 | 기준 | 출력 방향 | 층 · 채움 | 질량 | 시간 | STL |
|---|---|---|---|---|---|---|---|
| T1 벤치 지그 (받침) | 건반 1개를 프레임과 같은 자리(K 봉·쉼 선반·L 봉)에 올림 | 밑면 = 프레임 밑면 z3.0 | 밑면(z3 기준면)을 베드에 — 서포트 없음 (가로 구멍은 눈물방울) | 프레임과 같은 층 높이 (권장 0.2 첫 층 + 0.1) · 채움 40 % · 벽 3 | 38.4 g | 약 215분 | `stl/tool_bench_jig.stl` |
| T1 높이 블록 | 건반 앞 높이 ±0.15 확인 (백 43.5 / 흑 55.5) | 지그 받침판 윗면 z5.0 | 밑면을 베드에, 땅이 위 | 0.1, 높이 37.9~50.8 구간만 0.05 (슬라이서 높이 범위 수정자) · 채움 25 % · 벽 3 | 10.3 g | 약 109분 | `stl/tool_height_block.stl` |
| T2 캡스턴 벤치 게이지 (가짜 레버) | 실제 하중으로 꼬리를 누르고 캡스턴 꼭대기를 정착 쉼 높이 z30.90로 확대해 읽음 | L 봉 토막 + 영점 받침(교정) | −X 옆면(주머니 뒤 벽)을 베드에 — 옆모습이 베드 면에 그려짐, 서포트 없음 | 0.1 · 채움 100 % · 벽 3 | 13.3 g | 약 105분 | `stl/tool_capstan_gauge.stl` |
| T3 밸런스 핀 높이 게이지 | 핀을 꼭대기 z23.30까지 눌러 넣고 GO/NO-GO로 확인 | 레일 윗면 z19.0 + 앞면 y132.3 | 뒤집어(쓸 때 윗면을 베드에) — 발·멈춤 면·GO/NO-GO 천장이 모두 윗면으로 뽑힘, 서포트 없음 | 0.1 (첫 층 0.2) — 높이가 모두 0.1 격자 · 채움 100 % · 벽 4 | 6.3 g | 약 53분 | `stl/tool_pin_gauge.stl` |

공통: PETG, 0.4 노즐, 서포트 없음, 256 × 256 베드에 모두 들어감(가장 큰 지그 72 × 222). 시간은 P2S 기준 대략값.

### FDM 보정 (±0.3을 어디에 넣었나)

| 자리 | 설계 값 | 이유 |
|---|---|---|
| K·L 봉 토막 구멍, 가짜 레버 허브 | Ø3.9 출력 → Ø4.0 드릴 | 프레임 핀 보스·캐리어와 같은 방법: 드릴이 지름을 정하므로 FDM 오차가 남지 않음. 가로 구멍은 눈물방울 지붕 |
| 강철 주머니 | 9.4 × 19.4 × 40.4 (면마다 +0.2) + 스냅 립 0.4 | 출력 주머니는 0.1~0.3 작게 나옴; 립이 강철을 잡음 |
| 핀 게이지 누름 구멍 | Ø2.5 (핀 Ø2.0) | 작은 세로 구멍은 0.2~0.3 작게 나옴 → 실제 약 Ø2.2, 핀을 잡지 않음 |
| 핀 게이지 홈 폭 | 2.9 (핀 2.0) | −0.3이어도 2.6 |
| 지그 예비 핀 구멍 | Ø1.9 출력 (압입) | 프레임 핀 구멍 치수는 모델에 없음 — 프레임과 같은 방법으로 맞추고, 헐거우면 순간접착제 |
| 높이·땅·멈춤 면 (z) | 보정 없음 | 층 높이로 정해짐 — 모든 높이를 층 격자(0.1, 높이 블록 땅만 0.05)에 맞춤 |
| 바늘 끝 ↔ 읽기 턱 | X 틈 1.1 | 허브 축 놀음 ±0.5 + FDM에도 닿지 않음 |

## T1 벤치 지그 (받침 + 높이 블록)

건반 한 개를 모듈 프레임과 같은 자리에 올린다: Ø4 봉 토막(K), 쉼 선반(z20.054), 밸런스 핀(x 위치), 레버 봉 토막(L — 가짜 레버용), 영점 받침(교정), 읽기 턱 기둥, 주차 기둥. 모든 건반(백 7 · 흑 5 · 끝 부속)이 같은 지그를 쓴다 — X 0에 그 건반의 밸런스 핀 홈이 온다.

| 번호 | 공구 | 항목 | 값 | 단위 | 기준 | 비고 |
|---|---|---|---|---|---|---|
| T01 | 벤치 지그 | 지그 기준면 | 3.00 | z | 지그 밑면 = 프레임 밑면 (z3.0, 바닥판 밑) | 출력 높이 = z − 3.0; 프레임과 같은 층 높이로 출력하면 같은 층에서 반올림됨 |
| T02 | 벤치 지그 | 받침판 | X -36.0~36.0 × y -8.0~214.0, z3.0~5.0 | mm | X = x − 그 건반의 밸런스 핀 x | 윗면 z5.0 = 프레임 바닥 윗면 = 높이 블록 자리 |
| T03 | 벤치 지그 | 레일 블록 (핀 자리 · 핀 게이지 자리) | y132.3~138.40, 윗면 z19.0, 앞면 y132.3 | mm | 프레임 밸런스 레일(낮춘 곳) 윗면·앞면과 같음 | X -36.0~36.0 |
| T04 | 벤치 지그 | 예비 밸런스 핀 구멍 | Ø1.9 출력 (압입), y135.3, 깊이 z10.3까지 | mm | X 0 | T3으로 꼭대기 z23.30 — 첫 핀 = 핀 게이지 검증 |
| T05 | 벤치 지그 | K 봉 토막 구멍 (건반 봉) | 중심 (y141.0, z21.5), Ø3.9 출력 → Ø4.0 드릴, 눈물방울 윗부분 | mm | 프레임 봉 받침 바닥 z19.50에 봉이 얹힘 = 봉 중심 K | 기둥 X ±12.3~16.3, y138.40~143.6, 윗면 z26.0; 오른쪽 구멍은 막힘(벽 1.0) → 봉 토막 31.6 |
| T06 | 벤치 지그 | 쉼 선반 | X ±13.0, y195.8~200.0, 윗면 z20.054 | mm | 프레임 뒤 선반 윗면 (S10) | 모든 건반의 쉼 펠트(레버 x ± 4)가 온전히 앉음 — 프레임의 F·F# 부분 착지는 재현하지 않음(아래 주의) |
| T07 | 벤치 지그 | L 봉 토막 구멍 (레버 봉) | 중심 (y203.25, z33.5), Ø3.9 출력 → Ø4.0 드릴 | mm | 프레임 레버 봉 L (S11) | 기둥 X ±6.8~10.8, y200.20~207.50, 윗면 z37.0; 오른쪽 막힘 → 봉 토막 20.6; 가장 넓은 얇은 꼬리 끝(X -10.93~10.93, y199.0)과 대각 1.20 |
| T08 | 벤치 지그 | 영점 받침 (교정) | 백 y188.34 · 흑 y180.31, X ±13.0~17.0, 홈 바닥 z26.9 (폭 4.6, 턱 z27.9) | mm | Ø4 교정봉 윗면 = z30.90 = 정착 쉼 캡스턴 꼭대기 (S08; 건반 좌표 z31.0) | 건반 꼬리·빔과 X로 2.07 떨어짐 |
| T09 | 벤치 지그 | 읽기 턱 기둥 | X 12.9~20.9 (윗면), y118.4~123.6, 윗면 z65.5 | mm | 가짜 레버 b = 0에서 바늘 윗면 | (X, z) 단면이 사다리꼴: 윗면 X 12.9~20.9(z55.5~65.5), 밑은 X 29.9까지 버팀(z5.0) — tools_geometry front; 바늘 끝과 X 틈 1.1 (축 놀음 ±0.5) |
| T10 | 벤치 지그 | 주차 기둥 | X ±4.0, y208.50~213.00, 윗면 z33.5 | mm | 가짜 레버를 뒤로 116° 젖혀 기댐 | 무게중심이 L 뒤 31.3 → 저절로 넘어오지 않음; 캡스턴 위(y176~192)에 아무것도 없음 |
| T11 | 높이 블록 | 땅 W+ (백건 높음 한계) | 43.65 | z | 받침판 윗면 z5.0 위 38.65 (블록 높이) | v0~8, 두께 10 |
| T12 | 높이 블록 | 땅 W- (백건 낮음 한계) | 43.35 | z | 받침판 윗면 z5.0 위 38.35 (블록 높이) | v8~16, 두께 10 |
| T13 | 높이 블록 | 땅 B+ (흑건 높음 한계) | 55.65 | z | 받침판 윗면 z5.0 위 50.65 (블록 높이) | v18~26, 두께 10 |
| T14 | 높이 블록 | 땅 B- (흑건 낮음 한계) | 55.35 | z | 받침판 윗면 z5.0 위 50.35 (블록 높이) | v26~34, 두께 10 |
| T15 | 높이 블록 | 창 (앞 높이) | ±0.15 | mm | 백 43.5 · 흑 55.5 | 펀칭 1장 = 앞 0.25 → 창 0.30 ≥ 한 걸음 |

건반과의 틈 (모델 건반 12개의 쉼 자세 옆모습, X가 겹치는 것만; 설계 접촉 제외):

| 지그·가짜 레버 부분 | 최소 틈 | 건반 | 건반 부분 |
|---|---|---|---|
| bench_jig / K rod stub D4 SUS304 (cut 31.6) | 1.62 | C | tail wall L |
| bench_jig / rest shelf (top = frame shelf) | 1.63 | C | thin tail |
| bench_jig / rail block (frame rail top / front face) | 1.67 | C | balance block |
| capstan_gauge / body (pocket walls, floor = felt plane z_c) | 1.78 | C | skin tail |
| capstan_gauge / beak web to the body top (0.01 into the body) | 1.79 | C# | skin |
| capstan_gauge / beak (handle) over the key tail | 2.07 | C# | skin |
| capstan_gauge / steel SS400 9x19x40 (the lever's own block) | 2.09 | C# | capstan head |
| capstan_gauge / snap lip bottom | 5.79 | C | tail wall R |
| capstan_gauge / hub R4.6 | 5.83 | C# | thin tail |
| bench_jig / balance pin D2x12 (spare, pressed with T3) | 6.62 | C | block web |

설계 접촉: 캡스턴 꼭대기 ↔ 가짜 레버 밑면 -0.01 (닿음), 쉼 펠트 ↔ 선반 -0.068 (펠트 눌림 몫), 노치 ↔ K 봉 토막, 핀 ↔ 핀 홈.

### 높이 블록

받침판 윗면(z5.0)에 세워 건반 옆면에 붙이는 계단 블록. 손톱을 건반 윗면에서 땅으로 밀어 본다:

- **W+ / B+ (높은 땅)**: 손톱이 **걸려야** 한다(땅이 건반보다 높음). 손톱이 떨어지면 건반이 높다 → 펀칭 1장 더.
- **W− / B− (낮은 땅)**: 땅에서 건반으로 밀 때 손톱이 **걸려야** 한다(건반이 땅보다 높음). 안 걸리면 건반이 낮다 → 펀칭 1장 뺌.
- 창 = ±0.15, 펀칭 1장 = 앞 0.25 mm이므로 늘 맞는 장수가 있다. 땅은 앞 y≈4 / 12(백), 앞 모서리 뒤 3~19(흑)에 대면 끝보다 0.93배 — 무시할 만함.

## T2 캡스턴 벤치 게이지 (가짜 레버)

실제 레버 모양 그대로(밑면 = 레버 펠트 면 z30.90, 강철 9×19×40이 레버와 같은 자리 y150.0~190.0) 출력 캐리어에 강철 한 개를 끼운 것. 허브를 지그의 L 봉 토막에 끼운다. 앞의 부리가 손잡이이고, 부리 끝의 바늘이 지그의 읽기 턱 기둥 옆에 온다.

| 번호 | 공구 | 항목 | 값 | 단위 | 기준 | 비고 |
|---|---|---|---|---|---|---|
| T16 | 캡스턴 게이지 | 허브 구멍 | Ø3.9 출력 → Ø4.0 드릴, 중심 L (y203.25, z33.5), 허브 R4.6, 폭 X ±6.3 | mm | L 봉 토막 |  |
| T17 | 캡스턴 게이지 | 밑면 (펠트 면) | 30.90 | z | b = 0에서 평면 z30.90, y148.80~200.05 | 캡스턴 꼭대기와 닿는 면 (단단함 — 펠트 눌림 없음); r4.4 고침 2b: 정착 쉼 꼭대기 백 30.892 · 흑 30.912의 가운데 (건반 좌표 z31.0 아님) |
| T18 | 캡스턴 게이지 | 강철 주머니 | y149.8~190.2, z32.8~52.2, 깊이 9.4 (+X 면이 열림) | mm | 레버 강철 SS400 9×19×40 한 개 (레버와 같은 자리) | 틈 0.2/면 + 스냅 립 0.4 |
| T19 | 캡스턴 게이지 | 앞면 | 148.80 | y | 건반 뒤끝 y147.0와 1.8 |  |
| T20 | 캡스턴 게이지 | 부리 (손잡이) | y119.0~156.0, z57.5~65.5 | mm | 흑건 윗면 z55.5와 2.0 |  |
| T21 | 캡스턴 게이지 | 바늘 | X 6.3~11.8, y119.0~123.0, 윗면 z65.5 (b = 0) | mm | 읽기 턱 기둥 윗면과 손톱으로 같은 높이 |  |
| T22 | 캡스턴 게이지 | 확대비 (바늘 / 캡스턴) | 백 5.52 · 흑 3.59 | 배 | (L − y바늘) / (L − y캡스턴) | 1/8회전(0.0625) = 바늘 0.34 / 0.22 mm |
| T23 | 캡스턴 게이지 | 모멘트 (L 기준) | 22.82 (실제 레버 22.35) | N·mm | 출력 채움 100 % + 강철 1 | 캡스턴 힘 백 1.53 (실제 1.50) · 흑 0.99 (실제 0.98) N |

- 하중: 출력 13.3 g(채움 100 %) + 강철 53.7 g → L 모멘트 22.82 N·mm (실제 레버 22.35: 무게 + 비틀림 스프링). 캡스턴 힘 백 1.53 N (실제 1.50), 흑 0.99 N (실제 0.98). 무게 0.66 N은 백·흑 모두 캡스턴 힘보다 작아(0.87 / 0.34 N 위로) 허브가 늘 봉의 같은 쪽에 닿는다.
- 그 차이가 건반 앞 높이에 주는 영향: 백 0.004, 흑 0.001 mm (모델의 쉼 펠트·노치 천 Hertz 법칙).
- 읽기: 바늘 윗면(z65.5 at b = 0)과 읽기 턱 윗면이 손톱으로 같은 높이 = 캡스턴 꼭대기 z30.90(정착 쉼). 확대비 백 5.52 · 흑 3.59 → 1/8회전 = 바늘 0.34 / 0.22 mm.
- 주차: 부리를 들어 뒤로 116° 젖히면 주차 기둥에 기대 선다(무게중심이 L 뒤 31.3 mm). 이때 캡스턴 위(y176~192)에는 가짜 레버가 전혀 없다 — 육각 렌치가 위에서 들어간다.

## T3 밸런스 핀 높이 게이지

레일 길이 방향(x) 막대 52 mm. 가운데 누름 구멍(멈춤 면 = 핀 꼭대기 z23.30 = 발 위 4.30), 양 끝에 GO(천장 z23.40) → NO-GO(천장 z23.20) 구간. 발은 레일 윗면(z19.0, 받침 능선 y138.44 앞)에, 울타리는 레일 앞면(y132.3)에 댄다. 가운데 홈(폭 2.9, 천장 z24.5)이 이미 눌린 이웃 핀(피치 ≥ 13.05) 위를 지나간다.

| 번호 | 공구 | 항목 | 값 | 단위 | 기준 | 비고 |
|---|---|---|---|---|---|---|
| T24 | 핀 높이 게이지 | 발 (레일 윗면에 얹힘) | z19.0, 앞 발 y132.3~133.85, 뒤 발 y136.75~137.10, 길이 u −26~26 | mm | 프레임 밸런스 레일 윗면 (낮춘 곳, 받침 능선 y138.44 앞) | 앞 발 = 레일 앞면 y132.3부터 (그 앞 y132.0~132.3는 앞 몸통, 울타리가 레일 앞면에 댐) |
| T25 | 핀 높이 게이지 | 울타리 | y130.5~132.0, z15.0까지 | mm | 레일 앞면 y132.3에 대어 y를 맞춤 (틈 0.3) |  |
| T26 | 핀 높이 게이지 | 누름 구멍 | Ø2.5, 멈춤 면 z23.30 (발에서 4.30) | mm | 밸런스 핀 꼭대기 (P32) | u 0 |
| T27 | 핀 높이 게이지 | 열린 홈 | 폭 2.9, 천장 z24.5 | mm | 이웃 핀 꼭대기 z23.30와 1.2 |  |
| T28 | 핀 높이 게이지 | GO 구간 | u ±20~26, 천장 z23.40 (발에서 4.40) | mm | 핀이 밑으로 지나가야 함 |  |
| T29 | 핀 높이 게이지 | NO-GO 구간 | u ±16~20, 천장 z23.20 (발에서 4.20) | mm | 핀이 여기서 멈춰야 함 | 합격 = z23.20~23.40 |

프레임(핀 D 자리)에 놓았을 때 이웃 부품과의 옆모습 거리. 설계 맞닿음(발 ↔ 레일 윗면 0, 대상 핀 ↔ 누름 구멍)은 뺐다. 울타리 ↔ 레일 앞면 0.3은 y 맞춤 틈이다. 뒤 면 ↔ 봉 받침 능선(y138.44, z20.5까지)은 0.44(울타리를 앞면에 대면 0.74).

| 프레임 부품 | 게이지 부분 | 거리 |
|---|---|---|
| balance rail (lowered under the blocks; pocket z18.90 behind y137.4) | front body (y132.00-132.30, in front of the rail face) | -0.01 |
| balance rail cradle | front body (y132.00-132.30, in front of the rail face) | -0.01 |
| balance rail (lowered under the blocks; pocket z18.80 behind y137.2) | front body (y132.00-132.30, in front of the rail face) | -0.01 |
| balance rail (lowered under the blocks; pocket z18.90 behind y137.4) | fence (registers on the rail front face, 0.3 gap) | 0.29 |
| balance rail cradle | fence (registers on the rail front face, 0.3 gap) | 0.29 |
| balance rail (lowered under the blocks; pocket z18.80 behind y137.2) | fence (registers on the rail front face, 0.3 gap) | 0.29 |
| balance rail (lowered under the blocks; pocket z18.90 behind y137.4) | rear body (0.3 above the rail over the rail pockets from y137.2) | 0.30 |
| balance rail cradle | rear body (0.3 above the rail over the rail pockets from y137.2) | 0.30 |

## 사용 순서

### 0. 준비 (한 번)

1. 네 개를 출력한다(위 표). 지그는 프레임과 같은 층 설정으로.
2. Ø4.0 드릴(악기당 공구)로 지그 K·L 기둥 구멍과 가짜 레버 허브를 뚫는다(프레임 핀 보스와 같은 방법).
3. 건반 봉과 같은 Ø4 봉에서 31.6(K) · 20.6(L) · 31.6(교정봉)를 자르고 끝을 줄로 다듬는다.
4. K 봉 토막을 왼쪽 K 기둥으로 밀어 넣어 오른쪽 막힌 벽까지. 왼쪽 끝에 마스킹 테이프 한 바퀴(빠짐 방지).
5. 가짜 레버: 강철 블록 한 개를 +X 면에서 주머니에 눌러 끼운다(스냅 립). L 봉 토막을 왼쪽 L 기둥 → 허브 → 오른쪽 막힌 벽까지 민다. 가짜 레버가 제 무게로 자유롭게 도는지 본다.
6. 예비 밸런스 핀 1개를 지그 핀 구멍(X 0)에 T3으로 눌러 넣는다(아래 T3 순서). 이것이 T3의 첫 검증이다.
7. **교정**: 건반이 없는 지그의 백 영점 받침(CAL W, X ±13.0~17.0) 홈에 교정봉을 가로로 놓고 가짜 레버를 내려놓는다. 바늘 윗면이 읽기 턱과 손톱으로 같은 높이면 끝. 다르면 높은 쪽(바늘 윗면 또는 턱 윗면)을 사포질해 맞춘다(한 번). 흑 영점 받침(CAL B)에서도 같은지 본다 — 차이가 흑 1/8회전(0.22 mm)보다 크면 가짜 레버 밑면을 평평하게 다듬는다.

### 1. 밸런스 핀 누르기 (T3, 프레임마다, 조립 1단계)

1. 왼쪽 핀부터 차례로. 핀 한 개를 구멍에 손으로 세운다(이웃 오른쪽 핀은 아직 꽂지 않는다 — 서 있는 핀이 게이지 홈을 막음).
2. 게이지를 누름 구멍이 핀 위에 오게 얹고 울타리를 레일 앞면에 댄다.
3. 발이 레일 윗면에 닿을 때까지 엄지로, 빡빡하면 작은 바이스로 천천히 누른다(발이 닿으면 끝). **망치로 치지 않는다**: 압입 상한 80 N에서도 Ø2 핀 끝이 누름 구멍의 멈춤 면을 약 25~40 MPa로 누르고, 망치 충격은 PETG 항복을 넘어 멈춤 면이 파인다(그러면 핀이 모두 낮게 들어감).
4. **누른 핀은 바로, 오른쪽 이웃 핀을 꽂기 전에** GO/NO-GO로 본다(r4.4 고침 2): 게이지를 +X로 옮겨 방금 누른 핀이 왼쪽 끝 |<GO로 들어오게 레일을 따라 민다. **GO 구간은 핀 위로 지나가고 NO-GO 턱에서 멈춰야 합격**(꼭대기 z23.20~23.40). 왼쪽의 이미 누른 핀들은 게이지 밖(피치 ≥ 13.05)이고 오른쪽 핀은 아직 없으므로 다른 핀에 걸리지 않는다. 모듈을 잇기 전, 프레임 한 장씩 한다.
   - 핀을 모두 누른 뒤에는 이 확인을 할 수 없다: 게이지 끝을 한 핀에 대면 두 칸 옆 핀이 가운데 누름 블록에, 또는 다른 핀이 반대쪽 NO-GO에 걸려, 낮은 핀도 ‘NO-GO에서 멈춤’으로 보인다.
   - GO에서 막힘 = 핀이 높다 → 누름 구멍으로 다시 누른다. NO-GO를 지나감 = 핀이 낮다 → 펜치로 조금 뽑아 다시 누른다.
   - 여러 핀이 연달아 낮으면 누름 구멍의 멈춤 면이 눌려 파인 것이다 → T3 다시 출력(약 53분).

### 2. 건반마다 높이와 캡스턴 (T1 + T2, 조립 2단계)

1. 가짜 레버를 주차 기둥에 젖혀 둔다. 건반 노치를 K 봉 토막에 스냅으로 끼우고 밸런스 핀 홈이 지그 핀에 오게 한다. 쉼 펠트(1.5T)와 펀칭 2장(설계 값)을 붙여 둔다.
2. 처음 한 번만: 캡스턴(M3×6 버튼헤드 + 너트 트랩)을 머리 밑이 빔에서 약 1.9 뜨게 돌려 둔다.
3. 가짜 레버를 내려 캡스턴에 얹는다 — 건반이 실제 쉼 하중으로 선반에 앉는다. 손으로 건반을 누르지 않는다.
4. **높이**: 높이 블록을 받침판에 세워 건반 머리 옆면(백 y≈0~16 / 흑 y≈58~74)에 붙이고 손톱으로 +/− 땅을 본다. 높으면 펀칭 1장 더, 낮으면 1장 뺀다(한 장 = 앞 0.25). 펀칭을 바꿀 때는 가짜 레버를 젖히고 건반을 뺀다.
5. **캡스턴**: 가짜 레버를 내린 채 바늘과 읽기 턱을 손톱으로 비교한다. 바늘이 낮으면 캡스턴을 1/8회전씩 풀고(올림), 높으면 조인다. 돌릴 때는 가짜 레버를 주차 기둥으로 젖히고 육각 렌치 2.0을 위에서 넣는다. 1/8회전 = 바늘 0.34(백) / 0.22(흑) mm.
6. 높이를 먼저, 캡스턴을 나중에 한다(펀칭은 건반 각도를 바꿔 캡스턴 높이도 바꾼다. 캡스턴은 쉼 하중을 바꾸지 않는다).
7. 가짜 레버를 젖히고 건반을 위로 당겨 뺀다(노치 스냅 1~2 N). 다음 건반.

## 출력 검증 (검사 형상)

| 공구 | 검사 | 합격 | 불합격이면 |
|---|---|---|---|
| 지그 | 캘리퍼: 밑면 → K 봉 토막 윗면 20.50, 밑면 → 쉼 선반 윗면 17.05, 밑면 → 영점 홈 바닥 23.90, 밑면 → 읽기 턱 62.50 | 각 ±0.05 | 프레임도 같은 설정이면 같은 쪽으로 틀린다(건반끼리는 고름). 프레임과 다르게 뽑았다면 선반을 다시 출력 |
| 지그 + 가짜 레버 | 교정봉을 영점 받침에(백·흑) → 바늘과 턱이 손톱으로 같은 높이 | 두 자리 모두 같은 높이 (차이 < 흑 1/8회전 0.22) | 높은 쪽 사포질 (0단계 7) |
| 높이 블록 | 캘리퍼: 밑면 → 땅 W+ 38.65 · W− 38.35 · B+ 50.65 · B− 50.35 | 각 ±0.03 | 층 0.05 구간 설정 확인 후 다시 출력 |
| 핀 게이지 | 캘리퍼 깊이 막대: 발 면 → 누름 구멍 바닥 4.30, GO 천장 4.40, NO-GO 천장 4.20. 지그 핀을 누른 뒤 GO 통과·NO-GO 멈춤 | ±0.05, GO/NO-GO 합격 | 다시 출력 |

## 주의

- **F·F# 부분 착지**: 프레임에서는 USB 선반 홈 때문에 F·F# 쉼 펠트가 일부만 앉아 앞이 약 0.1 mm 높게 쉰다(DESIGN §1d, 이슈 2). 지그 선반은 온전하므로 이 차이는 창(±0.15) 안에 남는다. 이슈 2의 결과로 차이가 0.15를 넘으면 F·F#만 창의 낮은 쪽(− 땅 바로 위)으로 맞춘다.
- 지그는 프레임 한 대의 자리만 재현한다. 7개 모듈 프레임의 출력 차이(선반·받침 높이)는 지그가 없앨 수 없다 — 모든 프레임과 지그를 같은 프린터·같은 층 설정으로 뽑는다.
- 가짜 레버는 펠트가 없어 캡스턴에 단단히 닿는다. 기준 높이는 **정착 쉼** 꼭대기다: 지그 위 건반도 프레임과 같은 K 봉·쉼 선반·레버 모멘트에 얹혀 노치 천·쉼 펠트에 가라앉으므로, 모델(4-DOF 쉼 상태)의 꼭대기 백 z30.892 · 흑 z30.912(건반 좌표 z31.0보다 0.108 / 0.088 낮음)의 가운데 z30.90를 가짜 레버 밑면·영점 받침 면으로 썼다(백 +0.008, 흑 -0.012 mm = 1/8회전의 0.13 / 0.19). r4.4 고침 2까지의 z31.0 기준은 캡스턴을 백 0.108 · 흑 0.088 mm(1/8회전 1.73 / 1.41번) 높게 맞춰 업스톱 틈이 −0.40 → 약 −0.73(백)이 되었다(r4.4 검증).
- 끝 부속 건반(A0·A#0·B0·C8)도 같은 지그를 쓴다: 지그의 틈 검사에 넣었고(K 기둥은 끝 부속까지 가장 넓은 꼬리 ±10.93 밖), 캡스턴 y가 A0 188.43, A#0 180.31, B0 188.32, C8 188.48라 모듈 값(188.34 / 180.31)과 0.14 mm 안 — 영점 받침·확대비가 그대로다.
- 모델이 바뀌면 `MODEL_DIR=<폴더> scratchpad/venv/bin/python tools/make_tools.py`로 다시 만든다(치수·STL·이 문서).

## 파일

- `make_tools.py` — 생성기 (모델: `/private/tmp/claude-501/-Users-kwg-Desktop-mydrive-project-Toccata/2f19e142-4ac2-4c90-bd1e-b3b469f97487/scratchpad/v4/final`)
- `tools_geometry.json` — 치수(T01~T29), 공구별 옆모습(side, (y, z) + X 범위)·평면(plan, (X, y) + z 범위), 가짜 레버 주차 자세, 하중·확대비, 틈 검사
- `stl/tool_bench_jig.stl`, `stl/tool_height_block.stl`, `stl/tool_capstan_gauge.stl`, `stl/tool_pin_gauge.stl` — 베드 방향으로 놓인 출력 파일
- `scad/*.scad` — OpenSCAD 원본, `png/tool_*.png` — 출력 방향 렌더, `png/view_*.png` · `png/assembly_use.png` — 쓰는 자세, `png/check_side.png` — 지그 + 가짜 레버 + 건반 D·C# 옆모습 겹침, T3 + 프레임 레일

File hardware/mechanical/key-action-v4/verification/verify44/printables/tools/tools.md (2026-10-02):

# Toccata W1+ r4.4 — 출력 공구 3종 (벤치 지그 · 캡스턴 벤치 게이지 · 밸런스 핀 높이 게이지)

`tools/make_tools.py`가 단일 모델(`final/model_v4.py` + `geometry.json`)에서 만든다. 모든 치수는 `tools_geometry.json`의 `dims`(T01~T29)와 같다. 좌표: X = x − 그 건반의 밸런스 핀 x, y·z는 모델(z는 책상에서).

## 먼저 알아둘 것 (중요한 순서)

1. **벤치에서 건반 꼬리를 무엇이 누르느냐가 건반 높이를 바꾼다.** 건반은 앞이 무거워(무게중심 y89.8, 봉 y141.0) 지그에 올리면 꼬리가 뜬다. 쉼 펠트는 무른 접촉(모델 K 30 N/mm^1.5)이라 손가락으로 누르면 0.3 N에서 앞이 -0.21 mm, 5 N에서 0.33 mm 달라진다(실제 쉼 반력 1.05 N 기준) — 펀칭 1장(0.25 mm)만큼 틀린다. 그래서 **캡스턴 게이지를 ‘가짜 레버’로 만들었다**: 지그의 L 봉 토막에 걸려 실제 레버와 같은 모멘트(22.79 N·mm, 실제 22.35)로 캡스턴을 누른다 → 쉼 펠트가 실제 하중을 받는다. 남는 차이는 앞 높이 0.004 / 0.001 mm(백 / 흑).
2. **기준은 책상이 아니라 프레임 자리다.** 지그 밑면 = 프레임 밑면(z3.0). 봉 토막 구멍 중심 = K(141.0, 21.5)(프레임 봉 받침 바닥 z19.5에 봉이 얹힌 자리), 쉼 선반 윗면 = z20.054, 레버 봉 = L(203.25, 33.5). 지그를 프레임과 같은 층 높이로 뽑으면 선반·봉 높이가 프레임과 같은 층에서 반올림된다. 핀 게이지는 레일 윗면(z19.0)과 레일 앞면(y132.3)에 댄다.
3. **캡스턴은 확대해서 읽는다.** r4.3 글의 ‘빔 윗면 위 2.5 단’은 빔 윗면이 서포트 쪽(거친 면)이고 1/8회전(0.0625 mm)을 FDM 계단으로 가를 수 없다. 가짜 레버의 바늘은 캡스턴보다 5.52배(백) / 3.59배(흑) 움직여 1/8회전 = 바늘 0.34 / 0.22 mm — 손톱으로 읽기 턱과 같은 높이인지 느낀다.
4. **출력물 4개, 추가 구매 없음.** 봉 토막 3개(31.6 · 20.6 · 교정봉 31.6, 건반 봉과 같은 4 m 봉에서 약 90 mm), 예비 밸런스 핀 1개(100개 묶음의 남는 것), 강철 블록 1개(설치 전 레버용 90개 중 하나를 빌림). 합계 약 68 g · 8시간 0분 (부품표의 ‘출력 공구 15 g’을 바꿔야 함).

## 공구 한눈에

| 공구 | 하는 일 | 기준 | 출력 방향 | 층 · 채움 | 질량 | 시간 | STL |
|---|---|---|---|---|---|---|---|
| T1 벤치 지그 (받침) | 건반 1개를 프레임과 같은 자리(K 봉·쉼 선반·L 봉)에 올림 | 밑면 = 프레임 밑면 z3.0 | 밑면(z3 기준면)을 베드에 — 서포트 없음 (가로 구멍은 눈물방울) | 프레임과 같은 층 높이 (권장 0.2 첫 층 + 0.1) · 채움 40 % · 벽 3 | 38.0 g | 약 213분 | `stl/tool_bench_jig.stl` |
| T1 높이 블록 | 건반 앞 높이 ±0.15 확인 (백 43.5 / 흑 55.5) | 지그 받침판 윗면 z5.0 | 밑면을 베드에, 땅이 위 | 0.1, 높이 37.9~50.8 구간만 0.05 (슬라이서 높이 범위 수정자) · 채움 25 % · 벽 3 | 10.3 g | 약 109분 | `stl/tool_height_block.stl` |
| T2 캡스턴 벤치 게이지 (가짜 레버) | 실제 하중으로 꼬리를 누르고 캡스턴 꼭대기 z31.0를 확대해 읽음 | L 봉 토막 + 영점 받침(교정) | −X 옆면(주머니 뒤 벽)을 베드에 — 옆모습이 베드 면에 그려짐, 서포트 없음 | 0.1 · 채움 100 % · 벽 3 | 13.2 g | 약 105분 | `stl/tool_capstan_gauge.stl` |
| T3 밸런스 핀 높이 게이지 | 핀을 꼭대기 z23.30까지 눌러 넣고 GO/NO-GO로 확인 | 레일 윗면 z19.0 + 앞면 y132.3 | 뒤집어(쓸 때 윗면을 베드에) — 발·멈춤 면·GO/NO-GO 천장이 모두 윗면으로 뽑힘, 서포트 없음 | 0.1 (첫 층 0.2) — 높이가 모두 0.1 격자 · 채움 100 % · 벽 4 | 6.3 g | 약 53분 | `stl/tool_pin_gauge.stl` |

공통: PETG, 0.4 노즐, 서포트 없음, 256 × 256 베드에 모두 들어감(가장 큰 지그 72 × 222). 시간은 P2S 기준 대략값.

### FDM 보정 (±0.3을 어디에 넣었나)

| 자리 | 설계 값 | 이유 |
|---|---|---|
| K·L 봉 토막 구멍, 가짜 레버 허브 | Ø3.9 출력 → Ø4.0 드릴 | 프레임 핀 보스·캐리어와 같은 방법: 드릴이 지름을 정하므로 FDM 오차가 남지 않음. 가로 구멍은 눈물방울 지붕 |
| 강철 주머니 | 9.4 × 19.4 × 40.4 (면마다 +0.2) + 스냅 립 0.4 | 출력 주머니는 0.1~0.3 작게 나옴; 립이 강철을 잡음 |
| 핀 게이지 누름 구멍 | Ø2.5 (핀 Ø2.0) | 작은 세로 구멍은 0.2~0.3 작게 나옴 → 실제 약 Ø2.2, 핀을 잡지 않음 |
| 핀 게이지 홈 폭 | 2.9 (핀 2.0) | −0.3이어도 2.6 |
| 지그 예비 핀 구멍 | Ø1.9 출력 (압입) | 프레임 핀 구멍 치수는 모델에 없음 — 프레임과 같은 방법으로 맞추고, 헐거우면 순간접착제 |
| 높이·땅·멈춤 면 (z) | 보정 없음 | 층 높이로 정해짐 — 모든 높이를 층 격자(0.1, 높이 블록 땅만 0.05)에 맞춤 |
| 바늘 끝 ↔ 읽기 턱 | X 틈 1.1 | 허브 축 놀음 ±0.5 + FDM에도 닿지 않음 |

## T1 벤치 지그 (받침 + 높이 블록)

건반 한 개를 모듈 프레임과 같은 자리에 올린다: Ø4 봉 토막(K), 쉼 선반(z20.054), 밸런스 핀(x 위치), 레버 봉 토막(L — 가짜 레버용), 영점 받침(교정), 읽기 턱 기둥, 주차 기둥. 모든 건반(백 7 · 흑 5 · 끝 부속)이 같은 지그를 쓴다 — X 0에 그 건반의 밸런스 핀 홈이 온다.

| 번호 | 공구 | 항목 | 값 | 단위 | 기준 | 비고 |
|---|---|---|---|---|---|---|
| T01 | 벤치 지그 | 지그 기준면 | 3.00 | z | 지그 밑면 = 프레임 밑면 (z3.0, 바닥판 밑) | 출력 높이 = z − 3.0; 프레임과 같은 층 높이로 출력하면 같은 층에서 반올림됨 |
| T02 | 벤치 지그 | 받침판 | X -36.0~36.0 × y -8.0~214.0, z3.0~5.0 | mm | X = x − 그 건반의 밸런스 핀 x | 윗면 z5.0 = 프레임 바닥 윗면 = 높이 블록 자리 |
| T03 | 벤치 지그 | 레일 블록 (핀 자리 · 핀 게이지 자리) | y132.3~138.40, 윗면 z19.0, 앞면 y132.3 | mm | 프레임 밸런스 레일(낮춘 곳) 윗면·앞면과 같음 | X -36.0~36.0 |
| T04 | 벤치 지그 | 예비 밸런스 핀 구멍 | Ø1.9 출력 (압입), y135.3, 깊이 z10.3까지 | mm | X 0 | T3으로 꼭대기 z23.30 — 첫 핀 = 핀 게이지 검증 |
| T05 | 벤치 지그 | K 봉 토막 구멍 (건반 봉) | 중심 (y141.0, z21.5), Ø3.9 출력 → Ø4.0 드릴, 눈물방울 윗부분 | mm | 프레임 봉 받침 바닥 z19.50에 봉이 얹힘 = 봉 중심 K | 기둥 X ±12.3~16.3, y138.40~143.6, 윗면 z26.0; 오른쪽 구멍은 막힘(벽 1.0) → 봉 토막 31.6 |
| T06 | 벤치 지그 | 쉼 선반 | X ±9.0, y195.8~200.0, 윗면 z20.054 | mm | 프레임 뒤 선반 윗면 (S10) | 모든 건반의 쉼 펠트(레버 x ± 4)가 온전히 앉음 — 프레임의 F·F# 부분 착지는 재현하지 않음(아래 주의) |
| T07 | 벤치 지그 | L 봉 토막 구멍 (레버 봉) | 중심 (y203.25, z33.5), Ø3.9 출력 → Ø4.0 드릴 | mm | 프레임 레버 봉 L (S11) | 기둥 X ±6.8~10.8, y200.20~207.50, 윗면 z37.0; 오른쪽 막힘 → 봉 토막 20.6; 가장 넓은 얇은 꼬리 끝(X -6.20~5.37, y199.0)과 대각 1.34 |
| T08 | 벤치 지그 | 영점 받침 (교정) | 백 y188.34 · 흑 y180.31, X ±8.3~12.3, 홈 바닥 z27.0 (폭 4.6, 턱 z28.0) | mm | Ø4 교정봉 윗면 = z31.0 = 캡스턴 꼭대기 (S08) | 건반 꼬리·빔과 X로 2.10 떨어짐 |
| T09 | 벤치 지그 | 읽기 턱 기둥 | X 12.9~20.9 (윗면), y118.4~123.6, 윗면 z65.5 | mm | 가짜 레버 b = 0에서 바늘 윗면 | 밑은 X +17까지 버팀; 바늘 끝과 X 틈 1.1 (축 놀음 ±0.5) |
| T10 | 벤치 지그 | 주차 기둥 | X ±4.0, y208.50~213.00, 윗면 z33.5 | mm | 가짜 레버를 뒤로 116° 젖혀 기댐 | 무게중심이 L 뒤 31.4 → 저절로 넘어오지 않음; 캡스턴 위(y176~192)에 아무것도 없음 |
| T11 | 높이 블록 | 땅 W+ (백건 높음 한계) | 43.65 | z | 받침판 윗면 z5.0 위 38.65 (블록 높이) | v0~8, 두께 10 |
| T12 | 높이 블록 | 땅 W- (백건 낮음 한계) | 43.35 | z | 받침판 윗면 z5.0 위 38.35 (블록 높이) | v8~16, 두께 10 |
| T13 | 높이 블록 | 땅 B+ (흑건 높음 한계) | 55.65 | z | 받침판 윗면 z5.0 위 50.65 (블록 높이) | v18~26, 두께 10 |
| T14 | 높이 블록 | 땅 B- (흑건 낮음 한계) | 55.35 | z | 받침판 윗면 z5.0 위 50.35 (블록 높이) | v26~34, 두께 10 |
| T15 | 높이 블록 | 창 (앞 높이) | ±0.15 | mm | 백 43.5 · 흑 55.5 | 펀칭 1장 = 앞 0.25 → 창 0.30 ≥ 한 걸음 |

건반과의 틈 (모델 건반 12개의 쉼 자세 옆모습, X가 겹치는 것만; 설계 접촉 제외):

| 지그·가짜 레버 부분 | 최소 틈 | 건반 | 건반 부분 |
|---|---|---|---|
| bench_jig / K rod stub D4 SUS304 (cut 31.6) | 1.70 | C | tail wall L |
| bench_jig / rest shelf (top = frame shelf) | 1.75 | C | thin tail |
| bench_jig / rail block (frame rail top / front face) | 1.75 | C | balance block |
| capstan_gauge / body (pocket walls, floor = felt plane z_c) | 1.80 | C | skin tail |
| capstan_gauge / beak (handle) over the key tail | 1.80 | C# | skin |
| capstan_gauge / steel SS400 9x19x40 (the lever's own block) | 2.00 | C | capstan head |
| capstan_gauge / hub R4.6 | 5.76 | C | thin tail |
| capstan_gauge / snap lip bottom | 5.80 | C | tail wall R |
| bench_jig / balance pin D2x12 (spare, pressed with T3) | 6.70 | C | block web |
| bench_jig / L rod stub D4 SUS304 (cut 20.6) | 8.35 | C | thin tail |

설계 접촉: 캡스턴 꼭대기 ↔ 가짜 레버 밑면 -0.01 (닿음), 쉼 펠트 ↔ 선반 0.046 (펠트 눌림 몫), 노치 ↔ K 봉 토막, 핀 ↔ 핀 홈.

### 높이 블록

받침판 윗면(z5.0)에 세워 건반 옆면에 붙이는 계단 블록. 손톱을 건반 윗면에서 땅으로 밀어 본다:

- **W+ / B+ (높은 땅)**: 손톱이 **걸려야** 한다(땅이 건반보다 높음). 손톱이 떨어지면 건반이 높다 → 펀칭 1장 더.
- **W− / B− (낮은 땅)**: 땅에서 건반으로 밀 때 손톱이 **걸려야** 한다(건반이 땅보다 높음). 안 걸리면 건반이 낮다 → 펀칭 1장 뺌.
- 창 = ±0.15, 펀칭 1장 = 앞 0.25 mm이므로 늘 맞는 장수가 있다. 땅은 앞 y≈4 / 12(백), 앞 모서리 뒤 3~19(흑)에 대면 끝보다 0.93배 — 무시할 만함.

## T2 캡스턴 벤치 게이지 (가짜 레버)

실제 레버 모양 그대로(밑면 = 레버 펠트 면 z31.0, 강철 9×19×40이 레버와 같은 자리 y150.0~190.0) 출력 캐리어에 강철 한 개를 끼운 것. 허브를 지그의 L 봉 토막에 끼운다. 앞의 부리가 손잡이이고, 부리 끝의 바늘이 지그의 읽기 턱 기둥 옆에 온다.

| 번호 | 공구 | 항목 | 값 | 단위 | 기준 | 비고 |
|---|---|---|---|---|---|---|
| T16 | 캡스턴 게이지 | 허브 구멍 | Ø3.9 출력 → Ø4.0 드릴, 중심 L (y203.25, z33.5), 허브 R4.6, 폭 X ±6.3 | mm | L 봉 토막 |  |
| T17 | 캡스턴 게이지 | 밑면 (펠트 면) | 31.00 | z | b = 0에서 평면 z31.0, y148.80~200.05 | 캡스턴 꼭대기와 닿는 면 (단단함 — 펠트 눌림 없음) |
| T18 | 캡스턴 게이지 | 강철 주머니 | y149.8~190.2, z32.8~52.2, 깊이 9.4 (+X 면이 열림) | mm | 레버 강철 SS400 9×19×40 한 개 (레버와 같은 자리) | 틈 0.2/면 + 스냅 립 0.4 |
| T19 | 캡스턴 게이지 | 앞면 | 148.80 | y | 건반 뒤끝 y147.0와 1.8 |  |
| T20 | 캡스턴 게이지 | 부리 (손잡이) | y119.0~156.0, z57.5~65.5 | mm | 흑건 윗면 z55.5와 2.0 |  |
| T21 | 캡스턴 게이지 | 바늘 | X 6.3~11.8, y119.0~123.0, 윗면 z65.5 (b = 0) | mm | 읽기 턱 기둥 윗면과 손톱으로 같은 높이 |  |
| T22 | 캡스턴 게이지 | 확대비 (바늘 / 캡스턴) | 백 5.52 · 흑 3.59 | 배 | (L − y바늘) / (L − y캡스턴) | 1/8회전(0.0625) = 바늘 0.34 / 0.22 mm |
| T23 | 캡스턴 게이지 | 모멘트 (L 기준) | 22.79 (실제 레버 22.35) | N·mm | 출력 채움 100 % + 강철 1 | 캡스턴 힘 백 1.53 (실제 1.50) · 흑 0.99 (실제 0.98) N |

- 하중: 출력 13.2 g(채움 100 %) + 강철 53.7 g → L 모멘트 22.79 N·mm (실제 레버 22.35: 무게 + 비틀림 스프링). 캡스턴 힘 백 1.53 N (실제 1.50), 흑 0.99 N (실제 0.98). 무게 0.66 N은 백·흑 모두 캡스턴 힘보다 작아(0.87 / 0.34 N 위로) 허브가 늘 봉의 같은 쪽에 닿는다.
- 그 차이가 건반 앞 높이에 주는 영향: 백 0.004, 흑 0.001 mm (모델의 쉼 펠트·노치 천 Hertz 법칙).
- 읽기: 바늘 윗면(z65.5 at b = 0)과 읽기 턱 윗면이 손톱으로 같은 높이 = 캡스턴 꼭대기 z31.0. 확대비 백 5.52 · 흑 3.59 → 1/8회전 = 바늘 0.34 / 0.22 mm.
- 주차: 부리를 들어 뒤로 116° 젖히면 주차 기둥에 기대 선다(무게중심이 L 뒤 31.4 mm). 이때 캡스턴 위(y176~192)에는 가짜 레버가 전혀 없다 — 육각 렌치가 위에서 들어간다.

## T3 밸런스 핀 높이 게이지

레일 길이 방향(x) 막대 52 mm. 가운데 누름 구멍(멈춤 면 = 핀 꼭대기 z23.30 = 발 위 4.30), 양 끝에 GO(천장 z23.40) → NO-GO(천장 z23.20) 구간. 발은 레일 윗면(z19.0, 받침 능선 y138.44 앞)에, 울타리는 레일 앞면(y132.3)에 댄다. 가운데 홈(폭 2.9, 천장 z24.5)이 이미 눌린 이웃 핀(피치 ≥ 13.05) 위를 지나간다.

| 번호 | 공구 | 항목 | 값 | 단위 | 기준 | 비고 |
|---|---|---|---|---|---|---|
| T24 | 핀 높이 게이지 | 발 (레일 윗면에 얹힘) | z19.0, 앞 발 y132.3~133.85, 뒤 발 y136.75~137.10, 길이 u −26~26 | mm | 프레임 밸런스 레일 윗면 (낮춘 곳, 받침 능선 y138.44 앞) |  |
| T25 | 핀 높이 게이지 | 울타리 | y130.5~132.0, z15.0까지 | mm | 레일 앞면 y132.3에 대어 y를 맞춤 (틈 0.3) |  |
| T26 | 핀 높이 게이지 | 누름 구멍 | Ø2.5, 멈춤 면 z23.30 (발에서 4.30) | mm | 밸런스 핀 꼭대기 (P32) | u 0 |
| T27 | 핀 높이 게이지 | 열린 홈 | 폭 2.9, 천장 z24.5 | mm | 이웃 핀 꼭대기 z23.30와 1.2 |  |
| T28 | 핀 높이 게이지 | GO 구간 | u ±20~26, 천장 z23.40 (발에서 4.40) | mm | 핀이 밑으로 지나가야 함 |  |
| T29 | 핀 높이 게이지 | NO-GO 구간 | u ±16~20, 천장 z23.20 (발에서 4.20) | mm | 핀이 여기서 멈춰야 함 | 합격 = z23.20~23.40 |

프레임(핀 D 자리)에 놓았을 때 이웃 부품과의 옆모습 거리. 설계 맞닿음(발 ↔ 레일 윗면 0, 대상 핀 ↔ 누름 구멍)은 뺐다. 울타리 ↔ 레일 앞면 0.3은 y 맞춤 틈이다. 뒤 면 ↔ 봉 받침 능선(y138.44, z20.5까지)은 0.44(울타리를 앞면에 대면 0.74).

| 프레임 부품 | 게이지 부분 | 거리 |
|---|---|---|
| balance rail (lowered under the blocks; pocket z18.90 behind y137.4) | fence (registers on the rail front face, 0.3 gap) | 0.29 |
| balance rail cradle | fence (registers on the rail front face, 0.3 gap) | 0.29 |
| balance rail (lowered under the blocks; pocket z18.80 behind y137.2) | fence (registers on the rail front face, 0.3 gap) | 0.29 |
| balance rail (lowered under the blocks; pocket z18.90 behind y137.4) | rear body (0.3 above the rail over the rail pockets from y137.2) | 0.30 |
| balance rail cradle | rear body (0.3 above the rail over the rail pockets from y137.2) | 0.30 |
| balance rail (lowered under the blocks; pocket z18.80 behind y137.2) | rear body (0.3 above the rail over the rail pockets from y137.2) | 0.30 |
| balance pin D2 D | front body + land | 0.45 |
| balance pin D2 D | rear body + land | 0.45 |

## 사용 순서

### 0. 준비 (한 번)

1. 네 개를 출력한다(위 표). 지그는 프레임과 같은 층 설정으로.
2. Ø4.0 드릴(악기당 공구)로 지그 K·L 기둥 구멍과 가짜 레버 허브를 뚫는다(프레임 핀 보스와 같은 방법).
3. 건반 봉과 같은 Ø4 봉에서 31.6(K) · 20.6(L) · 31.6(교정봉)를 자르고 끝을 줄로 다듬는다.
4. K 봉 토막을 왼쪽 K 기둥으로 밀어 넣어 오른쪽 막힌 벽까지. 왼쪽 끝에 마스킹 테이프 한 바퀴(빠짐 방지).
5. 가짜 레버: 강철 블록 한 개를 +X 면에서 주머니에 눌러 끼운다(스냅 립). L 봉 토막을 왼쪽 L 기둥 → 허브 → 오른쪽 막힌 벽까지 민다. 가짜 레버가 제 무게로 자유롭게 도는지 본다.
6. 예비 밸런스 핀 1개를 지그 핀 구멍(X 0)에 T3으로 눌러 넣는다(아래 T3 순서). 이것이 T3의 첫 검증이다.
7. **교정**: 건반이 없는 지그의 백 영점 받침(CAL W, X ±8.3~12.3) 홈에 교정봉을 가로로 놓고 가짜 레버를 내려놓는다. 바늘 윗면이 읽기 턱과 손톱으로 같은 높이면 끝. 다르면 높은 쪽(바늘 윗면 또는 턱 윗면)을 사포질해 맞춘다(한 번). 흑 영점 받침(CAL B)에서도 같은지 본다 — 차이가 흑 1/8회전(0.22 mm)보다 크면 가짜 레버 밑면을 평평하게 다듬는다.

### 1. 밸런스 핀 누르기 (T3, 프레임마다, 조립 1단계)

1. 왼쪽 핀부터 차례로. 핀 한 개를 구멍에 손으로 세운다(이웃 오른쪽 핀은 아직 꽂지 않는다 — 서 있는 핀이 게이지 홈을 막음).
2. 게이지를 누름 구멍이 핀 위에 오게 얹고 울타리를 레일 앞면에 댄다.
3. 발이 레일 윗면에 닿을 때까지 엄지로, 빡빡하면 작은 바이스로 천천히 누른다(발이 닿으면 끝). **망치로 치지 않는다**: 압입 상한 80 N에서도 Ø2 핀 끝이 누름 구멍의 멈춤 면을 약 25~40 MPa로 누르고, 망치 충격은 PETG 항복을 넘어 멈춤 면이 파인다(그러면 핀이 모두 낮게 들어감).
4. **누른 핀은 바로, 오른쪽 이웃 핀을 꽂기 전에** GO/NO-GO로 본다(r4.4 고침 2): 게이지를 +X로 옮겨 방금 누른 핀이 왼쪽 끝 |<GO로 들어오게 레일을 따라 민다. **GO 구간은 핀 위로 지나가고 NO-GO 턱에서 멈춰야 합격**(꼭대기 z23.20~23.40). 왼쪽의 이미 누른 핀들은 게이지 밖(피치 ≥ 13.05)이고 오른쪽 핀은 아직 없으므로 다른 핀에 걸리지 않는다. 모듈을 잇기 전, 프레임 한 장씩 한다.
   - 핀을 모두 누른 뒤에는 이 확인을 할 수 없다: 게이지 끝을 한 핀에 대면 두 칸 옆 핀이 가운데 누름 블록에, 또는 다른 핀이 반대쪽 NO-GO에 걸려, 낮은 핀도 ‘NO-GO에서 멈춤’으로 보인다.
   - GO에서 막힘 = 핀이 높다 → 누름 구멍으로 다시 누른다. NO-GO를 지나감 = 핀이 낮다 → 펜치로 조금 뽑아 다시 누른다.
   - 여러 핀이 연달아 낮으면 누름 구멍의 멈춤 면이 눌려 파인 것이다 → T3 다시 출력(약 53분).

### 2. 건반마다 높이와 캡스턴 (T1 + T2, 조립 2단계)

1. 가짜 레버를 주차 기둥에 젖혀 둔다. 건반 노치를 K 봉 토막에 스냅으로 끼우고 밸런스 핀 홈이 지그 핀에 오게 한다. 쉼 펠트(1.5T)와 펀칭 2장(설계 값)을 붙여 둔다.
2. 처음 한 번만: 캡스턴(M3×6 버튼헤드 + 너트 트랩)을 머리 밑이 빔에서 약 1.9 뜨게 돌려 둔다.
3. 가짜 레버를 내려 캡스턴에 얹는다 — 건반이 실제 쉼 하중으로 선반에 앉는다. 손으로 건반을 누르지 않는다.
4. **높이**: 높이 블록을 받침판에 세워 건반 머리 옆면(백 y≈0~16 / 흑 y≈58~74)에 붙이고 손톱으로 +/− 땅을 본다. 높으면 펀칭 1장 더, 낮으면 1장 뺀다(한 장 = 앞 0.25). 펀칭을 바꿀 때는 가짜 레버를 젖히고 건반을 뺀다.
5. **캡스턴**: 가짜 레버를 내린 채 바늘과 읽기 턱을 손톱으로 비교한다. 바늘이 낮으면 캡스턴을 1/8회전씩 풀고(올림), 높으면 조인다. 돌릴 때는 가짜 레버를 주차 기둥으로 젖히고 육각 렌치 2.0을 위에서 넣는다. 1/8회전 = 바늘 0.34(백) / 0.22(흑) mm.
6. 높이를 먼저, 캡스턴을 나중에 한다(펀칭은 건반 각도를 바꿔 캡스턴 높이도 바꾼다. 캡스턴은 쉼 하중을 바꾸지 않는다).
7. 가짜 레버를 젖히고 건반을 위로 당겨 뺀다(노치 스냅 1~2 N). 다음 건반.

## 출력 검증 (검사 형상)

| 공구 | 검사 | 합격 | 불합격이면 |
|---|---|---|---|
| 지그 | 캘리퍼: 밑면 → K 봉 토막 윗면 20.50, 밑면 → 쉼 선반 윗면 17.05, 밑면 → 영점 홈 바닥 24.00, 밑면 → 읽기 턱 62.50 | 각 ±0.05 | 프레임도 같은 설정이면 같은 쪽으로 틀린다(건반끼리는 고름). 프레임과 다르게 뽑았다면 선반을 다시 출력 |
| 지그 + 가짜 레버 | 교정봉을 영점 받침에(백·흑) → 바늘과 턱이 손톱으로 같은 높이 | 두 자리 모두 같은 높이 (차이 < 흑 1/8회전 0.22) | 높은 쪽 사포질 (0단계 7) |
| 높이 블록 | 캘리퍼: 밑면 → 땅 W+ 38.65 · W− 38.35 · B+ 50.65 · B− 50.35 | 각 ±0.03 | 층 0.05 구간 설정 확인 후 다시 출력 |
| 핀 게이지 | 캘리퍼 깊이 막대: 발 면 → 누름 구멍 바닥 4.30, GO 천장 4.40, NO-GO 천장 4.20. 지그 핀을 누른 뒤 GO 통과·NO-GO 멈춤 | ±0.05, GO/NO-GO 합격 | 다시 출력 |

## 주의

- **F·F# 부분 착지**: 프레임에서는 USB 선반 홈 때문에 F·F# 쉼 펠트가 일부만 앉아 앞이 약 0.1 mm 높게 쉰다(DESIGN §1d, 이슈 2). 지그 선반은 온전하므로 이 차이는 창(±0.15) 안에 남는다. 이슈 2의 결과로 차이가 0.15를 넘으면 F·F#만 창의 낮은 쪽(− 땅 바로 위)으로 맞춘다.
- 지그는 프레임 한 대의 자리만 재현한다. 7개 모듈 프레임의 출력 차이(선반·받침 높이)는 지그가 없앨 수 없다 — 모든 프레임과 지그를 같은 프린터·같은 층 설정으로 뽑는다.
- 가짜 레버는 펠트가 없어 캡스턴에 단단히 닿는다. 모델의 캡스턴 꼭대기 z31.0는 기하 값이므로 이것이 맞는 기준이다(실제 레버의 펠트 눌림은 모델이 따로 계산함).
- 끝 부속 건반(A0·A#0·B0·C8)도 같은 지그를 쓴다: 지그의 틈 검사에 넣었고(K 기둥은 끝 부속까지 가장 넓은 꼬리 ±10.93 밖), 캡스턴 y가 A0 188.44, A#0 180.31, B0 188.33, C8 188.48라 모듈 값(188.34 / 180.31)과 0.14 mm 안 — 영점 받침·확대비가 그대로다.
- 모델이 바뀌면 `MODEL_DIR=<폴더> scratchpad/venv/bin/python tools/make_tools.py`로 다시 만든다(치수·STL·이 문서).

## 파일

- `make_tools.py` — 생성기 (모델: `/private/tmp/claude-501/-Users-kwg-Desktop-mydrive-project-Toccata/2f19e142-4ac2-4c90-bd1e-b3b469f97487/scratchpad/v4/final`)
- `tools_geometry.json` — 치수(T01~T29), 공구별 옆모습(side, (y, z) + X 범위)·평면(plan, (X, y) + z 범위), 가짜 레버 주차 자세, 하중·확대비, 틈 검사
- `stl/tool_bench_jig.stl`, `stl/tool_height_block.stl`, `stl/tool_capstan_gauge.stl`, `stl/tool_pin_gauge.stl` — 베드 방향으로 놓인 출력 파일
- `scad/*.scad` — OpenSCAD 원본, `png/tool_*.png` — 출력 방향 렌더, `png/view_*.png` · `png/assembly_use.png` — 쓰는 자세, `png/check_side.png` — 지그 + 가짜 레버 + 건반 D·C# 옆모습 겹침, T3 + 프레임 레일

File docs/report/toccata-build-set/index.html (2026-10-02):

Toccata · 88-key build set

# Toccata 제작 도면집

건반 액션 4가지(A–D)의 실제 치수 도면, 필요한 부품 전부의 사양·가격·구매처, 방식별 총비용.

기준 문서sound-requirements.md

작성일2026-09-24

단위mm · g · 원

원점y0 = 백건 앞끝

## 개요 · 4가지 건반 방식과 총비용

기준 문서는 hardware/mechanical/sound-requirements.md 하나입니다(R1–R16, D1–D17). 이전 설계 자료는 참고하지 않고, 건반 액션을 4가지 방식으로 새로 설계했습니다. 각 방식은 실제 치수가 적힌 측면도·평면도·부품도를 갖고 있어 그대로 CAD로 옮길 수 있습니다. 전자부·소리·페달·케이스는 네 방식이 같이 씁니다.

A

콤 플렉서

옥타브 일체 콤 + 탄성 힌지 + 스프링

피벗 (앞끝→축)

231 mm

복귀

스프링

센서 위치 이동

5.23 mm

유효 질량(관성)

12 g

필라멘트 / 출력

4.4 kg · 177 h

케이스 깊이

438 mm

예상 총비용2,231,265원

B권장

샤프트 힌지

개별 키 + Ø4 강철 샤프트 + 스프링

피벗 (앞끝→축)

238 mm

복귀

스프링

센서 위치 이동

5.36 mm

유효 질량(관성)

12 g

필라멘트 / 출력

4.7 kg · 187 h

케이스 깊이

434 mm

예상 총비용2,254,465원

C

밸런스 핀 시소

2피스 롱키 + 밸런스 핀 + 강철 카운터웨이트

피벗 (앞끝→축)

212 mm

복귀

중력(추)

센서 위치 이동

4.80 mm

유효 질량(관성)

47 g

필라멘트 / 출력

6.1 kg · 245 h

케이스 깊이

558 mm

예상 총비용2,344,312원

D

해머 액션

키 + 가중 해머 레버(GHS 방식)

피벗 (앞끝→축)

238 mm

복귀

중력(추)

센서 위치 이동

3.88 mm

유효 질량(관성)

128 g

필라멘트 / 출력

7.6 kg · 304 h

케이스 깊이

434 mm

예상 총비용2,312,285원

### 방식별 예상 비용

방식 A

2,231,265원

방식 B

2,254,465원

방식 C

2,344,312원

방식 D

2,312,285원

전자·배선소리페달·조작부3D 출력 재료방식별 기구 부품케이스·공통 하드웨어

분류 | A | B | C | D
전자·배선 | 426,873원 | 426,873원 | 426,873원 | 426,873원
소리 | 1,177,460원 | 1,177,460원 | 1,177,460원 | 1,177,460원
페달·조작부 | 151,472원 | 151,472원 | 151,472원 | 151,472원
3D 출력 재료 | 117,000원 | 117,000원 | 142,000원 | 183,000원
방식별 기구 부품 | 95,500원 | 118,700원 | 127,747원 | 88,520원
케이스·공통 하드웨어 | 262,960원 | 262,960원 | 318,760원 | 284,960원
합계 | 2,231,265원 | 2,254,465원 | 2,344,312원 | 2,312,285원

공구(인두·스트리퍼·멀티미터)와 3D 프린터는 이미 있다고 보고 합계에서 뺐습니다. 필요하면 부품표·비용의 선택 항목을 더하세요.

### 고르는 기준

#### 빨리, 싸게, 확실하게 동작시키려면 → B

건반을 하나씩 교체할 수 있고, 강철 축이라 수명 걱정이 적습니다. 터치는 가벼운 신스 느낌입니다.

#### “실제 피아노처럼”(R6)이 우선이면 → D

해머 추가 만드는 관성(약 128 g)이 입문형 디지털 피아노 액션과 같은 원리입니다. 부품과 조립 시간이 가장 많습니다.

#### 부품 수를 최소로 → A

옥타브당 출력 1회. 대신 힌지 크리프를 시제품으로 먼저 검증해야 합니다.

#### 어쿠스틱 구조 그대로 → C

밸런스 핀·펀칭·중력 복귀. 건반이 372 mm로 길고 강철이 약 6.8 kg 들어갑니다.

권장 순서. B와 D를 각각 1옥타브(12키)만 먼저 만들어 비교하세요. 전자부·센서 레일·프레임은 두 방식이 같은 치수라서 그대로 재사용됩니다.

### 요구사항 대응

요구 | 내용 | 이 설계에서의 답
R1 · R6 | 피아노 소리, 실제 피아노처럼 | Pi 5 + Pianoteq(물리 모델) 또는 FluidSynth + 무료 샘플. 건반 액션 C·D는 중력 복귀로 피아노와 같은 관성
R2 · R7 | 세기·속도, 얼마나 눌렀는지 | 건반마다 선형 홀센서 1개. 위치를 연속으로 읽어 속도 계산 (DRV5055A3, 3.3 V에서 15 mV/mT)
R3 · D1 | 댐퍼 페달(하프 페달) | 연속형 댐퍼 페달 → 페달 모듈 ADC → CC64 0–127 연속값
R4 | 88키, 시간 제한 없음 | 7개 건반 모듈(O1–O7) × CD74HC4067 16채널. 한 모듈 최대 15키
R8 · R9 · D3 | 신호 변환, 소프트웨어만 교체 | 모든 모듈이 표준 USB-MIDI 장치 (Toccata O1–O7, PED)
R10 · R11 | 소프트웨어 음원 | Raspberry Pi 5 한 대. 엔진은 systemd로 전환 (D10)
R12 · R14 · R16 | 호환·음량·찌그러짐 없음 | Pi DAC+ → KABD-430 DSP 앰프(100 Hz 크로스오버) → DMA105-4 ×2 + RSS210HF-4 서브. 위성 과진폭을 DSP로 막음
R13 · D12 · D15 · D17 | 본체 부착형 스피커 | 뒤쪽 스피커 바에 밀폐 4.7 L 상자 2개, 고무 격리, 연주자 쪽으로 향함
R15 | 헤드폰 꽂으면 스피커 꺼짐 | Neutrik NMJ6HCD2 잭 스위치 → PC817 → 앰프 MP 핀 뮤트 (Pi가 멈춰도 동작)
D16 (조정) | 급전 규칙 | 권장안은 HAT이 앰프가 아니라서 Pi는 공식 27 W USB-C 한 곳으로만 급전. HAT 급전을 지키려면 소리 페이지의 T-A(Amp4 Pro)
D14 | 센서 열 y=110에서 이격 | 위성 스피커 y거리 222 mm, 서브 유닛 중심 159 mm (케이스 배치도)

### 전제

- 3D 프린터는 베드 256 × 256 mm급(Bambu Lab A1·P1S 등)을 기준으로 했습니다. 모든 출력물은 250 mm 이하입니다.
- 가격은 2026-09-24에 판매 페이지에서 확인한 부가세 포함 원화 금액입니다. 해외 결제는 그날 환율로 환산했고, 배송비는 빼고 계산했습니다.
- 필라멘트 사용량은 건반 모델의 부피 계산에 여유 15 %를 더한 값입니다. 출력 시간은 PETG 평균 25 g/h(Bambu급, 0.2 mm 레이어)로 잡았습니다.
- 무게·힘 계산은 PETG 밀도 1.27 g/cm³, 인쇄 탄성률 1.5 GPa(Prusament 자료), 강철 7.85 g/cm³ 기준입니다. 실물 오차는 1옥타브 시제품으로 보정합니다.

## 공통 규격 · 네 방식이 같이 쓰는 치수

좌표는 모든 도면에서 같습니다. x = 건반 폭 방향(옥타브 도면은 C 왼쪽 끝이 0), y = 백건 앞끝이 0인 깊이 방향, z = 키베드 합판 윗면이 0인 높이. 단위는 모두 mm입니다.

23.5 mm백건 간격

164.5 mm옥타브

1222 mm88건반 폭

10.0 mm백건 딥

9.0 mm흑건 딥

+12.0 mm흑건 높이

y = 110홀센서 열

### 011옥타브 건반 배열 평면도

건반 배열 — 위에서 본 모습 (연주자 쪽이 아래)축척 약 1:1 화면 기준 · 단위 mm

흑건 위치는 그룹 분할 방식입니다: C–E 구간(70.5 mm)에 흑건 2개(폭 11.5 + 틈 1.0)를 넣고 남은 폭을 꼬리 3개로 나누고, F–B 구간(94 mm)은 흑건 3개와 꼬리 4개로 나눕니다. 흑건 폭 11.5 mm·길이 95 mm·높이 12 mm, 백건 머리 50 mm는 조사한 실측값 범위입니다.

건반 | 종류 | 슬롯 시작 x | 슬롯 끝 x | 슬롯 폭 | 몸체 폭 | 센서·자석 x | 머리 x 범위 | 가이드 핀 x
C | 백건 | 0.00 | 15.17 | 15.17 | 14.17 | 7.58 | 0.50 – 23.00 | 11.75
C# | 흑건 | 15.17 | 27.67 | 12.50 | 11.50 | 21.42 | — | 21.42
D | 백건 | 27.67 | 42.83 | 15.17 | 14.17 | 35.25 | 24.00 – 46.50 | 35.25
D# | 흑건 | 42.83 | 55.33 | 12.50 | 11.50 | 49.08 | — | 49.08
E | 백건 | 55.33 | 70.50 | 15.17 | 14.17 | 62.92 | 47.50 – 70.00 | 58.75
F | 백건 | 70.50 | 84.62 | 14.12 | 13.12 | 77.56 | 71.00 – 93.50 | 82.25
F# | 흑건 | 84.62 | 97.12 | 12.50 | 11.50 | 90.88 | — | 90.88
G | 백건 | 97.12 | 111.25 | 14.12 | 13.12 | 104.19 | 94.50 – 117.00 | 105.75
G# | 흑건 | 111.25 | 123.75 | 12.50 | 11.50 | 117.50 | — | 117.50
A | 백건 | 123.75 | 137.88 | 14.12 | 13.12 | 130.81 | 118.00 – 140.50 | 129.25
A# | 흑건 | 137.88 | 150.38 | 12.50 | 11.50 | 144.12 | — | 144.12
B | 백건 | 150.38 | 164.50 | 14.12 | 13.12 | 157.44 | 141.50 – 164.00 | 152.75

### 0288건반 전체와 모듈 분할

88건반 (A0–C8) · 모듈 O1–O7전체 폭 1222 mm

모듈 | 건반 | 센서 수 | MUX 채널 | USB 이름 (D3) | 비고
O1 | A0–B1 | 15 | C0–C14 | Toccata O1 | A0·A#0·B0 레일(3) + C1 옥타브
O2 | C2–B2 | 12 | C0–C11 | Toccata O2
O3 | C3–B3 | 12 | C0–C11 | Toccata O3
O4 | C4–B4 | 12 | C0–C11 | Toccata O4 | 가운데 C = C4
O5 | C5–B5 | 12 | C0–C11 | Toccata O5
O6 | C6–B6 | 12 | C0–C11 | Toccata O6
O7 | C7–C8 | 13 | C0–C12 | Toccata O7 | C7 옥타브 + C8 레일(1)
PED | 페달 3개 | 3 | — | Toccata PED | GP26·27·28 직접 ADC

양 끝 건반 A0와 C8은 옆에 흑건이 없습니다. A0는 꼬리를 왼쪽으로 넓혀 19.38 mm, C8은 오른쪽으로 넓혀 머리 폭과 같은 22.5 mm로 출력하고, 센서·자석은 표의 x 값(A 슬롯 중심, C 슬롯 중심) 그대로 둡니다. 옥타브 모듈은 C–B 단위로 만들고, A0–B0(3키)와 C8(1키)은 짧은 전용 레일을 씁니다.

### 03건반 단면

건반 단면 A-A ~ D-D (방식 A·B·C 기준, D는 높이 27.5)벽 1.6 · 윗판 2.0

### 04홀센서와 자석

센서는 TI DRV5055A3(TO-92)를 각인면이 위를 보게 눕혀 레일 홈에 넣습니다. 3.3 V에서 감도 15 mV/mT, 선형 범위 ±88 mT입니다. 자석은 Ø6×3 N35 원판, 건반(또는 해머) 밑 홈에 순간접착제로 붙입니다. 가장 가까울 때 간격을 3.0 mm로 잡아 자기장이 선형 범위 안(약 77 mT)에 들게 했습니다.

센서 레일 단면과 자석 간격레일 y 98–126 · 센서면 z 8.0

자석 거리별 자기장 (Ø6×3 N35, 계산)

방식 | 휴지 간격 | 백건 끝 간격 | 흑건 끝 간격 | 이동량 백/흑 | 자기장 mT | 흑건 자석 추가 깊이
A | 8.50 | 3.27 | 3.08 | 5.23 / 6.12 | 12 → 69 | 0.7
B | 8.50 | 3.14 | 3.07 | 5.36 / 6.23 | 12 → 73 | 0.8
C | 8.00 | 3.20 | 3.02 | 4.80 / 5.78 | 13 → 71 | 0.8
D (해머) | 3.00 | 6.88 | 7.54 | 3.88 | 77 → 19 | 0

흑건은 딥 9 mm로 백건보다 각도가 커서 센서 위치에서 더 많이 내려옵니다. 그래서 흑건 자석 홈만 표의 값만큼 더 깊게 파서 가장 가까운 간격을 3.0 mm로 맞춥니다. 이웃 건반 자석(약 13 mm 옆)이 주는 간섭은 계산상 최대 약 2 mT(신호의 약 3 %)로, 펌웨어 보정(D4)으로 지웁니다.

### 05케이스와 스피커 배치

케이스 평면 배치 (방식 B·D 기준, A는 깊이 +4, C는 깊이 +124)D14: 위성 100 mm · 서브 150 mm 이상

- 위성 스피커 2개는 뒤쪽 스피커 바 양 끝의 밀폐 상자(내부 4.7 L, D12)에 넣고, 유닛은 연주자 쪽으로 약 15° 들어 올립니다 (D17). 그릴은 구멍이 넉넉한 타공판.
- 서브우퍼는 키베드 뒤쪽·스피커 바 아래 가운데에 매달고 아래쪽으로 방사합니다. 상자는 고무 방진 마운트로 키베드와 떼어 놓습니다 (D15).
- 센서 열(y 110)에서 위성 유닛까지 y거리 222 mm, 서브 유닛 중심까지 159 mm로 D14 이격을 넘깁니다. 설치 후 게이트 ④ 재시험은 그대로 필요합니다.

건반 액션 방식 A / 4

## 방식 A · 콤 플렉서

한 옥타브 12개 건반과 뒤쪽 스파인을 한 번에 출력하고, 두께 1.2 mm 탄성 힌지가 휘면서 건반이 움직입니다. 복귀는 건반마다 강철 압축 스프링 하나.

231 mm피벗 (앞끝→축)

222 mm건반 길이

z 36.5백건 윗면 높이

5.23 mm센서 이동량

12 g유효 질량

4.4 kg필라멘트

약 177 h출력 시간

2,231,265원예상 총비용

#### 동작 원리

- 핀·축·베어링이 없습니다. 건반 몸체 끝(y 222)과 스파인(y 240) 사이 18 mm 판이 휘는 부분이 곧 피벗입니다.
- 힌지 판은 출력 첫 레이어(바닥면)에 놓입니다. 결이 건반 길이 방향으로 이어져 휘어도 층이 벌어지지 않습니다.
- 스프링(MISUMI C-UR6-25, 0.29 N/mm)은 y 190에서 11.7 mm 눌린 상태로 건반을 밀어 올리고, 뚜껑 밑 상한 펠트가 멈춰 세웁니다.
- 흑건은 같은 스프링을 쓰고 M3 조절 나사를 약 2.3 mm 내려 누르는 힘을 백건과 맞춥니다.

#### 장점

- 부품 수가 가장 적음: 옥타브당 콤 출력 1회
- 마찰·덜걱거림이 거의 없어 조용함
- 조립이 가장 빠르고 비용이 가장 낮음

#### 단점·위험

- 가벼운 신스형 터치 (유효 질량 약 12 g)
- 건반 하나가 불량이면 콤(12키) 전체를 다시 출력
- 힌지가 늘 약 1.5 N·4.3 MPa를 받음 → PETG 크리프(처짐) 위험
- 첫 레이어 품질이 힌지 수명을 좌우

### A-1조립 측면도 (백건 중심 단면)

측면도 — 오른쪽 방향이 연주자에게서 멀어지는 쪽좌표 y·z · 단위 mm · 세로 좌표는 키베드 윗면 기준

건반 PETG (단면 빗금)출력 프레임해머/콤 핀합판강철펠트자석 S/N끝까지 눌린 위치

번호 | 부품
1 | 건반 (콤 일체, PETG)
2 | 탄성 힌지 t1.2×18 (콤 일체)
3 | 스파인 (콤 일체)
4 | 스파인 받침 블록 + M3×45 볼트 3개
5 | 전면 레일 (출력)
6 | 가이드 핀 Ø3×30
7 | 하한 펠트 3 t
8 | 센서 레일 + DRV5055A3
9 | 자석 Ø6×3 N35
10 | 압축 스프링 + 받침 + M3 조절 나사
11 | 상한 펠트 3 t
12 | 뚜껑·명판 18 t 합판
13 | 키슬립 18 t 합판
14 | 키베드 18 t 합판

항목 | 값 | 설명
θmax 백건 / 흑건 | 2.48° / 2.90° | 딥 10.0 / 9.0 mm가 되도록 하한 펠트 높이 결정
하한 레일 윗면 (백 / 흑) | z 4.80 / 5.45 | 펠트 3 t, 0.5 mm 눌림 포함
센서 위치 이동량 (백 / 흑) | 5.23 / 6.12 mm | y 110
건반 질량 (백 / 흑) | 32.2 / 31.5 g | PETG 1.27 g/cm³, 속 빈 구조
유효 질량 (건반 앞끝 환산 관성) | 12 g | 누를 때 손가락이 느끼는 묵직함
스프링 | 선경 0.5 · 외경 6 · 유효 12.8회 | 자유 길이 약 25.0 mm, 설치 12.0 mm
스프링 상수 / 예압 | 0.290 N/mm / 11.7 mm | 휴지 3.39 N → 끝 3.90 N
스프링 전단 응력 | 494 MPa | 피아노선 허용 약 800 MPa 이하
누르는 힘 (백건 앞끝) | 44 → 56 g | 시작 → 바닥 (마찰 약 2–4 g 별도)
흑건 예압 조정 | 2.3 mm 내림 | 조정 안 하면 흑건이 59 g로 무거워짐
힌지 굽힘 변형률 | 0.14 % | PETG 권장 0.5 % 이하
힌지 굽힘 강성 기여 | 3.0 g | 바닥에서 추가되는 힘
힌지 상시 하중 / 응력 | 1.49 N / 4.3 MPa | 크리프 검토 대상 (PETG 항복 약 47 MPa)

### A-2프레임 평면도 (1옥타브 모듈)

위에서 본 프레임 — 건반은 점선 투시모듈 폭 164 (피치 164.5) · 오른쪽 라벨 = 각 건반 중심 x

### A-3건반 부품도

백건 (C 기준)위: 평면도 · 아래: 측면도 · 점선 = 속 형상

백건 | 머리 폭 | 꼬리 폭 | 꼬리 왼쪽 오프셋 | 꼬리 오른쪽 오프셋
C | 22.50 | 14.17 | 0.00 | 8.33
D | 22.50 | 14.17 | 4.17 | 4.17
E | 22.50 | 14.17 | 8.33 | 0.00
F | 22.50 | 13.12 | 0.00 | 9.38
G | 22.50 | 13.12 | 3.12 | 6.25
A | 22.50 | 13.12 | 6.25 | 3.12
B | 22.50 | 13.12 | 9.38 | 0.00

흑건 (모든 흑건 공통)흑건 윗면 폭 9.5 · 밑 폭 11.5

### A-4탄성 힌지 상세 (옆에서)

탄성 힌지 상세 (옆에서)확대

### A-5출력 계획

콤은 흰 PETG 한 색으로 뽑고, 흑건 윗부분(길이 95 · 높이 12)은 검정 캡으로 따로 뽑아 붙입니다. AMS가 있으면 두 색 한 번에 출력해도 됩니다. 힌지 판(t1.2)은 첫 레이어 0.2 + 이후 0.2 × 5층으로, 인필 없이 100 % 벽으로 채웁니다.

출력물 | 재료 | 개수 | 개당 g | 합계 g
건반 콤 (백·흑 스틱 + 스파인) | PETG 흰색 | 8 | 374.6 | 2747
흑건 캡 (접착) | PETG 검정 | 36 | 7.6 | 274
전면 레일 | PETG/PLA 회색 | 8 | 42.2 | 309
센서 레일 | PETG/PLA 회색 | 8 | 23.0 | 169
스프링 받침 레일 | PETG/PLA 회색 | 8 | 14.3 | 105
스파인 받침 블록 | PETG/PLA 회색 | 8 | 34.4 | 252
합계 (여유 15 % 포함) | 흰 3.16 · 검 0.31 · 기타 0.96 kg | | | 4434

### A-6조립 순서

1. 합판 재단 후 키베드에 레일 위치를 먹선으로 긋기 (y 값은 측면도 세로 좌표선)
2. 전면 레일·센서 레일을 목공 나사(M4×16)로 고정하고, 가이드 핀 자리에 Ø2.9 구멍을 8 mm 깊이로 뚫어 Ø3×30 핀 압입
3. 센서를 레일 홈에 눕혀 넣고 VCC·GND 버스와 신호선 납땜 → 모듈에 연결해 88개 값이 모두 읽히는지 먼저 확인
4. 스프링 받침 레일·스파인 받침 블록 고정, 받침마다 M3 조절 나사를 돌려 넣기
5. 콤 12개 건반 밑에 자석 접착 (모두 S극이 아래로, 흑건 홈은 0.7 mm 더 깊게), 흑건 캡 접착
6. 스프링을 받침에 끼우고 콤을 올린 뒤 스파인을 M3×45 볼트 3개로 체결
7. 뚜껑(명판) 장착 후 모든 건반 높이가 한 줄로 맞는지 확인
8. 펌웨어 보정: 건반마다 휴지값·바닥값을 기록 (D4), 흑건/백건 곡선은 펌웨어에만 둠
9. 흑건 조절 나사를 약 2.3 mm 내려 누르는 힘을 백건과 맞춤

### A-7이 방식에만 필요한 부품

Ø3×30 평행핀 (키 가이드핀) × 100

pin

#### Ø3×30 평행핀 (키 가이드핀)

MISUMI 경제형 맞춤핀 E-MSH3-30 (편단 테이퍼·편단 볼, h8)

키 가이드핀(프론트) — 볼 끝단이라 부싱 진입이 부드러움

세부 스펙

재질 | 마르텐사이트 스테인리스
공차 | h8 (0/−0.014)
치수 | Ø3 × 30 mm
끝단 | 한쪽 테이퍼, 한쪽 구형(볼)
최소주문 | 10개
구간단가(VAT 별도) | 10–19: 620원 / 20–49: 560원 / 50–540: 500원

대안

- 베어링웍스 MS 맞춤핀 SUJ2 3X25mm 100개 (https://bearingworks.co.kr/503/?idx=20427) · 23,200원 — 100개 23,200원으로 절반 가격. 단 3X30은 확인 시점 품절, 3X25는 판매 중

오키타 SPB-S45C-D3는 22 mm까지만 목록, SUS303 SPB-303-D3-30은 1000개 팩 360,902원(VAT 별도)이라 비추천.

가격 메모: 50개 이상 500원(VAT 별도)/550원(VAT 포함) → 100개 ≈ 55,000원. 참고 출하일 2026/10/01

한국미스미550원 (https://kr.misumi-ec.com/vona2/detail/110310993689/?HissuCode=E-MSH3-30)

550원 · 100개 · 가이드 핀 Ø3×3055,000원

설계 사양 압축 스프링 A/B (OD6) × 100

spring

#### 설계 사양 압축 스프링 A/B (OD6)

A: MISUMI C-UR6-25 / B: 최근접 C-UY6-30 또는 주문제작

최종 설계 리턴·프리로드 스프링 (A: 0.28 N/mm, B: 0.125 N/mm)

세부 스펙

A 요구 | 선경 0.5, OD 6, L0≈24, 유효 13권, 0.28 N/mm
A 재고품 C-UR6-25 | 선경 0.5, OD 6/ID 5, L0 25, 총 13권, k 0.29 N/mm, Fmax 4.4 N @15 mm, 밀착 7 mm
B 요구 | 선경 0.4, OD 6, L0≈28, 유효 11.5권, 0.125 N/mm
B 최근접 C-UY6-30 | 선경 0.4, OD 6/ID 5.2, L0 30, 총 16권, k 0.098 N/mm, Fmax 2.21 N @22.5 mm
B 대안 C-UR6-30 | 선경 0.5, L0 30, k≈0.29 N/mm (5.3 N/18 mm)
정수 공차 | ±10 % (SUS304-WPB)

대안

- C-UY6-30 절단 사용 (https://kr.misumi-ec.com/vona2/detail/110310295109/?HissuCode=C-UY6-30) · 383원 — k∝1/유효권수: 총 16권 중 약 3권 잘라 유효권수를 줄이면 ≈0.12 N/mm 근사(추정, 끝단 미연삭)

A는 C-UR6-25가 사실상 일치(0.29 vs 0.28). B(0.125)는 미스미 경제형 OD6 라인업 사이값이 없어 주문제작 또는 C-UY6-30으로 설계 보정 필요. 미스미 C-UY/C-UR 규격표에는 100개입 PACK 형번도 있음.

가격 메모: A안: 323원(VAT 별도, 1–99개) / 100개↑ 274원 → 100개 ≈ 30,100원(VAT 포함). 참고 출하일 2026/09/29

한국미스미355원 (https://kr.misumi-ec.com/vona2/detail/110310295109/?HissuCode=C-UR6-25)한국미스미383원 (https://kr.misumi-ec.com/vona2/detail/110310295109/?HissuCode=C-UY6-30)오케이스프링 (11번가)400원 (https://www.11st.co.kr/products/6820905679)

355원 · 100개 · C-UR6-2535,500원

M3 무두볼트(세트스크류) M3×8 / M3×10 × 100

fastener

#### M3 무두볼트(세트스크류) M3×8 / M3×10

볼트집 스텐 무두렌치볼트 M3

스프링 프리로드 조절 나사

세부 스펙

M3×8 | 40원/개
M3×10 | 50원/개
M3×12 | 50원/개
M3×6 | 40원/개
재질 | 스테인리스
구동 | 육각 렌치(무두)

대안

- 볼트집 CM 무두렌지볼트 (1000개) (https://boltzip.com/product/detail.html?product_no=63) · 13,520원 — 대량: M3×8 13,520원 / M3×10 18,590원 per 1000

끝 형상(평단/컵) 표기는 확인 못 함 — 스프링 시트용이면 평단이 유리.

가격 메모: M3×10 50원(100개 5,000원), M3×8 40원(100개 4,000원). 배송 3,000원

볼트집50원 (https://boltzip.com/product/detail.html?product_no=162)

50원 · 100개 · 스프링 예압 조절5,000원

시제품 검증. 힌지 시편 10만 회 반복(서보 지그) + 3.4 N 하중 72시간 처짐 측정. 0.2 mm 이상 처지면 힌지 두께 1.4 mm로 올리거나 방식 B로 전환.

건반 액션 방식 B / 4

## 방식 B · 샤프트 힌지

건반을 한 개씩 출력하고, 뒤끝 아이렛 구멍에 옥타브당 Ø4 강철 샤프트 한 개를 꿰어 회전합니다. 복귀는 압축 스프링.

238 mm피벗 (앞끝→축)

248 mm건반 길이

z 36.5백건 윗면 높이

5.36 mm센서 이동량

12 g유효 질량

4.7 kg필라멘트

약 187 h출력 시간

2,254,465원예상 총비용

#### 동작 원리

- 힌지 콤(출력)의 핀이 건반 사이마다 서 있어서, 샤프트를 13~15 mm마다 받칩니다. 샤프트 휨은 사실상 0입니다.
- 아이렛 구멍은 Ø4.3으로 설계하고, 출력 후 Ø4.1 드릴로 정리하면 강철과 PETG가 부드럽게 돕니다.
- 피벗(y 238)이 가장 뒤에 있어 네 방식 중 센서 이동량이 가장 큽니다 (5.36 mm).
- 스프링은 A와 같은 MISUMI C-UR6-25를 y 190에 두고 10.4 mm 눌러 씁니다. 흑건은 조절 나사를 약 2.0 mm 내립니다.

#### 장점

- 건반을 하나씩 교체할 수 있음
- 강철 축이라 마모·크리프 걱정이 적음
- 가장 흔한 DIY 구조라 자료가 많음
- 출력 실패 비용이 작음 (건반 1개 단위)

#### 단점·위험

- 가벼운 신스형 터치 (유효 질량 약 12 g)
- 아이렛 공차 관리 필요 (드릴 정리)
- 콤 핀과 스치는 소음 → PTFE 건식 윤활
- 건반 88개 개별 출력 = 출력 횟수 많음

### B-1조립 측면도 (백건 중심 단면)

측면도 — 오른쪽 방향이 연주자에게서 멀어지는 쪽좌표 y·z · 단위 mm · 세로 좌표는 키베드 윗면 기준

건반 PETG (단면 빗금)출력 프레임해머/콤 핀합판강철펠트자석 S/N끝까지 눌린 위치

번호 | 부품
1 | 건반 (개별 출력, PETG)
2 | Ø4 샤프트 (옥타브당 1개, 163 mm)
3 | 힌지 콤 (출력, 핀 두께 3)
5 | 전면 레일 (출력)
6 | 가이드 핀 Ø3×30
7 | 하한 펠트 3 t
8 | 센서 레일 + DRV5055A3
9 | 자석 Ø6×3 N35
10 | 압축 스프링 + 받침 + M3 조절 나사
11 | 상한 펠트 3 t
12 | 뚜껑·명판 18 t 합판
13 | 키슬립 18 t 합판
14 | 키베드 18 t 합판

항목 | 값 | 설명
θmax 백건 / 흑건 | 2.41° / 2.80° | 딥 10.0 / 9.0 mm가 되도록 하한 펠트 높이 결정
하한 레일 윗면 (백 / 흑) | z 4.77 / 5.43 | 펠트 3 t, 0.5 mm 눌림 포함
센서 위치 이동량 (백 / 흑) | 5.36 / 6.23 mm | y 110
건반 질량 (백 / 흑) | 37.1 / 36.3 g | PETG 1.27 g/cm³, 속 빈 구조
유효 질량 (건반 앞끝 환산 관성) | 12 g | 누를 때 손가락이 느끼는 묵직함
스프링 | 선경 0.5 · 외경 6 · 유효 12.8회 | 자유 길이 약 25.0 mm, 설치 12.0 mm
스프링 상수 / 예압 | 0.290 N/mm / 10.4 mm | 휴지 3.00 N → 끝 3.59 N
스프링 전단 응력 | 455 MPa | 피아노선 허용 약 800 MPa 이하
누르는 힘 (백건 앞끝) | 44 → 56 g | 시작 → 바닥 (마찰 약 2–4 g 별도)
흑건 예압 조정 | 2.0 mm 내림 | 조정 안 하면 흑건이 59 g로 무거워짐
샤프트 휨 (핀 사이) | 0.1 µm | 콤 핀이 13–15 mm마다 받침

### B-2프레임 평면도 (1옥타브 모듈)

위에서 본 프레임 — 건반은 점선 투시모듈 폭 164 (피치 164.5) · 오른쪽 라벨 = 각 건반 중심 x

### B-3건반 부품도

백건 (C 기준)위: 평면도 · 아래: 측면도 · 점선 = 속 형상

백건 | 머리 폭 | 꼬리 폭 | 꼬리 왼쪽 오프셋 | 꼬리 오른쪽 오프셋
C | 22.50 | 14.17 | 0.00 | 8.33
D | 22.50 | 14.17 | 4.17 | 4.17
E | 22.50 | 14.17 | 8.33 | 0.00
F | 22.50 | 13.12 | 0.00 | 9.38
G | 22.50 | 13.12 | 3.12 | 6.25
A | 22.50 | 13.12 | 6.25 | 3.12
B | 22.50 | 13.12 | 9.38 | 0.00

흑건 (모든 흑건 공통)흑건 윗면 폭 9.5 · 밑 폭 11.5

### B-4힌지 콤과 아이렛 (위에서)

힌지 콤과 아이렛 (위에서)확대

### B-5출력 계획

건반은 윗면을 베드에 대고 뒤집어 출력합니다(서포트 없음, 윗면이 매끈). 흑건은 바로 세워 출력합니다. 아이렛 구멍 Ø4.3은 출력 후 Ø4.1 드릴로 한 번 정리합니다.

출력물 | 재료 | 개수 | 개당 g | 합계 g
백건 | PETG 흰색 | 52 | 37.1 | 1929
흑건 | PETG 검정 | 36 | 36.3 | 1307
전면 레일 | PETG/PLA 회색 | 8 | 42.0 | 308
센서 레일 | PETG/PLA 회색 | 8 | 23.0 | 169
스프링 받침 레일 | PETG/PLA 회색 | 8 | 12.0 | 88
건반 힌지 콤 | PETG 회색 | 8 | 36.1 | 265
합계 (여유 15 % 포함) | 흰 2.22 · 검 1.50 · 기타 0.95 kg | | | 4675

### B-6조립 순서

1. 합판 재단 후 키베드에 레일 위치를 먹선으로 긋기 (y 값은 측면도 세로 좌표선)
2. 전면 레일·센서 레일을 목공 나사(M4×16)로 고정하고, 가이드 핀 자리에 Ø2.9 구멍을 8 mm 깊이로 뚫어 Ø3×30 핀 압입
3. 센서를 레일 홈에 눕혀 넣고 VCC·GND 버스와 신호선 납땜 → 모듈에 연결해 88개 값이 모두 읽히는지 먼저 확인
4. 스프링 받침 레일과 힌지 콤 고정
5. 건반 아이렛 구멍을 Ø4.1 드릴로 정리, 자석 접착
6. 건반 12개를 콤 핀 사이에 세우고 Ø4×163 샤프트를 옆에서 밀어 넣기 (끝은 옆 옥타브 콤이 막음)
7. 스프링을 받침과 건반 홈 사이에 끼움
8. 뚜껑(명판) 장착 후 모든 건반 높이가 한 줄로 맞는지 확인
9. 펌웨어 보정: 건반마다 휴지값·바닥값을 기록 (D4), 흑건/백건 곡선은 펌웨어에만 둠
10. 흑건 조절 나사를 약 2.0 mm 내려 누르는 힘을 백건과 맞춤

### B-7이 방식에만 필요한 부품

Ø3×30 평행핀 (키 가이드핀) × 100

pin

#### Ø3×30 평행핀 (키 가이드핀)

MISUMI 경제형 맞춤핀 E-MSH3-30 (편단 테이퍼·편단 볼, h8)

키 가이드핀(프론트) — 볼 끝단이라 부싱 진입이 부드러움

세부 스펙

재질 | 마르텐사이트 스테인리스
공차 | h8 (0/−0.014)
치수 | Ø3 × 30 mm
끝단 | 한쪽 테이퍼, 한쪽 구형(볼)
최소주문 | 10개
구간단가(VAT 별도) | 10–19: 620원 / 20–49: 560원 / 50–540: 500원

대안

- 베어링웍스 MS 맞춤핀 SUJ2 3X25mm 100개 (https://bearingworks.co.kr/503/?idx=20427) · 23,200원 — 100개 23,200원으로 절반 가격. 단 3X30은 확인 시점 품절, 3X25는 판매 중

오키타 SPB-S45C-D3는 22 mm까지만 목록, SUS303 SPB-303-D3-30은 1000개 팩 360,902원(VAT 별도)이라 비추천.

가격 메모: 50개 이상 500원(VAT 별도)/550원(VAT 포함) → 100개 ≈ 55,000원. 참고 출하일 2026/10/01

한국미스미550원 (https://kr.misumi-ec.com/vona2/detail/110310993689/?HissuCode=E-MSH3-30)

550원 · 100개 · 가이드 핀 Ø3×3055,000원

설계 사양 압축 스프링 A/B (OD6) × 100

spring

#### 설계 사양 압축 스프링 A/B (OD6)

A: MISUMI C-UR6-25 / B: 최근접 C-UY6-30 또는 주문제작

최종 설계 리턴·프리로드 스프링 (A: 0.28 N/mm, B: 0.125 N/mm)

세부 스펙

A 요구 | 선경 0.5, OD 6, L0≈24, 유효 13권, 0.28 N/mm
A 재고품 C-UR6-25 | 선경 0.5, OD 6/ID 5, L0 25, 총 13권, k 0.29 N/mm, Fmax 4.4 N @15 mm, 밀착 7 mm
B 요구 | 선경 0.4, OD 6, L0≈28, 유효 11.5권, 0.125 N/mm
B 최근접 C-UY6-30 | 선경 0.4, OD 6/ID 5.2, L0 30, 총 16권, k 0.098 N/mm, Fmax 2.21 N @22.5 mm
B 대안 C-UR6-30 | 선경 0.5, L0 30, k≈0.29 N/mm (5.3 N/18 mm)
정수 공차 | ±10 % (SUS304-WPB)

대안

- C-UY6-30 절단 사용 (https://kr.misumi-ec.com/vona2/detail/110310295109/?HissuCode=C-UY6-30) · 383원 — k∝1/유효권수: 총 16권 중 약 3권 잘라 유효권수를 줄이면 ≈0.12 N/mm 근사(추정, 끝단 미연삭)

A는 C-UR6-25가 사실상 일치(0.29 vs 0.28). B(0.125)는 미스미 경제형 OD6 라인업 사이값이 없어 주문제작 또는 C-UY6-30으로 설계 보정 필요. 미스미 C-UY/C-UR 규격표에는 100개입 PACK 형번도 있음.

가격 메모: A안: 323원(VAT 별도, 1–99개) / 100개↑ 274원 → 100개 ≈ 30,100원(VAT 포함). 참고 출하일 2026/09/29

한국미스미355원 (https://kr.misumi-ec.com/vona2/detail/110310295109/?HissuCode=C-UR6-25)한국미스미383원 (https://kr.misumi-ec.com/vona2/detail/110310295109/?HissuCode=C-UY6-30)오케이스프링 (11번가)400원 (https://www.11st.co.kr/products/6820905679)

355원 · 100개 · C-UR6-2535,500원

M3 무두볼트(세트스크류) M3×8 / M3×10 × 100

fastener

#### M3 무두볼트(세트스크류) M3×8 / M3×10

볼트집 스텐 무두렌치볼트 M3

스프링 프리로드 조절 나사

세부 스펙

M3×8 | 40원/개
M3×10 | 50원/개
M3×12 | 50원/개
M3×6 | 40원/개
재질 | 스테인리스
구동 | 육각 렌치(무두)

대안

- 볼트집 CM 무두렌지볼트 (1000개) (https://boltzip.com/product/detail.html?product_no=63) · 13,520원 — 대량: M3×8 13,520원 / M3×10 18,590원 per 1000

끝 형상(평단/컵) 표기는 확인 못 함 — 스프링 시트용이면 평단이 유리.

가격 메모: M3×10 50원(100개 5,000원), M3×8 40원(100개 4,000원). 배송 3,000원

볼트집50원 (https://boltzip.com/product/detail.html?product_no=162)

50원 · 100개 · 스프링 예압 조절5,000원

Ø4 mm 연마봉/샤프트 (1 m 또는 절단) × 2

shaft

#### Ø4 mm 연마봉/샤프트 (1 m 또는 절단)

배관몰 스텐연마봉 SUS304 Φ4×1M (절단 옵션)

B/D안 키 피벗축, 긴 레일축

세부 스펙

재질 | SUS304 (비열처리)
직경 | Φ4
길이 | 1 m 기준, 그 외 견적
절단 | 1컷 +500원
배송 | 착불
대안 공차(미스미 E-SFJ4) | g7 −0.004/−0.016 mm, 경화 55HRC~
미스미 최대길이 | 400 mm (Ø4)

대안

- MISUMI E-SFJ4-[L] 경화 샤프트 (https://kr.misumi-ec.com/vona2/detail/110310559529/?HissuCode=E-SFJ4-163) · 8,834원 — 키 부싱 마모가 걱정되면 경화(55HRC)·g7 공차품
- 원자재닷컴 SUS304 4ø 4 m (https://www.onezaze.com/goods/goods_view.php?goodsNo=352) · 4,400원 — 1250 mm 연속축이 꼭 필요할 때 (화물·착불 가능성)

연속 1250 mm Ø4 축은 처짐·조립 난이도 큼 → 베드별 분할 권장. 플라스틱 부싱 + SUS 연마봉 조합이면 경화 불필요.

가격 메모: Φ3/Φ4/Φ5 동일 9,600원, 절단 1컷 500원, 착불 · 절단비 4,000원 포함

배관몰9,600원 (https://baegwan.net/goods/view?no=4356)한국미스미8,834원 (https://kr.misumi-ec.com/vona2/detail/110310559529/?HissuCode=E-SFJ4-163)한국미스미12,593원 (https://kr.misumi-ec.com/vona2/detail/110310559529/?HissuCode=E-SFJ4-300)

9,600원 · 2개 · m, 163 mm × 8 절단23,200원

시제품 검증. 1옥타브 조립 후 아이렛 유격(좌우 흔들림) 0.2 mm 이하, 1만 회 반복 뒤 소음·마모 확인.

건반 액션 방식 C / 4

## 방식 C · 밸런스 핀 시소

어쿠스틱 피아노처럼 건반 가운데의 밸런스 핀에서 시소처럼 움직이고, 뒤쪽 강철 추의 무게로 되돌아옵니다. 스프링이 없습니다.

212 mm피벗 (앞끝→축)

372 mm건반 길이

z 36.0백건 윗면 높이

4.80 mm센서 이동량

47 g유효 질량

6.1 kg필라멘트

약 245 h출력 시간

2,344,312원예상 총비용

#### 동작 원리

- 건반은 372 mm라서 앞 부품(0–240)과 뒤 부품(220–372)으로 나눠 출력하고, 20 mm 겹침 이음을 M3 나사 2개로 잇습니다.
- 밸런스 핀 Ø4가 건반 아래쪽의 Ø6 구멍을 지나고, 윗 모티스(폭 4.2)가 좌우를 잡습니다. 건반은 펠트 펀칭(Ø13) 위에서 흔들립니다.
- 추(9×25 평철)가 백레일 펠트 위에 앉는 것이 정지 위치입니다. 누르면 뒤끝이 7.5 mm 올라갑니다.
- 추 길이: 백건 48 mm(약 85 g), 흑건 37 mm(약 65 g). 저음을 몇 g 무겁게 하는 등급화는 추 길이로 조정합니다.

#### 장점

- 실제 피아노와 같은 원리: 중력 복귀, 스프링 피로 없음
- 관성 약 47 g로 A·B의 약 4배
- 누르는 힘 약 50 g, 올라오는 힘 약 38 g (피아노 기준 범위)
- 시판 피아노 부품(밸런스 핀·펀칭) 사용 가능

#### 단점·위험

- 건반 길이 372 mm → 케이스 깊이 약 +124 mm
- 강철 약 6.8 kg 추가, 추 88개 절단·무게 맞춤
- 건반당 부품 2개 + 나사 2개 → 조립 시간 증가
- 스프링 방식보다 센서 이동량이 작음 (4.80 mm)

### C-1조립 측면도 (백건 중심 단면)

측면도 — 오른쪽 방향이 연주자에게서 멀어지는 쪽좌표 y·z · 단위 mm · 세로 좌표는 키베드 윗면 기준

건반 PETG (단면 빗금)출력 프레임해머/콤 핀합판강철펠트자석 S/N끝까지 눌린 위치

번호 | 부품
1 | 건반 앞 부품 (PETG)
2 | 건반 뒤 부품 (PETG)
3 | 겹침 이음 M3 나사 + 인서트
4 | 밸런스 핀 Ø4×40
5 | 밸런스 레일 + 펀칭 펠트 Ø13×3
6 | 강철 추 9×25 평철
7 | 백레일 + 펠트
8 | 전면 레일 (출력)
9 | 가이드 핀 Ø3×30
10 | 하한 펠트 3 t
11 | 센서 레일 + DRV5055A3
12 | 자석 Ø6×3 N35
13 | 뚜껑·명판 (운반용 안전 펠트), y 264 뒤는 높인 덮개 (밑면 z 46.5)
14 | 키슬립 18 t 합판
15 | 키베드 18 t 합판

항목 | 값 | 설명
θmax 백건 / 흑건 | 2.70° / 3.25° | 딥 10.0 / 9.0 mm가 되도록 하한 펠트 높이 결정
하한 레일 윗면 (백 / 흑) | z 4.37 / 5.00 | 펠트 3 t, 0.5 mm 눌림 포함
센서 위치 이동량 (백 / 흑) | 4.80 / 5.78 mm | y 110
건반 질량 (백 / 흑) | 51.7 / 49.8 g | PETG 1.27 g/cm³, 속 빈 구조
유효 질량 (건반 앞끝 환산 관성) | 47 g | 누를 때 손가락이 느끼는 묵직함
추 (백건 / 흑건) | 48 / 37 mm · 85 / 65 g | 9 × 25 평철, 중심 y 343
DW / UW | 50 / 38 g | 균형 44 g ± 마찰 6 g
뒤끝 상승 | 7.5 mm | 뚜껑까지 여유 확인

### C-2프레임 평면도 (1옥타브 모듈)

위에서 본 프레임 — 건반은 점선 투시모듈 폭 164 (피치 164.5) · 오른쪽 라벨 = 각 건반 중심 x

### C-3건반 부품도

백건 (C 기준)위: 평면도 · 아래: 측면도 · 점선 = 속 형상

백건 | 머리 폭 | 꼬리 폭 | 꼬리 왼쪽 오프셋 | 꼬리 오른쪽 오프셋
C | 22.50 | 14.17 | 0.00 | 8.33
D | 22.50 | 14.17 | 4.17 | 4.17
E | 22.50 | 14.17 | 8.33 | 0.00
F | 22.50 | 13.12 | 0.00 | 9.38
G | 22.50 | 13.12 | 3.12 | 6.25
A | 22.50 | 13.12 | 6.25 | 3.12
B | 22.50 | 13.12 | 9.38 | 0.00

흑건 (모든 흑건 공통)흑건 윗면 폭 9.5 · 밑 폭 11.5

### C-4밸런스 핀과 모티스 (단면)

밸런스 핀과 모티스 (단면)확대

### C-5출력 계획

앞 부품은 윗면을 베드에 대고, 뒤 부품은 밑면을 베드에 대고 출력합니다. 겹침 이음에는 M3 인서트를 뒤 부품에 박고 앞 부품 쪽에서 볼트를 넣습니다.

출력물 | 재료 | 개수 | 개당 g | 합계 g
백건 앞 부품 | PETG 흰색 | 52 | 33.4 | 1736
흑건 앞 부품 | PETG 검정 | 36 | 32.1 | 1156
건반 뒤 부품 | PETG 아무 색 | 88 | 18.4 | 1616
전면 레일 | PETG/PLA 회색 | 8 | 38.6 | 283
센서 레일 | PETG/PLA 회색 | 8 | 23.0 | 169
밸런스 레일 | PETG/PLA 회색 | 8 | 33.7 | 247
백레일 | PETG/PLA 회색 | 8 | 15.7 | 115
합계 (여유 15 % 포함) | 흰 2.00 · 검 1.33 · 기타 2.79 kg | | | 6121

### C-6조립 순서

1. 합판 재단 후 키베드에 레일 위치를 먹선으로 긋기 (y 값은 측면도 세로 좌표선)
2. 전면 레일·센서 레일을 목공 나사(M4×16)로 고정하고, 가이드 핀 자리에 Ø2.9 구멍을 8 mm 깊이로 뚫어 Ø3×30 핀 압입
3. 센서를 레일 홈에 눕혀 넣고 VCC·GND 버스와 신호선 납땜 → 모듈에 연결해 88개 값이 모두 읽히는지 먼저 확인
4. 밸런스 레일과 백레일 고정, 밸런스 핀 Ø4×40를 합판에 8 mm 박고 Ø13 펀칭 펠트 끼우기
5. 건반 앞·뒤 부품을 겹쳐 M3 볼트 2개로 잇고, 뒤 부품 밑 홈에 강철 추(백 48 / 흑 37 mm) 접착 + M3 고정
6. 건반을 밸런스 핀에 끼워 올리고 가이드 핀이 앞 모티스에 들어가는지 확인
7. 저울로 건반 앞 13 mm 지점 DW/UW 측정, 추 길이를 다듬어 DW 50 ± 3 g
8. 뚜껑(명판) 장착 후 모든 건반 높이가 한 줄로 맞는지 확인
9. 펌웨어 보정: 건반마다 휴지값·바닥값을 기록 (D4), 흑건/백건 곡선은 펌웨어에만 둠

### C-7이 방식에만 필요한 부품

Ø3×30 평행핀 (키 가이드핀) × 100

pin

#### Ø3×30 평행핀 (키 가이드핀)

MISUMI 경제형 맞춤핀 E-MSH3-30 (편단 테이퍼·편단 볼, h8)

키 가이드핀(프론트) — 볼 끝단이라 부싱 진입이 부드러움

세부 스펙

재질 | 마르텐사이트 스테인리스
공차 | h8 (0/−0.014)
치수 | Ø3 × 30 mm
끝단 | 한쪽 테이퍼, 한쪽 구형(볼)
최소주문 | 10개
구간단가(VAT 별도) | 10–19: 620원 / 20–49: 560원 / 50–540: 500원

대안

- 베어링웍스 MS 맞춤핀 SUJ2 3X25mm 100개 (https://bearingworks.co.kr/503/?idx=20427) · 23,200원 — 100개 23,200원으로 절반 가격. 단 3X30은 확인 시점 품절, 3X25는 판매 중

오키타 SPB-S45C-D3는 22 mm까지만 목록, SUS303 SPB-303-D3-30은 1000개 팩 360,902원(VAT 별도)이라 비추천.

가격 메모: 50개 이상 500원(VAT 별도)/550원(VAT 포함) → 100개 ≈ 55,000원. 참고 출하일 2026/10/01

한국미스미550원 (https://kr.misumi-ec.com/vona2/detail/110310993689/?HissuCode=E-MSH3-30)

550원 · 100개 · 가이드 핀 Ø3×3055,000원

Ø4 평행핀 30/40 mm (발란스핀·프론트핀) × 100

pin

#### Ø4 평행핀 30/40 mm (발란스핀·프론트핀)

오키타(OHKITA) 평행 핀 B종 h7 SPB-S45C-D4-30 / D4-40 (미스미 판매)

C안 발란스 레일 핀·프론트 가이드 핀

세부 스펙

재질 | S45C, 열처리·표면처리 없음
공차 | h7 (0/−0.012)
치수 | Ø4 × 30 또는 40 mm
포장 | 100개 팩
끝단 | 표준 모따기
주의 | 무도금 → 방청유/왁스 권장

대안

- 베어링웍스 MS 맞춤핀 SUJ2 4X30mm 100개 (https://bearingworks.co.kr/503/?idx=20427) · 25,100원 — 경화(HRC55–58) SUJ2 — 마모에 강함, 익일 발송. 19,600+5,500원

4×40은 베어링웍스에 없음(4X30까지). 프론트핀은 윗단을 둥글게 다듬거나 Ø3 볼엔드 핀(m-pin3) 사용.

가격 메모: 19,334원(VAT 별도)/팩, 참고 출하일 2026/10/01

한국미스미15,596원 (https://kr.misumi-ec.com/vona2/detail/221005016322/?HissuCode=SPB-S45C-D4-30)한국미스미21,267원 (https://kr.misumi-ec.com/vona2/detail/221005016322/?HissuCode=SPB-S45C-D4-40)

21,267원 / 100 · 1묶음 · Ø4×40 밸런스 핀21,267원

평철 9×25 mm (C안 카운터웨이트 48 mm×88) × 4.02

counterweight

#### 평철 9×25 mm (C안 카운터웨이트 48 mm×88)

원자재닷컴 [스틸 형강류] 스틸 평철 6M — 폭 25 × 두께 9

C안 키 카운터웨이트 블록 (48 mm 절단 88개, 총 ≈4.3 m)

세부 스펙

규격 | 25 × 9 mm, 6 m
재질 | 스틸 평철(SS275/SS400 계열, 판매 페이지 재질 등급 미표기)
가격 | 8,600 + 15,130 = 23,730원/6 m (≈3,955원/m)
절단비 | 9–10t 컷당 3,000원
88개 절단비 | 87–88컷 × 3,000 ≈ 261,000–264,000원
개당 질량 | 25×9×48 mm = 10.8 cm³ → ≈84.8 g
배송 | 착불(6 m 장척)

대안

- 같은 판매처 6 m 구매 후 자가 절단/동네 철물점 절단 (https://www.onezaze.com/goods/goods_view.php?goodsNo=141) · 23,730원 — 88컷 절단비(≈26만원)가 재료비의 10배 → 금속용 밴드쏘·고속절단기 자가 절단 또는 몇 컷 단위로 사서 직접 분할이 경제적

판매 옵션 두께: 폭 25는 3/4.5/6/9t. 48 mm 조각 88개는 한 조각 84.8 g로 5–20 g 목표보다 훨씬 무거움 — 설계 질량 재확인 필요.

가격 메모: 기본 8,600원 + 25×9 옵션 15,130원. 절단 추가상품 컷당 3,000원(9–10t). 착불 배송

원자재닷컴23,730원 (https://www.onezaze.com/goods/goods_view.php?goodsNo=141)

23,730원 / 6 · 1묶음 · m, 직접 절단23,730원

육각 렌치볼트(캡스크류) M3/M4/M5 + 와셔 × 1

fastener

#### 육각 렌치볼트(캡스크류) M3/M4/M5 + 와셔

볼트집 SCM435 육각렌지볼트 (1000개 단위)

프레임·인서트 체결

세부 스펙

M3×5–12 | 27,750원/1000개
M3×15 | 29,200원/1000개
M3×20 | 33,580원/1000개
M4×6–12 | 27,750원/1000개
M5×6–10 | 29,200원/1000개
스텐 평와셔 M3/M4/M5 | 20원/개
재질 | SCM435 (흑색)

대안

- 11번가 880개 볼트·너트·와셔 세트 M2–M5 (8–20 mm) (https://www.11st.co.kr/products/9620442948) · 20,100원 — 소량 다규격 → 시제품 단계에 적합, 무료배송
- 11번가 520개 스텐 볼트·너트 세트 M2–M5 (https://www.11st.co.kr/products/9631491191) · 16,270원 — 16,270원, 무료배송

볼트집은 소경 렌치볼트를 1000개 단위로만 판매 → 규격 수가 많으면 세트가 경제적.

가격 메모: M3×8 1000개 27,750원 (≈28원/개), 배송 3,000원

볼트집27,750원 (https://boltzip.com/product/detail.html?product_no=64)볼트집20원 (https://boltzip.com/product/detail.html?product_no=87)

27,750원 / 1000 · 1묶음 · M3 볼트 1000개27,750원

시제품 검증. 1옥타브로 DW/UW를 저울(건반 앞 13 mm 지점)로 측정하고, 추 길이를 ±3 mm 다듬어 DW 50±3 g에 맞춥니다.

건반 액션 방식 D / 4

## 방식 D · 해머 액션

건반 밑에 강철 추를 단 해머 레버를 따로 둡니다. 건반이 해머 앞을 누르면 뒤쪽 추가 들려 올라가며 무게와 관성을 만듭니다. 야마하 GHS 계열과 같은 구조입니다.

238 mm피벗 (앞끝→축)

248 mm건반 길이

z 58.0백건 윗면 높이

3.88 mm센서 이동량

128 g유효 질량

7.6 kg필라멘트

약 304 h출력 시간

2,312,285원예상 총비용

#### 동작 원리

- 건반은 B처럼 뒤쪽 샤프트(y 238)로 돌고, 해머는 y 95의 Ø3 샤프트로 돕니다. 해머 앞 누름점은 y 66입니다.
- 건반 각속도 대비 해머 각속도가 약 5.9배라서 34 g 추가 건반 앞에서 약 128 g처럼 느껴집니다.
- 추는 건반 속 빈 공간으로 올라갑니다. 그래서 건반 높이를 27.5 mm로 키웠고, 추가 올라오는 구간(백건 y 137–192, 흑건 y 146–192)에는 리브를 두지 않습니다.
- 센서는 해머 자석을 읽습니다 (실제 디지털 피아노와 같은 방식). 누르면 자석이 센서에서 3.9 mm 멀어집니다.

#### 장점

- 가장 피아노에 가까운 묵직한 관성 (약 128 g)
- 중력 복귀, 스프링 없음
- 해머 과회전 스톱 펠트로 세게 쳐도 안전
- 키 길이 248 mm라 케이스는 A·B와 같은 크기

#### 단점·위험

- 부품 수 최다: 해머 88 + 콤 2종 + 추 88
- 해머 자석 이동량이 가장 작음 (3.88 mm, 그래도 ADC 약 1,000단계)
- 흑건은 추 위 여유가 1.8 mm라 공차가 엄격함
- 건반 윗면 높이 58 mm (키베드 기준)

### D-1조립 측면도 (백건 중심 단면)

측면도 — 오른쪽 방향이 연주자에게서 멀어지는 쪽좌표 y·z · 단위 mm · 세로 좌표는 키베드 윗면 기준

건반 PETG (단면 빗금)출력 프레임해머/콤 핀합판강철펠트자석 S/N끝까지 눌린 위치

번호 | 부품
1 | 건반 (PETG, 높이 27.5)
2 | 액추에이터 (건반 일체)
3 | 건반 샤프트 Ø4 + 콤
4 | 해머 레버 (PETG)
5 | 해머 샤프트 Ø3 + 해머 콤
6 | 강철 추 6 × 19 평철
7 | 누름 패드 펠트
8 | 과회전 스톱 펠트
9 | 추 받침 펠트 (키베드 위)
10 | 센서 레일 + DRV5055A3
11 | 자석 Ø6×3 (해머 속)
12 | 가이드 핀 Ø3×45
13 | 상한 펠트 3 t
14 | 키슬립 18 t 합판

항목 | 값 | 설명
θmax 백건 / 흑건 | 2.41° / 2.79° | 딥 10.0 / 9.0 mm가 되도록 하한 펠트 높이 결정
하한 레일 윗면 (백 / 흑) | z 18.78 / 19.05 | 펠트 3 t, 0.5 mm 눌림 포함
센서 위치 이동량 (백 / 흑) | 3.88 / 6.22 mm | y 110
건반 질량 (백 / 흑) | 46.5 / 43.2 g | PETG 1.27 g/cm³, 속 빈 구조
유효 질량 (건반 앞끝 환산 관성) | 128 g | 누를 때 손가락이 느끼는 묵직함
해머 추 (백건 / 흑건) | 38 / 28 mm · 34 / 25 g | 6 × 19 평철, 중심 y 167 / 172
해머 각도 (백 / 흑) | 14.4° / 16.8° | 각속도비 5.93
추 상승 (백 / 흑) | 17.6 / 21.8 mm | 건반 속으로 올라감
추 위 여유 (백 / 흑) | 5.9 / 1.8 mm | 과회전 스톱이 넘침 제한
DW / UW | 50 / 38 g | 균형 44 g ± 마찰 6 g

### D-2프레임 평면도 (1옥타브 모듈)

위에서 본 프레임 — 건반은 점선 투시모듈 폭 164 (피치 164.5) · 오른쪽 라벨 = 각 건반 중심 x

### D-3건반 부품도

백건 (C 기준)위: 평면도 · 아래: 측면도 · 점선 = 속 형상

백건 | 머리 폭 | 꼬리 폭 | 꼬리 왼쪽 오프셋 | 꼬리 오른쪽 오프셋
C | 22.50 | 14.17 | 0.00 | 8.33
D | 22.50 | 14.17 | 4.17 | 4.17
E | 22.50 | 14.17 | 8.33 | 0.00
F | 22.50 | 13.12 | 0.00 | 9.38
G | 22.50 | 13.12 | 3.12 | 6.25
A | 22.50 | 13.12 | 6.25 | 3.12
B | 22.50 | 13.12 | 9.38 | 0.00

흑건 (모든 흑건 공통)흑건 윗면 폭 9.5 · 밑 폭 11.5

### D-4해머 레버 부품도 (옆에서)

해머 레버 부품도 (옆에서)확대

### D-5출력 계획

건반 높이가 27.5 mm이고, 추가 올라오는 구간(백건 y 137–192, 흑건 y 146–192)에는 리브가 없습니다. 해머는 옆으로 눕혀 출력하고, 추는 해머 뒤쪽 받침(크래들)에 넣어 밑에서 M3×8 접시머리 나사 2개로 고정합니다(추에 M3 탭 6 mm).

출력물 | 재료 | 개수 | 개당 g | 합계 g
백건 | PETG 흰색 | 52 | 46.5 | 2419
흑건 | PETG 검정 | 36 | 43.2 | 1556
전면 레일 | PETG/PLA 회색 | 8 | 156.0 | 1144
센서 레일 | PETG/PLA 회색 | 8 | 23.0 | 169
건반 힌지 콤 | PETG 회색 | 8 | 45.2 | 332
해머 콤 | PETG 회색 | 8 | 31.5 | 231
해머 레버 (빔 + 추 받침) | PETG 회색 | 88 | 8.6 | 760
합계 (여유 15 % 포함) | 흰 2.78 · 검 1.79 · 기타 3.03 kg | | | 7602

### D-6조립 순서

1. 합판 재단 후 키베드에 레일 위치를 먹선으로 긋기 (y 값은 측면도 세로 좌표선)
2. 전면 레일·센서 레일을 목공 나사(M4×16)로 고정하고, 가이드 핀 자리에 Ø2.9 구멍을 8 mm 깊이로 뚫어 Ø3×45 핀 압입
3. 센서를 레일 홈에 눕혀 넣고 VCC·GND 버스와 신호선 납땜 → 모듈에 연결해 88개 값이 모두 읽히는지 먼저 확인
4. 해머 콤·추 받침 펠트·과회전 스톱 펠트 고정
5. 해머에 자석 접착(S극 아래). 강철 추(6 × 19 평철, 백 38 / 흑 28 mm)에 M3 탭 2곳(6 mm)을 내고, 해머 뒤쪽 받침(크래들)에 넣어 밑에서 M3×8 접시머리 2개로 고정 (머리는 받침 바닥의 Ø6.3 접시 자리에 묻힘)
6. 해머 12개를 콤에 세우고 Ø3×163 샤프트 삽입 → 손으로 흔들어 걸림 없는지 확인
7. 건반 콤 고정, 건반을 올리고 Ø4 샤프트 삽입
8. 흑건을 끝까지 눌러 추가 건반 천장에 닿지 않는지(여유 약 1.8 mm) 틈새 게이지로 확인
9. 뚜껑(명판) 장착 후 모든 건반 높이가 한 줄로 맞는지 확인
10. 펌웨어 보정: 건반마다 휴지값·바닥값을 기록 (D4), 흑건/백건 곡선은 펌웨어에만 둠

### D-7이 방식에만 필요한 부품

Ø3×45 평행핀 (키 가이드핀) × 100

pin

#### Ø3×45 평행핀 (키 가이드핀)

MISUMI 경제형 맞춤핀 E-MSH3-45 (편단 테이퍼·편단 볼, h8) — 같은 계열 45 mm 품번, 가격 확인 필요

키 가이드핀(프론트) — 볼 끝단이라 부싱 진입이 부드러움

세부 스펙

재질 | 마르텐사이트 스테인리스
공차 | h8 (0/−0.014)
치수 | Ø3 × 45 mm
끝단 | 한쪽 테이퍼, 한쪽 구형(볼)
최소주문 | 10개
가격 | 45 mm 품번 가격 확인 필요 (30 mm 품번만 확인함)

건반이 높아 가이드 핀이 45 mm 필요합니다(30 mm 품번은 다른 방식용). 45 mm 품번의 가격을 확인하지 못해 합계에 넣지 않았습니다.

한국미스미 (https://kr.misumi-ec.com/vona2/detail/110310993689/)

가격 확인 필요 · 가이드 핀 Ø3×45—

Ø4 mm 연마봉/샤프트 (1 m 또는 절단) × 2

shaft

#### Ø4 mm 연마봉/샤프트 (1 m 또는 절단)

배관몰 스텐연마봉 SUS304 Φ4×1M (절단 옵션)

B/D안 키 피벗축, 긴 레일축

세부 스펙

재질 | SUS304 (비열처리)
직경 | Φ4
길이 | 1 m 기준, 그 외 견적
절단 | 1컷 +500원
배송 | 착불
대안 공차(미스미 E-SFJ4) | g7 −0.004/−0.016 mm, 경화 55HRC~
미스미 최대길이 | 400 mm (Ø4)

대안

- MISUMI E-SFJ4-[L] 경화 샤프트 (https://kr.misumi-ec.com/vona2/detail/110310559529/?HissuCode=E-SFJ4-163) · 8,834원 — 키 부싱 마모가 걱정되면 경화(55HRC)·g7 공차품
- 원자재닷컴 SUS304 4ø 4 m (https://www.onezaze.com/goods/goods_view.php?goodsNo=352) · 4,400원 — 1250 mm 연속축이 꼭 필요할 때 (화물·착불 가능성)

연속 1250 mm Ø4 축은 처짐·조립 난이도 큼 → 베드별 분할 권장. 플라스틱 부싱 + SUS 연마봉 조합이면 경화 불필요.

가격 메모: Φ3/Φ4/Φ5 동일 9,600원, 절단 1컷 500원, 착불 · 절단비 4,000원 포함

배관몰9,600원 (https://baegwan.net/goods/view?no=4356)한국미스미8,834원 (https://kr.misumi-ec.com/vona2/detail/110310559529/?HissuCode=E-SFJ4-163)한국미스미12,593원 (https://kr.misumi-ec.com/vona2/detail/110310559529/?HissuCode=E-SFJ4-300)

9,600원 · 2개 · m, 163 mm × 8 절단23,200원

Ø3 mm 경화 샤프트 (길이 지정, 옥타브 분할) × 2

shaft

#### Ø3 mm 경화 샤프트 (길이 지정, 옥타브 분할)

MISUMI 경제형 샤프트 스트레이트형 E-SFJ3-[L] (S45C 고주파 열처리, g7)

D안 해머 피벗축, B안 분할 키 피벗축(베드별 1개)

세부 스펙

재질 | S45C 상당, 고주파 열처리 55HRC~
공차 | g7: Ø3 = −0.002/−0.012 mm
길이 | 10–400 mm, 1 mm 단위 지정 (Ø3·Ø4 최대 400 mm)
L 공차 | 120–400 mm: ±0.5
직각도 | 끝단 0.2
표면조도 | Ra 0.4 (연삭, 판매자 Q&A)
유효경화층 | ≥0.5 mm
SUS 버전 | E-SSFJ3 (마르텐사이트 SUS)

대안

- 배관몰 스텐연마봉 SUS304 Φ3×1M + 절단 (https://baegwan.net/goods/view?no=4356) · 9,600원 — 1 m 9,600원 + 절단 1컷 500원. 163 mm×8개 = 연마봉 2본 + 8컷 ≈ 23,200원(착불). 비경화 SUS304지만 연마봉이라 직경 정밀

미스미 Ø3/Ø4는 최대 400 mm라 1250 mm 연속축 불가 → 출력 베드(≈옥타브) 단위 분할축으로 설계. 163 mm×8개 미스미 총액 ≈ 74,400원(VAT 별도) vs 연마봉 절단 ≈ 23,200원+배송.

가격 메모: 배관몰 SUS304 연마봉 — Φ3/Φ4/Φ5 동일 9,600원/m, 절단 1컷 500원, 착불 · 절단비 4,000원 포함

배관몰9,600원 (https://baegwan.net/goods/view?no=4356)한국미스미10,233원 (https://kr.misumi-ec.com/vona2/detail/110310559529/?HissuCode=E-SFJ3-163)한국미스미14,779원 (https://kr.misumi-ec.com/vona2/detail/110310559529/?HissuCode=E-SFJ3-300)

9,600원 · 2개 · m, 163 mm × 8 절단23,200원

평철 6×16 mm (D안 해머 웨이트 55 mm×88) — 최근접 19×6 × 3.13

counterweight

#### 평철 6×16 mm (D안 해머 웨이트 55 mm×88) — 최근접 19×6

원자재닷컴 스틸 평철 6M — 폭 19 × 두께 6 (16 mm 폭 미취급)

D안 해머 웨이트 (55 mm 절단 88개, 총 ≈4.9 m)

세부 스펙

요청 규격 | 16 × 6 mm — 판매처 폭 옵션 19/25/32…(16 없음)
최근접 | 19 × 6 mm, 6 m: 8,600 + 5,770 = 14,370원 (≈2,395원/m)
대안 | 25 × 6 mm: 8,600 + 8,110 = 16,710원
절단비 | 6–7t 컷당 2,000원 → 88컷 ≈ 176,000원
개당 질량 16×6×55 | 5.28 cm³ → ≈41.4 g
개당 질량 19×6×55 | 6.27 cm³ → ≈49.2 g
배송 | 착불

대안

- 25×6 평철 6 m (https://www.onezaze.com/goods/goods_view.php?goodsNo=141) · 16,710원 — 폭을 줄이지 않고 두께 6 유지, 16,710원

16 mm 폭이 필수면 19×6을 설계에 반영(질량 +19 %)하거나 판재 레이저 재단 견적 필요(미조사).

가격 메모: 19×6 옵션(+5,770원). 19×3은 품절. 절단 컷당 2,000원(6–7t)

원자재닷컴14,370원 (https://www.onezaze.com/goods/goods_view.php?goodsNo=141)

14,370원 / 6 · 1묶음 · m, 직접 절단 (19×6)14,370원

육각 렌치볼트(캡스크류) M3/M4/M5 + 와셔 × 1

fastener

#### 육각 렌치볼트(캡스크류) M3/M4/M5 + 와셔

볼트집 SCM435 육각렌지볼트 (1000개 단위)

프레임·인서트 체결

세부 스펙

M3×5–12 | 27,750원/1000개
M3×15 | 29,200원/1000개
M3×20 | 33,580원/1000개
M4×6–12 | 27,750원/1000개
M5×6–10 | 29,200원/1000개
스텐 평와셔 M3/M4/M5 | 20원/개
재질 | SCM435 (흑색)

대안

- 11번가 880개 볼트·너트·와셔 세트 M2–M5 (8–20 mm) (https://www.11st.co.kr/products/9620442948) · 20,100원 — 소량 다규격 → 시제품 단계에 적합, 무료배송
- 11번가 520개 스텐 볼트·너트 세트 M2–M5 (https://www.11st.co.kr/products/9631491191) · 16,270원 — 16,270원, 무료배송

볼트집은 소경 렌치볼트를 1000개 단위로만 판매 → 규격 수가 많으면 세트가 경제적.

가격 메모: M3×8 1000개 27,750원 (≈28원/개), 배송 3,000원

볼트집27,750원 (https://boltzip.com/product/detail.html?product_no=64)볼트집20원 (https://boltzip.com/product/detail.html?product_no=87)

27,750원 / 1000 · 1묶음 · M3 볼트 1000개27,750원

시제품 검증. 해머 1개 + 건반 1개 지그로 추 여유와 과회전 스톱을 먼저 확인하고, 1옥타브로 DW/UW와 연타 반응을 측정합니다.

## 전자·배선 · PCB 없이 납땜으로

건반 모듈 7개와 페달 모듈 1개가 각각 표준 USB-MIDI 장치로 Pi 5에 연결됩니다(R8·R9·D3). 모듈 하나는 피코 1개 + 16채널 MUX 1개 + 만능기판 1장이고, 센서는 센서 레일 위에서 전선으로 이어 붙입니다.

### E-1전체 신호 흐름

### E-2건반 모듈 배선도 (O2 예)

피코 핀 | 연결 | 메모
GP26 (ADC0) | MUX SIG | 센서 신호 (모듈당 1개 ADC)
GP2–GP5 | MUX S0–S3 | 채널 선택 (0–15)
GND (38번) | MUX EN | 항상 켬 (LOW)
3V3 OUT (36번) | 센서 VCC 버스 · MUX VCC | 센서 12–15개 × 약 6 mA ≈ 100 mA
AGND (33번) | 센서 GND 버스 · MUX GND | 아날로그 잡음 분리
ADC_VREF | — | 기본(3.3 V) 사용, 센서 출력이 전원 비례형
USB | 허브 | USB-MIDI + 전원

- 스캔: MUX 채널 전환 후 약 5 µs 기다렸다 읽으면 16채널 한 바퀴가 약 0.2 ms → 건반당 약 5 kHz로 읽습니다. 속도 계산(R2)에 충분합니다.
- 센서 레일 배선: VCC·GND는 0.5 mm 주석 도금 단선을 레일 뒤 홈을 따라 버스로 깔고, 센서 다리를 그대로 납땜합니다. 신호선은 AWG28 실리콘선으로 모듈까지(15–25 cm).
- 레일과 모듈 사이는 JST-XH 커넥터로 떼어낼 수 있게 합니다. 고장 모듈을 통째로 바꿀 수 있습니다.

### E-3부품

TI DRV5055A3 선형(아날로그) 홀 효과 센서, TO-92 스루홀 × 100

센서

#### TI DRV5055A3 선형(아날로그) 홀 효과 센서, TO-92 스루홀

DRV5055A3QLPG (소량 포장 DRV5055A3QLPGM도 동일 칩) — 3.3 V에서 15 mV/mT, ±88 mT

건반 밑면 자석이 5–6 mm 내려오는 동안의 거리를 연속 전압으로 바꿔 주는 핵심 센서입니다. 위치를 연속으로 읽어 속도(벨로시티)를 계산하므로 스위치형이 아닌 선형 아날로그 출력이 필요합니다.

세부 스펙

감도 @3.3V | 15 mV/mT typ (14.3–15.8), 5 V에서는 25 mV/mT
선형 측정범위 @3.3V | ±88 mT (A3). 참고: A1 ±22 / A2 ±44 / A4 ±176 mT
전원 전압 | 3.0–3.63 V 또는 4.5–5.5 V (Pico 3V3에 직결 가능)
출력 형식 | 비율계(ratiometric) 아날로그 전압, 0 mT에서 VCC/2(1.65 V), 선형 출력 0.2 V ~ VCC−0.2 V, ±1 mA 구동
대역폭 / 지연 | 20 kHz / 10 µs
노이즈 @3.3V | 입력환산 215 nT/√Hz → 20 kHz 전대역 0.2 mTpp, A3 출력환산 약 3 mVpp (RC 필터로 저감 가능)
온도 특성 | 감도 +0.12 %/°C 자석 온도보상(A 시리즈), 영점 드리프트 ±1 %×VCC (−40~125 °C)
소비 전류 | 2 mA typ / 4 mA max @3.3 V
패키지 / 핀 | TO-92 3핀(LPG): 1=VCC, 2=GND, 3=OUT. 패키지 마킹면에 수직인 자속만 감지
바이패스 | VCC–GND 사이 세라믹 0.01 µF 이상 권장(데이터시트)

대안

- TI DRV5055A4QLPG (3.3 V에서 7.5 mV/mT, ±176 mT) (https://www.eleparts.co.kr/goods/view?no=7339085) · 1,070원 — 눌림 시 자석–센서 간격이 3.5 mm보다 가까워져 70 mT를 넘으면 A3가 포화되므로 A4로 바꿉니다. 해상도는 절반이 됩니다(엘레파츠 100개 이상 972.73원 VAT별도).
- Honeywell SS49E (TO-92S, 2.7–6.5 V) (https://www.eleparts.co.kr/goods/view?no=14212823) · 678원 — 더 싸지만 감도가 5 V 기준 1.4 mV/G(≈14 mV/mT)로 규정되고, 비율계라 3.3 V에서는 약 9 mV/mT로 줄어듭니다(추정). 온도보상·편차 규격이 느슨하고, 무명 '49E' 호환품은 편차가 더 큽니다(엘레파츠 100개 이상 616.36원 VAT별도).
- Allegro A1308 / A1324 (SIP 스루홀) (https://www.allegromicro.com/-/media/Files/Datasheets/A1308-9-Datasheet.ashx) — 정밀도는 좋지만 공급전압이 4.5–5.5 V 전용이라 3.3 V ADC에 바로 연결할 수 없습니다(5 V 공급 + 분압 필요). 이 프로젝트에는 권하지 않습니다(데이터시트 확인, 국내 가격 미조사).

감도 변형 선택: 3.3 V 기준 A1 60 mV/mT(±22 mT), A2 30(±44), A3 15(±88), A4 7.5(±176) (TI 데이터시트 SBAS640C, 2026-06 개정). '5–20 mT' 스윙이면 A1, '15–150 mT' 스윙이면 A4가 맞습니다. 권장 자석 Ø6×3 N35(Br≈1.18 T)의 축상 자장을 계산하면 간격 3 mm≈110 mT, 4 mm≈70 mT, 5 mm≈47 mT, 8 mm≈17 mT, 10 mm≈10 mT입니다. 눌림 간격 4 mm, 휴지 간격 9.5 mm(행정 5.5 mm)로 잡으면 약 11→70 mT가 되고, A3 출력 스윙은 약 0.9 V(12비트 ADC 기준 약 1,100 LSB)로 벨로시티 계산에 충분하며 포화 여유도 있습니다. 간격을 3.5 mm보다 가깝게 설계하면 A4를 쓰세요. S극이 마킹면을 향하면 출력이 VCC/2 위로 올라가도록 모든 자석의 극성을 통일하세요. TO-92는 마킹면에 수직인 자속을 감지하므로, 리드를 90° 꺾어 마킹면이 위(자석 쪽)를 보도록 눕혀 장착합니다. 자장 값은 이상적인 원통 자석의 축상 근사치이며 실제로는 자석 편차와 수평 어긋남 때문에 달라지므로 시험 쿠폰으로 확인이 필요합니다. 비율계 출력이라 센서와 Pico ADC_VREF를 같은 3V3에서 공급하면 전원 변동이 상쇄됩니다.

가격 메모: DRV5055A3QLPG. 100개 이상 구간 918.18원(VAT별도, 관세·수입운송비 포함) → VAT 포함 약 1,010원/개. 1개 구매 시 1,290.91원(VAT별도)=1,420원. 해외 주문품, 평균 발송 4.5일

엘레파츠1,010원 (https://www.eleparts.co.kr/goods/view?no=8320049)LCSC (해외 직구)633원 (https://www.lcsc.com/product-detail/Hall-Sensor_Texas-Instruments-DRV5055A3QLPGM_C266124.html)디바이스마트 (해외 리셀러 검색결과)1,551원 (https://www.devicemart.co.kr/goods/search?search_text=DRV5055A3QLPGM)

1,010원 · 100개 · 88 + 여분 12101,000원

네오디움 원형(디스크) 자석 Ø6×3 mm, N35, Ni-Cu-Ni 도금 × 100

센서

#### 네오디움 원형(디스크) 자석 Ø6×3 mm, N35, Ni-Cu-Ni 도금

원형 네오디움 자석 옵션 '6*3' (N35) — 이마그넷(페타크리에이티브)

건반 밑면 포켓에 넣어 건반과 함께 움직이는 자기장원입니다. 홀 센서가 이 자석까지의 거리를 읽어 건반 위치와 속도를 계산합니다.

세부 스펙

치수 | Ø6 × 3 mm 원판, 두께 방향(축방향) 자화 — 일반 원판 자석 기준, 판매 페이지에 자화 방향 명시 없음
등급 | N35 (판매 페이지 표기)
잔류자속밀도 Br | N35 표준값 약 1.17–1.21 T (등급 표준, 판매처 미기재)
도금 | Ni-Cu-Ni (판매 페이지 표기)
흡착력 | 약 0.9 kg (판매 페이지 '수직당김')
판매 단위 | 10개 1,500원
계산 자장(축상) | 간격 4 mm ≈ 70 mT, 6 mm ≈ 32 mT, 10 mm ≈ 10 mT (Br 1.18 T 가정)
원산지 | 중국 (판매 페이지 표기)

대안

- Ø5×2 mm N35 (이마그넷, 15개 1,200원) (https://emagnet.co.kr/product/%EC%9B%90%ED%98%95-%EB%84%A4%EC%98%A4%EB%94%94%EC%9B%80-%EC%9E%90%EC%84%9D-%C3%982mm-%C3%9850mm-%EC%82%AC%EC%9D%B4%EC%A6%88-%EC%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) · 1,200원 — 건반 포켓이 좁을 때. 자장이 약해(4 mm에서 ≈44 mT) 간격을 1 mm쯤 더 좁혀야 합니다.
- Ø8×3 mm N35 (이마그넷, 10개 2,000원) (https://emagnet.co.kr/product/%EC%9B%90%ED%98%95-%EB%84%A4%EC%98%A4%EB%94%94%EC%9B%80-%EC%9E%90%EC%84%9D-%C3%982mm-%C3%9850mm-%EC%82%AC%EC%9D%B4%EC%A6%88-%EC%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) · 2,000원 — 간격을 5–6 mm로 넓게 잡아야 할 때. 4 mm에서 ≈95 mT라 A3는 포화되므로 A4와 함께 쓰세요.

N52 Ø6×3은 4 mm에서 약 85 mT로 A3 선형 한계(±88 mT)에 너무 가까워 오히려 불리하므로 N35를 권합니다. 국내 판매처에서 N52 Ø6×3 상품은 확인하지 못했습니다(해외 직구 미검증). 모든 자석은 같은 극이 센서를 향하게 장착하세요(기준 자석으로 극 확인). 네오디움은 고온에서 자력이 떨어지므로 인두 열로 포켓에 녹여 박지 말고 압입 또는 접착하세요.

가격 메모: 옵션 6*3 = 10개 1,500원 → 100개 15,000원. 배송비 3,000원, 배송 3–7일

이마그넷(페타크리에이티브)1,500원 (https://emagnet.co.kr/product/%EC%9B%90%ED%98%95-%EB%84%A4%EC%98%A4%EB%94%94%EC%9B%80-%EC%9E%90%EC%84%9D-%C3%982mm-%C3%9850mm-%EC%82%AC%EC%9D%B4%EC%A6%88-%EC%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)엘레파츠 (정우자석)1,870원 (https://www.eleparts.co.kr/goods/view?no=13805)다온마그네트4,400원 (https://domagnet.co.kr/product/%EC%B4%88%EA%B0%95%EB%A0%A5-%EC%9B%90%ED%98%95-%EB%84%A4%EC%98%A4%EB%94%94%EC%9B%80%EC%9E%90%EC%84%9D-%EC%9B%90%ED%98%95%EC%9E%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)

1,500원 / 10 · 10묶음 · 88 + 여분 1215,000원

CD74HC4067 16채널 아날로그 멀티플렉서 브레이크아웃 모듈 × 8

MCU/인터페이스

#### CD74HC4067 16채널 아날로그 멀티플렉서 브레이크아웃 모듈

CD74HC4067 16CH Analog/Digital MUX Breakout (파란색 범용 모듈)

한 모듈의 센서 12–15개 출력을 Pico의 ADC 핀 1개로 차례로 골라 읽게 해 주는 아날로그 스위치입니다. S0–S3 4비트 주소로 채널을 고릅니다.

세부 스펙

채널 | 16:1 단일 아날로그/디지털 양방향 스위치
공급 전압 | 2–6 V (HC 타입) → 3.3 V로 구동
ON 저항 | 70 Ω typ / 160 Ω max @VCC 4.5 V, 25 °C (3.3 V 값은 데이터시트 표에 없음, 이보다 다소 큼)
채널 간 ON 저항 차 | ΔRON 10 Ω typ @4.5 V
OFF 누설 | ±0.8 µA max @6 V, 25 °C
스위칭 | break-before-make 6 ns typ @4.5 V
입력 전압 범위 | 0 ~ VCC (VCC 초과 금지)
모듈 핀 | C0–C15 1×16, SIG·S3·S2·S1·S0·EN·VCC·GND 1×8 (2.54 mm)
동작 온도 | −55 ~ 125 °C

대안

- SparkFun Analog/Digital MUX Breakout BOB-09056 (https://www.devicemart.co.kr/goods/view?no=1247665) · 12,320원 — 정품 SparkFun 보드라 회로도·문서가 확실하지만 가격이 2–3배입니다.

VCC는 Pico 3V3로 공급하세요(5 V 금지 — SIG 전압이 VCC까지 올라가 ADC 입력 한계를 넘을 수 있음). EN은 GND에 묶거나(활성 Low) GPIO로 제어합니다. 채널을 바꾼 뒤 수 µs 정착 시간을 두고 첫 샘플은 버리면 안전합니다. 모듈 크기는 일반적으로 약 40×18 mm이지만 판매 페이지에 치수가 없습니다. 세 판매처 모두 같은 형태의 범용(호환) 모듈로 보이며, 이미지는 vctec 상품 사진입니다. 핀헤더 동봉 여부는 판매처마다 다르니 e-header를 함께 사세요.

가격 메모: 판매가 4,400원(상품가 4,000 + 세액 400). 배송비 3,000원. 공급사 JKEMC

툴파츠4,400원 (https://toolparts.co.kr/product/cd74hc4067-16ch-analog-digital-mux-breakout-board-cd74hc4067-%EA%B3%A0%EC%86%8D-cmos-1/66263/)가치창조기술(vctec)4,950원 (https://vctec.co.kr/product/16%EC%B1%84%EB%84%90-%EC%95%84%EB%82%A0%EB%A1%9C%EA%B7%B8%EB%94%94%EC%A7%80%ED%84%B8-%EB%A9%80%ED%8B%B0%ED%94%8C%EB%A0%89%EC%84%9C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)아이씨뱅큐5,060원 (https://www.icbanq.com/P007324744)

4,400원 · 8개 · 건반 모듈 7 + 여분 135,200원

라즈베리파이 피코 2 (RP2350) 마이크로컨트롤러 보드 — 헤더 미납땜 × 9

MCU/인터페이스

#### 라즈베리파이 피코 2 (RP2350) 마이크로컨트롤러 보드 — 헤더 미납땜

Raspberry Pi Pico 2 (SC1631)

각 모듈에서 먹스 주소를 돌리며 센서 16채널을 ADC로 계속 스캔하고, 위치에서 속도를 계산해 USB-MIDI 장치로 Pi 5에 노트 이벤트를 보냅니다.

세부 스펙

MCU | RP2350A, 듀얼 Cortex-M33 또는 Hazard3 RISC-V @150 MHz, 520 KB SRAM, 4 MB QSPI 플래시
ADC | 12비트 SAR, 500 kS/s, ENOB 9.2 (RP2350 데이터시트), 헤더에 3채널(GPIO26–28) 노출
ADC 기준 | ADC_VREF = 3.3 V를 필터링한 전압(외부 기준 연결 가능)
USB | Micro-USB B, USB 1.1 Device/Host (Full-speed 12 Mbps) — TinyUSB로 USB-MIDI 구현
GPIO | 26개 3.3 V GPIO (먹스 S0–S3용 4핀으로 충분)
입력 전압 | VSYS 1.8–5.5 V, 3V3 핀 외부 부하는 300 mA 미만 권장
크기 | 51 × 21 mm, 2.54 mm 스루홀·캐스텔레이션 40핀, 고정홀 4 × Ø2.1 mm
동작 온도 | −20 ~ 85 °C
비교: Pico(RP2040) | ENOB 8.7, Cortex-M0+ 133 MHz, 264 KB SRAM, 2 MB 플래시

대안

- Raspberry Pi Pico (RP2040, SC0915) (https://www.devicemart.co.kr/goods/view?no=13921792) · 5,940원 — 더 싸고 자료가 많지만 ADC ENOB가 8.7이고 특정 코드에서 DNL 튐 현상(RP2040 에라타 E11)이 알려져 있어 실효 해상도가 낮습니다.
- Raspberry Pi Pico H (RP2040, 헤더 납땜 완료, SC0917) (https://www.devicemart.co.kr/goods/view?no=14021609) · 7,040원 — 헤더 납땜을 피하고 싶을 때. 칩은 RP2040이라 ADC 성능은 Pico와 같습니다.

Pico 2는 Pico와 핀·크기가 완전히 호환됩니다. 2025년 7월 공개된 RP2350 A4 스테핑에서 GPIO 풀다운 관련 에라타 E9가 수정되었습니다(ADC로 쓰는 핀은 SDK가 디지털 입력 버퍼를 꺼서 구형 스테핑에서도 영향이 작음). 이 설계는 먹스 1개 → ADC 1핀이라 3채널로 충분합니다. 헤더가 없는 제품이므로 1×40 핀헤더를 Pico 1개당 1줄(1×20 두 개로 절단) 준비하세요(e-header). ADC 잡음을 줄이려면 온보드 SMPS를 PWM 모드로 고정(GPIO23 High)하는 방법이 데이터시트에 설명되어 있습니다. 디바이스마트 재고는 조사 초반 '장바구니' 버튼으로만 확인했습니다.

가격 메모: 6,800원(VAT별도) → 7,480원. 6.6만원(VAT 포함) 이상 무료배송, 미만 3,000원. 디바이스마트 가격은 2026-09-24 조사 초반 상품페이지에서 확인(VAT 포함가). 조사 도중 디바이스마트 서버가 이 조사 환경의 접속을 차단해 이미지는 받지 못했음.

디바이스마트7,480원 (https://www.devicemart.co.kr/goods/view?no=15540884)엘레파츠7,810원 (https://www.eleparts.co.kr/goods/view?no=16580031)아이씨뱅큐12,100원 (https://www.icbanq.com/P016314420)

7,480원 · 9개 · 건반 7 + 페달 1 + 여분 167,320원

양면 에폭시(FR-4) 만능기판 70×90 mm, 2.54 mm 피치 — 모듈 메인 보드 × 9사진: 같은 규격의 다른 제품

기판/배선

#### 양면 에폭시(FR-4) 만능기판 70×90 mm, 2.54 mm 피치 — 모듈 메인 보드

범용 에폭시 만능 PCB 기판 70X90-양면 [PCB-0709S]

각 모듈의 Pico 2, 먹스 모듈, 커넥터를 올려 손납땜하는 메인 보드입니다(PCB 제작 없이).

세부 스펙

재질 | 에폭시(FR-4), 양면
크기 | 70 × 90 mm
홀 수 | 26 × 31 = 806홀
피치 | 2.54 mm
두께 | 1.6 mm
배치 여유 | Pico(51×21 mm) + 먹스 모듈(약 40×18 mm) + 커넥터 배치 가능

대안

- PCB-0507S 50×70 양면 (18×24홀) (https://www.devicemart.co.kr/goods/view?no=1341717) · 660원 — 페달 모듈처럼 작게 만들 때
- PCB-0915S 90×150 양면 (33×54홀) (https://www.devicemart.co.kr/goods/view?no=1341720) · 1,870원 — Pico, 먹스, 커넥터를 넉넉하게 배치하거나 두 모듈을 한 판에 올릴 때

이미지는 디바이스마트 서버 차단 때문에 같은 규격(양면 FR-4, 2.54 mm)인 엘레파츠 두 번째 판매처 상품 사진입니다. 스탠드오프(M3)용 모서리 구멍은 3.2 mm로 직접 뚫어야 합니다.

사진 출처: https://img2.eleparts.co.kr/goods/1/2019/08/8127469_tmp_0688a653f81b2d664246e85ff7ec70e89499large.jpg

가격 메모: VAT 포함 1,188원. 디바이스마트 가격은 2026-09-24 조사 초반 상품페이지에서 확인(VAT 포함가). 조사 도중 디바이스마트 서버가 이 조사 환경의 접속을 차단해 이미지는 받지 못했음.

디바이스마트1,188원 (https://www.devicemart.co.kr/goods/view?no=1341719)엘레파츠 (삼일피앤유 A5, 70×80 양면 원형패드)1,925원 (https://www.eleparts.co.kr/goods/view?no=8127469)

1,188원 · 9개 · 모듈마다 1장 + 여분10,692원

단면 에폭시 만능기판 150×200 mm — 센서 레일용 긴 스트립으로 절단 사진: 같은 규격의 다른 제품

기판/배선

#### 단면 에폭시 만능기판 150×200 mm — 센서 레일용 긴 스트립으로 절단

범용 에폭시 만능 PCB 기판 150X200-단면 [PCB-1520D]

y=110 mm 레일에 붙는 센서 스트립입니다. 20 mm 폭으로 자르면 길이 200 mm 스트립이 7개 나오므로, 한 모듈(12–15건반)의 센서를 한 줄로 실장하고 VCC/GND 버스를 깔 수 있습니다.

세부 스펙

재질 | 에폭시, 단면
크기 | 150 × 200 mm
홀 수 | 57 × 74 = 4,218홀
피치 | 2.54 mm
두께 | 1.6 mm
절단 예 | 20 mm(약 7홀) 폭 × 200 mm 스트립 7개/장

대안

- PCB-0208S 20×80 양면 스트립 (6×28홀) (https://www.devicemart.co.kr/goods/view?no=1341707) · 319원 — 자를 필요가 없는 기성 스트립. 길이가 80 mm라 한 모듈에 2–3개를 이어 붙여야 합니다.
- PCB-2030D 200×300 단면 (https://www.devicemart.co.kr/goods/view?no=1341725) · 13,860원 — 15건반 모듈을 스트립 하나에 올리려고 300 mm 길이가 필요할 때

건반 폭 계산: 흰건반 약 23.5 mm → 12건반(흰 7) 약 164.5 mm, 15건반(흰 9) 약 211 mm. 센서 중심 사이 최대 거리는 약 188 mm라 200 mm 스트립에 들어갑니다. 건반 피치는 2.54 mm 격자와 맞지 않으므로 가장 가까운 구멍을 쓰거나, 센서는 3D 프린트 레일에 고정하고 스트립은 배선용으로만 쓰세요. 자를 때는 커터로 양면에 여러 번 홈을 낸 뒤 꺾거나 쇠톱을 쓰고, FR-4 가루는 마스크를 쓰고 물걸레로 치우세요. 이미지는 디바이스마트 차단 때문에 같은 크기(150×200 단면)인 아이씨뱅큐 두 번째 판매처 상품 사진입니다.

사진 출처: https://www.icbanq.com/icdownload/data/ICBShop/Product/p_images/1277875482_m_0.jpg

가격 메모: VAT 포함 4,510원. 디바이스마트 가격은 2026-09-24 조사 초반 상품페이지에서 확인(VAT 포함가). 조사 도중 디바이스마트 서버가 이 조사 환경의 접속을 차단해 이미지는 받지 못했음.

디바이스마트4,510원 (https://www.devicemart.co.kr/goods/view?no=1341716)아이씨뱅큐 ([GB5] 150x200 사각 만능기판 단면)11,880원 (https://www.icbanq.com/P000623366)

4,510원4,510원

2.54 mm 1×40 핀헤더(수) — Pico·먹스 모듈 실장용 × 20

기판/배선

#### 2.54 mm 1×40 핀헤더(수) — Pico·먹스 모듈 실장용

[ShenzenAV] 2.54mm 핀 헤더 1x40P (Black)

헤더가 없는 Pico 2와 먹스 모듈을 만능기판에 납땜하거나 꽂기 위한 핀입니다. 1×40을 1×20 두 개로 잘라 Pico 한 개에 씁니다.

세부 스펙

피치 | 2.54 mm
배열 | 1열 40핀, 스트레이트
색상 | 블랙 (레드·옐로·그린·블루·화이트 옵션 있음)
판매 설명 | 라즈베리파이 Pico에 맞는 핀헤더
가격 구간 | 1개~ 100원, 100개~ 90원 (VAT별도)
발송 | 24시간 이내

대안

- 적층형 핀헤더소켓 Single 1×40 (암, 다리 9.1 mm) (https://www.devicemart.co.kr/goods/view?no=35611) · 1,100원 — Pico를 떼었다 붙일 수 있게 기판 쪽에 암 소켓을 쓰고 싶을 때(1×40을 자르면 1핀을 잃으니 Pico 1개당 2개 권장)
- JINLING PH01(2.54)-SS40P-11.5MM (1×40 수) (https://www.eleparts.co.kr/goods/view?no=4767) · 176원 — 브랜드 표준 헤더(160원 VAT별도)

Pico를 소켓 없이 바로 납땜하면 가장 싸고 접촉 불량이 없습니다. 예비 Pico로 바꿔 끼우고 싶다면 암 소켓을 쓰세요.

가격 메모: 100원(VAT별도) → 110원

엘레파츠110원 (https://www.eleparts.co.kr/goods/view?no=10955856)디바이스마트 (핀헤더 Single 1x40Pin Straight)220원 (https://www.devicemart.co.kr/goods/view?no=2825)

110원 · 20개 · 피코·MUX 소켓2,200원

0.1 µF(104) 50 V 모노리틱(적층) 세라믹 콘덴서, 리드형 × 110

수동소자

#### 0.1 µF(104) 50 V 모노리틱(적층) 세라믹 콘덴서, 리드형

HUI YI TECHNOLOGY Mono Cap 0.1uF 50V (Y5V/Z5U)

각 홀 센서의 VCC–GND 바로 옆에 다는 디커플링 콘덴서입니다(데이터시트 최소 0.01 µF). 먹스와 Pico 전원 디커플링에도 씁니다.

세부 스펙

정전용량 | 0.1 µF (104)
정격 전압 | 50 V
유전체 | Y5V/Z5U (온도에 따른 용량 변화가 크지만 전원 디커플링용으로 충분)
형태 | 레이디얼 리드, 모노리틱(적층) 세라믹
판매 단위 | 10개 (최소주문 10)
가격 구간 | 1개~ 30원, 100개~ 26.36원, 500개~ 23.64원 (VAT별도)
발송 | 24시간 이내

대안

- 모노리틱 커패시터 샘플 키트 [CA-KIT-06] (0.1–10 µF 10종 × 50개, 50 V) (https://www.devicemart.co.kr/goods/view?no=12779010) · 13,200원 — 0.1 µF 50개에 1–10 µF 세라믹까지 한 번에 필요할 때

X7R 등급이 더 좋지만 디커플링용으로는 Y5V도 괜찮습니다. 리드 간격은 판매 페이지에 없으니 만능기판에서는 리드를 구부려 맞추세요.

가격 메모: 100개 이상 26.36원(VAT별도) → 약 29원/개, 10개 단위 판매. 120개 ≈ 3,500원

엘레파츠29원 (https://www.eleparts.co.kr/goods/view?no=10226)부품가게 (적층 콘덴서 104 100V)7,000원 (https://ghstore.co.kr/product/%EC%A0%81%EC%B8%B5-%EC%BD%98%EB%8D%B4%EC%84%9C-102-472-103-333-473-104-224-334-474-684-105-100v/126/)디바이스마트 (Ceramic 0.1㎌ 50V)440원 (https://www.devicemart.co.kr/goods/view?no=1343)

29원 · 110개 · 센서당 100 nF + 여분3,190원

10 µF 50 V 알루미늄 전해 콘덴서 (105 °C, Ø5×11 mm) × 20

수동소자

#### 10 µF 50 V 알루미늄 전해 콘덴서 (105 °C, Ø5×11 mm)

삼영전자 KMG 10uF 50V 105℃ (5x11)

각 모듈의 3.3 V 센서 버스 입구(스트립 끝)와 Pico 3V3 근처에 다는 벌크 콘덴서입니다. 센서 12–15개가 함께 끌어가는 전류로 생기는 전압 흔들림을 줄입니다.

세부 스펙

정전용량 | 10 µF
정격 전압 | 50 V
온도 등급 | 105 °C (KMG 시리즈)
크기 | Ø5 × 11 mm, 레이디얼
제조사 | 삼영전자(SamYoung Electronics)
가격 구간 | 1개~ 30원, 200개~ 26.36원 (VAT별도), 최소주문 5

대안

- 모노리틱 커패시터 샘플 키트 [CA-KIT-06] (https://www.devicemart.co.kr/goods/view?no=12779010) · 13,200원 — 10 µF를 세라믹(ESR 낮음)으로 쓰고 싶을 때

전해 콘덴서는 극성이 있습니다(긴 다리 +). 모듈당 센서 15개 × 2 mA ≈ 30 mA + 먹스 정도라 Pico 3V3 권장 부하(300 mA 미만) 안에 여유 있게 들어갑니다.

가격 메모: 30원(VAT별도) → 33원, 최소주문 5개, 24시간 이내 발송

엘레파츠33원 (https://www.eleparts.co.kr/goods/view?no=6754632)디바이스마트 (E/C 50V 10uF 85℃ 5×11)330원 (https://www.devicemart.co.kr/goods/view?no=1318)

33원 · 20개 · 모듈 전원 안정660원

막대(리드형) 저항 10종 × 10개 패키지 (10 Ω–1 MΩ, 5 %) × 1

수동소자

#### 막대(리드형) 저항 10종 × 10개 패키지 (10 Ω–1 MΩ, 5 %)

LK임베디드 아두이노 실험 필수 저항 패키지 E4-3

먹스 SIG → ADC 직렬 저항(100 Ω–1 kΩ)과 RC 필터, EN 풀다운 10 kΩ, 상태 LED 전류 제한 등 소량의 범용 저항입니다.

세부 스펙

구성 | 10 Ω, 100 Ω, 200 Ω, 330 Ω, 1 kΩ, 2 kΩ, 5.1 kΩ, 10 kΩ, 100 kΩ, 1 MΩ
수량 | 값마다 10개, 총 100개
오차 | ±5 %
형태 | 리드형(막대) 저항
제조/판매 | LK임베디드
발송 | 24시간 이내

대안

- 1/4W F급(1 %) 금속피막 저항 130종 샘플키트 (각 20개, 총 2,600개, 1 Ω–3 MΩ) (https://www.devicemart.co.kr/goods/view?no=12533737) · 17,600원 — 앞으로 다른 회로도 만들 계획이면 한 번에 갖추기 좋음

요청한 10 kΩ·1 kΩ·100 Ω이 모두 들어 있는 엘레파츠 패키지를 추천했습니다. 디바이스마트 키트가 더 싸지만 100 Ω이 없습니다(220 Ω로 대체 가능).

가격 메모: 5,000원(VAT별도) → 5,500원

엘레파츠5,500원 (https://www.eleparts.co.kr/goods/view?no=12858123)디바이스마트 (아두이노 막대저항 키트 KIT050014)1,980원 (https://www.devicemart.co.kr/goods/view?no=1385274)

5,500원 · 1개 · 페달 풀업·LED5,500원

26AWG 실리콘 연선 6색 세트 (총 60 m) × 1

기판/배선

#### 26AWG 실리콘 연선 6색 세트 (총 60 m)

CBAZY 26AWG 실리콘 와이어 6색 SET (60M)

센서 스트립에서 모듈 보드(먹스 입력)까지 가는 신호선과 전원선입니다. 실리콘 피복이라 유연하고 납땜 열에 녹지 않습니다.

세부 스펙

규격 | 26AWG 연선
피복 | 실리콘(내열, 유연)
색상 | 적·녹·청·황·흑·백 6색
길이 | 총 60 m (색마다 10 m)
브랜드 | CBAZY
발송 | 24시간 이내

대안

- CBAZY 28AWG 실리콘 와이어 6색 SET (60 m) (https://www.eleparts.co.kr/goods/view?no=7696554) · 21,450원 — 더 가늘어 좁은 곳 배선이 쉬움. 신호선엔 충분
- 디바이스마트 28AWG 6색 실리콘 와이어 키트 (48 m) (https://www.devicemart.co.kr/goods/view?no=15080723) · 32,340원 — 같은 28AWG지만 길이가 짧고 비쌈

색 규칙 예: 빨강 3V3, 검정 GND, 나머지 4색을 채널 순서로 돌려 쓰기. 긴 신호선은 GND선과 꼬아(트위스트) 잡음 결합을 줄이세요.

가격 메모: 20,800원(VAT별도) → 22,880원

엘레파츠22,880원 (https://www.eleparts.co.kr/goods/view?no=7695533)디바이스마트 (26AWG 6색 실리콘 와이어 키트 60M)24,200원 (https://www.devicemart.co.kr/goods/view?no=12375539)

22,880원 · 1개 · 신호선22,880원

주석도금 동선(나선) 0.5 mm 단선 — VCC/GND 버스용 × 1

기판/배선

#### 주석도금 동선(나선) 0.5 mm 단선 — VCC/GND 버스용

SME 주석도금선 0.5 mm (롤)

센서 스트립과 모듈 보드 위에 VCC·GND 버스 레일을 까는 피복 없는 단선입니다. 센서 전원 핀을 짧게 바로 버스에 납땜할 수 있습니다.

세부 스펙

선경 | 0.5 mm (≈24AWG). 0.1–1.0 mm 옵션 동일가
길이 | 0.5 mm 50 m (0.6 mm 40 m, 0.8 mm 20 m)
재질 | 순도 99.9 % 동 + 주석도금 (산화 방지, 납땜성 좋음)
용도 | PCB 점퍼선, 버스선, 브레드보드 점프
제조사 | SME(에스엠이교역)
발송 | 평균 2.5일

대안

- 3색 점퍼용 단선 0.6 mm (피복, 1 m 단위) (https://www.devicemart.co.kr/goods/view?no=1153807) · 440원 — 절연이 필요한 교차 구간용 피복 단선(빨강·검정·흰색 1 m씩 꼬아 배송)

나선 버스는 서로 닿지 않게 3–4홀 간격을 두고, 교차 구간에는 피복선이나 수축튜브를 쓰세요.

가격 메모: 옵션 가격 6,600원(VAT 포함), 모든 선경 동일

엘레파츠6,600원 (https://www.eleparts.co.kr/goods/view?no=7749121)네로마트 ([19767] 주석도금선 150 g)17,600원 (https://www.neromart.co.kr/goods/view?no=19767)

6,600원 · 1개 · 센서 레일 버스6,600원

JST-XH 호환 2.5 mm 커넥터 키트 (2·3·4핀 하우징 + 기판 헤더 + 크림프 단자) × 1

기판/배선

#### JST-XH 호환 2.5 mm 커넥터 키트 (2·3·4핀 하우징 + 기판 헤더 + 크림프 단자)

DFRobot FIT0255 XH2.54 Connector Kit

센서 스트립 ↔ 모듈 보드, 전원 분배선을 떼었다 붙일 수 있게 해 주는 잠금형 커넥터입니다. 수리·교체 때 납땜을 풀지 않아도 됩니다.

세부 스펙

구성 | XH-2/3/4 하우징 각 20개, 스루홀 헤더(B2B/B3B/B4B-XH) 각 20개, 크림프 단자 100개
피치 | 2.5 mm (XH 규격)
정격 전류 | 3 A (AWG22 기준)
정격 전압 | 250 V AC/DC
동작 온도 | −25 ~ 85 °C (통전 온도상승 포함)
접촉 저항 | 초기 10 mΩ max
절연 저항 / 내전압 | 1000 MΩ min / AC 1000 V 1분

대안

- Adafruit 2.5 mm Pitch Connector Kit — JST XH Compatible, 560개 [ada-4423] (https://www.devicemart.co.kr/goods/view?no=15531000) · 49,830원 — 핀수가 더 다양한 큰 키트

XH 단자 압착에는 전용 압착기가 필요합니다(t-crimper). XH 피치는 2.50 mm라 2.54 mm 만능기판 구멍에 헤더를 꽂을 수는 있지만 핀이 많으면 약간 비틀립니다(4핀 이하는 문제 없음). 이미지는 제조사(DFRobot) 사진입니다.

가격 메모: VAT 포함 10,780원. 디바이스마트 가격은 2026-09-24 조사 초반 상품페이지에서 확인(VAT 포함가). 조사 도중 디바이스마트 서버가 이 조사 환경의 접속을 차단해 이미지는 받지 못했음.

디바이스마트10,780원 (https://www.devicemart.co.kr/goods/view?no=1321203)DFRobot (해외 직구)7,450원 (https://www.dfrobot.com/product-828.html)

10,780원 · 1개 · 레일↔모듈 커넥터10,780원

듀폰(2.54 mm) 점퍼 케이블 40P 암-암(F/F) 20 cm × 3사진: 같은 규격의 다른 제품

기판/배선

#### 듀폰(2.54 mm) 점퍼 케이블 40P 암-암(F/F) 20 cm

테스트[CH254] 소켓 점퍼 케이블 40P 칼라 (F/F) 20cm

시제품 단계에서 센서·먹스·Pico를 납땜 없이 연결해 시험하는 용도입니다. 최종 조립은 진동에 빠질 수 있으므로 납땜이나 JST로 바꾸세요.

세부 스펙

형태 | 40가닥 무지개색 플랫 점퍼, 양끝 암(F/F)
커넥터 | 2.54 mm 피치 CH254 소켓
길이 | 20 cm
가닥 수 | 40
색상 | 칼라(무지개) 플랫
사용 | 원하는 가닥 수만큼 떼어 사용

대안

- 테스트[CH254] 소켓 점퍼 케이블 40P (F/F) 30 cm (https://www.devicemart.co.kr/goods/view?no=32284) · 1,100원 — 모듈 사이 거리가 멀 때

이미지는 디바이스마트 서버 차단 때문에 같은 형태(40P F/F 20 cm)인 엘레파츠 두 번째 판매처 상품 사진입니다.

사진 출처: https://img2.eleparts.co.kr/goods/thumb/1/014003001000010275.jpg

가격 메모: VAT 포함 935원. 디바이스마트 가격은 2026-09-24 조사 초반 상품페이지에서 확인(VAT 포함가). 조사 도중 디바이스마트 서버가 이 조사 환경의 접속을 차단해 이미지는 받지 못했음.

디바이스마트935원 (https://www.devicemart.co.kr/goods/view?no=1321192)엘레파츠 (소켓 점퍼케이블 DC-40P 20cm F/F)3,135원 (https://www.eleparts.co.kr/goods/view?no=12162)

935원 · 3개 · 시험·디버깅2,805원

USB-A ↔ 마이크로 5핀(Micro-B) 케이블 0.3 m (USB 2.0 데이터 지원) × 9

USB/전원

#### USB-A ↔ 마이크로 5핀(Micro-B) 케이블 0.3 m (USB 2.0 데이터 지원)

강원전자 NETmate NMC-FMB03

각 Pico 2를 케이스 안의 USB 허브에 연결하는 짧은 데이터 겸 전원 케이블입니다. Pico 2는 Micro-USB B 단자입니다.

세부 스펙

커넥터 | USB-A(수) ↔ Micro 5핀 B(수)
길이 | 0.3 m
데이터 | USB 2.0 (다나와 스펙 표기)
최대 전류 | 2.1 A
브랜드 | 강원전자 NETmate
재고 | 아이씨뱅큐 국내 재고, 2–3일

대안

- Coms IH158 USB-A ↔ Micro 5핀 30 cm, 180° 꺾임 (https://www.icbanq.com/P013035941) · 3,520원 — 허브와 보드가 나란히 있을 때 U자로 꺾인 형태가 편할 수 있음(3,200원 VAT별도)
- 마이크로 5핀 To USB 고속충전 케이블 0.5 m [DW-USBM5AC-0.5M] (https://www.devicemart.co.kr/goods/view?no=1355827) · 1,540원 — 더 싸지만 '충전용'으로만 표기되어 데이터 선 유무를 확인해야 함

충전 전용(데이터선 없음) 케이블을 쓰면 Pico가 PC/Pi에서 인식되지 않습니다. 케이블 한 개로 먼저 USB-MIDI 인식을 확인한 뒤 나머지를 사세요.

가격 메모: 2,800원(VAT별도) → 3,080원. 다나와에는 790원(쿠팡 등) 최저가가 표시되지만 해당 판매 페이지는 직접 확인하지 않음

아이씨뱅큐3,080원 (https://www.icbanq.com/P013738737)

3,080원 · 9개 · 피코 → 허브27,720원

ORICO 유전원 USB 3.0 허브 10포트 (포트별 개별 스위치) × 1

USB/전원

#### ORICO 유전원 USB 3.0 허브 10포트 (포트별 개별 스위치)

ORICO CT2U3-10AB

Pico 8개를 케이스 안에서 Pi 5 한 포트로 모으고, 어댑터로 전원을 공급하는 허브입니다. 포트별 스위치로 모듈 하나만 껐다 켤 수 있습니다.

세부 스펙

포트 | USB-A 10포트, 포트마다 전원 스위치 + LED
규격 | USB 3.0 5 Gbps (USB 2.0/1.1 하위호환)
칩셋 | VIA VL817
전원 | 외장 어댑터 포함(유전원)
포트당 출력 | BC1.2, 2.4 A 표기 (해외 판매처 eventus.si 기준)
크기 | 190 × 58 × 26 mm
업스트림 | 분리형 USB-A ↔ USB-B 케이블 1 m
색상 | 블랙 / 화이트

대안

- ORICO A3H10 (알루미늄, 10포트 USB 3.0, 12 V 어댑터) (https://orico.co.kr/product/a3h10/24/) · 79,000원 — 금속 케이스가 필요할 때. 실버 재고 있음, 블랙은 품절 표시
- ipTIME UH308 (유전원) (https://www.icbanq.com/P006960075) · 33,330원 — 싸지만 USB 3.0 4포트 + USB 2.0 3포트 + 충전 전용 1포트라 데이터 포트가 7개뿐입니다 → Pico 8개에 부족(비추천)

Pico는 USB Full-speed(12 Mbps) 장치이고 MIDI 데이터는 매우 적어 허브 대역폭은 문제가 되지 않습니다. 어댑터 정격은 한국 판매 페이지에 없고 해외 리뷰 제목에 48 W로 나와 있으나 직접 확인하지 못했습니다. 유전원 허브는 업스트림 포트로 Pi 쪽에 역전류를 흘리는 경우가 있으니, 처음 연결할 때 Pi 전원을 끈 상태에서 허브만 켰을 때 Pi가 켜지지 않는지 확인하세요.

가격 메모: 판매가 71,000원, 배송비 무료. 색상 블랙/화이트 선택

오리코 한국 공식몰71,000원 (https://orico.co.kr/product/ct2u3-10ab/18/)

71,000원 · 1개 · 10포트71,000원

유연 실납 Sn63/Pb37, 0.8 mm, 100 g × 1

납땜 소모품

#### 유연 실납 Sn63/Pb37, 0.8 mm, 100 g

Pro'sKit 8PK-033D

센서·콘덴서·배선 수백 곳을 납땜하는 기본 소모품입니다. 공정 조성(Sn63)이라 183 °C에서 바로 굳어 초보자도 냉납이 적습니다.

세부 스펙

조성 | 주석 63 % / 납 37 % (공정 조성)
융점 | 183 °C (Sn63/Pb37 공정점)
선경 | 0.8 mm
중량 | 100 g
원산지 | 대만 (Pro'sKit)
플럭스 | 제조사 페이지에 코어 플럭스 종류·함량 미기재

대안

- 하코툴 LT소재 소량 일반납 1.0 mm 100 g (https://hakkotool.com/goods/view?no=2212) · 9,460원 — 국산(희성/LT소재) 소량 포장. 조성은 목록에 명시 없음
- Alpha Telecore XL-806 Sn63/Pb37 0.6 mm 500 g (무세척 플럭스 코어) (https://www.devicemart.co.kr/goods/view?no=1328324) · 66,000원 — 고품질 브랜드 실납, 대용량

유연 vs 무연: 유연(Sn63/Pb37)은 녹는점이 낮고(183 °C) 인두 온도 320–340 °C 정도로 작업이 쉬워 취미용에 유리합니다. 대신 납 성분이므로 환기하고 작업 후 손을 씻으세요. 무연(Sn99.3Cu0.7 약 227 °C, SAC305 약 217–220 °C)은 더 높은 온도가 필요하고 광택이 덜해 초보자에겐 까다롭습니다.

가격 메모: 즉시할인가 13,090원(상품가 11,900 + VAT 1,190). 배송비 3,300원(15만원 이상 무료)

KJ-MALL (프로스킷 판매점)13,090원 (https://kj-mall.com/product/detail.html?product_no=27969)

13,090원 · 1개13,090원

무세척 플럭스 펜 (유연납용) 2자루 세트 × 1

납땜 소모품

#### 무세척 플럭스 펜 (유연납용) 2자루 세트

SME 무세척 플럭스 펜 유연납용 HS02 (펜촉 0.2 mm + 0.5 mm)

산화된 리드나 만능기판 패드에 발라 납이 잘 퍼지게 하고, 납 브리지·재작업을 쉽게 합니다.

세부 스펙

종류 | 무세척(No-clean) 플럭스 펜
대상 | 유연납용
구성 | 2자루 1세트
펜촉 | 0.2 mm 1자루 + 0.5 mm 1자루 (가는 패드·넓은 면 겸용)
리필 | 빈 펜 용기 HS07(4자루+스포이드) 별매
제조사 | SME(에스엠이교역)
발송 | 평균 2일

대안

- Pro'sKit 납땜용 페이스트 8S005 (https://kj-mall.com/product/detail.html?product_no=27946) · 4,070원 — 가장 싼 페이스트형(붓/이쑤시개로 도포)
- Chemtronics CW8200 로진 플럭스 펜 9 g (https://www.eleparts.co.kr/goods/view?no=16299474) · 11,000원 — Kester 186 대체 로진 플럭스 펜(10,000원 VAT별도)

무세척 플럭스도 잔여물이 끈적하면 IPA로 닦아 주세요. 센서 신호선 주변 잔여물은 습기를 먹으면 누설 경로가 될 수 있습니다.

가격 메모: 9,000원(VAT별도) → 9,900원

엘레파츠9,900원 (https://www.eleparts.co.kr/goods/view?no=2305031)

9,900원 · 1개9,900원

납 흡입 심지(솔더윅) 2 mm × 2 m × 1

납땜 소모품

#### 납 흡입 심지(솔더윅) 2 mm × 2 m

Pro'sKit DP-033B

잘못 붙은 납, 브리지, 부품 교체 시 남은 납을 빨아들여 제거합니다.

세부 스펙

폭 | 2.0 mm
길이 | 2 m
재질 | 고품질 구리선 정밀 편조 (제조사 표기)
케이스 | 손잡이형 방열 케이스 + 스테인리스 노즐, 풀림 길이 조절식
크기 | 101 × 47.5 × 18.5 mm (시리즈 표기)
모델 / 브랜드 | DP-033B / Pro'sKit
원산지 | 중국 (판매 페이지 표기)

대안

- Pro'sKit 솔더위크 8PK-031B (녹색, 2.0 mm) (https://kj-mall.com/product/detail.html?product_no=27954) · 1,760원 — 더 싼 소포장(길이 표기 없음)

플럭스를 조금 발라 쓰면 흡입이 훨씬 잘 됩니다.

가격 메모: 즉시할인가 4,180원(상품가 3,800 + VAT 380). 배송비 3,300원(15만원 이상 무료)

KJ-MALL4,180원 (https://kj-mall.com/product/detail.html?product_no=27976)

4,180원 · 1개4,180원

열수축 튜브 세트 530개 (2:1, Ø1.5–10 mm, 5색, 보관 케이스) × 1

납땜 소모품

#### 열수축 튜브 세트 530개 (2:1, Ø1.5–10 mm, 5색, 보관 케이스)

엘레파츠 열수축튜브 530세트 - 프라스틱케이스

선과 선을 이은 곳, 센서 리드, 버스 교차부를 절연하고 색으로 구분합니다.

세부 스펙

수축률 | 2:1
직경 | 1.5–10 mm
색상 | 흑·적·황·청·녹
구성 | 12종 530개
포장 | 플라스틱 보관 케이스
발송 | 24시간 이내

대안

- 엘레파츠 열수축튜브 280세트 (Ø1–10 mm, 5색, 케이스) (https://www.eleparts.co.kr/goods/view?no=8170312) · 4,620원 — 개수가 적은 대신 쌈
- 엘레파츠 열수축튜브 328세트 (Ø1–14 mm 8종 5색, 비닐 포장) (https://www.eleparts.co.kr/goods/view?no=9866020) · 3,380원 — 가장 쌈, 케이스 없음

센서 TO-92 리드처럼 얇은 곳엔 Ø1.5 mm, 26AWG 선 이음엔 Ø2 mm가 맞습니다. 라이터보다 열풍기나 인두 옆면을 쓰세요.

가격 메모: 6,000원(VAT별도) → 6,600원

엘레파츠6,600원 (https://www.eleparts.co.kr/goods/view?no=8170311)

6,600원 · 1개6,600원

케이블 타이 소형 2.5 × 100 mm, 블랙 100개 × 2

납땜 소모품

#### 케이블 타이 소형 2.5 × 100 mm, 블랙 100개

티테크놀로지 T-C2510B

모듈마다 신호선 다발을 묶고 케이스 안에서 허브 케이블을 정리합니다.

세부 스펙

크기 | 2.5 × 100 mm (소)
수량 | 100개
색상 | 블랙
재질 | 나일론 66, UL94 V-2 (포장 라벨 표기)
브랜드 | 티테크놀로지
발송 | 평균 2.5일

이미지는 엘레파츠 T-C2510B 상품페이지가 대표 이미지로 쓰는 사진(컴퓨존 서버)입니다. 대량으로 쓰려면 두 번째 판매처의 1,000개 묶음이 개당 훨씬 쌉니다.

가격 메모: 398.18원(VAT별도) → 438원 / 100개

엘레파츠438원 (https://www.eleparts.co.kr/goods/view?no=9100003)엘레파츠 (SMATO 케이블타이 100 mm 흑색 1,000개)3,010원 (https://www.eleparts.co.kr/goods/view?no=16596284)

438원 · 2개876원

M3 나일론 스탠드오프 키트 (길이 10 mm, 10세트) × 4

납땜 소모품

#### M3 나일론 스탠드오프 키트 (길이 10 mm, 10세트)

DFRobot FIT0066 M3×10 Nylon Standoff Kit

만능기판 모듈을 3D 프린트 케이스나 레일 위에 띄워 고정합니다. 나일론이라 기판 뒷면 납땜부와 단락되지 않습니다.

세부 스펙

나사 규격 | M3
스탠드오프 길이 | 10 mm
구성 | 나일론 기둥 M3×10 ×10, M3×5 나사 ×10, M3 너트 ×10 (DFRobot 구성표)
형태 | 세트당 나사·너트 각 1개 → 한쪽 수나사형(M-F) 기둥으로 추정
재질 | 나일론(비전도)
재고 | 아이씨뱅큐 해외 재고, 1주 이내

대안

- DFRobot FIT0182 M3×20 나일론 스탠드오프 세트 (https://www.icbanq.com/P013130275) · 3,080원 — 보드 아래로 선을 지나가게 높이가 더 필요할 때(2,800원 VAT별도)
- Adafruit 4685 검정 나일론 M3 나사·스탠드오프 세트 (https://www.icbanq.com/P013153342) · 37,070원 — 여러 길이가 들어 있는 큰 키트
- 디바이스마트 PCB 플라스틱 서포트 키트 M3 [NT-KIT-E018] (https://www.devicemart.co.kr/goods/view?no=1323561) — 6/10/15/20 mm 여러 길이 + 볼트·너트. 가격은 차단으로 확인하지 못함

만능기판 모서리에 3.2 mm 구멍을 뚫어야 M3가 들어갑니다. Pico 2 자체의 고정 구멍은 Ø2.1 mm(M2용)지만 Pico는 헤더로 기판에 납땜되므로 따로 고정할 필요가 없습니다.

가격 메모: 2,200원(VAT별도) → 2,420원 / 10세트

아이씨뱅큐2,420원 (https://www.icbanq.com/P013130273)

2,420원 · 4개 · 보드 고정9,680원

#### 선택 · 공구

10P(2×5) IDC 플랫 케이블 + IDC 암 소켓 (선택) 선택

기판/배선

#### 10P(2×5) IDC 플랫 케이블 + IDC 암 소켓 (선택)

EUNSUNG Flat Data Cable 2651-10P (1 m 단위) + Adam Tech FCS-10-SG IDC 소켓

센서 스트립과 모듈 보드 사이의 신호 8가닥 + 전원 2가닥을 한 번에 탈착하는 방법입니다. 16채널이면 모듈당 10P 케이블 2가닥이 필요합니다(선택 사항).

세부 스펙

심수 | 10심 플랫 케이블
도체 간격 | 1.27 mm (2.54 mm 2×5 IDC 소켓용)
규격 | #2651 계열
판매 단위 | 1 m (61 m 이상 750원/m, VAT별도)
소켓 | Adam Tech FCS-10-SG, 2×5 IDC 암, 금도금 접점
소켓 가격 구간 | 1개 765.45원, 10개 646.36원, 25개 605.45원 (VAT별도, 해외 주문품)

대안

- IDC DIP PLUG-10P (보드 쪽에 납땜하는 2×5 수 커넥터) (https://www.devicemart.co.kr/goods/view?no=14693) · 440원 — 만능기판 쪽에 IDC 소켓을 꽂을 자리가 필요할 때(2×5 핀헤더로 대체 가능)
- Flat Cable 10P 1 m (디바이스마트) (https://www.devicemart.co.kr/goods/view?no=4073) · 1,210원 — 케이블만 디바이스마트에서 함께 살 때

IDC 소켓 압착은 바이스나 전용 공구로 평행하게 눌러야 합니다. 조립이 번거로우면 실리콘선 직접 납땜 + JST-XH 커넥터 방식으로 충분합니다. 16핀(2×8) 케이블을 쓰면 모듈당 1가닥으로 16신호를 보낼 수 있지만 전원선은 따로 필요합니다.

가격 메모: 900원(VAT별도) → 990원/m

엘레파츠 (플랫 케이블 10P, 1 m)990원 (https://www.eleparts.co.kr/goods/view?no=424)엘레파츠 (IDC 소켓 FCS-10-SG)711원 (https://www.eleparts.co.kr/goods/view?no=8411888)디바이스마트 (NT-IDC 10핀 케이블 200 mm, 완제품)2,310원 (https://www.devicemart.co.kr/goods/view?no=25429)

990원990원

휴대용 스마트 인두기 Pinecil V2 (USB-C PD, 온도 조절) 선택

공구(선택)

#### 휴대용 스마트 인두기 Pinecil V2 (USB-C PD, 온도 조절)

PINE64 Pinecil V2 (SKU PINECIL-BB2, B2 팁 포함)

온도 조절 인두기가 없다면 가장 싼 선택지입니다. 적정 온도(유연납 약 320–340 °C)를 유지해 센서를 과열시키지 않고 조인트 품질을 일정하게 합니다.

세부 스펙

전원 | USB-C PD/QC 3.0 12–20 V 3 A 또는 DC5525 배럴 12–24 V 3 A
칩셋 | Bouffalo BL-706, 32비트 RISC-V @144 MHz
펌웨어 | IronOS (오픈소스)
디스플레이 | 0.69인치 OLED 96×16
길이 | 155 mm (팁 포함) / 103 mm (팁 제외)
팁 | B2 (길이 86 mm, 8.2 g)
구성 | 본체 + ST(Short Tip)-B2 팁
보증 | 30일

대안

- HAKKO FX-888D 스테이션형 디지털 인두기 (70 W, 200–480 °C) (https://sungdotool.cafe24.com/product/hakko-%EB%82%A9%EB%95%9C%EC%9D%B8%EB%91%90-fx-888d/1108/) · 242,000원 — 책상에서 오래 쓸 표준 스테이션
- SparkFun 판 Pinecil (TOL-23913, 디바이스마트 Mouser 리셀러) (https://www.devicemart.co.kr/goods/view?no=15482740) · 141,394원 — 국내 결제가 편하지만 가격이 4배 가까이 비쌈

Pinecil은 전원을 따로 공급해야 합니다: 20 V 3 A(60 W 이상) USB-C PD 충전기 + C-C 케이블(별도). 5 V 충전기로는 제대로 가열되지 않습니다. 해외 직구 배송비는 결제 시 확인하세요.

가격 메모: 커뮤니티 가격 US$25.99(정가 US$35.99) → 약 35,220원, 배송비 별도, 페이지에 재고 있음 표시. 환율 1 USD = 1,355 KRW (open.er-api.com 2026-09-23 1,353.7 / fawazahmed0 currency-api 2026-09-22 1,358.4 평균, 반올림)

PINE64 공식 스토어 (해외 직구)35,220원 (https://pine64.com/product/pinecil-smart-mini-portable-soldering-iron/)

35,220원35,220원

전자선 와이어 스트리퍼 AWG 30–20 (0.2–0.8 mm) 선택

공구(선택)

#### 전자선 와이어 스트리퍼 AWG 30–20 (0.2–0.8 mm)

Pro'sKit 8PK-3001D

26/28AWG 실리콘선 피복을 심선 손상 없이 일정한 길이로 벗깁니다. 신호선 100가닥 이상을 다듬어야 해서 있으면 작업 시간이 크게 줄어듭니다.

세부 스펙

적용 선경 | AWG 30, 28, 26, 24, 22, 20 / 0.2–0.8 mm
날 재질 | SK7 공구강, 고주파 열처리
경도 | HRC 50 ± 3
전장 | 156 mm
손잡이 | PVC, 스프링, 잠금 고리
기능 | 탈피·절단·집기

대안

- HOZAN 와이어 스트리퍼 P-967 (https://kj-mall.com/product/detail.html?product_no=34124) · 63,800원 — 일본산 고급형(적용 선경은 제조사 사양 확인 필요)

실리콘 피복은 부드러워 한 치수 작은 구멍에서 끊어지기 쉽습니다. 26AWG 선은 26 구멍에서 먼저 시험해 보세요.

가격 메모: 즉시할인가 13,090원(상품가 11,900 + VAT 1,190). 배송비 3,300원(15만원 이상 무료)

KJ-MALL13,090원 (https://kj-mall.com/product/detail.html?product_no=28255)

13,090원13,090원

소형 단자 압착기 AWG 18–28 (JST-XH·듀폰·몰렉스 오픈배럴 단자용) 선택

공구(선택)

#### 소형 단자 압착기 AWG 18–28 (JST-XH·듀폰·몰렉스 오픈배럴 단자용)

IWISS SN-28B (라쳇식)

JST-XH 크림프 단자와 듀폰 단자를 26/28AWG 선에 압착합니다. JST 커넥터를 쓰기로 했다면 사실상 필수입니다.

세부 스펙

적용 선경 | 0.1–1.0 mm², AWG 28–18 (IWISS 공식 페이지)
대상 단자 | 2.5 / 2.54 / 3.96 mm 피치 비절연 오픈배럴 — JST XH·VH·NH, 듀폰 2.54 mm
XH 적용 표 | XH 2.5 mm 피치 AWG 30–20 (제조사 표기)
구조 | 라쳇식, 20° 경사 헤드, 자동 해제 잠금, 출고 시 보정(장력 조절 가능)
무게 | 0.71 lb (약 320 g)
브랜드 | IWISS
발송 | 평균 1.5일

대안

- ENGINEER PA-09 마이크로 압착기 (AWG32–20, 1.25–2.5 mm 피치 커넥터) (https://www.eleparts.co.kr/goods/view?no=3851994) · 71,060원 — 일본산, 더 가는 선과 정밀 압착(64,600원 VAT별도)

처음 몇 개는 버리는 셈 치고 연습하세요. 심선 쪽과 피복 쪽 날개를 각각 맞는 구멍에서 두 번 누르는 방식이 확실합니다.

가격 메모: 31,900원(VAT별도) → 35,090원

엘레파츠35,090원 (https://www.eleparts.co.kr/goods/view?no=16016624)

35,090원35,090원

포켓형 디지털 멀티미터 (4000 카운트, AC/DC 전압·mA 전류, 저항, 도통, 정전용량) 선택

공구(선택)

#### 포켓형 디지털 멀티미터 (4000 카운트, AC/DC 전압·mA 전류, 저항, 도통, 정전용량)

동화전자 DM-300A

3.3 V 버스 전압, 센서 출력(자석을 댔을 때 1.65 V에서 변하는지), 배선 단락과 끊김을 확인합니다.

세부 스펙

표시 | 4000 카운트 (제품 전면 표기; 목록 제목은 3200카운트로 적혀 있어 불일치)
전압 | AC/DC V
전류 | AC/DC mA
기타 측정 | 저항, 다이오드/도통 부저, 정전용량(CAP), 주파수·듀티(Hz)
편의 기능 | 상대값(REL), 자동 전원 차단, 테스트 리드 일체형 케이스 (제품 사진 기준)
형태 | 포켓형
제조사 | 동화전자(DONG HWA)
발송 | 24시간 이내

대안

- 태광 TK-3204 디지털 멀티미터 (3200 카운트, 바그래프) (https://www.eleparts.co.kr/goods/view?no=451) · 44,000원 — 화면이 크고 바그래프가 있어 센서 출력 변화를 보기 쉬움(40,000원 VAT별도)
- UNI-T UT33A+ (디바이스마트) (https://www.devicemart.co.kr/goods/view?no=6500232) — 많이 쓰이는 보급형. 가격은 디바이스마트 차단으로 확인하지 못함

도통 부저가 있으면 수십 가닥 신호선 점검이 빨라집니다. 전류는 mA 레인지만 있어 큰 전류 측정에는 맞지 않지만, 이 프로젝트(모듈당 수십 mA)에는 충분합니다.

가격 메모: 17,000원(VAT별도) → 18,700원

엘레파츠18,700원 (https://www.eleparts.co.kr/goods/view?no=2080)

18,700원18,700원

## 소리 · 프로그램 + 앰프 + 스피커

R12–R16과 D6–D17을 기준으로 세 가지 구성을 비교했습니다. 권장안(T-B)은 Pi DAC+의 라인 출력을 DSP 2.1 앰프 보드에 넣어 100 Hz에서 위성과 서브를 나눕니다. 위성 DMA105-4는 4.7 L 밀폐함에서 100 Hz 아래 약 2.6 W만 넘어도 최대 진폭에 닿기 때문에, 직렬 콘덴서 없이(D13) 저음을 잘라 주려면 DSP가 필요합니다.

D16이 바뀝니다. 권장안의 HAT(DAC+)은 Pi에 전원을 넣지 않습니다. Pi는 공식 27 W USB-C 어댑터 한 곳으로만 급전하고, 앰프는 24 V 어댑터를 따로 씁니다. “앰프 HAT이 Pi를 급전”하는 원래 구성을 지키려면 T-A(HiFiBerry Amp4 Pro)를 고르세요.

### S-1구성 후보

#### 앰프 HAT 유지형: Amp4 Pro + 스피커레벨 서브 + USB 헤드폰

Pi 5 위에 HiFiBerry Amp4 Pro(TAS5756M, 20V 브릭, Pi에 5V 최대 5A 급전)가 DMA105 두 개를 풀레인지로 직접 구동. 서브는 Amp4 Pro 스피커 출력→LOC(차동 입력)+LPF→Wondom AA-AB31184→RSS210HF-4. 헤드폰은 USB DAC→전면 NMJ6HCD2; 잭 SN→Pi GPIO→스크립트가 Amp4 Pro 뮤트(GPIO4, mute_ext_ctl)와 서브앰프 MUTE를 걸고 엔진을 USB 장치로 재시작.

장점

- '앰프 HAT이 Pi 급전' 구조와 D16을 그대로 유지(5A라 Pico 8개 USB 여유)
- 위성 경로가 I2S→TAS5756M 순수 디지털
- 서브 음량이 마스터 볼륨을 자동으로 따라감
- 부품 수 적음

단점

- 위성에 HPF를 넣을 방법이 없음(D13으로 직렬 콘덴서 금지) → DMA105는 100Hz 이하 성분 약 2.6W(3.2Vrms)에서 Xmax 도달, ff 저음 화음+페달에서 찌그러짐 위험(R16)
- 헤드폰 차단이 소프트웨어 의존(데몬이 죽으면 R15 실패) + 엔진 재시작 1~3초 공백
- I2S DAC와 USB DAC 두 장치 → D10 전환 로직 복잡
- LOC·LPF 품질·가격 미확인
- Amp4 Pro 국내 판매처 없음(직구)

요구사항: 지킴: R12(위성), R13, R14(음량은 2×18W@18V 수준), D7, D13, D16. 약함/굽힘: R15(소프트웨어로만), R16(위성 과진폭 위험), D10(헤드폰 전환 시 장치 교체).

1,130,660원 (부품 + Pianoteq Stage, 가격 미확인: 스피커레벨→라인레벨 변환기(LOC) + 서브 LPF)

#### DAC HAT(라인+헤드폰) + DSP 2.1 앰프보드 (추천)

권장

Pi 5 + Raspberry Pi DAC+(PCM5122)의 RCA 라인아웃을 Dayton KABD-430 AUX 입력에 연결. ADAU1701에서 100Hz LR4 크로스오버(위성 HPF, 서브 LPF)+EQ+리미터 → 2×30W로 DMA105-4 두 개, PBTL 60W로 RSS210HF-4(밀폐 15~18L). 헤드폰은 DAC+ 헤드폰 앰프 → 전면 NMJ6HCD2(6.35mm). 잭 슬리브 스위치(S–SN, 플러그 없을 때 닫힘)→PC817 포토커플러→KABD MP 핀 → DSP가 스피커 출력만 소프트 뮤트(팝 없음), 같은 신호를 Pi GPIO로도 읽음. 전원: GST120A24-P1M(24V 5A)→KABD-430, Pi는 공식 27W USB-C(또는 단일 브릭 원하면 Pololu D36V50F5로 GPIO 5V 급전 — 둘 중 하나만).

장점

- R15가 순수 하드웨어 경로(Pi 소프트웨어가 멈춰도 헤드폰을 꽂으면 스피커가 꺼짐)
- DAC 하나의 클럭에서 위성·서브·헤드폰이 모두 나옴 — 엔진은 hw:DAC+ 한 곳만 씀(D7·D10 단순)
- DSP HPF로 DMA105 과진폭 제거 → 위성이 30W까지 깨끗(R16), 스피커 직렬 콘덴서 없음(D13)
- 서브 60W ≈ RSS210HF-4 15L Xmax 한계(~77W)의 −1dB → 과진폭 보호와 출력이 균형
- KABD-430은 팬 없음
- DAC+ 30,360원·27W 전원 18,040원 등 핵심 부품 국내 재고

단점

- '앰프 HAT이 Pi 급전' 전제가 바뀜 → Pi 전원 별도(브릭 2개) 또는 벅 모듈
- ADAU1701 프로그래밍 1회 필요(Windows + SigmaStudio + KPX $37.98)
- DAC→아날로그→ADAU1701 ADC 재변환 한 단계(ADAU1701 ADC 성능이 상한)
- KABD-430·RSS210HF-4 PE 직구(국내 공식가는 비쌈)
- KABD AUX 입력 감도·DC잭 규격을 매뉴얼에서 확인 못 함
- DAC+도 PCM512x 계열 → D11 대비 동일

요구사항: 지킴: R12·R13·R14·R15(하드웨어)·R16(크로스오버로 개선), D7(hw:DAC+ 직결), D9, D13(디지털 필터라 임피던스 공진 없음), D14·D15·D17(배치/기구로 대응). 바뀜: D16 — HAT이 Pi를 급전하지 않으므로 '공식 27W USB-C 한 곳으로만 급전'으로 대체(PD 5A 협상이라 PSU_MAX_CURRENT 설정 불필요). 벅→GPIO 옵션을 고르면 D16 원문 그대로(USB-C 동시 급전 금지, EEPROM 설정 필요).

1,177,460원 (부품 + Pianoteq Stage)

#### DAC8x 8채널 + CamillaDSP 소프트 크로스오버

Pi 5 + HiFiBerry DAC8x. 엔진→ALSA loopback→CamillaDSP(LR4 크로스오버, EQ, 리미터, 헤드폰 채널 분리)→DAC8x ch1/2→Wondom AA-AB32178→DMA105, ch3→AA-AB31184→서브, ch5/6→헤드폰 앰프 모듈→전면 잭. 잭 SN→Pi GPIO→CamillaDSP가 스피커 채널 뮤트(또는 앰프 MUTE 핀 직결).

장점

- 가장 유연: 채널별 EQ·딜레이·리미터·Linkwitz Transform을 Pi 안에서 조정(Windows 불필요)
- DAC 하나의 클럭
- DAC8x 수치(SNR 112dB) 우수

단점

- D7 위배: 엔진과 hw: 사이에 loopback+CamillaDSP 층 추가, 지연 증가로 D8(10ms) 여유 감소
- 소프트웨어 장애 시 무음/폭음 위험, R15도 소프트웨어 의존
- 앰프 2장 + 헤드폰 앰프 모듈(판매처 미확인) → 배선 많음
- HAT 급전 없음, DAC8x 국내 판매처 없음

요구사항: 지킴: R12·R13·R14·R16, D9, D13. 굽힘: D7(중간 DSP 층), D8(지연 여유), R15(소프트웨어), D16(별도 전원으로 대체).

1,153,040원 (부품 + Pianoteq Stage, 가격 미확인: 헤드폰 앰프 모듈 (TPA6120/NJM4556 계열))

### S-2스피커 상자 계산

0.71위성 Qtc

≈101 Hz위성 F3 (4.7 L)

≈2.6 W위성 Xmax 한계 (<100 Hz)

0.92서브 Qtc (15 L)

≈39 Hz서브 F3

≈77 W서브 Xmax 한계

위성 DMA105-4 · 밀폐 4.7 L 계산 과정

Dayton DMA105-4 제조사 스펙시트(Parts Express 295-590) 값: Fs=72.7Hz, Qts=0.51, Vas=4.35L, Re=3.4Ω, Bl=3.4Tm, Cms=1.06mm/N, Sd=54.1cm², Xmax=2.5mm. 밀폐함 공식: α=Vas/Vb, Qtc=Qts·√(1+α), Fc=Fs·√(1+α), F3=Fc·√{[(1/Qtc²−2)+√((1/Qtc²−2)²+4)]/2}. Vb=4.7L → α=4.35/4.7=0.926, √(1+α)=1.3876, Qtc=0.51×1.3876=0.708, Fc=72.7×1.3876=100.9Hz, 1/Qtc²−2=-0.0033 → F3≈100.8Hz (Qtc≈0.707이라 F3≈Fc). 흡음재(폴리필)로 실효 부피가 약 15% 늘면(5.4L) Qtc=0.685, F3≈100.9Hz — 거의 같음. PE 권장(0.1ft³=2.8L, F3 113Hz)보다 조금 크게 잡은 값으로 적절. 진폭 한계 계산(Fc 아래 정적 근사): 서스펜션 강성 1/Cms=943N/m + 공기 강성 ρc²Sd²/Vb=1.2×343²×(54.1e-4)²/0.0047=879N/m → 합 1,823N/m. x=Bl·V/(Re·k)에서 x=2.5mm가 되는 전압 V=2.5e-3×3.4×1823/3.4=4.56Vpk=3.22Vrms → 4Ω 기준 약 2.6W. 즉 100Hz 이하 성분이 2.6W만 넘어도 Xmax에 닿는다. Xmax 한계 음압(1개, 반공간 1m): 50Hz 79dB, 80Hz 87dB, 100Hz 91dB, 150Hz 98dB. 결론: 위성은 ~100Hz 이하를 서브에 넘겨야(능동 HPF, 예: LR4 100Hz) R16(찌그러짐 0)을 지킬 수 있고, D13 때문에 스피커 직렬 콘덴서가 아니라 라인레벨/DSP에서 잘라야 한다.

서브우퍼 RSS210HF-4 계산 과정과 다른 후보

같은 밀폐함 공식(α=Vas/Vb, Qtc=Qts√(1+α), Fc=Fs√(1+α), F3 식은 위성과 동일)과 제조사 스펙시트 T/S값으로 계산. 추천 RSS210HF-4(Fs 29.6Hz, Qts 0.57, Vas 23.7L)를 15L에 넣으면 α=23.7/15=1.58, √2.58=1.606 → Qtc=0.57×1.606=0.92, Fc=29.6×1.606=47.5Hz, F3≈39Hz. 18~20L로 키우거나 폴리필을 채우면 Qtc 0.84~0.88로 내려가 저음 봉우리가 줄어든다(권장 순부피 15~18L + 폴리필). Xmax(9mm)에 닿는 전압은 강성 합(1/Cms 2,703N/m + 공기 4,514N/m @15L)으로 약 17.5Vrms ≈ 77W@4Ω → KABD-430 PBTL 60W는 Xmax 한계보다 약 1dB 낮은 수준에서 클리핑하므로 드라이버 보호와 출력이 잘 맞는다. 후보 비교 — RSS210HF-4: 12L: Qtc 0.98, Fc 51Hz, F3 40Hz, Xmax 전압 20Vrms(≈103W@4Ω) / 15L: Qtc 0.92, Fc 48Hz, F3 39Hz, Xmax 전압 18Vrms(≈77W@4Ω) / 20L: Qtc 0.84, Fc 44Hz, F3 38Hz, Xmax 전압 15Vrms(≈55W@4Ω); Xmax 한계 음압(반공간 1m) 30Hz 93dB, 40Hz 98dB | DCS205-4: 12L: Qtc 0.67, Fc 58Hz, F3 62Hz, Xmax 전압 18Vrms(≈77W@4Ω) / 15L: Qtc 0.62, Fc 54Hz, F3 63Hz, Xmax 전압 15Vrms(≈57W@4Ω) / 20L: Qtc 0.57, Fc 50Hz, F3 65Hz, Xmax 전압 13Vrms(≈40W@4Ω); Xmax 한계 음압(반공간 1m) 30Hz 93dB, 40Hz 98dB | LS10-44(직렬 8Ω): 12L: Qtc 0.81, Fc 65Hz, F3 57Hz, Xmax 전압 55Vrms(≈747W@4Ω) / 15L: Qtc 0.75, Fc 60Hz, F3 57Hz, Xmax 전압 47Vrms(≈548W@4Ω) / 20L: Qtc 0.69, Fc 55Hz, F3 56Hz, Xmax 전압 39Vrms(≈380W@4Ω); Xmax 한계 음압(반공간 1m) 30Hz 99dB, 40Hz 104dB | W6-1139SIF: 12L: Qtc 0.56, Fc 49Hz, F3 65Hz, Xmax 전압 14Vrms(≈47W@4Ω) / 15L: Qtc 0.53, Fc 47Hz, F3 66Hz, Xmax 전압 12Vrms(≈37W@4Ω) / 20L: Qtc 0.50, Fc 44Hz, F3 68Hz, Xmax 전압 11Vrms(≈28W@4Ω); Xmax 한계 음압(반공간 1m) 30Hz 92dB, 40Hz 97dB | DCS165-4: 12L: Qtc 0.48, Fc 51Hz, F3 83Hz, Xmax 전압 6Vrms(≈9W@4Ω) / 15L: Qtc 0.46, Fc 48Hz, F3 85Hz, Xmax 전압 5Vrms(≈7W@4Ω) / 20L: Qtc 0.43, Fc 45Hz, F3 87Hz, Xmax 전압 5Vrms(≈6W@4Ω); Xmax 한계 음압(반공간 1m) 30Hz 85dB, 40Hz 90dB. 해석: Qts가 낮은 DCS205-4·W6-1139SIF·DCS165-4는 밀폐 10~20L에서 F3가 60~85Hz로 올라가 30~100Hz 채우기(R 기준선)에 불리(이들은 베이스리플렉스용). LS10-44는 깊이 84mm(얇음)가 장점이지만 F3≈57Hz, 스택 강성이 커서 Xmax까지 수백 W가 필요. Parts Express 직원 권장값도 RSS210HF-4 밀폐 0.9ft³(25.5L)→F3 41Hz, LS10-44 0.62ft³→73Hz, DCS205-4 0.28ft³→68Hz로 같은 경향. 주의: RSS210HF-4 장착 깊이 4.88in(124mm) → 하향 발사 상자로 눕혀도 외부 높이 약 16~17cm 필요. 키베드 아래 공간이 그보다 낮으면 LS10-44(깊이 3.32in=84mm)+DSP 저역 보정이 차선.

서브 상자는 권장 순부피 15–18 L + 흡음재. 드라이버 깊이가 124 mm라 상자 높이는 약 165 mm입니다. 케이스 아래에 공간이 모자라면 LS10-44(깊이 84 mm, F3 ≈57 Hz)로 바꿉니다.

### S-3권장 구성 부품

라즈베리파이 5 (4GB) × 1

compute

#### 라즈베리파이 5 (4GB)

Raspberry Pi 5 Model B 4GB

음원 엔진(Pianoteq/FluidSynth/sfizz) 실행, USB-MIDI 8개 입력 병합, ALSA hw: 출력

세부 스펙

CPU | Broadcom BCM2712 2.4GHz 쿼드코어 Cortex-A76 64bit
RAM | 4GB LPDDR4X
전원 | USB-C 5V/5A 권장 (27W PD)
GPIO | 40핀 (HAT 호환)
확장 | PCIe 2.0 x1
저장 | microSD (SDR104)
기타 | RTC·전원버튼 내장, 듀얼 4Kp60
KC | R-R-P2R-RP5

대안

- Raspberry Pi 5 8GB (https://www.icbanq.com/P015956550) · 322,300원 — RAM 여유가 필요할 때(대용량 샘플 전체 로딩 등). Pianoteq·sfizz 스트리밍엔 4GB로 충분해 추천 안 함. 4GB 대비 +104,500원
- Raspberry Pi 5 8GB (디바이스마트) (https://www.devicemart.co.kr/goods/view?no=15215449) · 322,300원 — 같은 가격, 확인 시점 재고확보 중

권장 4GB. 8GB는 두 쇼핑몰 모두 322,300원(VAT 포함)으로 4GB보다 약 10만원 비싸다(2025-12 이후 메모리발 가격 인상 반영가로 보임). 엘레파츠 4GB는 184,000원(VAT 별도, 8GB 상품 페이지의 관련상품 표)이었으나 '재고확보중'.

가격 메모: VAT 포함(198,000원+VAT), 국내 재고·당일 출고 표시

아이씨뱅큐217,800원 (https://www.icbanq.com/P015956549)디바이스마트204,600원 (https://www.devicemart.co.kr/goods/view?no=15215450)

217,800원 · 1개217,800원

라즈베리파이 5 공식 액티브 쿨러 × 1

compute

#### 라즈베리파이 5 공식 액티브 쿨러

Raspberry Pi Active Cooler (SC1148)

Pi 5 발열 관리(스로틀링 방지). 온도 제어 팬이라 조용할 때는 거의 안 돔

세부 스펙

구성 | 알루미늄 방열판 + 온도 제어 블로어 팬
전원 | 5V DC (Pi 5 전용 4핀 팬 커넥터)
최대 풍량 | 1.09 CFM (판매처 요약)
최대 회전수 | 8,000 RPM (판매처 요약)
고정 | 스프링 핀 2개(Pi 5 전용 구멍)
호환 | Raspberry Pi 5 전용

대안

- Adafruit 판매 공식 쿨러(아이씨뱅큐) (https://www.icbanq.com/P016021437) · 18,700원 — 같은 제품, 더 비쌈

앰프 HAT/DAC HAT을 올리면 쿨러 높이와 GPIO 스페이서 높이가 겹치지 않는지 확인(HAT용 16~18mm 스택 헤더 필요할 수 있음). 팬 소음은 키베드에서 떨어뜨려 두면 문제 없음.

가격 메모: VAT 포함(7,000원+VAT), 확인 시점 장바구니 가능

디바이스마트7,700원 (https://www.devicemart.co.kr/goods/view?no=15276241)엘레파츠7,700원 (https://eleparts.co.kr/goods/view?no=13323153)

7,700원 · 1개7,700원

microSD 64GB (A2) × 1

compute

#### microSD 64GB (A2)

SanDisk Extreme microSDXC 64GB SDSQXAH-064G-GN6MN

OS·엔진·샘플 저장. A2 랜덤 성능이 샘플 스트리밍에 유리

세부 스펙

용량 | 64GB
규격 | microSDXC UHS-I U3 V30 A2 (SanDisk Extreme 제품군 표기, 데이터시트 재확인 안 함)
제품 코드 | SDSQXAH-064G-GN6MN
용도 적합 | Pi 5 SDR104 모드
가격 비교 | 공식 RPi A2 64GB(39,600원)보다 저렴

대안

- 라즈베리파이 공식 A2 microSD 64GB (https://www.devicemart.co.kr/goods/view?no=15549242) · 39,600원 — Pi 5 SDR104 검증품이지만 확인 시점 재고확보 중

읽기 속도 수치는 제품군 표기로, 이번에 제조사 데이터시트로 재확인하지 않음. Samsung PRO Plus 64GB는 디바이스마트 검색에서 64GB가 나오지 않아(128GB만 73,700원) 제외.

가격 메모: VAT 포함(30,500원+VAT), 확인 시점 장바구니 가능

디바이스마트33,550원 (https://www.devicemart.co.kr/goods/view?no=14825254)

33,550원 · 1개33,550원

Raspberry Pi DAC+ (추천안의 HAT) × 1

dac

#### Raspberry Pi DAC+ (추천안의 HAT)

Raspberry Pi DAC+ (구 IQaudio DAC+, SC0368)

T-B의 유일한 DAC: RCA 라인아웃→2.1 DSP 앰프, 헤드폰 앰프 출력→전면 잭. 한 클럭에서 스피커·서브·헤드폰이 모두 나온다

세부 스펙

DAC | TI PCM5122, 24bit/192kHz
라인 출력 | RCA 스테레오, 0–2V RMS
헤드폰 | 전용 헤드폰 앰프, 3.5mm 패널 잭 (80/90Ω 헤드폰까지 구동, 공식 문서)
전원 | Pi GPIO에서 공급(외부 전원 불필요), Pi에 급전하지 않음
오버레이 | dtoverlay=rpi-dacplus
GPIO 사용 | I2C(2/3), I2S(18–21)
생산 보장 | 2028년 1월까지

대안

- Raspberry Pi DAC Pro (PCM5242, RCA+밸런스 P7+헤드폰 앰프) (https://www.devicemart.co.kr/goods/view?no=13237161) · 37,950원 — 더 좋은 DAC·밸런스 출력, 8천원 차이
- HiFiBerry DAC8x (8채널, Pi 5 전용) (https://www.hifiberry.com/shop/boards/hifiberry-dac8x/) · 87,860원 — T-C용(소프트 크로스오버)

PCM5122는 D11(#7320, PCM512x 계열 Pi 5 I2S DMA 버그) 대상이므로 hw: 직결·스트림 상시 유지·장시간 테스트를 그대로 적용. 헤드폰 잭이 기판 위 3.5mm라서 전면 6.35mm 잭까지 3.5mm 플러그 케이블로 연장한다.

가격 메모: VAT 포함(29,000원−기본할인 1,400원=27,600원+VAT), 확인 시점 장바구니 가능

디바이스마트30,360원 (https://www.devicemart.co.kr/goods/view?no=13237160)

30,360원 · 1개30,360원

2.1 DSP 앰프보드 Dayton KABD-430 (추천안) × 1

amp

#### 2.1 DSP 앰프보드 Dayton KABD-430 (추천안)

Dayton Audio KABD-430 (PE 325-430)

T-B의 파워앰프 겸 크로스오버: 위성 2×30W + 서브 1×60W(PBTL), ADAU1701에서 HPF/LPF/EQ/리미터/뮤트

세부 스펙

앰프 칩 | TI TPA3118 ×2
구성 | 4×30W / 2×30W+1×60W(2.1) / 2×60W
최소 부하 | 4Ω (스테레오·모노 모두)
전원 | 12–26V DC 센터 +, 1A 이상 (하네스+DC잭 포함)
DSP | ADI ADAU1701 (SigmaStudio, KPX/ICP1 프로그래머 필요)
입력 | 3.5mm 라인 AUX(J5), Bluetooth 5.0 aptX HD
제어 핀 | J11 대기(standby) 스위치 포트, POT1–4(MP 핀: 스위치/가변저항 입력)
냉각 | 팬 없음(KABD-4100은 팬 장착)
보증 | Dayton 5년

대안

- Dayton KABD-4100 (4×100W, 2.1 모드 2×100+1×200W, TDA749x) (https://www.parts-express.com/Dayton-Audio-KABD-4100-4-x-100W-Bluetooth-Amp-Board-with-DSP-325-434) · 129,930원 — 출력 여유 크지만 냉각팬이 달려 있고(조용한 피아노에 불리) 5분 무신호 시 저전력 대기로 들어간다는 매뉴얼 문구가 있음. 10–39V
- Dayton KABD-250 (2×50W TPA3116, DSP) (https://www.parts-express.com/Dayton-Audio-KABD-250-2-x-50W-DSP-Amplifier-Board-aptX-HD-Bluetooth-5.0-325-107) · 86,610원 — 위성만 구동하고 AUX 라인출력으로 별도 서브앰프를 붙이는 방식. 보드 2장 필요

30W/ch는 DMA105-4(35W RMS)와 딱 맞고, 60W PBTL은 RSS210HF-4 15L의 Xmax 한계(≈77W)보다 약 1dB 낮아 과진폭 보호 효과가 있다. 국내 판매처는 확인하지 못함(다안일렉트론 검색 'KABD' 결과 없음). 매뉴얼상 AUX 입력 감도·DC잭 규격 수치는 확인 못 함 → DAC+ 볼륨을 D9 기준(−3~−6dBFS)에서 맞춰 클립 LED/측정으로 확인. KABD-430 매뉴얼에는 자동 대기 문구가 없었다.

가격 메모: $69.98 × 1353.7원(정가 $116.99에서 할인), 해외배송·관부가세 별도, 확인 시 재고 있음

Parts Express (미국)94,730원 (https://www.parts-express.com/Dayton-Audio-KABD-430-4-x-30W-Bluetooth-Amp-Board-with-DSP-325-430)

94,730원 · 1개94,730원

DSP 프로그래머 Dayton KPX × 1

amp

#### DSP 프로그래머 Dayton KPX

Dayton Audio KPX In-Circuit Programmer USB (PE 325-139)

KABD-430의 ADAU1701에 SigmaStudio 크로스오버 프로그램을 한 번 굽는 용도(이후 분리)

세부 스펙

인터페이스 | USB (USBi 호환)
대상 | KABD 시리즈 ADAU1701
소프트웨어 | Analog Devices SigmaStudio (무료, Windows)
사용 | EEPROM에 저장 후 제거 가능
대안 | Wondom/Dayton ICP1

대안

- WONDOM ICP1 In-Circuit Programmer for ADAU1701 (https://store.sure-electronics.com/product/AA-AB32178) · 24,240원 — KABD 매뉴얼이 ICP1도 호환으로 명시, 더 저렴

Windows PC가 한 번은 필요. KABD 예제 프로젝트 'Simple 2.1 Project.dspproj'에서 시작해 100Hz LR4 크로스오버, 위성 리미터(30W), 서브 리미터, MP 핀 뮤트를 추가하면 된다. ICP1 가격은 Wondom 스토어의 AA-AB32178 페이지 '함께 구매' 목록에서 확인($17.91 할인가).

가격 메모: $37.98 × 1353.7원 (PE 검색 결과 가격), 배송비 별도

Parts Express (미국)51,410원 (https://www.parts-express.com/Dayton-Audio-KPX-In-Circuit-Programmer-USB-325-139)

51,410원 · 1개51,410원

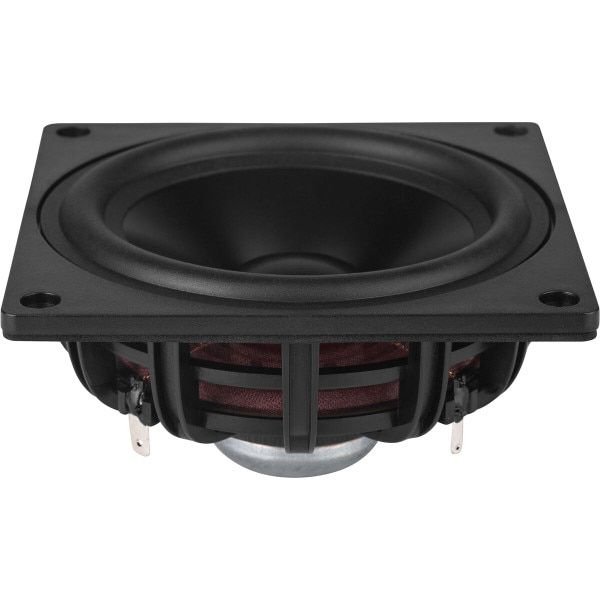
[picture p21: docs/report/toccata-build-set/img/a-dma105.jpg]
위성 스피커 유닛 Dayton DMA105-4
 × 2

speaker

#### 위성 스피커 유닛 Dayton DMA105-4

Dayton Audio DMA105-4 (PE 295-590)

본체 내장 위성 2개(밀폐 4.7L), 100Hz 이상 담당

세부 스펙

구경 | 4" (알루미늄 콘, 듀얼 네오디뮴)
임피던스/Re | 4Ω / 3.4Ω
Fs/Qts | 72.7Hz / 0.51 (Qms 2.6, Qes 0.63)
Vas | 4.35L (PE 표 0.15ft³)
Xmax/Sd/Vd | 2.5mm / 54.1cm² / 13.5cm³
Bl/Mms/Le | 3.4Tm / 4.5g / 0.3mH
감도 | 89.8dB @2.83V/1m
허용입력 | 35W RMS / 70W max
재생대역 | 70–20,000Hz
치수 | 외형 4.1"×4.1"(104mm), 컷아웃 3.875"(98.4mm), 깊이 1.86"(47.2mm), 고정홀 4개

대안

- Dayton DMA105-8 (8Ω) (https://www.daankorea.co.kr/goods/goods_view.php?goodsNo=1000000042) · 50,720원 — 같은 유닛 8Ω판, 같은 가격(다안). 4Ω 앰프 전류 여유가 부족할 때

국내 공식가가 미국가의 약 1.9배. 서브 드라이버·앰프를 PE에서 함께 살 경우 같이 주문하면 배송비를 나눌 수 있다. 밀폐 4.7L 계산은 dma105_box_calc_ko 참고.

가격 메모: 개당 50,720원, 5만원 이상 무료배송 → 2개 101,440원

다안일렉트론(데이톤 한국공식대리점)50,720원 (https://www.daankorea.co.kr/goods/goods_view.php?goodsNo=1000000041)Parts Express (미국)27,050원 (https://www.parts-express.com/Dayton-Audio-DMA105-4-4-Dual-Magnet-Aluminum-Cone-Full-Range-Driver-4-Ohm-295-590)

50,720원 · 2개101,440원

서브우퍼 유닛 Dayton RSS210HF-4 (추천) × 1

speaker

#### 서브우퍼 유닛 Dayton RSS210HF-4 (추천)

Dayton Audio RSS210HF-4 8" Reference HF (PE 295-456)

30~100Hz 채움. 밀폐 15~18L에서 F3≈38~39Hz

세부 스펙

구경 | 8" 알루미늄 콘, 트리플 쇼팅링
임피던스/Re | 4Ω / 3.1Ω
Fs/Qts | 29.6Hz / 0.57 (Qms 3.25, Qes 0.69)
Vas | 23.7L
Xmax/Sd/Vd | 9.0mm / 219cm² / 197cm³
Bl/Mms/Le | 8.12Tm / 78.4g / 0.7mH
감도 | 85.6dB @2.83V/1m
허용입력 | 280W RMS
치수 | 외경 8.39", 컷아웃 7.28"(185mm), 깊이 4.88"(124mm), 고정홀 6개
PE 권장 | 밀폐 0.9ft³(25.5L) F3 41Hz / 벤트 1.25ft³ F3 23Hz

대안

- Dayton LS10-44 10" 로우프로파일 (듀얼 4Ω) (https://www.daankorea.co.kr/goods/goods_view.php?goodsNo=1000000071) · 266,700원 — 깊이 3.32"(84mm)로 키베드 아래 설치가 쉬움. 대신 밀폐 15~20L F3≈57Hz, Xmax까지 큰 전력 필요 → DSP 저역 보정 전제
- Dayton DCS205-4 8" Classic (https://www.daankorea.co.kr/goods/goods_view.php?goodsNo=1000000035) · 167,980원 — 싸지만 Qts 0.37이라 밀폐 15L F3≈63Hz(벤트용)
- Tang Band W6-1139SIF 6.5" (https://www.parts-express.com/Tang-Band-W6-1139SIF-6-1-2-Paper-Cone-Subwoofer-Speaker-264-919) · 125,470원 — 작지만 밀폐 F3≈64Hz, 감도 83dB, 깊이 4.33"

Qts 0.57로 작은 밀폐함에 맞는 몇 안 되는 8인치. 필요한 앰프: 4Ω에 60~100W(Xmax 도달 약 77W@15L) → KABD-430 PBTL 60W가 적합. D14: 서브는 홀센서 열에서 15cm 이상, D15: 고무 절연 필수(무거운 자석).

가격 메모: 무료배송 조건(5만원 이상)

다안일렉트론(데이톤 한국공식대리점)271,800원 (https://www.daankorea.co.kr/goods/goods_view.php?goodsNo=1000000143)Parts Express (미국)196,260원 (https://www.parts-express.com/Dayton-Audio-RSS210HF-4-8-Reference-Series-HF-Subwoofer-4-Ohm-295-456)

271,800원 · 1개271,800원

전면 헤드폰 잭 Neutrik NMJ6HCD2 (6.35mm 스위치드) × 1

io

#### 전면 헤드폰 잭 Neutrik NMJ6HCD2 (6.35mm 스위치드)

Neutrik NMJ6HCD2

R15 헤드폰 자동 차단의 감지 스위치. 슬리브 스위치(S–SN)가 플러그 없을 때 닫힘 → 꽂으면 열림

세부 스펙

형식 | 1/4"(6.35mm) 스테레오 잭, 스위치드, 크롬 페룰, 수평 PCB 핀
스위칭 접점 | 3개(T–TN, R–RN, S–SN; Neutrik 회로도 '3x switching')
접점 정격 | 신호 3A / 스위치 0.5A @50V
접촉저항 | <15mΩ(신호)/<30mΩ
패널 두께 | <4.7mm
수명 | >10,000회
표준 | EIA RS-453, IEC 60603-11

대안

- NMJ6HCD2 (다른 공급 경로) (https://www.icbanq.com/P011962236) · 4,246원 — MOQ 30이라 부적합(참고)

배선: S=헤드폰 접지, SN=감지. T-B: 3.3V–330Ω–PC817 LED(애노드→캐소드)–SN, S–GND로 두면 '플러그 없음=LED 켜짐', 꽂으면 꺼짐 → PC817 트랜지스터를 KABD MP 핀(핀1 GND, 핀2 MP#)에 연결해 DSP가 스피커 출력만 소프트 뮤트. 포토커플러로 앰프 접지와 헤드폰 접지를 따로 두어 험(그라운드 루프) 방지. 같은 SN 신호를 Pi GPIO(내부 풀업)로도 읽어 표시용으로 쓸 수 있음. 스위치 접점 0.5A라 스피커 선을 직접 끊는 용도로는 쓰지 않는다.

가격 메모: VAT 포함(3,167원+VAT), MOQ 1, 해외재고 4~6일

아이씨뱅큐(해외재고)3,484원 (https://www.icbanq.com/P000256618)

3,484원 · 1개3,484원

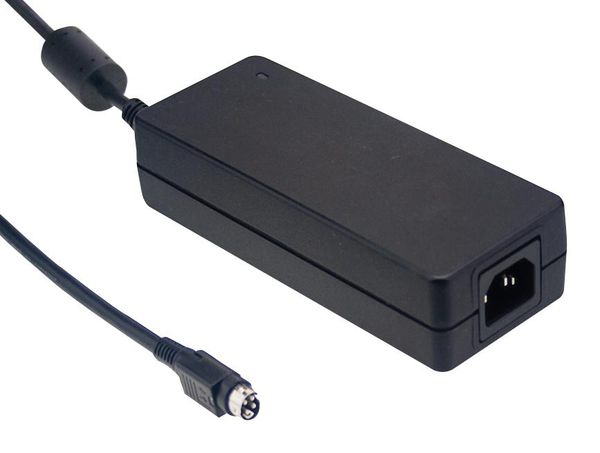
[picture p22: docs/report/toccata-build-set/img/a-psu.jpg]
앰프용 DC 전원 Mean Well GST120A24-P1M (24V 5A)
 × 1사진: 같은 규격의 다른 제품

power

#### 앰프용 DC 전원 Mean Well GST120A24-P1M (24V 5A)

MEAN WELL GST120A24-P1M

T-B에서 KABD-430(12–26V) 전원. Pololu 벅을 쓰면 Pi 전원까지 이 하나로

세부 스펙

출력 | 24V 5A (120W)
플러그 | P1M = 5.5×2.5mm 배럴 (판매처 GST90A24-P1M 설명 '2.5x5.5plug'과 같은 코드)
AC 입력 | IEC 320 코드 타입(판매처 표기 '6FT. BLK- IEC 320')
용도 여유 | KABD-430 최대 120W 음악 신호 평균 수십 W + Pi 5 최대 25W(벅 사용 시)

대안

- MEAN WELL GST120A20-P1M (20V 6A) (https://www.icbanq.com/P010127757) · 76,076원 — T-A(Amp4 Pro, 4Ω은 12–20V 권장)용
- MEAN WELL GST160A24-R7B (24V 6.67A) (https://www.icbanq.com/P010133211) · 89,375원 — 여유 더 크지만 R7B는 4핀 DIN 플러그라 배럴 잭에 바로 안 맞음

KABD-430 하네스 DC잭 규격(2.1/2.5mm)은 매뉴얼에서 수치를 찾지 못함 — 받은 하네스에 맞춰 P1M/P1J 선택 또는 잭 교체. 24V는 KABD-430 허용 상한(26V)에 가깝지만 범위 안. 한 브릭 구성에서 Pi를 벅으로 급전할 때도 USB-C는 절대 동시 연결 금지(D16 취지).

사진 출처: https://kr.element14.com/productimages/large/en_GB/2815843-40.jpg (같은 GST120A 계열 20V 모델 이미지, 외형 동일)

가격 메모: VAT 포함(69,160원+VAT), MOQ 1, 해외재고 1주 이내, 전원 코드 별도 확인

아이씨뱅큐(해외재고)76,076원 (https://www.icbanq.com/P010127759)

76,076원 · 1개76,076원

라즈베리파이 27W USB-C 공식 전원 × 1

power

#### 라즈베리파이 27W USB-C 공식 전원

Raspberry Pi 27W USB-C Power Supply (White, SC1149 계열)

추천안(T-B)에서 Pi 5 단독 전원. 앰프 HAT 구성(T-A)에서는 개발 책상용으로만(D16: HAT 급전 중 USB-C 동시 연결 금지)

세부 스펙

출력 | 5.1V 5A (PD, 27W)
커넥터 | USB-C 일체형 케이블
효과 | 5A PD 협상 시 Pi 5 USB 포트 합계 1.6A 허용 → Pico 8개 USB 급전 여유
인증 | 국내 판매품 KC 여부 판매처 확인

대안

- 라즈베리파이5 PD 27W 호환 KC 아답터 (https://www.devicemart.co.kr/goods/search?search_text=27W) · 9,900원 — 더 싸지만 비공식

호환 아답터 가격(9,900원)은 디바이스마트 검색 API 결과에서만 확인(상품 페이지 미확인). 5A PD가 아닌 전원이면 Pi 5는 USB 합계 600mA로 제한된다 — Pico 8개 + 홀센서 전류를 이 전원으로 감당하는지 반드시 계산.

가격 메모: VAT 포함(16,400원+VAT), 확인 시점 장바구니 가능

디바이스마트18,040원 (https://www.devicemart.co.kr/goods/view?no=15502402)

18,040원 · 1개18,040원

이미지 없음× 1

io

#### 포토커플러 PC817 (헤드폰 감지 → KABD MP 핀)

PC817 (DIP-4)

NMJ6HCD2 슬리브 스위치 신호를 KABD-430 MP 핀으로 절연 전달 → DSP 스피커 뮤트(R15 하드웨어 경로)

세부 스펙

형식 | 트랜지스터 출력 포토커플러, 1채널, DIP-4
LED 구동 | 3.3V−330Ω → 약 6mA
출력 | KABD MP 핀(핀1 GND, 핀2 MP#)을 GND로 끌어내림
부가 부품 | 330Ω 저항 1개

MP 핀을 'Input GPIO Debounce'로 설정하고 SigmaStudio에서 그 값으로 위성·서브 출력 뮤트 블록을 제어(KABD 매뉴얼의 스위치 연결 방식). 대기 포트 J11을 쓰면 더 단순하지만 전원 단계 전환이라 팝 소음 가능 — 실측 후 선택.

가격 메모: VAT 포함(1,200원+VAT), 국내재고

아이씨뱅큐1,320원 (https://www.icbanq.com/P016196009)

1,320원 · 1개1,320원

스피커 터미널 컵 (스프링식) × 3선택

enclosure

#### 스피커 터미널 컵 (스프링식)

Parts Express Round Speaker Wire Terminal Cup Spring Type (260-294)

위성·서브 상자의 배선 인출(분리 가능). 본체 내부 고정 배선이면 생략 가능

세부 스펙

형식 | 원형 스프링 클립 터미널 컵
용도 | 스피커 상자 후면 인출
수량 | 위성 2 + 서브 1
리뷰 | PE 52건
밀폐 | 가스켓 테이프로 상자 밀폐 유지

대안

- Gold 5-Way Binding Post 원형 리세스 터미널 (PE 260-311) (https://www.parts-express.com/Gold-Banana-5-Way-Recessed-Speaker-Terminal-Round-260-311) · 8,510원 — 바나나 플러그 지원·고급

Coms BU942는 '제작용 스피커 터미널 커넥터 2페어'로 컵형이 아니다. 둘 다 이번에 판매 페이지를 열어 가격을 확인.

가격 메모: 개당 $1.49 × 1353.7원, 3개 필요, 배송비 별도

Parts Express (미국)2,020원 (https://www.parts-express.com/Round-Speaker-Terminal-260-294)아이씨뱅큐3,300원 (https://www.icbanq.com/P005672249)

2,020원 · 3개6,060원

스피커 케이블 16AWG × 1

cable

#### 스피커 케이블 16AWG

프리즘 국산 스피커케이블 50C 16AWG (PRS-50B03 / PRS-50B07)

앰프→위성·서브 배선. 본체 내부 1~2m 수준이라 16AWG면 손실 무시 가능

세부 스펙

굵기 | 16AWG (50C)
길이 | 3m 또는 7m 선택
색 | 블랙
제조 | 국산
도체 재질 | 상품 페이지에서 OFC 표기 확인 못 함

OFC 여부는 미확인. 1~2m 배선에서 16AWG(약 13mΩ/m)면 4Ω 부하 대비 손실 0.1dB 미만이라 OFC가 아니어도 R14에 영향 없음. 서브 배선은 홀센서 열에서 떨어뜨려 라우팅(D14 자기장).

가격 메모: 3m, VAT 포함(6,900원+VAT), 국내재고 3~4일

아이씨뱅큐7,590원 (https://www.icbanq.com/P017159544)아이씨뱅큐15,070원 (https://www.icbanq.com/P017159543)

7,590원 · 1개7,590원

흡음재 폴리필 (1 lb) × 1

enclosure

#### 흡음재 폴리필 (1 lb)

Acousta-Fill Nylon Polyfill 1 lb (PE 260-319)

밀폐함 내부 정재파 억제·실효 부피 증가(Qtc 소폭 하강)

세부 스펙

재질 | 나일론 폴리필
중량 | 1 lb (약 454g)
권장 충전량 | 밀폐함 기준 대략 0.5~1 lb/ft³ 느슨하게 (일반 가이드)
필요량 | 위성 2×4.7L + 서브 15~18L ≈ 0.9ft³ → 1 lb 한 봉지로 충분
재고 | 확인 시 In Stock

대안

- Acousta-Fill 5 lb (https://www.parts-express.com/Acousta-Fill-Nylon-Polyfill-5-lb.-Bag-Speaker-Cabinet-Damping-Material-260-331) · 74,430원 — 대량

국내 판매처(아이씨뱅큐 '흡음재', 오디오DIY몰 검색)에서는 확인 가능한 상품을 찾지 못해 PE만 기재. 충전량 가이드는 일반 관행 값(출처 없는 참고치).

가격 메모: $15.98 × 1353.7원, 배송비 별도

Parts Express (미국)21,630원 (https://www.parts-express.com/Acousta-Fill-Nylon-Polyfill-1-lb.-Bag-Speaker-Cabinet-Damping-Material-260-319)

21,630원 · 1개21,630원

스피커 그릴 천 (음향 투과) × 1

enclosure

#### 스피커 그릴 천 (음향 투과)

Parts Express Speaker Grille Cloth Black, 1 yard × 70" (PE 260-335)

D17: 3D프린트 그릴 프레임(개구율 크게)에 씌우는 음향 투과 천

세부 스펙

폭 | 70" (177cm)
길이 | 1 yard (91cm)
색 | 블랙
리뷰 | PE 407건
용도 | 위성 2 + (필요시) 서브 개구부

대안

- Visaton 4670 5" 금속 그릴 (FR10 등 4" 유닛용) (https://www.parts-express.com/Visaton-4670-5-Grill-for-4-Speakers-292-533) · 9,840원 — 천 대신 금속 타공 그릴(개구율 표기 미확인)
- Mellotone 그릴 천 36" (https://www.parts-express.com/Speaker-Grill-Cloth-Fabric-Black-Yard-36-Wide-261-800) · 13,510원 — 조밀한 대체 천

천의 음향 투과율 수치는 페이지에서 확인 못 함. 그릴 프레임은 유닛 앞 공간을 최대한 비우고(살 폭 좁게), 천은 팽팽하게.

가격 메모: $9.98 × 1353.7원, 배송비 별도

Parts Express (미국)13,510원 (https://www.parts-express.com/Speaker-Grill-Cloth-Black-Yard-70-Wide-260-335)

13,510원 · 1개13,510원

진동 절연 고무 (볼트 방진고무) × 10

enclosure

#### 진동 절연 고무 (볼트 방진고무)

화성고무 볼트방진고무 RUB-D1 30×8 (크레텍 805-0339)

D15: 스피커 상자(특히 서브)를 키베드에 직접 고정하지 않고 고무로 띄워 고정

세부 스펙

크기 | 고무 지름 30mm × 두께 8mm (상품명 표기)
형식 | 볼트 일체형 방진 고무발
판매 단위 | 10개 단위(MOQ 10)
볼트 규격 | 이미지상 수나사 — 나사 규격은 상세 이미지로 확인 필요
용도 | 서브 상자 4점 + 위성 상자 각 2~3점

대안

- Subwoofer Speaker Feet 4-Pack (PE 260-7550) (https://www.parts-express.com/search?keywords=grill%20cloth%20black) · 4,450원 — 서브를 바닥에 둘 때 발(클리어런스)

Sorbothane은 PE·아이씨뱅큐 검색에서 찾지 못함. 고무 경도·나사 규격 미확인 — 서브(무게 수 kg)는 고무가 너무 무르면 흔들리므로 설치 후 D14/D15 게이트 ④(20~300Hz 스윕)로 검증.

가격 메모: 10개 13,200원(VAT 포함, 개당 1,200원+VAT), 국내재고 4~5일

아이씨뱅큐13,200원 (https://www.icbanq.com/P013051506)

13,200원 / 10 · 1묶음13,200원

스피커 가스켓 테이프 × 1

enclosure

#### 스피커 가스켓 테이프

Parts Express Speaker Gasketing Tape 1/8" × 1/2" × 50ft (PE 260-542)

유닛 플랜지·터미널 컵·뒷판 밀폐(밀폐함 누설 방지 → Qtc 계산 유지)

세부 스펙

두께 | 1/8" (3.2mm)
폭 | 1/2" (12.7mm)
길이 | 50ft (15m)
형식 | 폼 가스켓(접착)
리뷰 | PE 113건

대안

- 1/8" × 3/8" × 50ft (PE 260-540) (https://www.parts-express.com/Speaker-Gasketing-Tape-1-8-x-3-8-x-50-ft.-Roll-260-540) · 18,920원 — 좁은 폭

3D프린트 상자는 레이어 사이로도 샐 수 있으므로 벽 두께·인필을 충분히 하고 내부 실링(도료 등)도 고려.

가격 메모: $14.48 × 1353.7원, 배송비 별도

Parts Express (미국)19,600원 (https://www.parts-express.com/Speaker-Gasketing-Tape-1-8-x-1-2-x-50-ft.-Roll-260-542)

19,600원 · 1개19,600원

Pianoteq 9 Stage (물리 모델링 피아노) × 1

음원 소프트웨어

#### Pianoteq 9 Stage (물리 모델링 피아노)

Modartt Pianoteq 9 Stage · Linux ARM 지원

R3 하프 페달(CC64 연속값)과 R6 '실제 피아노처럼'을 한 번에 만족하는 음원. 무료 FluidSynth·sfizz는 서스테인을 켜짐/꺼짐으로만 처리합니다.

세부 스펙

가격 | $139 (≈188,160원, 1,353.7원/$)
라이선스 | 영구, 버전 업그레이드 유료 $29
플랫폼 | Linux x86·ARM (Pi 5), 체험판 v9.2.4
방식 | 물리 모델링, 샘플 없음 (~50 MB)
페달 | 할당 가능 4개 (서스테인·소프트·소스테누토 등)
벨로시티 | 연속, 곡선·자동 보정
확인 한계 | modartt.com 접속 불가로 9/3 보관본 기준 — 하프페달·활성화 대수는 공식 페이지 재확인 필요

가격 메모: $139, 1,353.7원/$ 환산 (2026-09-03 보관본 가격)

Modartt (해외 결제)188,160원 (https://www.modartt.com/buy)

188,160원 · 1개 · 하프 페달 지원 음원188,160원

### S-4음원 소프트웨어

이름 | 가격 | 라이선스 | Pi 5 (ARM) | 기능
Pianoteq 9 Stage (https://www.modartt.com/buy) | $139 (≈188,160원, 1353.7원/$) | 상용, 영구 라이선스(버전 업그레이드 유료 $29) | 지원 — 구매 페이지 'Linux (x86, arm)', 체험판 v9.2.4 Linux tar.xz(2026-08-25) | 악기 팩 2개 선택, 물리 모델링(88키, 샘플 없음, ~50MB), 연속 벨로시티(127+ 단계, 곡선·자동 보정), 할당 가능 페달 4개(서스테인·소프트·소스테누토·하모닉 등 12종), 폴리 애프터터치, EQ·리버브. Stage는 물리 모델 파라미터·마이크 위치·Scala 조율 편집 불가. 체험판은 일부 키가 꺼지고 일정 시간 뒤 무음(R4 불충족 → 구매 필요). 하프페달(CC64 연속)·릴리즈 벨로시티·활성화 대수는 널리 알려진 기능이지만 modartt.com이 조사 시점(2026-09-24) 접속 불가라 공식 페이지로 재확인하지 못함.
Pianoteq 9 Standard (https://www.modartt.com/buy) | $269 (≈364,150원), Stage→Standard 업그레이드 $130 | 상용 | 지원 | 악기 팩 3개 + 피아노 모델 조정, 고급 조율, 마이크 믹스·이동, 외부 리버브 IR, 모핑·레이어
Pianoteq 9 PRO (https://www.modartt.com/buy) | $399 (≈540,130원) | 상용 | 지원 | 악기 팩 4개 + Note Edit(음마다 파라미터) 등. Studio Bundle(PRO+모든 팩) $929
FluidSynth 2.6.1 + Salamander Grand Piano V3 (SF2) (https://github.com/FluidSynth/fluidsynth) | 무료 | FluidSynth LGPL-2.1 / Salamander CC-BY 3.0(저작자 표기) | 지원(소스·배포판 패키지), 최신 v2.6.1 (2026-09-19) | Salamander: Yamaha C5, 48kHz/24bit, 16 벨로시티 레이어, SF2 296MiB. FluidSynth 소스상 서스테인은 CC64<64면 해제되는 온/오프 방식 → 하프페달 불가(R3 기준선 미달), D1의 연속값도 64 경계로만 해석
sfizz 1.2.3 + Salamander Grand Piano V3 (SFZ+FLAC) (https://github.com/sfztools/sfizz) | 무료 | sfizz BSD-2-Clause / Salamander CC-BY 3.0 | 지원(소스 빌드), 최신 릴리스 1.2.3 (2024-01-14) | SFZ+FLAC 707MiB(48kHz/24bit). sfizz 소스상 sustain_cc·sustain_lo(문턱값) 방식 → 문턱 조정은 되지만 연속 하프페달 모델은 아님. 릴리즈 트리거 등은 SFZ 악기 정의에 따라 다름
Upright Piano KW (SFZ/SF2) (https://freepats.zenvoid.org/Piano/acoustic-grand-piano.html) | 무료 | CC0 1.0 (퍼블릭 도메인) | FluidSynth/sfizz로 재생 | Kawai 업라이트, 스테레오 2 벨로시티 레이어, SFZ+FLAC 32MiB — 가볍지만 표현력 낮음
CamillaDSP 4.1.3 (T-C 전용) (https://github.com/HEnquist/camilladsp) | 무료 | GPL-3.0 | 지원 | 크로스오버·EQ·리미터·채널 라우팅(웹소켓 제어)
Analog Devices SigmaStudio (T-B 전용) (https://www.parts-express.com/pedocs/manuals/sigmastudio-programming-for-the-dayton-audio-kabd-series-of-amplifiers-v1.pdf) | 무료 | ADI 무료 소프트웨어(등록 필요) | 해당 없음 — Windows PC에서 한 번 KABD-430 프로그래밍 | ADAU1701 그래픽 DSP 설계, EEPROM 기록. Dayton KABD 예제 프로젝트 제공

### S-5다른 구성의 부품·대안

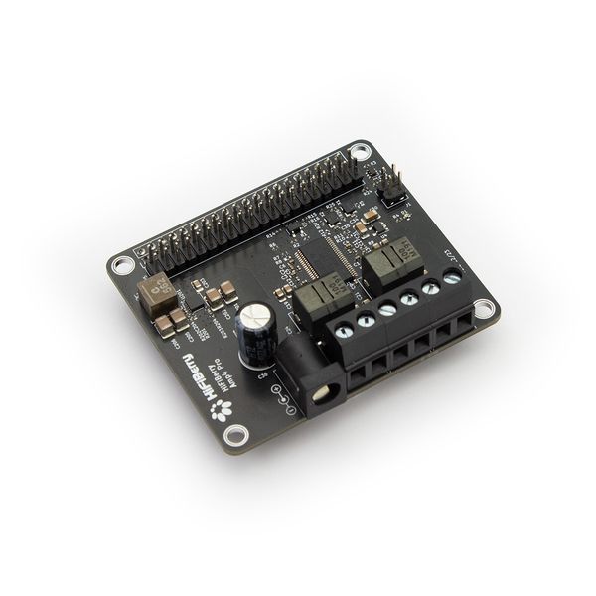
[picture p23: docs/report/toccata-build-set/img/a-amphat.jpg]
HiFiBerry Amp4 Pro (앰프 HAT 중 추천)


amp

#### HiFiBerry Amp4 Pro (앰프 HAT 중 추천)

HiFiBerry Amp4 Pro (EAN 4260439551085)

앰프 HAT 경로(T-A)의 핵심: I2S→디지털 입력 D급 앰프, Pi 5에 5V 최대 5A 급전

세부 스펙

칩 | TI TAS5756M (커널 오버레이 compatible 'ti,tas5756', I2C 0x4d)
출력(4Ω, THD<0.1%) | 14W@12V / 18W@18V / 20W@24V
최대 출력(4Ω, THD 10%) | 15W@12V / 30W@18V / 44W@24V
전원 입력 | 12–24V (4Ω은 12–20V 권장, 절대최대 24V)
Pi 급전 | 5V 최대 5A (Pi 5 명시 지원)
뮤트 | GPIO4 active-low (dtoverlay=hifiberry-amp4pro, 파라미터 mute_ext_ctl / auto_mute)
샘플레이트 | 44.1–192kHz, 16–32bit
헤드폰/라인 출력 | 없음
THD+N/SNR | <0.02% (0.1–10W) / 104dB
클럭 | 듀얼 도메인 클럭 내장

대안

- HiFiBerry Amp100 (https://www.hifiberry.com/shop/boards/amp100/) · 134,020원 — 2×100W@4Ω(30V)이지만 데이터시트상 Pi 급전은 'Pi4B까지' → Pi 5 급전 보장 없음. DAC는 PCM5122(오버레이 기준)
- HiFiBerry AAmp60 (DAC2 HD 등 위에 얹는 아날로그 앰프) (https://www.hifiberry.com/shop/boards/aamp60/) · 60,780원 — DAC 라인아웃을 살리면서 Pi 급전하지만 데이터시트상 'Pi4B까지'

앰프 HAT 한 장으로 끝내야 한다면 이것을 추천: Pi 5를 명시 지원하고 5A라서 Pico 8개 USB 부하에 여유(D16의 PSU_MAX_CURRENT를 5000으로 올릴 근거가 생김). 단점: 헤드폰·라인 출력이 없어 서브·헤드폰 자동 차단(R15)을 붙이기 어렵다. 국내: HiFiBerry 한국 리셀러(디바이스마트·엘레파츠·로보사이언스)에서 Amp4 Pro 상품을 찾지 못함(디바이스마트 검색, 엘레파츠 검색 확인) → 해외 직구. 추천 토폴로지(T-B)에서는 이 HAT을 쓰지 않는다.

가격 메모: $74.90 × 1353.7원 환산, 배송비·부가세 별도(스위스 Swiss Post/Asendia, 1~6주)

HiFiBerry 공식(스위스, 해외배송)101,390원 (https://www.hifiberry.com/shop/boards/amp4pro/)The Pi Hut (영국)151,570원 (https://thepihut.com/products/hifiberry-amp4-pro)

101,390원101,390원

Raspberry Pi DigiAMP+ (차선 앰프 HAT) 선택

amp

#### Raspberry Pi DigiAMP+ (차선 앰프 HAT)

Raspberry Pi DigiAMP+ (구 IQaudio DigiAMP+)

국내 재고가 있는 공식 앰프 HAT 대안

세부 스펙

칩 | TI TAS5756M
출력 | 2×35W (제품 브리프 표기, 가변 출력)
전원 입력 | 12–24V DC, 5.5×2.5mm 배럴(또는 P5 단자)
Pi 급전 | 5.1V @ 2.5A
뮤트 | GPIO22 (dtoverlay=rpi-digiampplus,unmute_amp 또는 auto_mute_amp)
헤드폰/라인 출력 | 없음
크기 | 58×65mm
생산 보장 | 2028년까지

싸고 국내 재고가 있지만 Pi 급전이 2.5A뿐이고, 공식 문서가 'Pi 3 이하용으로 설계, Pi 4 이후는 외부 전원 USB 허브 사용'이라고 적고 있다. Toccata는 Pico 8개를 USB로 물리므로 비추천.

가격 메모: VAT 포함(42,400원+VAT), 확인 시점 장바구니 가능

디바이스마트46,640원 (https://www.devicemart.co.kr/goods/view?no=13237162)

46,640원46,640원

5V 5.5A 강압 레귤레이터 Pololu D36V50F5 (단일 전원 옵션) 선택

power

#### 5V 5.5A 강압 레귤레이터 Pololu D36V50F5 (단일 전원 옵션)

Pololu D36V50F5

T-B에서 전원 브릭을 하나로 하고 싶을 때 24V→5V를 Pi GPIO 5V 핀(2·4번)에 공급

세부 스펙

출력 | 5V, 최대 5.5A (36V 입력 기준 연속 전류, 발열에 따라 다름)
입력 | 5.5–50V
형식 | 동기식 벅 모듈
용도 | HAT이 하는 5V 백피딩과 같은 방식

GPIO 급전은 Pi의 입력 보호를 우회하고 PD 협상이 없으므로 EEPROM PSU_MAX_CURRENT(및 usb_max_current_enable) 설정이 필요. 27W 공식 USB-C 전원(18,040원)이 더 싸고 안전해서 기본안은 '브릭 2개'.

가격 메모: VAT 포함(69,030원+VAT), 해외재고 4~6일

아이씨뱅큐(해외재고)75,933원 (https://www.icbanq.com/P014849358)Pololu (미국 직판)54,080원 (https://www.pololu.com/product/4091)

75,933원75,933원

유닛 고정용 황동 히트셋 인서트 선택

hardware

#### 유닛 고정용 황동 히트셋 인서트

Adafruit 4255 Brass Heat-Set Inserts M3×4mm 50pcs

3D프린트 위성 상자에 DMA105 고정(4점). MDF/합판 서브 상자에는 T너트/허리케인 너트

세부 스펙

나사 | M3
길이 | 4mm
수량 | 50개
재질 | 황동
설치 | 인두로 열압입

대안

- PE #8-32 Hurricane Nuts 50개 (081-1080) (https://www.parts-express.com/search?keywords=t-nut) · 12,930원 — 목재 서브 상자용(≈M4급 인치 나사)
- PE Hex Drive M6 Barbed Insert Nuts 20개 (081-1098) (https://www.parts-express.com/Hex-Drive-M6-Barbed-Body-Insert-Nuts-20-Pcs.-081-1098) · 6,750원 — 목재 상자에 미터 나사

요청한 M4 T너트/M4 히트셋 인서트는 이번에 연 국내·PE 페이지에서 찾지 못함(PE는 인치 규격 위주). DMA105/RSS210HF-4 고정홀 지름도 스펙시트에 없어 실물 확인 후 M3/M4 결정. 대체 두 항목 가격은 PE 검색 결과 목록에서 확인.

가격 메모: VAT 포함(10,800원+VAT), 해외재고 7~10일

아이씨뱅큐(해외재고)11,880원 (https://www.icbanq.com/P013153497)

11,880원 / 5011,880원

이미지 없음선택

amp

#### 모노 서브앰프 보드 Wondom AA-AB31184 (T-A/T-C용)

WONDOM AA-AB31184 TPA3116 1×100W

라인 입력 모노 D급 앰프 → 서브 구동

세부 스펙

칩 | TI TPA3116 (PBTL)
출력 | 100W@2Ω 21V (THD+N 10%), 87W@2Ω (1%)
전원 | 10–24V DC
입력 | 싱글엔드 라인 입력
기능 | Mute·Standby 기능, 과전류·과열·역극성 보호
크기 | 91.4×68.6mm
LPF | 내장 표기 없음 → 별도 LPF 필요

4Ω 출력은 표기 없음(2Ω 기준) — 4Ω에서는 대략 절반 수준으로 예상(미확인).

가격 메모: $24.21(정가 $26.90) × 1353.7원, 해외배송비 별도

Wondom 공식 스토어(Sure Electronics)32,770원 (https://store.sure-electronics.com/product/AA-AB31184)

32,770원32,770원

이미지 없음선택

amp

#### 스피커레벨→라인레벨 변환기(LOC) + 서브 LPF

미정(범용 하이-로우 컨버터 + 연산증폭기 LPF 보드)

T-A에서 Amp4 Pro BTL 스피커 출력을 서브앰프 라인 입력으로 바꾸고 100Hz 이하만 통과

세부 스펙

필수 조건 | BTL(양쪽 핫) 입력 허용 = 차동/트랜스 절연형
LPF | 가변 50–150Hz, 2차 이상
합산 | L+R 모노 합산

이번 조사에서 판매 페이지를 열어 가격을 확인하지 못함(아이씨뱅큐 검색 결과 없음). 품질 편차가 커서 T-A의 약점.

가격 확인 필요—

이미지 없음선택

dac

#### USB 헤드폰 DAC (Apple USB-C to 3.5mm)

Apple USB-C to 3.5mm Headphone Jack Adapter (MW2Q3KH/A)

T-A에서 헤드폰 전용 출력(별도 ALSA 카드)

세부 스펙

연결 | USB-C (Pi 5 USB-A에는 A→C 변환 필요)
출력 | 3.5mm
클래스 | USB Audio Class (드라이버 불필요)

I2S DAC와 클럭이 달라 동시 출력 불가 → 헤드폰 전환 시 엔진을 이 장치로 재시작해야 함(D10 서비스 전환 로직 필요).

가격 메모: Apple 공식 검색 결과 타일 가격 ₩14,900

Apple 코리아14,900원 (https://www.apple.com/kr/search/USB-C-3.5mm-%ED%97%A4%EB%93%9C%ED%8F%B0-%EC%9E%AD-%EC%96%B4%EB%8C%91%ED%84%B0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)

14,900원14,900원

이미지 없음선택

dac

#### HiFiBerry DAC8x (8채널, Pi 5 전용)

HiFiBerry DAC8x (EAN 4260439551016)

T-C: CamillaDSP로 나눈 위성/서브/헤드폰 채널을 한 클럭에서 출력

세부 스펙

채널 | 8ch 출력
DAC | Burr-Brown 192kHz/24bit ×4
최대 출력 | 2.1Vrms
SNR/THD+N | 112dB / −93dB
주파수 | 10Hz–70kHz (−3dB)
전원 | Pi에서 공급(<0.3W), Pi 급전 안 함
오버레이 | dtoverlay=hifiberry-dac8x
호환 | Raspberry Pi 5만

출력 커넥터 형태는 데이터시트 본문에서 확인 못 함.

가격 메모: $64.90 × 1353.7원, 배송·부가세 별도

HiFiBerry 공식87,860원 (https://www.hifiberry.com/shop/boards/hifiberry-dac8x/)

87,860원87,860원

이미지 없음선택

amp

#### 위성용 스테레오 앰프 Wondom AA-AB32178 (T-C용)

WONDOM AA-AB32178 TPA3116 2×50W

T-C 위성 구동

세부 스펙

칩 | TI TPA3116
출력 | 50W@4Ω 21V (10%), 36W@4Ω (1%)
전원 | 10–24V
입력 | 싱글엔드 라인
크기 | 91.4×68.6mm

가격 메모: $24.21 × 1353.7원, 해외배송비 별도

Wondom 공식 스토어32,770원 (https://store.sure-electronics.com/product/AA-AB32178)

32,770원32,770원

이미지 없음선택

amp

#### 헤드폰 앰프 모듈 (TPA6120/NJM4556 계열)

미정

T-C에서 DAC8x 라인 채널을 헤드폰 레벨로

세부 스펙

필요 조건 | 라인 입력, 16~300Ω 구동, 잭 감지 연동 불필요(감지는 NMJ6HCD2)

이번 조사에서 판매 페이지를 열어 확인하지 못함.

가격 확인 필요—

이미지 없음선택

power

#### Amp4 Pro용 20V 전원 Mean Well GST120A20-P1M (T-A)

MEAN WELL GST120A20-P1M

T-A: Amp4 Pro(4Ω은 12–20V 권장)와 서브앰프(10–24V) 공용 전원, Pi는 Amp4 Pro가 급전

세부 스펙

출력 | 20V 6A (120W)
플러그 | P1M = 5.5×2.5mm 배럴
AC 입력 | IEC 320 코드 타입(판매처 표기)
Amp4 Pro 출력(20V 부근) | 4Ω 약 18W/ch(THD<0.1%, 18V 표기값)

Amp4 Pro DC 잭 규격은 이번에 확인 못 함(HiFiBerry 페이지에 표기 없음) → 수령 후 플러그 코드 선택.

가격 메모: VAT 포함(69,160원+VAT), 해외재고 4~7일

아이씨뱅큐(해외재고)76,076원 (https://www.icbanq.com/P010127757)

76,076원76,076원

## 페달·조작부

페달 모듈(피코 1개)이 댐퍼(CC64 연속값, D1), 소스테누토(CC66), 소프트(CC67)를 읽습니다(D5). 하프 페달(R3)을 위해 댐퍼는 연속형이어야 합니다.

### P-1페달 구성

#### 개별 페달 3개: DP-10(연속 댐퍼) + KP-2 스위치 ×2

권장

p-damper ×1, p-switch ×2, p-trsjack ×3, b-pedalboard ×1

장점

- 가장 저렴하면서 댐퍼는 진짜 하프페달(CC64 0–127)
- DP-10은 Roland EV-5 배선이라 Pico에 저항 3개로 직결
- 페달 하나 고장 시 개별 교체, 나중에 KP-2를 DP-10으로 업그레이드 가능
- 모두 국내 재고 확인(프리버드)

단점

- 소프트·소스테누토는 온/오프만(연속 소프트 불가)
- 페달 3개가 따로 놀아 보드 제작 필요
- DP-10(박스형 힌지)과 KP-2의 감촉·높이가 다름

142,122원

#### 트리플 페달 유닛: Roland RPU-3

p-triple ×1, p-trsjack ×3

장점

- 그랜드 피아노와 같은 3페달 배치·일체형 프레임(2.5 kg)으로 안정적
- 세 페달 모두 연속(3.2 kΩ 포트) → 연속 소프트(CC67)까지 가능
- 배선은 DP-10과 동일(Tip=와이퍼) — 펌웨어 공용
- 페달보드 제작 불필요

단점

- 구성 A보다 약 9만원 비쌈
- 국내 판매처가 적음(확인된 곳: 코스모스악기)
- 케이블 2.2 m 고정, 단일 유닛 고장 시 통째 수리

231,122원

배선. ■ 페달 잭 1개당 회로(PJ-603A 핀: 1=Sleeve, 2=Ring, 3=Tip, 4=Tip 노멀) — 3개 동일, ADC는 GP26/27/28 · Sleeve → Pico AGND · Ring → 1 kΩ → 3V3(OUT). TS(모노) 플러그를 꽂으면 Ring이 GND로 단락되므로 1 kΩ가 전류를 3.3 mA로 제한(Roland RPU-3 설명서도 '플러그 금속부 단락 주의' 명시). · Tip → 22 kΩ 풀업 → 3V3, Tip → 1 kΩ 직렬 → ADC 핀, ADC 핀–AGND 100 nF (RC 필터/ESD 완화). 입력은 최대 3.3 V라 클램프 불필요(원하면 BAT54S 추가). · Tip 노멀(4번) → GPIO + 100 kΩ 풀다운: 플러그 없음=Tip 스프링(22 kΩ 풀업)과 접촉해 HIGH(≈2.7 V), 플러그 삽입=분리되어 LOW → 연결 감지. (내부 풀다운 50–80 kΩ만 쓰면 ≈2.3 V로 VIH 여유가 작음) · (선택) Ring → 10 kΩ → GPIO: 부팅 시 LOW면 TS 스위치 페달, HIGH면 TRS 연속 페달(표시용). ■ 페달별 기대 전압(위 회로, 3.3 V) · Roland DP-10(Continuous): Tip=와이퍼, Ring=+, Sleeve=GND(EV-5 동일). 뗌 ≈0 V → 밟음 ≈3.0 V(10 kΩ 포트 + Ring 직렬 1 kΩ). 22 kΩ 풀업 때문에 중간에서 약 +0.2 V 휨 → 보정 LUT로 선형화. · Roland RPU-3(3.2 kΩ 포트 ×3): 같은 배선, 뗌 ≈0 V → 밟음 ≈2.5 V(1 kΩ 직렬 때문에 상한이 낮음, 휨은 더 작음). 페달당 약 0.8 mA. · 스위치 페달(TS): NC형(Roland DP-2, Yamaha FC4A, Kurzweil KP-2) 뗌 0 V / 밟음 3.3 V. NO형(Korg·Casio 계열) 뗌 3.3 V / 밟음 0 V. · Korg DS-1H(Tip–Sleeve 가변저항 30 k→3 k, Ring 미사용): 뗌 ≈1.9 V → 밟음 ≈0.4 V. · Yamaha FC3A(와이퍼=Ring): 이 회로에선 뗌 ≈3.0 V → 밟음 ≈1.0 V지만 앞 절반 행정에서 ≈0.15 V만 변함 → Tip↔Ring 스왑(DPDT 스위치/어댑터/내부 재납땜) 후 사용. ■ 부팅 시 극성·범위 자동 인식(페달을 밟지 않은 채 전원 ON — Kurzweil 등 상용 건반과 같은 방식) 1) 플러그 감지 GPIO로 미연결 채널 제외. 2) 16회 평균으로 V_rest 측정: V_rest < 1.65 V면 '밟으면 증가', 아니면 '밟으면 감소'. 3) 스팬은 작은 기본값(≈1.2 V — DS-1H처럼 스팬이 좁은 페달도 127에 도달하도록)에서 시작해 사용 중 관측된 최대 편차로 자동 확장, 엔코더를 누른 채 부팅하면 '끝까지 밟기' 캘리브레이션 후 플래시에 저장. 4) 값 = clamp((|V−V_rest| − 데드밴드)/(스팬 − 2·데드밴드))×127. CC64는 연속 전송(값이 바뀔 때만, ±1 히스테리시스), CC67은 페달이 연속이면 연속·스위치면 0/127, CC66은 50%±10% 히스테리시스로 0/127. 5) RP2040 ADC는 유효 약 9비트·특정 코드 DNL 튐 → 오버샘플링+IIR 후 7비트면 충분. ■ ADC 채널 한계: Pico/Pico 2의 외부 ADC는 GP26–28 3개(GP29는 보드에서 VSYS/3 측정) → 페달이 모두 사용. 볼륨은 EC11 엔코더(A/B/SW → GPIO 내부 풀업, 공통 → GND)로, 가변저항은 ADS1115 등 외장 ADC가 있을 때만. ■ 전원 버튼: HX16-A4의 NO 접점 2단자 → Pi 5 J2 두 패드(미실장 스루홀, RTC 배터리 커넥터와 보드 가장자리 사이). 공식 문서상 온보드 버튼과 동일 동작(꺼진 상태 누름=부팅, 짧게=종료, 길게=강제 종료). 버튼 LED는 GPIO + 100–220 Ω(내장 저항 불명이므로 벤치 테스트 먼저). ■ 헤드폰 감지: PJ-604A의 절연 SPDT(4-5-6) 공통=GND, 삽입 시 닫히는 쪽 → Pi/Pico GPIO(풀업): LOW=헤드폰 꽂힘 → 스피커 앰프 MUTE/SD. 다른 한 조(7-8-9)는 앰프 SD를 하드웨어로 직접 제어 가능. 3.5 mm PJ-307은 절연 스위치가 없어 노멀 핀을 100 kΩ 풀업 GPIO로 읽고 헤드폰 라인에 DC 경로(10–47 kΩ 블리더)를 둬서 미삽입=LOW/삽입=HIGH로 판정.

### P-2부품

롤랜드 DP-10 댐퍼(하프) 페달 × 1

pedal

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

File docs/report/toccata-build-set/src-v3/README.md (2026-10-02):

# v3 도면 생성기 (치수 위치 수정본, 2026-09-25)

`docs/report/toccata-build-v3.html`의 도면 14장을 만드는 스크립트다. 치수선·치수 글자가 형상과 어긋나던 곳을 고친 판이다.

- `render_drawings.py`, `r26_draw.py`, `draw.py`: 도면 생성. 리프 상세(백건 t 2.6)의 11.0 치수는 리프 끝 모서리에, 15.0·18.0 뿌리 폭은 필렛 전 가상 교점(점선)에 맞췄다.
- `build_v3.py`, `patch_*.py`, `apply_*.py`, `assemble_bom.py`: 설계서 HTML 조립.
- `merge.py`, `merge_v32.py`: 설계서를 A–D 도면집과 합쳐 한 페이지로 만든다. `merge_v32.py`는 v3.2 이후 설계서 머리의 합계를 쓴다.

다시 빌드하려면 v3 작업 폴더의 데이터(`drawings.json`, `bom_all.json`, `cost/`, `img/` 등)가 필요하다. 이 데이터는 저장소에 없다.

v3.2(ME6·ME10, 체결부 변경)의 수정은 생성기가 아니라 HTML 문자열 치환으로 들어갔다. 그래서 이 생성기로 다시 빌드하면 v3.2 문구가 빠진다. 현재 `toccata-build-v3.html`은 수정한 도면과 v3.2 문구를 3-way 병합한 결과다.

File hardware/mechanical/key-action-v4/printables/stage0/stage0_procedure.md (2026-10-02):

# Toccata W1+ r4.5 — 단계 0 시험 키트 (출력 시편·지그와 절차)

2026-09-29 · `make_stage0.py`가 단일 모델(`final/model_v4.py`, `metrics.json`)에서 만들었다. 모든 합격선·설계값·민감도는 모델 값이고, 모델에 없는 값은 **제안**이라고 적었다. 단위 mm·g·N. 좌표는 DESIGN.md와 같다(z0 책상, y0 백건 립 앞끝). 숫자는 보인 자리에서 반올림(0.5는 0에서 멀어지는 쪽).

여기서는 아무도 물리 시험을 할 수 없다. 이 키트는 DESIGN.md 17장의 21개 시험(+ 모델 밖 3개: 밸런스 핀 압입 P, 캡스턴 너트 트랩 C, 펠트·천 두께 T)을 **집에 있는 도구로** 할 수 있게 시편(STL), 재는 법, 합격 숫자, 그리고 결과마다 모델의 어느 값을 얼마나 바꾸는지를 모았다. 결과는 `stage0_results_template.csv`에 적는다.

## 0. 한눈에

| 순서 | 시험 | 시편 | 합격 | 설계(모델) | 떨어지면 바꿀 모델 값 |
|---|---|---|---|---|---|
| 1 | 1 패드 반발 (계 실효 e) | C01a~d | e ≤ 0.07 | e 0.06 | `pad_e`; e > 0.10이면 `gap_us_w/_b` −0.2 + `pad_E` 1.4 |
| 2 | 2 패드 강성 | C02a·b | 25 % 압축 18.3~36.7 N | 26.2 N (E 1.0) | `pad_E` |
| 3 | 3 윗판 패드 자리 처짐 (굽힘 띠 E + 프레임 조각) | C03a~e | 띠 E ≥ 1825 MPa; 프레임 C# 처짐 ≤ 0.103 mm @98 N | E 1950; 0.057 mm | 윗판 채움 100 %, `plate_t` +0.6~1.2 |
| 4 | 20 강철 블록 유지 (캐리어 스냅 + 접착) | C16a·b | 접착: 117 N에 움직임 ≤ 0.05; 스냅만 빠짐 힘 기록 | 스냅만 빠짐 30 ~ 47 N | 접착 필수 (r4.4 고침 2) |
| 4b | 16 윗판 브리지 출력 | C11a | 처짐 ≤ 0.3 | - | 서포트 유지 (§15) |
| 5 | 15 층간 강도 (핀-윗판 이음) | C12a | 층간 ≥ 30 MPa | 이음 최대 5.7 MPa | `s_rare`·`s_cyc`, 이음 살 3 |
| 6 | 5 스냅 노치 반지름 | C04a~c | 빠짐 1~2 N | 1.99 N (R2.55) | `notch_R` + `lift_play/_abuse/_popout` |
| 7 | 6 가이드 탭 천 | C05a·b | 끌림 ≤ 0.02 N, 놀음 < 0.1 | 놀음 0.05 | `tab_w_b`·`tab_w`·`tab_cloth`·`tab_play` |
| 8 | P 밸런스 핀 압입 (모델 밖 제안) | C07a·b | 돌출 4.30 ± 0.1, 누름 15~80 N (제안) | - | 새 `pin_hole_print` |
| 9 | C 캡스턴 너트 트랩 (모델 밖 제안) | C08a | 토크 3~40 N·mm (제안) | 1/8회전 0.0625 mm | 너트 홈 폭·잠김 구멍 Ø |
| 10 | T 펠트·천 두께 (모델 밖 기준, 조정 환산) | C09a·b | 공칭 ±10 % (제안) | 표 T | 펀칭·심·캡스턴 환산 |
| 11 | 4 앞 펠트 반발 | C15a | e ≤ 0.22 | 0.20 | `front_e`, PU 2T |
| 12 | 8 비틀림 보조 스프링 | C06a·b | k_t 8.4 ± 15 %, 자유각 -28 ± 5° | 쉼 4.19 N·mm | `spring_kt`·`spring_free_deg` |
| 13 | 12 패드 바 놀음·잎 크리프 | C10a~c | 1주 40 °C 뒤 잎 힘 ≥ 50 % | 10.1 g | `bar_leaf` 두께 0.8 |
| 14 | 19 USB-C 케이블 맞춤 | C13a | 몰드 ≤ 12.5 × 7.6 × 25 | - | (회로 고정값, 케이블만 바꿈) |
| 15~ | 7·9·10·11·13·14·17·18·21  | 조립 모듈 (21: C17a) | 17장 그대로 | - | 각 절 참조 |

**가장 먼저 1번(패드 반발)을 한다** — 모든 동역학 결과가 e 0.06 가정 위에 있다(DESIGN §18). 3번의 띠 시험은 화음 자리(설계 492, 합격선 460 N/mm; 레일 휨은 조립 시험 21)에 여유가 6.4 %밖에 없다는 것을 처음으로 확인한다: 출력한 윗판의 실효 E가 모델 1950 MPa의 93.6 % 아래이면 화음 자리가 합격선 아래로 내려간다.

## 1. 준비물

| 도구·재료 | 쓰는 곳 | 비고 |
|---|---|---|
| 정밀 저울 0.1 g (최대 200~500 g) | 2 무게, 5 쿠폰, 8 추, 12 잎 힘, C 토크 | 추 컵·쿠폰 무게 |
| 주방 저울 1 g (최대 5 kg, 가능하면 10 kg) | 3 굽힘·프레임 처짐, 5 빠짐 힘, P 누름 힘 | 손으로 누르는 힘 = 저울 읽음 |
| 디지털 버니어 캘리퍼스 0.01 (깊이 막대 있는 것) | 2, 3, 12, 16, P, T |  |
| 다이얼 게이지 0.01 mm, 줄기 Ø8, 행정 10 | 3, 21 | 약 1.5만 원; 스탠드는 C03d·e 출력 |
| 휴대폰 슬로 모션 240 fps | 1, 4, 8, 9, 10 | 삼각대(또는 책 더미)로 눈금판에 수직 |
| PET 심 0.1 (OHP 필름 6×12.2), 영수증 종이 0.05 | 1, 6, 12, 14 | 부품 목록에 있음 |
| Ø4 SUS 봉 토막 24 ×1, 40 ×1, 18 ×1, 45 ×2 | C01, C04c, C06, C12 | 레버 봉 4 m에서 자름 (C06 18: r4.5 고침 2 북 받침 +2) |
| 강철 블록 SS400 9×19×40 ×2 | 1, 3, 9, 12, T | 레버용과 같은 것 |
| Ø19.05 (3/4") 강철 공 1개 (28.4 g) | 4 | 베어링 볼 |
| 대나무 꼬치 Ø3, 가는 실(재봉실/낚싯줄), 순간접착제, 흑연 가루 | 1, 4, 5, 8, 15 |  |
| M3×12 나사 2개, M3 너트·M3×6 버튼헤드 5개씩 | C03d·e, C08 | 캡스턴 재고 |
| 물병·쌀 봉지(무게를 주방 저울로 잰 것), 10 L 양동이, 수건 | 2, 15 |  |
| 곧은 판재(합판 약 200 × 80, 두께 12 이상), 6×12 받침 6개, 물통·아령 36.7 kg | 21 | C17a 받침 빗 위에서 |
| 40 °C를 1주 유지할 곳 (요구르트 제조기·식품 건조기·온열 매트 + 온도계) | 12 | 여름 차 안은 60 °C를 넘어 안 됨 |
| 후보 패드: ① 미세셀 우레탄 6T + 펠트 1T, ② 점탄성 PU 시트, ③ ①+부틸 1T | 1, 2 | 6×12로 자름 |

## 2. 출력

모든 부품은 256×256 베드, PETG, **서포트 없이** 출력한다(C11a는 서포트 없는 브리지 자체가 시험). STL은 이미 출력 방향(z = 쌓는 방향)으로 놓여 있다. ‘생산과 같은 설정’이라고 적은 쿠폰은 그 부품(프레임·건반·패드 바)을 뽑을 슬라이서 설정을 그대로 써야 결과가 모델로 옮겨진다.

| ID | 이름 | 시험 | 방향 | 설정 | 크기 (mm) | 부피 (cm³) | 브리지 (mm²) |
|---|---|---|---|---|---|---|---|
| C01a | 패드 반발 진자대 (받침·눈금판·패드 자리) | 1 | 브래킷 뒷면을 베드에 (눈금판·보스·패드 블록·발이 위로 솟음). 서포트 없음 | PETG, 0.2 층, 벽 4, 채움 40 % (패드 블록은 채움 100 % 권장: 슬라이서 수정자), 서포트 없음 | 156.0 × 113.0 × 64.0 | 128.2 | 0 |
| C01b | 시험 레버 (강철 9×19×40 자리, 허브 Ø3.9, 지침) | 1 | 옆면(두께 9 방향)을 베드에. 강철 칸은 관통, 윗면이 패드 구간 y153~187에서 열림 | PETG, 0.2 층, 벽 4, 채움 100 % (질량·관성을 모델과 맞춤), 서포트 없음 | 82.5 × 28.5 × 9.0 | 3.1 | 0 |
| C01c | 패드 받침판 (2개: 후보 재료마다 1개) | 1 | 넓은 면을 베드에 | PETG, 0.2 층, 벽 4, 채움 100 % (질량·관성을 모델과 맞춤), 서포트 없음 | 46.0 × 11.0 × 4.0 | 1.7 | 0 |
| C01d | 봉 끝 칼라 (2개) | 1 | 눕혀서 | PETG, 0.2 층, 벽 4, 채움 100 % (질량·관성을 모델과 맞춤), 서포트 없음 | 21.0 × 9.0 × 3.0 | 0.3 | 0 |
| C02a | 패드 압축 지그 (바탕·안내 통) | 2 | 바닥을 베드에 | PETG, 0.2 층, 벽 3, 윗/아랫면 5층, 채움 40 % 자이로이드, 서포트 없음 | 60.0 × 60.0 × 26.0 | 19.2 | 0 |
| C02b | 패드 압축 누름 막대 (추 받침판 80×80) | 2 | 받침판을 베드에 (막대가 위로) | PETG, 0.2 층, 벽 4, 채움 100 % (질량·관성을 모델과 맞춤), 서포트 없음 | 80.0 × 80.0 × 27.0 | 26.5 | 0 |
| C03a | 윗판 굽힘 띠 (3개) | 3 | 넓은 면을 베드에 (윗판처럼 층이 수평) | PETG, 생산 프레임과 같은 슬라이서 설정 (층·벽·채움 그대로), 서포트 없음 | 120.0 × 44.0 × 5.5 | 23.7 | 0 |
| C03b | 3점 굽힘 받침 (R2 두 날, 간격 100) | 3 | 바닥을 베드에 (날은 x 방향 프리즘) | PETG, 0.2 층, 벽 3, 윗/아랫면 5층, 채움 40 % 자이로이드, 서포트 없음 | 30.0 × 120.0 × 14.0 | 17.8 | 0 |
| C03c | 누름 코 (R2 날 + 손가락 받침 24×24, 가운데 Ø4 다이얼 구멍) | 3 | 평평한 윗판을 베드에 (날이 위) | PETG, 0.2 층, 벽 3, 윗/아랫면 5층, 채움 40 % 자이로이드, 서포트 없음 | 24.0 × 24.0 × 13.0 | 3.2 | 0 |
| C03d | 다이얼 게이지 스탠드, 낮은 (굽힘 띠용) | 3 | 옆면(두께 16)을 베드에. Ø8 줄기 구멍은 눈물방울(위 뾰족), 구멍에서 윗면까지 1.0 틈 + M3 나사(가로, Ø2.7에 자가 탭) | PETG, 0.2 층, 벽 3, 윗/아랫면 5층, 채움 40 % 자이로이드, 서포트 없음 | 60.0 × 57.0 × 16.0 | 23.1 | 12 |
| C03e | 다이얼 게이지 스탠드, 높은 (프레임 조각 윗판용) | 3 | 옆면(두께 16)을 베드에. Ø8 줄기 구멍은 눈물방울(위 뾰족), 구멍에서 윗면까지 1.0 틈 + M3 나사(가로, Ø2.7에 자가 탭) | PETG, 0.2 층, 벽 3, 윗/아랫면 5층, 채움 40 % 자이로이드, 서포트 없음 | 60.0 × 117.0 × 16.0 | 34.6 | 12 |
| C04a | 스냅 노치 반지름 쿠폰 (백건 블록 폭, R2.50~2.60, 5개) | 5 | 건반처럼 뒤집어 (블록 윗면 = 손잡이 판을 베드에, 노치가 출력 맨 위의 열린 홈) | PETG, 생산 건반과 같은 슬라이서 설정 (윗면을 베드에, 층 0.2), 서포트 없음 | 130.8 × 26.0 × 12.3 | 14.1 | 0 |
| C04b | 스냅 노치 반지름 쿠폰 (흑건 블록 폭, R2.50~2.60, 5개) | 5 | 건반처럼 뒤집어 (블록 윗면 = 손잡이 판을 베드에, 노치가 출력 맨 위의 열린 홈) | PETG, 생산 건반과 같은 슬라이서 설정 (윗면을 베드에, 층 0.2), 서포트 없음 | 111.0 × 26.0 × 12.3 | 10.8 | 0 |
| C04c | 봉 받침 (당김 시험용, 저울 위) | 5 | 바닥을 베드에, 봉 구멍은 눈물방울 | PETG, 0.2 층, 벽 3, 윗/아랫면 5층, 채움 40 % 자이로이드, 서포트 없음 | 90.0 × 60.0 × 29.0 | 18.6 | 0 |
| C05a | 가이드 탭 날 (프레임 쪽, 흑 6.8·6.9·7.0 / 백 7.4·7.5·7.6) | 6 | 바닥을 베드에, 날이 수직 (프레임처럼) | PETG, 생산 프레임과 같은 슬라이서 설정 (층·벽·채움 그대로), 서포트 없음 | 66.0 × 22.0 × 15.0 | 9.5 | 0 |
| C05b | 건반 홈 쿠폰 (흑 벽 사이 8.0, 백 갈비 사이 8.6) | 6 | 건반처럼 뒤집어 (윗판 쪽을 베드에, 홈이 위로 열림) | PETG, 생산 건반과 같은 슬라이서 설정 (윗면을 베드에, 층 0.2), 서포트 없음 | 33.0 × 14.0 × 14.0 | 1.4 | 0 |
| C06a | 비틀림 스프링 시험대 (브래킷·뒷벽 홈 복제·레버 각 눈금) | 8 | 브래킷 뒷면을 베드에 (홈 보스·눈금 고리·발이 위로) | PETG, 0.2 층, 벽 3, 윗/아랫면 5층, 채움 40 % 자이로이드, 서포트 없음 | 89.0 × 74.0 × 44.0 | 30.6 | 81 |
| C06b | 스프링 북 (허브 주머니·가둠 홈·넣는 슬롯·긴 다리 창 복제 + 실 감는 북 R20) | 8 | 북 앞면을 베드에 (허브가 위) | PETG, 0.2 층, 벽 4, 채움 100 % (질량·관성을 모델과 맞춤), 서포트 없음 | 42.0 × 42.0 × 10.0 | 6.8 | 44 |
| C07a | 밸런스 핀 압입 레일 쿠폰 (구멍 Ø1.80~2.00, 5개) | P | 바닥을 베드에 (구멍이 수직, 프레임 레일처럼) | PETG, 생산 프레임과 같은 슬라이서 설정 (층·벽·채움 그대로), 서포트 없음 | 70.0 × 12.2 × 14.0 | 11.7 | 0 |
| C07b | 핀 돌출 게이지 (4.30) | P | 밑면을 베드에 (Ø2.4 막힌 구멍이 아래로 열림) | PETG, 0.2 층, 벽 3, 윗/아랫면 5층, 채움 40 % 자이로이드, 서포트 없음 | 30.0 × 10.0 × 8.0 | 2.4 | 5 |
| C08a | 캡스턴 너트 트랩 빔 쿠폰 (5종) | C | 건반처럼 뒤집어 (빔 윗면 = 바탕 판을 베드에); 너트 홈 천장은 5.6~5.8 브리지 | PETG, 생산 건반과 같은 슬라이서 설정 (윗면을 베드에, 층 0.2), 서포트 없음 | 86.0 × 26.0 × 8.7 | 10.1 | 312 |
| C09a | 두께 측정 받침 (22×22 자리 + 깊이 막대 다리) | T | 바닥을 베드에 (다리 윗판 12 브리지) | PETG, 0.2 층, 벽 3, 윗/아랫면 5층, 채움 40 % 자이로이드, 서포트 없음 | 34.0 × 70.0 × 27.0 | 12.6 | 248 |
| C09b | 누름판 (발 20×20, 강철 블록 자리) | T | 누름판 윗면을 베드에 (발이 위, 강철 자리 홈은 바닥 쪽 1.5 깊이) | PETG, 0.2 층, 벽 3, 윗/아랫면 5층, 채움 40 % 자이로이드, 서포트 없음 | 24.0 × 60.0 × 6.0 | 6.0 | 385 |
| C10a | 패드 바 잎 혀 쿠폰 (3개) | 12 | 패드 바처럼 넓은 면을 베드에 (혀 0.6 = 3층) | PETG, 생산 패드 바과 같은 슬라이서 설정 (층·벽·채움 그대로), 서포트 없음 | 38.0 × 18.0 × 1.5 | 0.5 | 0 |
| C10b | 잎 크리프 받침 (0.3 / 0.6 눌림 두 자리) | 12 | 바닥을 베드에 | PETG, 0.2 층, 벽 3, 윗/아랫면 5층, 채움 40 % 자이로이드, 서포트 없음 | 48.0 × 26.0 × 4.0 | 3.1 | 0 |
| C10c | 잎 힘 측정 받침 (뿌리 물림 턱 높이 12) | 12 | 바닥을 베드에 | PETG, 0.2 층, 벽 3, 윗/아랫면 5층, 채움 40 % 자이로이드, 서포트 없음 | 30.0 × 24.0 × 12.0 | 5.4 | 0 |
| C11a | 윗판 브리지 출력 쿠폰 (핀 사이 39.86, 모델 프레임 그대로 z50 위) | 16 | 바로 세워 (프레임처럼), 서포트 없이 — 시험 자체가 서포트 없는 브리지 | PETG, 생산 프레임과 같은 슬라이서 설정 (층·벽·채움 그대로), 서포트 없음 | 53.5 × 65.5 × 25.4 | 30.3 | 2560 |
| C12a | 층간 인장 쿠폰 (핀 두께 1.8 × 폭 2.0, 3개) | 15 | 바로 세워 (당김 방향 = 층을 가로지름, 프레임 핀과 같음); 끝 구멍은 눈물방울 | PETG, 생산 프레임과 같은 슬라이서 설정 (층·벽·채움 그대로), 서포트 없음 | 60.0 × 8.0 × 45.0 | 9.1 | 0 |
| C13a | USB-C 몰드 게이지 (12.5 × 7.6 × 25) | 19 | 창이 수직이 되게 세워 (xy 정밀도) | PETG, 0.2 층, 벽 3, 윗/아랫면 5층, 채움 40 % 자이로이드, 서포트 없음 | 20.5 × 15.6 × 25.0 | 5.6 | 0 |
| C14a | 추 컵 (DW·스프링·캡스턴 토크) | 7 | 바닥을 베드에 | PETG, 0.2 층, 벽 3, 윗/아랫면 5층, 채움 40 % 자이로이드, 서포트 없음 | 31.0 × 26.0 × 18.0 | 2.5 | 0 |
| C15a | 앞 펠트 반발 낙하관 (Ø19.05 강철 공) | 4 | 바닥을 베드에 (관이 수직) | PETG, 0.2 층, 벽 3, 윗/아랫면 5층, 채움 40 % 자이로이드, 서포트 없음 | 44.0 × 44.0 × 151.8 | 31.2 | 33 |
| C16a | 레버 캐리어 (C 자리, 생산 부품 그대로, 3개) | 20 | 생산처럼 옆벽을 베드에 (허브 구멍이 세로), 강철 칸 안 지지대 1개(z 틈 0.2) — 생산 캐리어와 같은 설정 | PETG, 생산 캐리어와 같은 슬라이서 설정 | 59.4 × 23.8 × 11.6 | 2.7 | 790 |
| C16b | 강철 누름 받침 (옆벽을 받치고 가운데 9.6 홈으로 강철이 내려감) | 20 | 바닥을 베드에 | PETG, 0.2 층, 벽 3, 윗/아랫면 5층, 채움 40 % 자이로이드, 서포트 없음 | 40.0 × 46.0 × 8.0 | 11.2 | 0 |
| C17a | 정하중 받침 빗 (핀 선 4줄 + 뒷벽, 레일 밑은 빔) | 21 | 납작하게 (어느 면이든 베드에) | PETG, 0.2 층, 벽 3, 윗/아랫면 5층, 채움 40 % 자이로이드, 서포트 없음 | 164.5 × 212.0 × 3.0 | 9.0 | 0 |

브리지 칸이 0이 아닌 것은 짧은 천장뿐이다: C08a 너트 홈 천장 5.6~5.8, C09a 다리 윗판 26, C09b 강철 자리 9.5, C07b Ø2.4 구멍 천장, C15a 창 윗변 6, C06a 홈 보스. 45°보다 가파른 내민 면은 C03d·e의 가로 M3 구멍(Ø2.7/3.3)과 C15a 꼬치 구멍(Ø3.3)뿐이다. 모든 STL은 닫힌 몸(watertight)이다.

공통: Ø3.9로 출력한 봉 구멍(C01a·b·d, C06a)은 Ø4.0 드릴로 뚫는다(모델 S11과 같음). 봉을 끼우는 구멍에는 흑연 가루를 조금 넣는다(모델 레버와 같은 마찰).

## 3. 시험 절차

### 시험 1 — 패드 반발 (가장 먼저)

**무엇을 재나.** 모델의 `pad_e`는 ‘레버 혼자, 단단한 자리 위의 패드를 PLAY 각속도(건반 앞 1.5 m/s → 레버 31.9 rad/s)로 칠 때의 실효 반발계수’다(`PadTable.calibrate`). C01은 이것을 그대로 만든다: 모델 레버와 같은 자리(봉 L 기준 y150~190, z33~52)에 강철을 잡은 시험 레버(C01b, 강철 포함 58.0 g, 무게중심 반지름 33.01, 봉 둘레 관성 75672 g·mm² — 모델 레버 57.0 g, 75529 g·mm²)를 모델의 패드 면 자리에 놓은 패드에 **중력으로** 떨어뜨린다. 받침은 모델 좌표를 115.3° 돌려, 패드에 처음 닿는 각(b0 = 10.45°)에서 레버 무게중심이 봉 바로 아래에 오게 했다. 그래서 닿는 순간이 흔들림의 맨 아래이고, 되튄 높이(각)만 읽으면 e가 나온다.

**시편.** C01a 받침(봉 구멍·눈금 θ −20~160°, 2° 눈금·20°마다 숫자·패드 블록), C01b 시험 레버, C01c 패드 받침판(후보마다 1개), C01d 칼라, Ø4 봉 24, 강철 블록 1, 후보 패드(6×12).

**준비.**
1. C01a·C01b·C01d 구멍을 Ø4.0으로 뚫는다. 봉(24)을 C01a 뒷면에서 밀어 넣는다(뒷면과 같은 면, 보스 앞면에서 14 나옴). 헐거우면 순간접착제.
2. 강철 블록을 C01b 칸에 옆에서 밀어 넣어 양면을 같게 하고 순간접착제 한 방울로 고정한다. **C01b를 출력할 때 베드에 닿았던 면이 브래킷 쪽**이다(뒤집으면 강철 윗면이 패드 반대쪽을 본다).
3. 봉에 흑연 가루, C01b를 끼우고(허브가 보스 Ø12에 닿음) C01d로 막는다(축 방향 놀음 1 mm 이하).
4. 패드(폼 6T + 펠트 1T, 생산과 같은 풀)를 C01c 표시 자리(6×12)에 펠트가 바깥으로 오게 붙인다. C01c를 C01a 패드 블록 홈에 위에서 끝까지 밀어 넣는다.
5. 받침을 평평한 탁자에 두고 레버가 늘어진 채 패드에 **막 닿는지** 본다: 영수증 종이(0.05)를 강철과 패드 사이에 넣고 당기면 살짝 끌려야 한다. 떨어져 있으면 C01c 뒤에 PET 심(0.1)을 넣고, 눌려 있으면(레버가 패드에 밀려 기울면) C01c 뒷면을 사포질한다. 이때 지침이 가리키는 값 θ_h를 적는다(설계 0°, 모든 읽음에서 뺀다).
6. 휴대폰을 눈금판에 수직으로 30 cm 앞에 고정한다(240 fps).

**마찰 보정 (패드 없이).** C01c를 뺀다. 레버를 θ0 = 6°에서 놓는다(**7°를 넘기지 말 것** — 반대쪽 -8°에서 패드 블록과 1 mm 안으로 들어온다). 영상에서 연속한 꼭짓점 각 a0, a1, a2, a3, a4(양쪽 번갈아)를 읽는다. 반 흔들림마다 줄어드는 각 Δ = (a0 − a4)/4 (라디안으로 바꿈), 마찰 비 f = Δ/2. 봉 마찰 0.28 N·mm(μ 0.25)이면 Δ ≈ 1.7°.

**반발.** C01c(패드)를 다시 넣는다. θ0 = 90°, 120°, 150°에서 각각 3번 놓는다(강철 쪽 틀을 손가락으로 잡았다 뗌; 150°는 거의 거꾸로 선 자세). 영상에서 실제 놓은 각 θ0(움직이기 시작한 첫 프레임)과 **첫 되튐의 꼭짓점 각 θr**을 읽는다(둘 다 θ_h를 뺀 값).

**계산.** e = √{[(1 − cos θr) + f·θr] / [(1 − cos θ0) − f·θ0]} (f 항의 각은 라디안). 레버 질량·무게중심은 식에서 지워진다. 판정 값은 θ0 150°(모델 PLAY 각속도의 96 %)의 평균이다. 90° → 150°로 e가 커지면(속도 의존) 150° 값을 직선으로 PLAY 속도(100 %)까지 늘려 쓴다.

마찰이 없을 때 e별 되튐 각 θr (도):

| θ0 | 충돌 각속도 (rad/s, PLAY 대비) | e 0.04 | e 0.05 | e 0.06 | e 0.07 | e 0.08 | e 0.10 | e 0.12 | e 0.15 | e 0.20 | e 0.25 | e 0.30 |
|---|---|---|---|---|---|---|---|---|---|---|---|---|
| 60° | 15.8 (49 %) | 2.3 | 2.9 | 3.4 | 4.0 | 4.6 | 5.7 | 6.9 | 8.6 | 11.5 | 14.4 | 17.3 |
| 90° | 22.3 (70 %) | 3.2 | 4.1 | 4.9 | 5.7 | 6.5 | 8.1 | 9.7 | 12.2 | 16.3 | 20.4 | 24.5 |
| 120° | 27.3 (86 %) | 4.0 | 5.0 | 6.0 | 7.0 | 7.9 | 9.9 | 11.9 | 14.9 | 19.9 | 25.0 | 30.1 |
| 150° | 30.4 (96 %) | 4.4 | 5.5 | 6.6 | 7.8 | 8.9 | 11.1 | 13.3 | 16.7 | 22.3 | 27.9 | 33.7 |

**합격: e ≤ 0.07** (설계 0.06). 모델 확인: 패드 표가 설계 e에서 되돌린 값 0.060.

**결과에 따라** (모델 `metrics.json` `sens`):

| 측정 e | 판정 | 모델에서 바꿀 것 | 모델 결과 (백 / 흑) |
|---|---|---|---|
| e ≤ 0.07 | 통과 | pad_e = 측정값 | 모델 'pad e 0.07': 들림 0.142 / 0.061, ABUSE 0.138 / 0.239, 연타 16.3 / 18.9 Hz |
| 0.07 < e ≤ 0.10 | 조건부 | pad_e = 측정값, 다른 합격선(E·앞 펠트)은 공칭이어야 | 모델 'pad e 0.10': 백 들림 0.153, 흑 ABUSE 0.333, 연타 16.6 / 19.3 Hz; 최악 조합이면 백 PLAY 들림 0.204 > 0.20 |
| 0.10 < e ≤ 0.15 | 대안 ① | 대안 ①: gap_us_w −0.40 → −0.60, gap_us_b −0.45 → −0.65 (PET 심 2장 더), pad_E 1.4 | 모델 대안 ①(e 0.15): 들림 0.116 / 0.043, ABUSE 0.198 / 0.197, 연타 17.6 / 20.8 Hz |
| e > 0.15 | 불합격 | 다른 패드 후보 (② 점탄성 PU, ③ 부틸 1T 덧댐) | 모델 e 0.25: 백 들림 0.208, 백 ABUSE 키퍼 -0.16(닿음), 흑 ABUSE 0.400 |

민감도(한 가지만 바꿈, 백 / 흑): e 0.06 → 0.07 → 0.10 → 0.15 → 0.25에서 PLAY 들림 0.139 / 0.142 / 0.153 / 0.177 / 0.208, 흑 ABUSE 들림 0.183 / 0.239 / 0.333 / 0.398 / 0.400, 백 0.45 N 유령 재무장 0.17 / 0.22 / 0.47 / 0.98 / 1.00 (모두 펌웨어가 거름), 연타 백 16.3 / 16.3 / 16.6 / 16.8 / 17.0 Hz.

참고: DESIGN D11의 ‘캡 모양 60 g 추를 2.5 m/s로 떨어뜨림’은 17장(레버를 PLAY 속도로 휘두름)과 다르다. 모델의 `pad_e` 정의는 17장 쪽이므로 이 키트는 C01을 기준 방법으로 한다(D11 문구는 다음 개정에서 17장에 맞출 것).

| 기록 | θ0 90° | θ0 120° | θ0 150° |
|---|---|---|---|
| θr 1 / 2 / 3회 (°) |  |  |  |
| e (마찰 보정) |  |  |  |

### 시험 2 — 패드 강성

**모델.** 폼 법칙 σ = E·ε / (1 − ε/ε_D), E 1.0 MPa(펠트 면 포함), ε_D 0.8, 패드 6×12×7. 25 % 압축(1.75 mm)에서 σ 0.364 MPa = 26.2 N.

**방법.** C02a 바탕 자리(6.4×12.4×1)에 패드를 펠트가 위로 가게 놓고 C02b 누름 막대를 통에 넣는다. C02b 무게 m_p를 잰다. 버니어 깊이 막대를 C02b 모서리 Ø4.2 구멍으로 넣어 C02a 바탕 윗면까지의 깊이 D0를 잰다. 추(주방 저울로 잰 쌀 봉지·물병) 0.5 / 1.0 / 1.5 / 2.0 / 2.5 / 3.0 / 3.5 kg을 받침판 가운데에 차례로 올리고, 30초 기다린 뒤 D를 잰다. 눌림 d = D0 − D, 힘 F = (추 + m_p)·9.81/1000 N. 마지막에 추를 모두 내리고 1분 뒤 D를 다시 잰다(영구 눌림).

| 눌림 d (mm) | ε | F (N), E 0.7 | E 1.0 (설계) | E 1.4 |
|---|---|---|---|---|
| 0.35 | 0.05 | 2.7 | 3.8 | 5.4 |
| 0.70 | 0.10 | 5.8 | 8.2 | 11.5 |
| 1.05 | 0.15 | 9.3 | 13.3 | 18.6 |
| 1.40 | 0.20 | 13.4 | 19.2 | 26.9 |
| 1.75 | 0.25 | 18.3 | 26.2 | 36.7 |
| 2.10 | 0.30 | 24.2 | 34.6 | 48.4 |

**계산.** d = 1.75에서의 F를 이웃 두 점으로 보간 → σ25 = F/72 MPa → E = σ25 × (1 − 0.25/0.8)/0.25 = 2.750 × σ25. **합격: E 0.7~1.4 MPa (F25 18.3~36.7 N).**

- E < 0.7 → 두꺼운/단단한 등급 (모델 'pad E 0.7': 흑 ABUSE 들림 0.310)
- 0.7 ≤ E ≤ 1.4 → pad_E = 측정값 (통과)
- E > 1.4 → pad_E = 측정값, 윗판 하중 다시 (모델 'pad E 1.4': 백 업스톱 힘 104.2 N (설계 89.3))
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

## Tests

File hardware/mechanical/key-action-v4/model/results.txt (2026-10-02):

====================================================================================================
A. PLAN LAYOUT - lever centres, fins, hub collars, pad bars (module x, 0 = C left boundary)
====================================================================================================
white head width 22.04, head gap 1.46; white-white tail gap 1.64; black base 10.4, top 9.5
key head x           tail x           tail c   lever c  offset   beam/block x       collars L/R   
C   0.73-22.77       0.820-14.361     7.431    8.525    +1.09    4.53-12.53         0.00 / 0.95
C#  16.02-26.41      16.015-26.415    21.215   21.215   +0.00    17.21-25.21        0.95 / 1.02
D   24.23-46.27      28.069-42.431    35.250   34.035   -1.22    30.03-38.03        1.02 / 0.00
D#  44.08-54.48      44.085-54.485    49.285   49.285   +0.00    45.28-53.28        0.00 / 1.50
E   47.73-69.77      56.139-69.680    63.070   63.070   +0.00    59.07-67.07        1.50 / 0.93
F   71.23-93.27      71.320-83.719    77.359   75.693   -1.67    71.69-79.69        0.93 / 0.00
F#  85.37-95.77      85.373-95.773    90.573   90.943   +0.37    86.94-94.94        0.00 / 1.16
G   94.73-116.77     97.427-110.646   104.037  104.037  +0.00    100.04-108.04      1.16 / 0.76
G#  112.30-122.70    112.300-122.700  117.500  116.300  -1.20    112.30-120.30      0.76 / 0.00
A   118.23-140.27    124.354-137.573  130.964  131.550  +0.59    127.55-135.55      0.00 / 0.76
A#  139.23-149.63    139.227-149.627  144.427  143.800  -0.63    139.80-147.80      0.76 / 0.76
B   141.73-163.77    151.281-163.680  157.641  155.975  -1.67    151.97-159.97      0.76 / 0.00
fins: x0.20-1.80, x40.76-42.56, x82.42-84.22, x123.03-124.83, x162.70-164.30 (end fins 1.6, interior 1.8: D|D#, F|F#, G#|A)
lever-rod spans between fins: 40.7, 41.7, 40.6, 39.6 (max 41.7)
gaps along the rod: 1.43, 2.09, 2.22, 1.43, 1.43, 3.19, 2.02, 1.43, 1.43, 2.49, 1.66, 1.43, 1.43, 1.65, 1.57, 1.43
r3 C-rings -> hub collars: every lever-lever ring (>= 1.50 + axial play share) split in half onto the two hubs; lever-fin rings = fin bosses (one-sided at the ends) 0.00/1.37, 1.37/1.37, 1.37/1.37, 1.37/1.37, 1.37/0.00
largest lever offset: 1.67 mm from the v3 sensor centre, 1.83 mm from the actual tail centre (beam and balance block follow the lever, inside the tail)
pad bars (one per fin bay, 3 pads each): x3.10-39.46, x43.86-81.12, x85.52-121.73, x126.12-161.40

====================================================================================================
B. CAPSTANS AND STATICS (DW target white 52.0 g at y13, black 51.0 g at front + 10; friction at every contact; torsion assist spring k_t 8.44 N mm/rad, free angle -28.45 deg)
====================================================================================================
per-key capstan solve: C 188.34, C# 180.31, D 188.36, D# 180.31, E 188.34, F 188.33, F# 180.31, G 188.34, G# 180.31, A 188.34, A# 180.31, B 188.32
common capstan y: white 188.34, black 180.31 (M3x6 ISO 7380 button head, crown z31.0)
C   key PETG 21.81 g  BW 47.42 DW 51.99 UW 42.85 fric 4.57 m_eff 55.2
C#  key PETG 16.78 g  BW 45.91 DW 51.01 UW 40.80 fric 5.11 m_eff 46.5
D   key PETG 22.14 g  BW 47.35 DW 51.92 UW 42.78 fric 4.57 m_eff 55.2
D#  key PETG 16.78 g  BW 45.91 DW 51.01 UW 40.80 fric 5.11 m_eff 46.5
E   key PETG 21.80 g  BW 47.41 DW 51.98 UW 42.84 fric 4.57 m_eff 55.2
F   key PETG 21.32 g  BW 47.50 DW 52.07 UW 42.93 fric 4.57 m_eff 55.1
F#  key PETG 16.76 g  BW 45.89 DW 51.00 UW 40.79 fric 5.11 m_eff 46.5
G   key PETG 21.67 g  BW 47.44 DW 52.01 UW 42.87 fric 4.57 m_eff 55.2
G#  key PETG 16.78 g  BW 45.91 DW 51.01 UW 40.80 fric 5.11 m_eff 46.5
A   key PETG 21.68 g  BW 47.44 DW 52.01 UW 42.88 fric 4.57 m_eff 55.2
A#  key PETG 16.78 g  BW 45.91 DW 51.01 UW 40.80 fric 5.11 m_eff 46.5
B   key PETG 21.35 g  BW 47.51 DW 52.08 UW 42.95 fric 4.57 m_eff 55.1
white (D): key 23.41 g (PETG 22.14), lever 56.95 g (steel 53.69, carrier 2.84); I_key 143540, I_lever 75529 g mm2
   BW 47.35 DW 51.92 UW 42.78 friction 4.57 = key rod 0.88 + lever rod 1.20 + capstan 0.57 + guide 1.93; m_eff 55.2 (key 8.8 + lever 46.5); capstan N 1.504
   spring torque rest 4.19 / bottom 6.03 N mm; the spring gives 11.2 g of the 51.9 g DW (without it DW 40.7)
   friction x2: DW 56.49 UW 38.21; stroke -> DW/UW (friction, capstan part, spring N mm): 0.00: 51.9/42.8 (4.6, 0.6, 4.19); 0.25: 53.5/41.7 (5.9, 1.8, 4.66); 0.50: 54.4/39.9 (7.2, 3.2, 5.13); 0.75: 54.5/37.6 (8.5, 4.4, 5.59); 1.00: 54.0/34.7 (9.7, 5.7, 6.03)
   friction x2 along the stroke DW/UW: 0.00: 56.5/38.2; 0.25: 59.4/35.8; 0.50: 61.6/32.7; 0.75: 63.0/29.1; 1.00: 63.7/25.0
black (C#): key 18.04 g (PETG 16.78), lever 56.95 g (steel 53.69, carrier 2.84); I_key 45650, I_lever 75529 g mm2
   BW 45.91 DW 51.01 UW 40.80 friction 5.11 = key rod 1.08 + lever rod 0.48 + capstan 2.06 + guide 1.48; m_eff 46.5 (key 7.9 + lever 38.6); capstan N 0.977
   spring torque rest 4.19 / bottom 5.69 N mm; the spring gives 10.4 g of the 51.0 g DW (without it DW 40.6)
   friction x2: DW 56.12 UW 35.69; stroke -> DW/UW (friction, capstan part, spring N mm): 0.00: 51.0/40.8 (5.1, 2.1, 4.19); 0.25: 51.2/38.7 (6.2, 3.2, 4.58); 0.50: 50.9/36.3 (7.3, 4.3, 4.96); 0.75: 50.0/33.5 (8.3, 5.3, 5.33); 1.00: 48.7/30.5 (9.1, 6.3, 5.69)
   friction x2 along the stroke DW/UW: 0.00: 56.1/35.7; 0.25: 57.4/32.5; 0.50: 58.2/29.0; 0.75: 58.3/25.2; 1.00: 57.9/21.3
white lip y0: DW 47.12 (band at y13 like v3); y90: DW 131.00 -> front/back ratio 2.52
torsion spring C-UA90R5-3-0.5 (SUS304-WPB d0.50 ID 5.0, 3.25 body turns, E 186000 from the catalogue rates): coil body rate 10.16 N mm/rad, with the cut legs 22.1 / 8.0 (N_e 3.914) k_t 8.437 N mm/rad = 0.1473 /deg (catalogue 0.1368 /deg with legs 25 / 25, this model 0.1368), C 11.0, K_i 1.073; free angle -28.45 deg (same b = 0 torque 4.189 N mm as D05); rest b 0.02 wound 28.5 deg 4.19 N mm 366 MPa, bottom b 12.64 wound 41.1 deg 6.03 N mm 527 MPa, service b 16.00 wound 44.4 deg 6.52 N mm 570 MPa, hand 25 deg b 25.00 wound 53.4 deg 7.83 N mm 685 MPa (Su 2150: 32 %); ID at the bottom 4.83 / hand lift 4.78 on the D4 rod; catalogue max-use 55 deg = 7.52 N mm (658 MPa): hand lift 53.4 deg, 104 % of that torque; one cut spring 0.134 g (wire 86.3 mm)
r4.5 fix 2 coil float on the D4 rod (ID 5.0): short leg / notch -> rest / bottom torque, unwind, coil shift (dir), rod force rest / bottom, hysteresis mu N r at the bottom -> D DW / DW lip y0 / UW, C# DW / UW; friction x2 D DW, C# UW at the bottom:
   r4.5 as built (short leg 2.5 on one face), mu 0.0          T 2.18 / 4.15 N mm, unwind 13.4 deg, shift 0.47 (54 deg), N 1.18 / 2.22 N, H 0.00 N mm -> D 46.5 / 42.2 / 38.0, C# 46.0 / 36.5; x2: D DW 50.8, C# UW bottom 18.9
   notch rotated -12.9 deg (short leg 2.5), mu 0.0            T 4.19 / 6.16 N mm, unwind 13.4 deg, shift 0.44 (41 deg), N 2.23 / 3.23 N, H 0.00 N mm -> D 51.9 / 47.1 / 42.8, C# 51.0 / 40.8; x2: D DW 56.5, C# UW bottom 21.5
   notch rotated -12.9 deg (short leg 2.5), mu 0.1            T 4.19 / 6.16 N mm, unwind 13.4 deg, shift 0.44 (41 deg), N 2.23 / 3.23 N, H 0.65 N mm -> D 53.0 / 48.1 / 41.6, C# 52.0 / 39.8; x2: D DW 58.8, C# UW bottom 19.0
   notch rotated -12.9 deg (short leg 2.5), mu 0.3            T 4.19 / 6.16 N mm, unwind 13.4 deg, shift 0.44 (41 deg), N 2.23 / 3.23 N, H 1.94 N mm -> D 55.3 / 50.2 / 39.4, C# 54.1 / 37.7; x2: D DW 63.3, C# UW bottom 14.2
   short leg 5.0 + notch rotated -5.6 deg, mu 0.0             T 4.19 / 6.13 N mm, unwind 5.8 deg, shift 0.44 (55 deg), N 0.76 / 1.07 N, H 0.00 N mm -> D 51.9 / 47.1 / 42.8, C# 51.0 / 40.8; x2: D DW 56.5, C# UW bottom 21.4
   short leg 5.0 + notch rotated -5.6 deg, mu 0.1             T 4.19 / 6.13 N mm, unwind 5.8 deg, shift 0.44 (55 deg), N 0.76 / 1.07 N, H 0.21 N mm -> D 52.3 / 47.5 / 42.4, C# 51.4 / 40.4; x2: D DW 57.3, C# UW bottom 20.6
   short leg 5.0 + notch rotated -5.6 deg, mu 0.3             T 4.19 / 6.13 N mm, unwind 5.8 deg, shift 0.44 (55 deg), N 0.76 / 1.07 N, H 0.64 N mm -> D 53.1 / 48.2 / 41.6, C# 52.1 / 39.7; x2: D DW 58.8, C# UW bottom 19.0
   r4.5 fix 2 captured short leg 8.0 (groove 0.70)            T 4.19 / 6.03 N mm, unwind 0.0 deg, shift 0.00 (0 deg), N 0.00 / 0.00 N, H 0.00 N mm -> D 51.9 / 47.1 / 42.8, C# 51.0 / 40.8; x2: D DW 56.5, C# UW bottom 21.3
r4.5 fix 2 captured short leg: groove 0.70 (play 0.20), leg cocked 1.99 deg in it, contacts arm 5.75 -> couple 0.73 N at rest; coil off the rod 0.435 (rest) / 0.379 (bottom) / 0.326 (hand 25 deg); groove printed dp (both faces dp/2): -0.20 -> -1.99 deg, rest 4.48 N mm, rod gap 0.26, -0.15 -> -1.49 deg, rest 4.41 N mm, rod gap 0.30, -0.10 -> -1.00 deg, rest 4.34 N mm, rod gap 0.35, +0.00 -> 0.00 deg, rest 4.19 N mm, rod gap 0.43, +0.10 -> 1.00 deg, rest 4.04 N mm, rod gap 0.35, +0.20 -> 2.00 deg, rest 3.89 N mm, rod gap 0.26, +0.30 -> 3.00 deg, rest 3.75 N mm, rod gap 0.17
r4.5 fix 2 captured leg, long-leg reaction along the groove: b 0.0: 0.145 N of 0.199 toward the blind end -> friction needed 0.100 (2 contacts x 0.73 N); slid 0.3 onto the blind end: rod gap 0.435 -> 0.135; b 12.6: 0.161 N of 0.287 toward the blind end -> friction needed 0.077 (2 contacts x 1.05 N); slid 0.3 onto the blind end: rod gap 0.379 -> 0.079; b 25.0: 0.139 N of 0.373 toward the blind end -> friction needed 0.051 (2 contacts x 1.36 N); slid 0.3 onto the blind end: rod gap 0.326 -> 0.026

====================================================================================================
C. HEIGHTS - truly settled 1 N bottom, pad faces, pad bar seat, top plate, curtain, shelf, keeper
====================================================================================================
cap top at the bottom: rigid 63.77 (white) / 61.83 (black); rigid - capstan-felt set 63.19 / 61.56; TRULY settled 4-DOF state held at 1 N (no pad): 62.73 / 61.30, |w| at the end 4.6e-09 rad/ms
   (key front held at 1 N: white z33.46, black z45.94; lever angle held 11.36 / 9.63 deg)
white pad: face parallel to the steel top at 11.36 deg, -0.40 along its normal (lever first when negative); face at y170 z58.64 / y182 z56.23; first contact at 10.45 deg; damping c 16.39 for e 0.060
black pad: face parallel to the steel top at 9.63 deg, -0.45 along its normal (lever first when negative); face at y170 z57.45 / y182 z55.41; first contact at 8.58 deg; damping c 16.55 for e 0.060
pad 6T foam + 1T felt (E 1.0 MPa: 0.36 MPa at 25 %), 6 wide, y170-182; wedges white 0.35-2.76, black 1.50-3.54; pad bar 1.5: seat (bar top) z67.35, front part in the plate channel z67.35-68.85
top plate: top z72.85 (= seat + 5.5), front channel underside z68.85, pad zone z67.35, behind the pads z60.85 (thickness 12.0); nothing above it (r3 cover z78.0, heads z80.7; v3 z59)
lever extremes from all dynamic cases: max b 12.91 / 10.85 deg (sweep 'ff' +0.25), return overshoot -2.85 / -1.81, settled rest -1.09 / -0.55; key max 4.32 / 6.66 deg, max rise above rest -0.42 / -0.32 deg
real bottom (1 N, pad present): white lever 10.75 deg, key front z33.50 (+0.04 above its felt); black 8.97 deg, z46.21 (+0.27)
balance rail: lowered to z19.0 under the blocks (lowest block corner over all poses z20.38), rod cradles between the blocks (x clearance 1.48), saddle lip z20.5
rear shelf top z20.054; keeper felt underside z26.60 (crossbar + 1.5); curtain strip bottom z45.5 (white) / z57.5 (black notches)

====================================================================================================
D. SENSOR (magnet D5x2 at y67)
====================================================================================================
white: rest gap 10.82, bottom 5.60, max over-travel (2.5 m/s abuse) 5.24, travel 5.22, y shift 0.04; 50% re-arm = 2.61 mm rise
black: rest gap 13.35, bottom 5.32, max over-travel (2.5 m/s abuse) 4.76, travel 8.03, y shift 0.22; 50% re-arm = 4.02 mm rise

====================================================================================================
E. DYNAMICS - 4-DOF (free key on the cloth-lined snap notch with lip friction + keeper + lever with torsion spring), flat foam pad on the steel top in series with its seat (1490 N/mm = weakest key of the plate FE), Flores contact law, dt 4 us
====================================================================================================
load envelopes (R4 brief): PLAY = key-FRONT speed 1.5 m/s at the felt contact (Askenfelt & Jansson 1991: forte key speed seldom above 1 m/s; Goebl et al. 2005: loudest struck attacks 6.4-7.8 m/s hammer = about 1.3-1.6 m/s at the key with the ~5x ratio); ABUSE = 2.5 m/s single, 2.0 m/s 6-key chord
  contact front    K 30 N/mm^1.5, design (effective) e 0.20 -> Flores input 0.245 -> simulated drop restitution 0.200
  contact front_b  K 20 N/mm^1.5, design (effective) e 0.20 -> Flores input 0.245 -> simulated drop restitution 0.200
  contact rest     K 30 N/mm^1.5, design (effective) e 0.35 -> Flores input 0.388 -> simulated drop restitution 0.350
  contact cap      K 20 N/mm^1.5, design (effective) e 0.35 -> Flores input 0.388 -> simulated drop restitution 0.350
  contact keeper   K 20 N/mm^1.5, design (effective) e 0.35 -> Flores input 0.388 -> simulated drop restitution 0.350
  contact cloth    K 120 N/mm^1.5, design (effective) e 0.30 -> Flores input 0.341 -> simulated drop restitution 0.300
white settled rest: key front z43.497, keeper gap 1.509, lever -1.090 deg (capstan felt set), rod penetration 0.031; finger-start speed for PLAY 0.933, ABUSE 1.920, 1.0 m/s 0.149, 2.0 m/s 1.483 m/s
   PLAY 1.5 m/s front, let go             front 1.50 m/s | lift 0.136 (lip pull 0.90 N) | pad 89 N (comp 0.76, seat 0.06) | front felt 38 N | capstan 12.6 N | keeper gap 0.57 | rod 27 N | ghost: rise 0.00, magnet 0 %, desc 0.00 m/s
   PLAY 1.5 m/s front, hold 0.45 N        front 1.50 m/s | lift 0.000 (lip pull 0.87 N) | pad 89 N (comp 0.76, seat 0.06) | front felt 38 N | capstan 8.4 N | keeper gap 1.51 | rod 27 N | ghost: rise 2.18, magnet 17 %, desc 0.00 m/s
   PLAY 1.5 m/s front, hold 0.50 N        front 1.50 m/s | lift 0.000 (lip pull 0.87 N) | pad 89 N (comp 0.76, seat 0.06) | front felt 38 N | capstan 8.4 N | keeper gap 1.51 | rod 27 N | ghost: rise 1.57, magnet 11 %, desc 0.02 m/s
   PLAY 1.5 m/s front, hold 0.55 N        front 1.50 m/s | lift 0.000 (lip pull 0.87 N) | pad 89 N (comp 0.76, seat 0.06) | front felt 38 N | capstan 8.4 N | keeper gap 1.51 | rod 27 N | ghost: rise 1.28, magnet 8 %, desc 0.03 m/s
   PLAY 1.5 m/s front, hold 0.60 N        front 1.50 m/s | lift 0.000 (lip pull 0.87 N) | pad 89 N (comp 0.76, seat 0.06) | front felt 38 N | capstan 8.4 N | keeper gap 1.51 | rod 27 N | ghost: rise 1.10, magnet 6 %, desc 0.02 m/s
   PLAY 1.5 m/s front, hold 0.80 N        front 1.50 m/s | lift 0.000 (lip pull 0.86 N) | pad 89 N (comp 0.76, seat 0.06) | front felt 38 N | capstan 8.4 N | keeper gap 1.51 | rod 27 N | ghost: rise 0.74, magnet 2 %, desc 0.00 m/s
   PLAY 1.5 m/s front, hold 1.00 N        front 1.50 m/s | lift 0.000 (lip pull 0.85 N) | pad 89 N (comp 0.76, seat 0.06) | front felt 38 N | capstan 8.4 N | keeper gap 1.51 | rod 27 N | ghost: rise 0.56, magnet 0 %, desc 0.00 m/s
   PLAY 1.5 m/s front, hold 2.00 N        front 1.50 m/s | lift 0.000 (lip pull 0.80 N) | pad 89 N (comp 0.76, seat 0.06) | front felt 38 N | capstan 8.4 N | keeper gap 1.51 | rod 27 N | ghost: rise 0.37, magnet 0 %, desc 0.00 m/s
   ABUSE 2.5 m/s front, let go            front 2.50 m/s | lift 0.135 (lip pull 2.06 N) | pad 145 N (comp 1.25, seat 0.10) | front felt 69 N | capstan 14.2 N | keeper gap 0.53 | rod 44 N | ghost: rise 0.00, magnet 0 %, desc 0.00 m/s
   ABUSE 2.5 m/s front, hold 0.45 N       front 2.50 m/s | lift 0.038 (lip pull 2.06 N) | pad 145 N (comp 1.25, seat 0.10) | front felt 69 N | capstan 8.7 N | keeper gap 1.51 | rod 44 N | ghost: rise 6.37, magnet 57 %, desc 0.00 m/s
   ABUSE 2.5 m/s front, hold 0.60 N       front 2.50 m/s | lift 0.038 (lip pull 2.06 N) | pad 145 N (comp 1.25, seat 0.10) | front felt 69 N | capstan 8.7 N | keeper gap 1.51 | rod 44 N | ghost: rise 2.15, magnet 14 %, desc 0.06 m/s
   ABUSE 2.5 m/s front, hold 1.00 N       front 2.50 m/s | lift 0.039 (lip pull 2.06 N) | pad 145 N (comp 1.25, seat 0.10) | front felt 69 N | capstan 8.7 N | keeper gap 1.51 | rod 44 N | ghost: rise 0.88, magnet 2 %, desc 0.00 m/s
   ABUSE 2.5 m/s front, hold 2.00 N       front 2.50 m/s | lift 0.048 (lip pull 2.06 N) | pad 145 N (comp 1.25, seat 0.10) | front felt 69 N | capstan 8.7 N | keeper gap 1.51 | rod 44 N | ghost: rise 0.63, magnet 0 %, desc 0.00 m/s
   push 0.8 N                             front 0.07 m/s | lift 0.096 (lip pull 0.00 N) | pad 15 N (comp 0.24, seat 0.01) | front felt 0 N | capstan 13.0 N | keeper gap 0.70 | rod 10 N | ghost: rise 0.21, magnet 1 %, desc 0.00 m/s
   push 1.5 N                             front 0.62 m/s | lift 0.091 (lip pull 0.00 N) | pad 27 N (comp 0.35, seat 0.02) | front felt 13 N | capstan 13.1 N | keeper gap 0.72 | rod 10 N | ghost: rise 0.17, magnet 0 %, desc 0.00 m/s
   push 3 N                               front 0.99 m/s | lift 0.091 (lip pull 0.00 N) | pad 53 N (comp 0.52, seat 0.04) | front felt 24 N | capstan 13.2 N | keeper gap 0.72 | rod 16 N | ghost: rise 0.20, magnet 0 %, desc 0.00 m/s
   push 6 N                               front 1.46 m/s | lift 0.162 (lip pull 1.57 N) | pad 86 N (comp 0.74, seat 0.06) | front felt 40 N | capstan 16.3 N | keeper gap 0.52 | rod 26 N | ghost: rise 0.23, magnet 0 %, desc 0.00 m/s
   1.0 m/s front, let go                  front 1.00 m/s | lift 0.112 (lip pull 0.36 N) | pad 55 N (comp 0.53, seat 0.04) | front felt 24 N | capstan 13.6 N | keeper gap 0.64 | rod 17 N | ghost: rise 0.00, magnet 0 %, desc 0.00 m/s
   2.0 m/s front, let go                  front 2.00 m/s | lift 0.159 (lip pull 1.67 N) | pad 119 N (comp 1.03, seat 0.08) | front felt 53 N | capstan 12.3 N | keeper gap 0.49 | rod 36 N | ghost: rise 0.00, magnet 0 %, desc 0.00 m/s
   ff_h1.00                               front 1.00 m/s | lift 0.000 (lip pull 0.00 N) | pad 55 N (comp 0.53, seat 0.04) | front felt 24 N | capstan 8.1 N | keeper gap 1.51 | rod 17 N | ghost: rise 0.38, magnet 0 %, desc 0.00 m/s
   chord20_h1.00                          front 2.00 m/s | lift 0.016 (lip pull 1.67 N) | pad 119 N (comp 1.03, seat 0.08) | front felt 53 N | capstan 8.6 N | keeper gap 1.51 | rod 36 N | ghost: rise 0.76, magnet 1 %, desc 0.00 m/s
   1.5 m/s at the FINGER start, let go    front 2.02 m/s | lift 0.160 (lip pull 1.67 N) | pad 120 N (comp 1.04, seat 0.08) | front felt 53 N | capstan 12.3 N | keeper gap 0.48 | rod 36 N | ghost: rise 0.00, magnet 0 %, desc 0.00 m/s
   1.5 m/s finger, hold 0.45 N            front 2.02 m/s | lift 0.016 (lip pull 1.67 N) | pad 120 N (comp 1.04, seat 0.08) | front felt 53 N | capstan 8.6 N | keeper gap 1.51 | rod 36 N | ghost: rise 3.92, magnet 33 %, desc 0.00 m/s
   1.5 m/s finger, hold 1 N               front 2.02 m/s | lift 0.017 (lip pull 1.67 N) | pad 120 N (comp 1.04, seat 0.08) | front felt 53 N | capstan 8.6 N | keeper gap 1.51 | rod 36 N | ghost: rise 0.75, magnet 1 %, desc 0.00 m/s
   release from a settled 1 N hold        front 0.36 m/s | lift 0.099 (lip pull 0.00 N) | pad 20 N (comp 0.28, seat 0.01) | front felt 5 N | capstan 13.1 N | keeper gap 0.69 | rod 10 N | ghost: rise 0.14, magnet 0 %, desc 0.00 m/s
   repetition (re-arm at 50 %, released from a 1.2 s settled 1 N hold): t50 30.8 ms (t40 26.9), full 45.4 ms -> 1/(2 t50) 16.3 Hz | friction x2 t50 32.9 / full 48.5 ms -> 15.2 Hz
black settled rest: key front z55.445, keeper gap 1.561, lever -0.552 deg (capstan felt set), rod penetration 0.027; finger-start speed for PLAY 0.768, ABUSE 1.755, 1.0 m/s 0.050, 2.0 m/s 1.336 m/s
   PLAY 1.5 m/s front, let go             front 1.50 m/s | lift 0.068 (lip pull 1.64 N) | pad 76 N (comp 0.65, seat 0.05) | front felt 28 N | capstan 12.7 N | keeper gap 1.19 | rod 24 N | ghost: rise 0.00, magnet 0 %, desc 0.00 m/s
   PLAY 1.5 m/s front, hold 0.45 N        front 1.50 m/s | lift 0.027 (lip pull 1.64 N) | pad 76 N (comp 0.65, seat 0.05) | front felt 28 N | capstan 7.9 N | keeper gap 1.56 | rod 24 N | ghost: rise 1.73, magnet 13 %, desc 0.01 m/s
   PLAY 1.5 m/s front, hold 0.50 N        front 1.50 m/s | lift 0.027 (lip pull 1.64 N) | pad 76 N (comp 0.65, seat 0.05) | front felt 28 N | capstan 7.9 N | keeper gap 1.56 | rod 24 N | ghost: rise 1.42, magnet 10 %, desc 0.02 m/s
   PLAY 1.5 m/s front, hold 0.55 N        front 1.50 m/s | lift 0.027 (lip pull 1.64 N) | pad 76 N (comp 0.65, seat 0.05) | front felt 28 N | capstan 7.9 N | keeper gap 1.56 | rod 24 N | ghost: rise 1.27, magnet 8 %, desc 0.02 m/s
   PLAY 1.5 m/s front, hold 0.60 N        front 1.50 m/s | lift 0.027 (lip pull 1.64 N) | pad 76 N (comp 0.65, seat 0.05) | front felt 28 N | capstan 7.9 N | keeper gap 1.56 | rod 24 N | ghost: rise 1.16, magnet 7 %, desc 0.01 m/s
   PLAY 1.5 m/s front, hold 0.80 N        front 1.50 m/s | lift 0.027 (lip pull 1.64 N) | pad 76 N (comp 0.65, seat 0.05) | front felt 28 N | capstan 7.9 N | keeper gap 1.56 | rod 24 N | ghost: rise 0.88, magnet 4 %, desc 0.00 m/s
   PLAY 1.5 m/s front, hold 1.00 N        front 1.50 m/s | lift 0.027 (lip pull 1.64 N) | pad 76 N (comp 0.65, seat 0.05) | front felt 28 N | capstan 7.9 N | keeper gap 1.56 | rod 24 N | ghost: rise 0.69, magnet 2 %, desc 0.00 m/s
   PLAY 1.5 m/s front, hold 2.00 N        front 1.50 m/s | lift 0.027 (lip pull 1.64 N) | pad 76 N (comp 0.65, seat 0.05) | front felt 28 N | capstan 7.9 N | keeper gap 1.56 | rod 24 N | ghost: rise 0.40, magnet 0 %, desc 0.00 m/s
   ABUSE 2.5 m/s front, let go            front 2.50 m/s | lift 0.177 (lip pull 3.21 N) | pad 128 N (comp 1.07, seat 0.09) | front felt 50 N | capstan 11.4 N | keeper gap 1.14 | rod 40 N | ghost: rise 0.00, magnet 0 %, desc 0.00 m/s
   ABUSE 2.5 m/s front, hold 0.45 N       front 2.50 m/s | lift 0.174 (lip pull 3.21 N) | pad 128 N (comp 1.07, seat 0.09) | front felt 50 N | capstan 8.6 N | keeper gap 1.56 | rod 40 N | ghost: rise 3.44, magnet 29 %, desc 0.02 m/s
   ABUSE 2.5 m/s front, hold 0.60 N       front 2.50 m/s | lift 0.173 (lip pull 3.21 N) | pad 128 N (comp 1.07, seat 0.09) | front felt 50 N | capstan 8.6 N | keeper gap 1.56 | rod 40 N | ghost: rise 1.75, magnet 11 %, desc 0.04 m/s
   ABUSE 2.5 m/s front, hold 1.00 N       front 2.50 m/s | lift 0.172 (lip pull 3.21 N) | pad 128 N (comp 1.07, seat 0.09) | front felt 50 N | capstan 8.6 N | keeper gap 1.56 | rod 40 N | ghost: rise 1.07, magnet 4 %, desc 0.00 m/s
   ABUSE 2.5 m/s front, hold 2.00 N       front 2.50 m/s | lift 0.169 (lip pull 3.21 N) | pad 128 N (comp 1.07, seat 0.09) | front felt 50 N | capstan 8.6 N | keeper gap 1.56 | rod 40 N | ghost: rise 0.63, magnet 0 %, desc 0.00 m/s
   push 0.8 N                             front  -   m/s | lift 0.040 (lip pull 0.00 N) | pad 14 N (comp 0.25, seat 0.01) | front felt 0 N | capstan 12.6 N | keeper gap 1.26 | rod 8 N | ghost: rise 0.00, magnet 0 %, desc 0.00 m/s
   push 1.5 N                             front 0.60 m/s | lift 0.047 (lip pull 0.00 N) | pad 28 N (comp 0.36, seat 0.02) | front felt 8 N | capstan 13.1 N | keeper gap 1.23 | rod 9 N | ghost: rise 0.17, magnet 0 %, desc 0.00 m/s
   push 3 N                               front 1.10 m/s | lift 0.038 (lip pull 0.48 N) | pad 42 N (comp 0.51, seat 0.03) | front felt 20 N | capstan 13.1 N | keeper gap 1.25 | rod 13 N | ghost: rise 0.25, magnet 0 %, desc 0.00 m/s
   push 6 N                               front 1.65 m/s | lift 0.053 (lip pull 3.07 N) | pad 84 N (comp 0.71, seat 0.06) | front felt 34 N | capstan 13.3 N | keeper gap 1.22 | rod 26 N | ghost: rise 0.28, magnet 0 %, desc 0.00 m/s
   1.0 m/s front, let go                  front 1.11 m/s | lift 0.060 (lip pull 0.53 N) | pad 42 N (comp 0.51, seat 0.03) | front felt 20 N | capstan 13.6 N | keeper gap 1.20 | rod 13 N | ghost: rise 0.00, magnet 0 %, desc 0.00 m/s
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

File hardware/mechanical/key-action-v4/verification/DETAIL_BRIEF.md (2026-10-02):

# Toccata v4 key action — DETAIL phase brief

Scratch root: /private/tmp/claude-501/-Users-kwg-Desktop-mydrive-project-Toccata/2f19e142-4ac2-4c90-bd1e-b3b469f97487/scratchpad/v4
Repo: /Users/kwg/Desktop/mydrive/project/Toccata
Python with numpy/scipy/matplotlib + resvg_py (SVG→PNG): ../venv/bin/python  (i.e. scratchpad/venv/bin/python).
  PNG render: `import resvg_py; open(p,'wb').write(bytes(resvg_py.svg_to_bytes(svg_string=s, background='#ffffff', width=1600)))` — system fonts load automatically (Apple SD Gothic Neo renders Korean).

## Read first
1. context/BRIEF.md — original brief, targets §6, method rules §7, v3 interface.
2. concepts_result.json — all 5 concepts + independent verifications + the judge (key `judge`). The judge chose **W1** ("짧은 시소 건반 + 꼬리가 들어 올리는 무게 레버"), runner-up S1.
3. concepts/W1/{design.md, calc.py, results.txt} — the W1 designer's model. verify/W1/{verify.py, results_verify.txt, extra.py} — the verifier's independent model and its findings.
4. context/v3_extract.txt — v3 dimension tables (P/S/D/A) and mechanism text; v3 is the system this plugs into.

## Final architecture to detail = "W1+" (the judge's recommended_design_ko, verbatim in concepts_result.json → judge.recommended_design_ko)
Short version: each key is an individual PETG seesaw on a Ø4 SUS304 rod lying in a balance rail (pivot ≈ y141, z21.5). Its hidden tail carries a steel capstan (M3 button-head screw in a nut trap, white y≈188.3, black y≈180.6). The capstan lifts a weighted lever: printed carrier (common to white and black) + SS400 steel block 9×50×21.5 (≈76 g, mechanically captured — snap lip or Ø2 cross pin, epoxy only against rattle) hung on a Ø3 SUS304 rod through 4 printed fins (lever pivot ≈ y203.5, z33.5). Gravity on the lever returns the key; no spring in the base design. Rest = tail felt 1.5T on the rear shelf (z≈20). Bottom = v3 front felt 3T + steel front-top corner (rounded R≥2 + printed/felt cap) meeting a steel up-stop rail 3T×19 with 2T felt, fastened with M3 thumb screws into ≥3 mm pin bosses with nut traps (4 per module); black-key lever bays get a 1.8 mm pad so black levers stop at their own height. The v3 front hook is kept only as a non-touching keeper 0.5 mm above the crossbar (anti-lift / transport). The key's open notch on the rod is R2.55 lined with 0.5T bushing cloth. Optional assist-spring seat (Ø2 steel guide pin + pocket, reaction into the bolted rail) drawn but empty (spring d0.35 / OD6 / ~11 active turns, L0/D ≤ 4, C ≤ 16 — only if stage-0 friction pushes t40 over 37.6 ms). Sensor bar, stripboard, ribbon lane, control board (y145.5–195.5) and USB exit stay where v3 has them; magnet moves to y67. Frame 164.5 × 212, total instrument 1254 × 410 unchanged; dust cover rises from z59 to ≈z73.
W1-B (board moved under key front, pivot y160, front/back ratio ≈2.1) is NOT the base — only document it as an option.

## Every item in judge.must_fix_before_detail and judge.grafts must be resolved or explicitly answered in the final model
(They include: up-stop rail hold-down and load check with a 6-key chord ≈360 N; black-bay 1.8 mm pads and re-simulation; 4-DOF free-notch lift model with keeper and ≤0.2 mm lift target, 90° tilt retention; ghost re-trigger check after ff/fff with a 2 N held finger (key-front lift < ~2 mm); print plan with supports and capstan as a steel screw → ~5.56 kg / ~371 h; repetition margin with doubled friction and the optional spring; Flores (or measured-type) felt contact with effective e ≈ 0.35; all clearances ≥ 1.0 mm after ±0.3 FDM including x/y/z sweeps with neighbours in rest/dip/ff poses; balance-rail saddles that locate the rod in y and clear the key ≥1 mm; capstan-felt static set vs up-stop timing and the adjustment procedure; lever hub spacing (0.3 mm gap or washer), fins in E|F and B|C gaps, F#/G# beam jog and roll moment; ribs at x76.5 and x91.5 under the rear shelf span over the USB plug; corrected key-removal procedure; cost with real small-quantity steel prices, shipping and cutting labour; cover/rear-bar relationship; module mass ≈1.5 kg vs R18; cover resting on pins/rail now that the spine is gone.)
Also cover what W1 never modelled: the end parts (left A0/A#0/B0, 47 mm wide, and right C8, 39.5 mm) with the same mechanism; module dovetails vs the new tails/levers (S1's verifier found the v3 rear dovetails collide with tails); what goes in the R29 spare-key storage bay (inner 338.8 × 172 × 77) now that keys are individual (e.g. spare white keys C-type/D-type, black key, levers, steel, rods).

## Conventions
mm, g, N, ms. z = 0 desk, y = 0 white key front lip, +y away from the player, x across the octave (x = 0 at the C left nominal boundary, module width 164.5). White key heads: v3 KC…KB x ranges; black keys: v3 KC#…KA# x ranges (see v3_extract P-table). Assume printer bed 220×220, 0.4 nozzle, 0.2 layers, Bambu PETG Basic (density 1.25, E_flex 1.95 GPa, tensile 51 MPa, HDT 71 °C), 15 g/h print rate.
Korean for all user-facing text (design.md, labels on drawings). Numbers in drawings must come from geometry.json (no hand-typed dimensions).

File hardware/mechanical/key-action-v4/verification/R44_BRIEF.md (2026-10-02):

# Round r4.4: close the open issues of the W1+ key action (r4.3 → r4.4)

The project is Toccata, a hobbyist 3D-printed 88-key MIDI piano. The key action W1+ r4.3 is complete and published:
- short PETG seesaw key on a Ø4 SUS rod
- a tail M3 capstan lifts a printed lever carrier holding an SS400 9×19×40 block on a Ø4 rod
- torsion assist spring
- up-stop pads on slide-out pad bars

The user asked: **"남은 문제 부분을 고쳐줄래"**, which means fix the remaining issues. This round closes the r4.3 open issues without undoing anything that works.

## Read first
- `final/DESIGN.md`: the r4.3 design document. Read §0 (criteria and results), §1d (circuit interface), §9 (clearances), §12 (adjustments), §15 (printing), §17 (stage-0 tests) and §18 (remaining risks).
- `final/model_v4.py`, `final/run_all.py`, `final/export_geo.py`, `final/make_design_md.py`: the single model. It produces geometry.json, metrics.json, results.txt, DESIGN.md and parts_list.json.
- `report_r4/open_issues.r4_3.json`: the 7 open issues listed below, in Korean.
- The r4.3 backup is in `final_r4_3/` and `drawings_r4_3/`. Never edit the backups, `final_r3/` or `drawings_r3/`.

## The open issues
1. **Lever upper snap lip.** The lip is 0.8 × 1.0 and sits on the carrier's top edge. At full press (dip/ff) it comes into the space beside the up-stop pad and misses the 1.0 mm clearance rule (±0.3 FDM).
   - The lip is not exported to geometry.json, so the model's clearance check missed it. The drafter found it.
   - Also export the lever pin-boss holes and the rod end plugs so they are checked too.
   - Fix it without adding parts: shorten or move the lip out of the pad zone (y160–172 and the pad-bar rails). Check that the steel block is still retained with a numeric retention check.
2. **F / F# rest felt partial landing.** The r4.3 USB shelf slot (x76.45–91.55) leaves the F rest felt 59 % seated and the F# rest felt 42 % seated.
   - Still to run under that condition: the return-overshoot pose sweep, and dynamics at the weak 6-key chord site (top plate 492 N/mm).
   - Run both. If a target fails, fix it without adding parts and without touching the circuit interface.
3. **Black-key dip export.** The black-key dip polygon is exported at the rigid kinematic bottom (6.22°) instead of the truly settled 1 N bottom with the pad (6.08°), which the white keys already use. Make the export consistent, and keep the rigid pose as a separate field if the drawings need it.
4. **Circuit interface** (the circuit session owns hardware/pcb). These conditions are frozen: do not change them without flagging it.
   - USB-C cable overmould ≤ 12.5 × 7.6 × 25 (plug z10.7–18.3; shelf slot edge clearance exactly 1.30).
   - RP2040-Zero top parts and header-pin tips ≤ z16.3; the y194.5–195.5 band ≤ z16.7.
   - Shelf underside z18.05; wall opening z5–21; keep-out x81.22–85.42 × y≤173.2.
   - The circuit session already published these (merged artifact v5).
   - Task: find real buyable USB-C cables (sold in Korea, or AliExpress) whose C-plug overmould meets the limit, with measured dimensions from a datasheet or product page.
5. **Documentation.**
   - Dimension-table rounding is inconsistent (e.g. 0.955 → 0.95; pick one rule: round half away from zero at the shown precision, and make every generated table use one helper).
   - Parts of §15 (print plan) and §13 (spare-key storage, A08) are older than parts_list.json.
   - The three printed tools (bench jig, capstan bench gauge, balance-pin height gauge) have only working heights and no shapes; drawing 13 is schematic.
   - Task: design the tools with real dimensions (printable, parametric from the model) and put them in the model output and the drawings.
6. **Stage-0 tests.** Pad rebound e ≤ 0.07, base-plate deflection ≤ 0.07 mm at 100 N, and torsion spring quality are assumptions.
   - They need physical tests; nobody can run them here.
   - What *can* be done: a ready-to-print stage-0 test kit. Coupon models (STL) plus a Korean procedure with pass/fail numbers, the measuring method, and what to change in the model for each outcome.

## Rules (unchanged from r4)
- **PLAY** (key-front speed ≤ 1.5 m/s): every functional target must hold.
- **ABUSE** (2.5 m/s single key, 2.0 m/s 6-key chord): no damage only.
- Clearance ≥ 1.0 mm after ±0.3 FDM between moving bodies and their neighbours.
- **Scope:** all octave modules are identical. Work on ONE module: the worst-case white key shape of the 7, black C#, plus F and F# for issue 2. Add the end-part keys A0 and C8 only where a change touches them.
- Dynamic case grid: PLAY 0.5 / 1.0 / 1.5 m/s × finger holds 0.45 / 1 / 2 N plus release; ABUSE 2.5 m/s single key; materials nominal and worst.
- Do not add parts unless there is no other way. If you must, say so with the cost.
- Coordinates:
  - z0 = desk, y0 = white key front lip (+y away from the player), x0 = C left boundary.
  - Module width 164.5, frame depth 212, total depth 410.
- Python: `scratchpad/venv/bin/python` (numpy, scipy, resvg_py, trimesh). OpenSCAD: `/opt/homebrew/bin/openscad`.
- Korean text in DESIGN.md, drawings and procedures. Code and comments may be English.
- The user values speed: work only on what the issue needs, and report the most important findings first.

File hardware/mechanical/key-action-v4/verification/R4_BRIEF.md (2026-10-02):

# Toccata v4 W1+ — round 4 brief (fix + SIMPLIFY)

Scratch root: /private/tmp/claude-501/-Users-kwg-Desktop-mydrive-project-Toccata/2f19e142-4ac2-4c90-bd1e-b3b469f97487/scratchpad/v4
Python: ../venv/bin/python (numpy, scipy, matplotlib, resvg_py).
Read first: context/DETAIL_BRIEF.md (architecture, conventions), final/DESIGN.md (r3 design, 700 lines — §0 targets, §2 r2→r3 changes, §3 parts, §15 cost, §20 risks), final/model_v4.py + run_all.py + export_geo.py (the single-source model), context/r3_findings.json (round-3 verifier findings: 8 major + 10 minor), drawings/geometry_patch.json + drawings/geo_patch.py (corrections the drafter applied ONLY in the drawings: end-part joint bosses, plan lever-rod x, black magnet bosses, assist spring — they must be merged into the model), drawings.json issues_left in detail_result.json (key `drawings`).
r3 is backed up in final_r3/ and drawings_r3/ — never edit those.

## Why round 4 exists
The user asked for a gravity-return seesaw action "with every part that can be removed removed, and made smaller". Rounds 1–3 made the model pass ever stricter checks, and the design grew: 8 thumb screws with 3×3 disc-spring stacks per module, tapped SS400 strips in printed pockets, SUJ2 hardened lever shaft, 5 g lead in every black key, cover locating pins + magnets, brass bushings, C-rings, 12 service blocks, snap notch. Module mass went 0.59 kg (v3) → 2.03 kg, cover top z59 → z78 (screw heads z80.7), base cost +130,400 KRW. The user has now seen this and asked to continue.

## Revised load criteria (decided — apply them everywhere, state them in DESIGN.md §0)
Measured piano key-front speeds reach roughly 1–1.5 m/s in fortissimo (hammer 5–7 m/s ÷ ~5 lever ratio); 2.5 m/s is a slap/abuse case. Verify this with 1–2 sources and cite them in DESIGN.md.
- PLAY envelope, key-front speed ≤ 1.5 m/s (single keys, rolled and simultaneous chords of up to 6 keys, fingers held at 0.45–2 N or released): EVERY functional target must hold — DW 47–55 g, UW ≥ 20 g, repetition ≥ 13.3 Hz (also with doubled friction, assist spring allowed if it can really be built), full return < 60 ms, notch lift ≤ 0.2 mm, keeper never touched, no ghost re-trigger above the firmware re-arm line (firmware filter may be used, state it), up-stop joint stays closed, sensor gap ≥ 3.0, clearances ≥ 1.0 after ±0.3 FDM.
- ABUSE envelope, 2.5 m/s single key and 2.0 m/s 6-key simultaneous: NO DAMAGE only — no yield, stresses below fatigue limits for ≤ 10^4 events, no part leaves its seat permanently (a key may lift and reseat), no loss of adjustment. Momentary joint opening, notch lift up to the pop-out margin with safety factor 2, and a filtered ghost event are acceptable.

## Simplification targets (try hard; report what was achieved and what each removal costs)
- Up-stop: lower the peak up-stop force by a softer / longer-travel lever stop (thicker felt or felt + low-rebound foam with enough travel) so the rail mount can be simple — e.g. plain M3 through-bolts or hand-turned knurled nuts in fins loaded in compression, no disc springs, no tapped strips, no pockets. Keep single-key removal TOOL-FREE (hand-turned knobs/nuts or quarter-turn latches are fine; no driver, no 24 h re-tightening).
- Black keys: remove the 5 g lead if the play-envelope notch-lift target holds with pad/felt choices; otherwise explain.
- Lever shaft: plain SUS304 Ø3 if the revised loads allow it (no hardened shaft, no brass bushings unless wear requires).
- Cover: rest it on the rail/fins without locating pins or magnets if possible.
- Heights: cover top ≤ z74, nothing above it; module mass ≤ 1.6 kg if possible (steel blocks alone are 0.91 kg/module).
- Remove service blocks / C-rings / other small parts if a simpler feature does the job.
- Everything else from r3 that is not needed under the revised criteria.

## Must also resolve
All 8 major + 10 minor round-3 findings (context/r3_findings.json) — or show with numbers why a finding no longer applies after simplification. Merge drawings/geometry_patch.json into the model. Keep the spare-key bay ≥ 1 mm clearance per side. End parts use the same mechanism and the same simplifications.

## Outputs (overwrite in final/, r3 is backed up)
model_v4.py, run_all.py, export_geo.py, geometry.json, metrics.json, results.txt, DESIGN.md (Korean; add a section "r3 → r4 단순화" with a before/after parts table: count, mass, cost, height, and what each removal cost in performance), parts_list.json (every printed and purchased part with qty per module / 88 keys, spec, mass).

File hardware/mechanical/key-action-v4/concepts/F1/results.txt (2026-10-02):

Toccata v4 — concept F1: over-tail counter-lever (오버테일 카운터레버).  All values computed by calc.py.
Units: mm, g (gf for forces), ms.  z = 0 desk, y = 0 white-key lip.

== layout
  key pivot rod KP = (205.0, 18.0)  (Ø3.0 steel, one per octave, rear comb)   lever rod LP = (151.0, 35.83)
  dip angle white 2.788°  black 3.545°
  nose contact y: white 141.0 (pad z 40.90), black 138.0 (pad z 41.42)
  pad vertical travel at the nose: white 3.14, black 4.19

== WHITE key + lever
  key mass 20.76 g (PETG 20.45), COM (81.65, 32.79), I_KP 385802 g·mm²  (I_com 65449 + m·d² parallel-axis)
  lever mass 74.28 g = steel 9x25x40.0 70.65 g + PETG 3.63 g, COM (174.55, 35.18) (ref pose), I_LP 55624 g·mm²
  lever angle rest -9.14°, bottom 8.68° (sweep 17.83°)
  box table (key):
     skin head                            2.812 g  at (  25.00, 42.50)
     skin tail                            3.446 g  at (  98.00, 42.50)
     front wall                           0.608 g  at (   2.10, 32.50)
     head side walls                      2.554 g  at (  26.35, 32.50)
     notch wall                           0.220 g  at (  49.40, 32.50)
     tail side walls                      5.184 g  at (  98.00, 32.50)
     guide ribs                           0.891 g  at (  18.75, 32.50)
     up-stop crossbar                     0.060 g  at (  12.25, 24.30)
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

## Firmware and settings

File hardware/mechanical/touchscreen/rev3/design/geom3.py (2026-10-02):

# Toccata R31 touchscreen — rev 3: Waveshare 7-DSI-TOUCH-C (B1) on the L2 low rear bar.
# World (mm): x across from the A0 left boundary, y away from the player from the white-key front lip, z up from the desk.
# Cradle frame: xr = x - XC (XC = screen centre), u = from the glass bottom edge up the screen, w = from the glass front face backward.
# ONE placement block (PL) is read from the L2 json; every world coordinate below is computed from PL + part geometry.
# Rev-2 mechanism kept: printed lid knuckles, cradle ears + heel stop at 22 deg (3 deg play), use at 25 deg set by an easel leg
# hinged on the cradle back with its foot in a lid pocket, backward fold for transport, leg clipped to the cradle back.
import json, math, sys, re, hashlib
from pathlib import Path
import numpy as np

OUT = Path(__file__).resolve().parent
T3 = OUT.parent
SRC_FINAL, SRC_PROV = T3 / 'L2_cu.json', T3 / 'L2_cu_provisional.json'
SRC = SRC_FINAL if SRC_FINAL.exists() else SRC_PROV
L2 = json.load(open(SRC))
IS_FINAL = SRC == SRC_FINAL
def md5_8(p): return hashlib.md5(open(p, 'rb').read()).hexdigest()[:8]
# body_L2.json (CAD session, read-only in the repo) is copied to work/ for the speaker driver centres; the copy is compared with the repo on every run
BODY_REPO = Path('/Users/kwg/Desktop/mydrive/project/Toccata/hardware/mechanical/cad/spec/body_L2.json')
BODY_COPY = OUT / 'work' / 'body_L2_copy.json'
BL2 = json.load(open(BODY_COPY))
BL2_INFO = dict(copy=str(BODY_COPY), md5=md5_8(BODY_COPY), repo_md5=md5_8(BODY_REPO) if BODY_REPO.exists() else None)
BL2_INFO['same_as_repo'] = BL2_INFO['md5'] == BL2_INFO['repo_md5']
if BL2_INFO['repo_md5'] and not BL2_INFO['same_as_repo']:
    print('WARNING: repo body_L2.json changed since the copy -> re-copy and re-run', BL2_INFO)

def pick(*keys, default=None):
    """first key path found in L2 (paths as 'a.b'); lists/ranges are returned as-is"""
    for k in keys:
        d = L2; ok = True
        for part in k.split('.'):
            if isinstance(d, dict) and part in d: d = d[part]
            else: ok = False; break
        if ok and d is not None: return d
    return default

def lo(v): return v[0] if isinstance(v, (list, tuple)) else v
def hi(v): return v[-1] if isinstance(v, (list, tuple)) else v
def mid(v): return (lo(v) + hi(v)) / 2 if isinstance(v, (list, tuple)) else v
def r2(v): return round(float(v), 2)
def r2l(p): return [r2(c) for c in p]

# ---- project context (keys; not placement): copied key_numbers.json + rev-2 L1 sensor row ----
_KN = json.load(open(OUT / 'work' / 'key_numbers_copy.json'))['keys']
CTX = dict(white_top_z=_KN['white_top_z'], black_top_z=_KN['black_top_z'], key_rear_y=_KN['key_rear_y'], module_top_z=_KN['module_top_z'],
           O4_x=_KN['O4_x'], O4_white_centre_x=_KN['O4_white_centre_x'], octave=_KN['octave_width_mm'], key_x=[0.0, 1222.0], sensor_y=67.0,
           black_front_y_draw=70.0, player_x=611.0, ear_dx=75.0, eye=[-350.0, 450.0],
           note='keys from touch/context/key_numbers.json; key_x, sensor_y from rev-2 geom (L1 dict); black_front_y_draw only for the drawing; eye/ears are estimates')
# ============================ PLACEMENT BLOCK (the only world input) ============================
# Reads the final L2 file (body_L2.json digest from the CAD session) when present, else the provisional file.
TZ = pick('touchscreen_lid_zone_for_W1', 'centre.touchscreen_lid_zone_for_W1', default={}) or {}
CM = pick('cad_message_extra', default={}) or {}
lid_x = TZ.get('x') or pick('lid_x', 'cu_lid.x', 'draft_A_x')
XC = float(mid(lid_x)) if lid_x else float(pick('screen_lid_x_centre', default=611.0))
if lid_x is None:
    wdt = lo(pick('screen_lid_width', default=200)); lid_x = [XC - wdt / 2, XC + wdt / 2]
LID_Y = TZ.get('y') or pick('lid_y', 'cu_lid.y', default=[215, 342])
LID_TOP = float(TZ.get('top_z') or pick('lid_top_z', default=72.85))
LID_BED = float(pick('centre.walls.lid_z', default=None)[0]) if pick('centre.walls.lid_z') else float(mid(pick('lid_ribs_underside_z', default=[61, 68])))
_screws_txt = str((CM.get('screen_lid') or {}).get('screws', ''))
_sy = [float(v) for v in re.findall(r'y(\d+(?:\.\d+)?)', _screws_txt)]
REAR_BAR_FRONT = float(lo(pick('overall.rear_unit_y', default=None)) if pick('overall.rear_unit_y') else pick('rear_bar_front_y', default=215))
MOD_REAR = float(lo(pick('front_joint.air_gap_y', default=None)) if pick('front_joint.air_gap_y') else pick('module_rear_wall_y', default=212))
TASK_KEEPOUT_Y = 215.0            # hard rule given with the task (y <= 215 at z >= 72.85); the final rear bar front is y214
_DRV = (BL2.get('speakers') or {}).get('driver') or {}
if _DRV.get('x_centre') and _DRV.get('centre_yz'):          # real driver (cone) centres from body_L2
    SPK_PLAN = [[float(_DRV['x_centre']['L']), float(_DRV['centre_yz'][0])], [float(_DRV['x_centre']['R']), float(_DRV['centre_yz'][0])]]
    SPK_FROM = 'body_L2 speakers.driver (x_centre, centre_yz)'
else:
    spk_x = pick('speakers_x', default=None)
    SPK_PLAN = [[mid(spk_x['L']), mid(LID_Y)], [mid(spk_x['R']), mid(LID_Y)]] if spk_x else [[-16 + 301 / 2, mid(LID_Y)], [1238 - 301 / 2, mid(LID_Y)]]
    SPK_FROM = 'pod centres (estimate)'
# 27 deg sound-path rule (L2): line from each cone's lower edge, 27 deg up toward the player, >= 3 above (module rear y, lid top z)
_BAF = ((BL2.get('speakers') or {}).get('baffle') or {}).get('angle_from_horizontal_deg', 43.0)
_CONE_R = 47.0                                               # Ø94 hole
SOUND_RULE = None
if _DRV.get('centre_yz'):
    cy_, cz_ = _DRV['centre_yz']; le = (cy_ - _CONE_R * math.cos(math.radians(_BAF)), cz_ - _CONE_R * math.sin(math.radians(_BAF)))
    SOUND_RULE = dict(cone_lower_edge_yz=[round(le[0], 2), round(le[1], 2)], baffle_deg=_BAF, line_deg=27.0)
# lid fixing hardware (CAD L2): seam rails + front posts with M3 inserts
def _cc(idp):
    for c in (L2.get('centre_contents') or []):
        if str(c.get('id', '')).startswith(idp): return c['bbox_x0x1y0y1z0z1']
    return None
SEAM = dict(rail=[_cc('PR-SEAMRAIL-1'), _cc('PR-SEAMRAIL-2')], post=[_cc('PR-SEAMPOST-1'), _cc('PR-SEAMPOST-2')])
PL = dict(
    source=str(SRC), source_is_final=IS_FINAL, source_note=pick('source', default=''),
    x_centre=XC,
    keepout=dict(y_max=max(TASK_KEEPOUT_Y, REAR_BAR_FRONT), z_min=LID_TOP, clearance=1.0, module_rear_y=MOD_REAR, rear_bar_front_y=REAR_BAR_FRONT,
                 rule=f'nothing of the touchscreen at y <= {max(TASK_KEEPOUT_Y, REAR_BAR_FRONT):g} while z >= {LID_TOP} (modules end y{MOD_REAR:g}, rear bar front y{REAR_BAR_FRONT:g}; modules are lifted out upward)'),
    lid=dict(x=[float(lid_x[0]), float(lid_x[1])], y=[float(LID_Y[0]), float(LID_Y[1])], top_z=LID_TOP, plate_t=3.0, bed_z=round(LID_BED, 2),
             note='CU-SCREENLID: printed PETG plate 3 + ribs to the bed plane (final L2: ribs 8.5, bottom z61.35)'),
    floor_z=float(lo(pick('centre.floor_zone.z', default=None)) if pick('centre.floor_zone.z') else hi(pick('under_lid.strip_floor_z', default=[14.5, 16.5]))),
    speaker_top_z=float(pick('speakers_top_z', default=None) or lo(pick('speakers.top_z', default=[134, 157]))),
    rear_face_y=float(hi(pick('overall.y', default=None)) if pick('overall.y') else LID_Y[1]),
    lid_screw=dict(y=_sy if len(_sy) >= 2 else [LID_Y[0] + 12.0], inset_x=5.0,
                   x=[float(lid_x[0]) + 5.0, float(lid_x[1]) - 5.0],
                   note=(_screws_txt or 'front 2 corners M3x10 (D23 rule kept)') + ' — x = lid edge +-5 (est.: middle of the 10 mm the lid overlaps each 20 mm seam rail)'),
    speakers_plan=SPK_PLAN, speakers_plan_from=SPK_FROM, sound_rule=SOUND_RULE, body_L2=BL2_INFO,
    seam=SEAM,
    body_x=[float(v) for v in (pick('overall.x', default=[-16.0, 1238.0]))],
    front_zone_y=pick('centre.front_zone.y', default=[LID_Y[0], LID_Y[0] + 27]),
    cad_recommendations=dict(hinge=CM.get('hinge_line_recommended'), ribbon_hole=CM.get('ribbon_hole_recommended'), folded=CM.get('folded'),
                             exhaust=CM.get('exhaust_slots') or TZ.get('vents'), dsi=TZ.get('dsi'), gpio=TZ.get('gpio_power')),
    keepout_zones=dict(dsi=(CM.get('disp1_connector') or {}).get('keepout'), dsi_z=[28.1, round(LID_BED, 2)], gpio=CM.get('gpio_2_6')),
)
# hinge axis height: fold feet under the rib plane (w16) + leg stow room -> 8 above lid top (same rule as rev 2)
H_Z_ABOVE_LID = 8.5

# ============================ SCREEN: Waveshare 7-DSI-TOUCH-C ============================
# Drawing ws_7-DSI-TOUCH-C-details-size.jpg (pixel-read 3.51 px/mm) + product photos. Orientation used: thick bezel (9.65) at the bottom,
# glass facing the player (native 1024x600 landscape, no rotation). Photos show that the drawing's BACK view is the front view
# flipped about the HORIZONTAL axis (Pi-hole mirror check, cable position, FPC/power order) -> back-view x from left = front x from left,
# back-view distance from top = u (distance from the glass bottom edge).
G = dict(w=166.10, h=101.00, body=8.00, body_studs=13.4, act_w=154.58, act_h=86.42,
         act_off=dict(left=3.97, right=7.55, top=4.94, bottom=9.65),
         holes=dict(pitch=[154.00, 88.00], from_side=6.05, from_tb=6.50, thread='M2.5', depth='unknown'),
         pi_holes=dict(xr=[64.05 - 83.05, 122.05 - 83.05], u=[25.5, 74.5], note='Pi mount holes 58 x 49 (not used; standoffs not fitted)'),
         window=dict(xr=[100.4 - 83.05, 126.6 - 83.05], u=[30.2, 70.5], note='opening in the metal back, driver PCB visible (est. +-0.5)'),
         fpc=dict(xr=[100.9 - 83.05, 106.3 - 83.05], u=[36.5, 52.4], pin_u_centre=43.8, mouth_xr=106.3 - 83.05, mouth='+x',
                  type='22-pin 0.5 mm ZIF, horizontal, on a blue strip PCB in the window; mouth faces the window (+x). est. +-0.5'),
         pwr=dict(xr=[102.4 - 83.05, 107.4 - 83.05], u=[56.6, 65.2], mouth_xr=107.4 - 83.05, mouth='+x',
                  type='MX1.25 2-pin horizontal, above the FPC connector, mouth +x. est. +-0.5'),
         emboss=dict(xr=[26.4 - 83.05, 97.4 - 83.05], u=[32.2, 71.0], h=2.1, note='raised stamped rectangle on the back, height from side view ~2.1 (est.)'),
         mass=0.30)
G['glass_xr'] = [-G['w'] / 2, G['w'] / 2]
G['act_xr'] = [-G['w'] / 2 + G['act_off']['left'], G['w'] / 2 - G['act_off']['right']]
G['act_u'] = [G['act_off']['bottom'], G['act_off']['bottom'] + G['act_h']]
G['holes_xr'] = [-G['w'] / 2 + G['holes']['from_side'], G['w'] / 2 - G['holes']['from_side']]
G['holes_u'] = [G['holes']['from_tb'], G['h'] - G['holes']['from_tb']]
_BF = json.load(open(OUT / 'work' / 'bottom_feature.json'))      # measured by work/measure_bottom_feature.py
G['bottom_feature'] = dict(xr=_BF['xr'], proud=_BF['proud_mm'], proud_max=_BF['proud_max_est'],
                           src='drawing front view (work/measure_bottom_feature.py) + photo details-9 (slot with a tab in the bottom face, right)')
CONN_SIDE = +1          # +1: connector right of centre, mouth +x (photo analysis). -1 = mirror everything connector-side about XC.

# ============================ CRADLE (local) ============================
RIM, CLR = 2.0, 0.3
CR = dict(xr=[-(G['w'] / 2 + CLR + RIM), G['w'] / 2 + CLR + RIM], u0=-2.5, u1=G['h'] + 2.5, w0=-1.0,
          w_screen_back=G['body'], w_plate_in=None, w_plate_out=None, w_rib=None)
EMB_CLR = 0.4
CR['w_plate_in'] = round(G['body'] + max(2.5, G['emboss']['h'] + EMB_CLR), 2)     # 10.5
CR['plate_t'] = 2.5
CR['w_plate_out'] = CR['w_plate_in'] + CR['plate_t']                                  # 13.0 = hinge-axis plane
CR['rib_h'] = 3.0
CR['w_rib'] = CR['w_plate_out'] + CR['rib_h']                                          # 16.0
UA = CR['u0'] - 6.5                  # axis 6.5 below the cradle bottom (cheek R5.5 + 1.0)
WA = CR['w_plate_out']               # axis in the plate back plane -> front lever b = WA - w0 = 14 (rev 2: 17)
HEEL_STOP_H = 3.5                    # raised stop block in each ear slot (heel radius 10.63 -> 8.60)
HEEL_REL22 = (-7.0, -(H_Z_ABOVE_LID - HEEL_STOP_H))
KNUCKLE_BASE_HALF = 9.0              # knuckle cheek profile: R5.5 around the axis + trapezoid to +-9 at the lid top
# heel stop block relative to the axis (dy, dz): from the knuckle base front to 2 before the axis, lid top .. lid top + 3.5
HEEL_BLOCK_REL = (-KNUCKLE_BASE_HALF, -2.0, -H_Z_ABOVE_LID - 20.0, -(H_Z_ABOVE_LID - HEEL_STOP_H))   # merged with the lid below, so depth = to the top / sides
SLOT_FLOOR_REL = (-40.0, 40.0, -H_Z_ABOVE_LID - 20.0, -H_Z_ABOVE_LID)   # lid top between the cheeks (outside the block)
# walls (explicit, so the model and the drawings use the same faces)
CR['walls'] = dict(bottom_u=[CR['u0'], 0.0], top_u=[r2(CR['u1'] - RIM), CR['u1']], top_gap=r2(CR['u1'] - RIM - G['h']), bottom_gap=0.0,
                   side_inner_xr=r2(G['w'] / 2 + CLR), side_gap=CLR, front_w=CR['w0'],
                   note='glass bottom edge rests on the bottom wall inner face u0 (u datum); top gap 0.5; side gaps 0.3; walls run w-1..16')
# relief notch in the bottom wall for the small feature below the glass bottom edge (Waveshare front view, right of centre)
NOTCH_MARGIN = 6.5
NOTCH = dict(xr=[float(math.floor(G['bottom_feature']['xr'][0] - NOTCH_MARGIN)), float(math.ceil(G['bottom_feature']['xr'][1] + NOTCH_MARGIN))],
             u=[CR['u0'], 0.0], w=[CR['w0'], G['body']], through=True, feature_xr=G['bottom_feature']['xr'], feature_proud=G['bottom_feature']['proud'],
             note='cut through the bottom wall (u-2.5..0) over w-1..8: the feature may stick out up to ~1 and stays reachable; the glass still rests on the wall on both sides')

# hinge sets (xr), symmetric, screw from the outer side (head outward)
def hinge_set(side):
    s = 1 if side == 'right' else -1
    far = sorted([s * 52.0, s * 60.0]); ear = sorted([s * 60.2, s * 68.2]); near = sorted([s * 68.4, s * 72.4])
    slot = sorted([s * 60.0, s * 68.4])                      # ear slot between the cheeks = ear 8.0 + 0.2 gap each side
    return dict(xr=sorted([s * 52.0, s * 72.4]), far_cheek=far, ear=ear, ear_slot=slot, near_cheek=near, screw_from='+x' if s > 0 else '-x')
HINGES = dict(left=hinge_set('left'), right=hinge_set('right'))
CHEEK_R = 5.5; EAR_HUB_R = 4.2
TH_USE, TH_HEEL, TH_FOLD = 25.0, 22.0, 90.0

# ============================ axis position from the keep-out rule ============================
def P_rel(u, w, th):
    """(dy, dz) of cradle point relative to the hinge axis at tilt th"""
    t = math.radians(th); du, dw = u - UA, w - WA
    return (du * math.sin(t) + dw * math.cos(t), du * math.cos(t) - dw * math.sin(t))

# ---- 2D helpers (convex hull, dense boundary, point/rect distances) ----
def hull2(pts):
    pts = sorted(set((round(p[0], 6), round(p[1], 6)) for p in pts))
    def cross(o, a, b): return (a[0] - o[0]) * (b[1] - o[1]) - (a[1] - o[1]) * (b[0] - o[0])
    lo_, hi_ = [], []
    for p in pts:
        while len(lo_) >= 2 and cross(lo_[-2], lo_[-1], p) <= 0: lo_.pop()
        lo_.append(p)
    for p in reversed(pts):
        while len(hi_) >= 2 and cross(hi_[-2], hi_[-1], p) <= 0: hi_.pop()
        hi_.append(p)
    return lo_[:-1] + hi_[:-1]                                   # CCW
def densify(poly, step=0.05):
    out = []
    for a, b in zip(poly, poly[1:] + poly[:1]):
        n = max(1, int(math.dist(a, b) / step))
        out += [(a[0] + (b[0] - a[0]) * k / n, a[1] + (b[1] - a[1]) * k / n) for k in range(n)]
    return out
def rect_sd(p, r):
    """signed distance from p to rect r = (x0, x1, y0, y1): > 0 outside, < 0 inside"""
    dx = max(r[0] - p[0], 0, p[0] - r[1]); dy = max(r[2] - p[1], 0, p[1] - r[3])
    if dx > 0 or dy > 0: return math.hypot(dx, dy)
    return -min(p[0] - r[0], r[1] - p[0], p[1] - r[2], r[3] - p[1])
def in_convex(p, poly):
    return all((b[0] - a[0]) * (p[1] - a[1]) - (b[1] - a[1]) * (p[0] - a[0]) >= 0 for a, b in zip(poly, poly[1:] + poly[:1]))
def poly_rect_gap(poly, r):
    """min signed gap between a convex polygon and an axis-aligned rect (negative = overlap depth)"""
    g = min(rect_sd(p, r) for p in densify(poly))
    for c in [(r[0], r[2]), (r[0], r[3]), (r[1], r[2]), (r[1], r[3])]:
        if in_convex(c, poly): g = min(g, -min(math.dist(c, q) for q in densify(poly, 0.02)))
    return g

# ---- ear side profile (cradle local u, w): convex hull of the hub R4.2 round the axis, the attachment to the cradle bottom
# (u0, w8..13) and the heel point. No other lobe: the heel point must be the lowest ear point at 22 deg (rev-3a fix). ----
def to_local(dy, dz, th):
    t = math.radians(th); return (UA + dy * math.sin(t) + dz * math.cos(t), WA + dy * math.cos(t) - dz * math.sin(t))
HEEL_LOCAL = to_local(HEEL_REL22[0], HEEL_REL22[1], TH_HEEL)
EAR_HULL = hull2([(UA + EAR_HUB_R * math.cos(a), WA + EAR_HUB_R * math.sin(a)) for a in np.linspace(0, 2 * math.pi, 721)[:-1]]
                 + [(CR['u0'], CR['w_screen_back']), (CR['u0'], WA), HEEL_LOCAL])
_ih = EAR_HULL.index(min(EAR_HULL, key=lambda p: math.dist(p, HEEL_LOCAL)))
_ib = EAR_HULL.index(min(EAR_HULL, key=lambda p: math.dist(p, (CR['u0'], WA))))
_front = (CR['u0'], CR['w_screen_back'])
def _other_nb(i):
    nb = [EAR_HULL[i - 1], EAR_HULL[(i + 1) % len(EAR_HULL)]]
    return max(nb, key=lambda p: math.dist(p, _front))
EAR_EDGES = dict(heel=HEEL_LOCAL, front_to=_front, lower_tangent=_other_nb(_ih), back_from=(CR['u0'], WA), back_tangent=_other_nb(_ib))
EAR_MIN_U = min(p[0] for p in EAR_HULL)
# compact outline for drawings/3D: straight-edge vertices + the two exact tangent points + arc points every ~5 deg (CCW in u, w)
_on_arc = [abs(math.dist(p, (UA, WA)) - EAR_HUB_R) < 1e-3 for p in EAR_HULL]
EAR_PROFILE_OUT = [r2l(p) for i, p in enumerate(EAR_HULL)
                   if not _on_arc[i] or not _on_arc[i - 1] or not _on_arc[(i + 1) % len(EAR_HULL)] or i % 10 == 0]
def ear_outline_rel(th, dense=False):
    """ear side outline relative to the axis (dy, dz) at tilt th"""
    return [P_rel(u, w, th) for (u, w) in (densify(EAR_HULL, 0.1) if dense else EAR_HULL)]

CORNERS = [(CR['u0'], CR['w0']), (CR['u0'], CR['w_rib']), (CR['u1'], CR['w0']), (CR['u1'], CR['w_rib']),
           (CR['u0'], WA), (CR['u0'], CR['w_screen_back'])]
TH_SWEEP = np.linspace(TH_HEEL, TH_FOLD, 681)
front_reach = 0.0; front_reach_what = ''
for th in TH_SWEEP:
    for (u, w) in CORNERS:
        dy = P_rel(u, w, th)[0]
        if -dy > front_reach: front_reach, front_reach_what = -dy, f'cradle corner u{u} w{w} at {th:.1f} deg'
    for (dy, dz) in ear_outline_rel(th):
        if -dy > front_reach: front_reach, front_reach_what = -dy, f'ear/heel at {th:.1f} deg'
if KNUCKLE_BASE_HALF > front_reach: front_reach, front_reach_what = KNUCKLE_BASE_HALF, 'lid knuckle base'
H_Y = PL['keepout']['y_max'] + PL['keepout']['clearance'] + front_reach
H_Z = PL['lid']['top_z'] + H_Z_ABOVE_LID
H = (round(H_Y, 2), round(H_Z, 2))
PL['hinge_axis_yz'] = list(H)
PL['hinge_axis_rule'] = f'y = keep-out y{PL["keepout"]["y_max"]:g} + {PL["keepout"]["clearance"]} clearance + front reach {front_reach:.2f} ({front_reach_what}); z = lid top + {H_Z_ABOVE_LID}'
hint = pick('hinge_line_hint')
PL['hinge_hint_from_L2'] = hint

def P(u, w, th, h=H):
    d = P_rel(u, w, th); return (h[0] + d[0], h[1] + d[1])
def W3(xr, u, w, th):
    y, z = P(u, w, th); return (XC + xr, y, z)

# ============================ key poses ============================
pts = {}
for th, tag in [(TH_USE, 'use'), (TH_HEEL, 'heel'), (TH_FOLD, 'fold')]:
    pts[tag] = dict(
        glass_bottom=r2l(P(0, 0, th)), glass_top=r2l(P(G['h'], 0, th)), glass_centre=r2l(P(G['h'] / 2, 0, th)),
        act_bottom=r2l(P(G['act_u'][0], 0, th)), act_top=r2l(P(G['act_u'][1], 0, th)), act_centre=r2l(P(sum(G['act_u']) / 2, 0, th)),
        cr_bot_front=r2l(P(CR['u0'], CR['w0'], th)), cr_bot_back=r2l(P(CR['u0'], WA, th)), cr_bot_rib=r2l(P(CR['u0'], CR['w_rib'], th)),
        cr_top_front=r2l(P(CR['u1'], CR['w0'], th)), cr_top_back=r2l(P(CR['u1'], WA, th)), cr_top_rib=r2l(P(CR['u1'], CR['w_rib'], th)))
sweep_min_y, sweep_min_z, sweep_max_z = 1e9, 1e9, -1e9
for th in TH_SWEEP:
    for (u, w) in CORNERS:
        y, z = P(u, w, th); sweep_min_y = min(sweep_min_y, y); sweep_min_z = min(sweep_min_z, z); sweep_max_z = max(sweep_max_z, z)
    for (dy, dz) in ear_outline_rel(th):
        sweep_min_y = min(sweep_min_y, H[0] + dy)
knuckle_front_y = H[0] - KNUCKLE_BASE_HALF
all_min_y = min(sweep_min_y, knuckle_front_y)
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

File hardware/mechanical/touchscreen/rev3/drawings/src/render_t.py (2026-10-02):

"""Toccata R31 touchscreen rev 3a (B1 = Waveshare 7-DSI-TOUCH-C on the L2 low rear bar) -- dimensioned drawing sheets t01..t06.
Drawing fix round 1 (2026-10-01): 3a ear outline, u24 rib + axle check, notch detail H, t03 back-view +x/-x, clip groove,
ribbon on the HDMI (no U-bend), one sound-path value, frames/titles from the placement block, O4 service, text-overlap audit.

run : ../../../venv/bin/python render_t.py [t01 ...]      (no argument = all sheets)
out : ../tNN_*.svg + ../tNN_*.png (1800 px) + ../drawings.json
Data: tgeo.py (numbers.json of the rev-3 design + final L2 files + circuit netlist copies).  House style = key-action v4
drawings (kav4 kit: View panels, ordinates, hatches, balloons, revision stamp).  Coordinates typed in this file are only
label / panel placement positions; every drawn geometry and every number written comes from tgeo.
"""
import csv
import json
import math
import os
import sys

import tkit as K
import tgeo as g
from tkit import View, F, FX, FR, T, lead, ordz, ordy, panel_title, note_lines, scalebar, halo1, dim_al, angle_arc

OUT = os.path.normpath(os.path.join(K.HERE, ".."))
SHEETS = []
sys.path.insert(0, K.KAV4)
import render_v4 as R  # noqa: E402  (key-action module section for the context)


def add_sheet(n, base, title_ko, caption_ko):
    SHEETS.append(dict(id=f"t{n:02d}", title_ko=title_ko, caption_ko=caption_ko, svg_file=base + ".svg", png_file=base + ".png"))


def sub_head(n, title):
    return f"도면 T{n}. {title}"


SRC_LINE = ("좌표 mm: x = A0 왼쪽 경계, y = 흰건반 앞끝에서 뒤로, z = 책상에서 위로 · 받침 좌표 xr = x − {xc}, u = 유리 아래 끝에서 위로, "
            "w = 유리 앞면에서 뒤로 · 숫자 = numbers.json(수정 {rev}판, 확정 L2)").format(xc=F(g.XC), rev=g.REV)


def foot_lines():
    src = " · ".join(f"{k} md5 {v[:8]}" for k, v in g.SOURCES.items())
    return [f"일반 공차 {g.TOL['general']} (FDM PETG, P2S) · 표시 없는 모서리 C0.5 · 출처: {src}"]


# ------------------------------------------------------------------ shared drawing pieces
def draw_cradle_section(v, P_, th, xr0, pid, cls="m-cr"):
    """cradle cut by xr = xr0, posed at th (world y, z)."""
    adds, subs = g.cradle_section(xr0)
    K.rings_h(v, [g.tf(p, th) for p in adds], cls, pid, subs=[g.tf(p, th) for p in subs])


def draw_screen(v, th, xr0, act=True):
    for p in g.screen_section(xr0):
        v.poly(g.tf(p, th), cls="m-scr")
    a, b = g.P(0, 0, th), g.P(g.GH, 0, th)
    v.line(a[0], a[1], b[0], b[1], cls="glass")
    if act:
        a, b = g.P(g.ACT_U[0], 0, th), g.P(g.ACT_U[1], 0, th)
        v.line(a[0], a[1], b[0], b[1], cls="act")


def cradle_outline(th):
    """side silhouette of the whole cradle (walls + ears + lugs + clips), world, for phantom poses."""
    polys = [g.wall_poly(g.U1), g.EAR_PROFILE, g.LUG_PROFILE,
             g.rect(g.CLIPD["u"][0], g.CLIPD["u"][1], g.RIB0, g.CLIPD["back_w"])]
    return K.union_rings([g.tf(p, th) for p in polys], res=0.05)


def draw_leg_use(v, pid, cls="m-leg"):
    piv, tip = g.LG["pivot_yz"], g.LG["tip_yz"]
    K.rings_h(v, [g.leg_outline(piv, tip)], cls, pid, subs=[g.circle(piv, g.LEG_HOLE / 2, 32)])
    v.circle(piv[0], piv[1], 1.5, cls="m-steel")


def lid_section_at(x0):
    """(add, sub) (y, z) polygons of the lid (+ rev-3 additions) cut by the plane x = x0."""
    L = g.LID
    adds = [g.rect(L["y"][0], L["y"][1], L["top_z"] - L["plate_t"], L["top_z"])]
    subs = []
    pk = g.PK
    if pk["x"][0] <= x0 <= pk["x"][1]:
        c_ = g.LG["pocket_edge_C"]                    # back-wall top edge C0.5
        subs.append([(pk["ramp_front_y"], L["top_z"] + 0.05), (pk["ramp_front_y"], L["top_z"]), (pk["ramp_end_y"], pk["bottom_z"]),
                     (pk["back_wall_y"], pk["bottom_z"]), (pk["back_wall_y"], L["top_z"] - c_), (pk["back_wall_y"] + c_, L["top_z"]),
                     (pk["back_wall_y"] + c_, L["top_z"] + 0.05)])
    b = pk["block"]
    if b["x"][0] <= x0 <= b["x"][1]:
        adds.append(g.rect(b["y"][0], b["y"][1], b["z"][0], L["top_z"] - L["plate_t"] + 0.01))
    for kn in (g.KNL, g.KNR):
        if kn["all"][0] <= x0 <= kn["all"][1]:
            adds.append(g.rect(g.KN_FILL["y"][0], g.KN_FILL["y"][1], g.KN_FILL["z"][0], g.KN_FILL["z"][1] + 0.01))
            if kn["near"][0] <= x0 <= kn["near"][1] or kn["far"][0] <= x0 <= kn["far"][1]:
                adds.append(g.knuckle_profile())
                d = g.KN_NEAR_HOLE if kn["near"][0] <= x0 <= kn["near"][1] else g.KN_FAR_HOLE
                subs.append(g.circle(g.H, d / 2, 40))
            else:
                adds.append(g.rect(g.HEEL_STOP["y"][0], g.HEEL_STOP["y"][1], g.HEEL_STOP["z"][0] - 0.01, g.HEEL_STOP["z"][1]))
    hw = g.HOLE_WALL
    if hw[0] <= x0 <= hw[1]:
        adds.append(g.rect(hw[2], hw[3], L["bed_z"], L["top_z"]))
        if g.HO["x"][0] <= x0 <= g.HO["x"][1]:
            subs.append(g.rect(g.HO["y"][0], g.HO["y"][1], L["bed_z"] - 0.05, L["top_z"] + 0.05))
    cp = g.CL["pad"]
    if cp["x"][0] <= x0 <= cp["x"][1]:
        adds.append(g.rect(cp["y"][0], cp["y"][1], cp["z"][0], cp["z"][1] + 0.01))
    for f in g.FEET:
        if f["x"][0] <= x0 <= f["x"][1]:
            adds.append(g.rect(f["y"][0], f["y"][1], f["z"][0] - 0.01, f["z"][1]))
            if f["rear"]:
                adds.append(g.rect(f["lip"]["y"][0], f["lip"]["y"][1], f["z"][0] - 0.01, f["lip"]["z"][1]))
    for s in g.V["slots"]:
        if s[0] <= x0 <= s[1]:
            subs.append(g.rect(s[2], s[3], L["top_z"] - L["plate_t"] - 0.05, L["top_z"] + 0.05))
    return adds, subs


def draw_rear_bar(v, pid):
    """L2 centre unit section at x = XC (walls from body_L2.json), plywood."""
    W = g.WALLS
    fz = g.FLOOR_ZONE
    K.poly_h(v, g.rect(fz["y"][0], W["back_y"][0], W["bottom_z"][0], W["bottom_z"][1]), "m-wood", pid["wood"])
    K.poly_h(v, g.rect(W["back_y"][0], W["back_y"][1], W["bottom_z"][0], W["lid_z"][0]), "m-wood", pid["wood"])


def draw_pi(v):
    """Pi 5 at x = XC plane (board cut) + parts behind (x < XC) as thin outlines."""
    pi = g.PI
    top = pi["board_top_z"]
    v.rect(pi["board_y"][0], top - 1.6, pi["board_y"][1] - pi["board_y"][0], 1.6, cls="m-pi")
    for key, cls in (("heatsink", "vis"), ("hdmi", "vis")):
        q = pi[key]
        v.rect(q["y"][0], top, q["y"][1] - q["y"][0], q["top_z"] - top, cls=cls)
    d1 = pi["disp1"]
    v.rect(d1["y"][0], top, d1["y"][1] - d1["y"][0], pi["cad_disp1"]["z"][1] - top, cls="m-lead")
    gp = pi["gpio_pin2"]
    pp = g.PIN_PITCH
    v.rect(gp[1] - 1.5 * pp, top, 2 * pp, pi["gpio_top_z"] - top, cls="m-black")
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

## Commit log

2026-09-24 docs: snapshot v3 design (R26~R29) + fastener audit
    Baseline commit before applying ME6/ME10 to the design doc, so the
    concurrent R26~R29 revision has a restore point.
    - toccata-build-v3.html: current R26~R29 revision (base 591,644 KRW, 51 lines)
    - toccata-fastener-study.html: new fastener audit — every screw/insert/washer
    in the BOM, load paths, and whether each can be replaced by printed geometry
    [bed12.stl, bed13.stl, bed3.stl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]
2026-09-24 design: adopt ME6 and ME10 into the v3 design doc
    Replaces bought fasteners with printed geometry where the load path allows.
    CP7 (brass standoff -> printed boss) was already folded in by the R26 revision.
    ME6 brass heat-set inserts (67x, 9,270 KRW) -> printed hex pockets + steel M3
    nuts (825 KRW); clamp screw M3x35 -> M3x40 because the nut sits 4.2 mm
    lower. Drops the insert press-in step and the dedicated iron tip (T05,
    20,290 KRW) and one vendor. Dims D07/D09/S48/S49 and assembly steps 3/4/7
    updated; bearing stress 12 MPa (clamp), 8.2/10.6 MPa (setscrew).
    ME10 control board: 4 screws -> 2 diagonal screws + 2 printed locating pins
    (P114), 40 -> 20 pcs.
    Totals: b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
2026-10-02 design: settle v4 hardware - L2 rear unit, touchscreen rev 3, print-ready CAD
    - hardware/mechanical/cad: CAD generator (build_all.py) and 84 print STLs,
    3MF/GLB, manifest, generated README, viewer data. The rear unit is L2:
    one body behind the keys, depth 342.5, centre lids flush at z72.85,
    closed cable duct, speaker pods with a 40 deg baffle (2.16 L, Qtc 1.13).
    Touchscreen rev 3 (Waveshare 7-DSI-TOUCH-C). Parts match purchase list v4
    (Norelem 07653-04 inserts, L69/L71 inserts, hub ports, cables).
    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
    [5eefb61b2626a.dwg, C01a.scad, C01a.stl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]
